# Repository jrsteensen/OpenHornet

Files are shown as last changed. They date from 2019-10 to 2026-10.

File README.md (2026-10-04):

# README
[TOC]

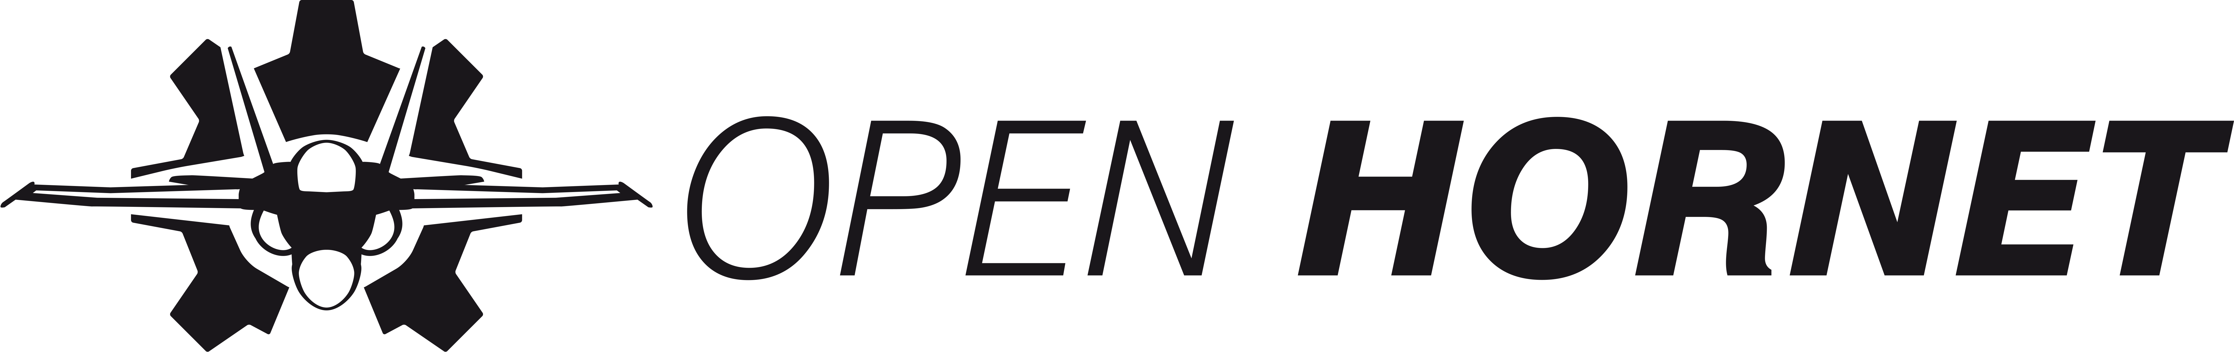
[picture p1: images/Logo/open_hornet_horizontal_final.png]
OH logo


 
 
 



 
 
 
 


 
 
 
 

The OpenHornet Project is a F/A-18C OFP 13C Lot 20 1:1 Replica Simulator, consisting of a physical structure and electrical/software interfaces to a PC to be driven by Digital Combat Simulator (DCS).

* If you have any questions, visit our Discord server and ask questions. The Discord server will be an invaluable resource for you as your progress through the journey of your build.

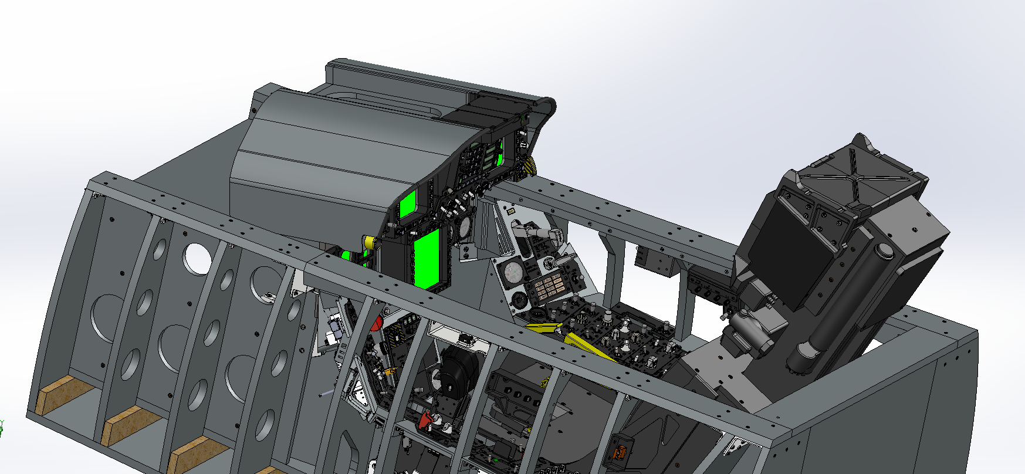
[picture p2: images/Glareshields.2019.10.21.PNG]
Overall Screen Grab


### Looking for Software?
* [OpenHornet GitHub Software Repository](https://github.com/jrsteensen/OpenHornet-Software)

## Design Software Requirements
* Mechanical CAD Software Required: Fusion360
* Electrical CAD Software Required: KiCad 10
* Microsoft Office (or compatible)

## Contributing
[Want to contribute?](https://github.com/jrsteensen/OpenHornet/wiki/Contributing) Let's discuss what you want to work on in Discord or in an issue!

## References, Information, and How-Tos

### GitHub Repository File Structure
```
OpenHornet
├── .github (Contains issue templates, funding info, and GitHub actions.)
├── artwork (Subdivided into end items, contains stickers, placards, etc.)
├── ECAD (All PCBs and electrical design files. See folder README file for details.)
├── images (Contains images for use in the wiki or other OH documentation.)
├── reference (Contains reference models or geometry.)
├── release (Contains all files that makeup the release package. See folder README file for details.)
├── utils (Contains fonts or other similar required resources for development)
├── .gitignore (File that instructs the git repository to ignore certain file types.)
├── CODE_OF_CONDUCT.md (Our contributor code of conduct.)
├── CONTRIBUTING.md (Repository contribution and issue-reporting guidance.)
├── LICENSE.md (License file for the OpenHornet repository)
├── PULL_REQUEST_TEMPLATE.md (The repository pull request template.)
└── README.md (This file)
```

### Important Links
* [OpenHornet Start Here Page](https://openhornet.com/start-here/) - Seriously. Start here.
* [OpenHornet FAQ](https://openhornet.com/faq/) - You guessed it! The FAQ!
* [OpenHornet GitHub](https://github.com/jrsteensen/OpenHornet) - OpenHornet's GitHub repository for everything other than MCAD. Where you can find the latest under-development files.
* [OpenHornet Hardware Documentation](https://docs.openhornet.com/hardware/) - Generated hardware documentation, tutorials, and reference material.
* [OpenHornet Tutorials](https://github.com/jrsteensen/OpenHornet/tree/master/docs/tutorials) - Tutorials for OpenHornet.
* [OpenHornet Issues](https://github.com/jrsteensen/OpenHornet/issues) - Go here to file a bug, enhancement, obsolescence, or maintenance issue.
* [OpenHornet Authorized Vendors](https://openhornet.com/openhornet-authorized-vendors/) - These are vendors who are licensed to sell OpenHornet parts and assemblies. By purchasing from them, you also support OpenHornet as well!

### OpenHornet MCAD Model
These links will allow you to download a local copy of the OH MCAD model, for reference or so you can modify things for your personal pit. If you would like to contribute to the raw MCAD, talk to Noctum in the OH Discord. You will need to prove a basic level of proficiency and be known within the discord community before access will be granted.
> [!NOTE] 
> These links will download the latest & greatest (most likely in development and unstable) MCAD. Always verify fusion parts against release package manufacturing files prior to use, and they are used at the user's own risk.

* [Top Level](https://a360.co/3SuPQGs) - This is HUGE. Consider downloading individual consoles instead.
* [Upper Instrument Panel (UIP)](https://a360.co/3LHxMXd)
* [Lower Instrument Panel (LIP)](https://a360.co/3SbD7sc)
* [Left Console (LC)](https://a360.co/3dBR57I)
* [Right Console (RC)](https://a360.co/37pBiWj)
* [Center Tub (CT)](https://a360.co/3LKM3mc)

### Branches
* `master` branch is the stable release branch which represents the last release.
* `develop` is the latest working branch that will become the next release. It may or may not be functional as is.

## Authors and Acknowledgment

### Core Development Team
* Erik Scott (RandomTroubledMind): _Project Founder, Mechanical Design_ (Retired from OH)
* John Steensen (Noctum): _Co-Founder, Systems/Mechanical Design Lead_
* Oscar Arias (Amanuense): _Electrical/Software Design Lead_ (Retired from OH)

### Contributor Team
* Exprezzo
* Sandra
* Ben-F111
* Lazarus
* Russell
* Arribe VCAW-1
* Stang
* \[OCS\] CrazyCanuck
* Ulikaii

### Honorable Mentions
* __Logo Design__: NegativeONE
* __Development Builders/Testers__: Ajmilner,  Arribe VCAW-1, Ben-F111, BlaBlaCZ, bnepethomas, Dave the boss 918, DG, DotDotDotBH, Exprezzo, Higgins, Krikeee, Lazarus, Otso, Rampage2010, Russell, Sandra, Splash, Thib-O, tonyg, TripRodriguez, Yannick, 
* __Ultimate Supporters__: Sandra, Higgins, Chaps, [OCS] CrazyCanuck, Arribe VCAW-1, FL370Pilot, CorgiStyle, Swaney409, DenzilLee, ssgcline, Tyler | "Soapbox" - F-15E, RickH, AdamA, bob =), aesellars, Nick, PrivatePirate, Howling-Ape, papiplanes
* __Elite Supporters__: thib_o54, ChrisTiger#001, Nodar, Matt, Bill C, annerajb, Wargle T Eagle, Gnoni, Lefty, Reaper021, Murtle, gengispala, PatOPat, mattgw86, EinLama, Maddox, hunstone, Nodar, Ulukaii, Radek 41Sqn RAFAIR, mojito555
* __Donators__: AJMilner, bnepethomas, Carbine, Crosshairs, Exprezzo, Goutch, Higgins, hrnet940, hunstone, icemarkom, jcstreek, jkkicks, kika, Nik S, Rampage2010, Russell, Sandra, SrSosio, Swaney409, Tekadept + many more…
* __Inactive Dev Contributors__: Balz Reber (Balse), Magic_Man, Bullant, Gaberun24, Damien022, Baago, Caviar4, NegativeONE, Ravell
* **Subject Matter Expert**: FlyNavy75, Sixtigers, USMARINE108, Luft101, Lex

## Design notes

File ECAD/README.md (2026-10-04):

OH logo
* [OpenHornet Website](https://www.openhornet.com)
* [OpenHornet Discord](https://discord.gg/G5PA5ju)
* [Donate to OpenHornet](https://www.openhornet.com/donate.html)

# **ECAD DIRECTORY INFORMATION**

Engineering contributors and agents: start with the [ECAD design requirements framework](docs/requirements/README.md). AI-assisted contributors should also read the [Astra/Konnect/KiCad toolchain guide](docs/requirements/TOOLCHAIN.md). The framework distinguishes repository evidence, approved policy, unresolved decisions and hardware qualification states.

The purpose of this guide is to help enable the end-user to successfully accomplish the following:  
*   1:  Facilitate navigation of the file structure.
*   2:  Provide clarification regarding the manufacturing process of PCB's related to OpenHornet using JLCPCB.com
*   3:  How to install the current project KiCad baseline and set up libraries associated with OpenHornet. _(optional, required only if you wish to contribute.)_

 _Note:  Manufacturing files have been generated accordinging to JLCPCB.com guidelines.  If choosing a different PCB Manufacturer, make sure to research their formatting standards and modify the necessary manufacturing files accordingly. And if you choose to manufacture them yourself, best of luck!_

## **ECAD File Structure**

The ECAD Directory has been organized to facilitate the end user, regardless of skill or knowledge, in acquiring the necessary files needed to: 
* A: make adjustments to individual PCB's as needed using ECAD software (KiCad)
     * _and/or_
* B: submit an online order to have the PCB manufactured and assembled by a company.

**The structure of the ECAD Directory is summarized below:**
ECADDirectory

Example

1. Within each labeled PCB folder, there will be a folder called "JLCPCB" and inside of that folder will be two additional folders called "gerbers" and "production_files"
2. **_All files you need for manufacturing are located in the "production_files" folder.  The gerbers are already compressed in a .zip file labeled the same way as the PCB folder their located in._** 
3. Additionally, there will be 2 .csv files:  _**BOM-'NAME OF PANEL'.csv**_ and  _**CPL-'NAME OF PANEL'.csv**_ that will contain a consolidated Bill of Materials (BOM) for components located on the top and bottom of the PCB, as well as the Control Panel File (CPL)  used for placing the components.

***PLEASE READ:  YOU NEED TO DOWNLOAD ALL 3 FILES WITHIN THE PRODUCTION_FILES FOLDER.  NOT JUST THE .ZIP.***



## **PCB Manufacturing**

At the moment, all manufacturing files have been standardized to allow for fabrication using JLC @ (https://www.jlcpcb.com).  You may use another PCB manufacturer of your choosing; however, you will be responsible for ensuring the required files meet specifications and formatting. 

***For details on the JLCPCB manufacturing process, please see the "MANUFACTURING.MD" located in the ECAD folder or CLICK THE LINK BELOW***

  [JLCPCB MANUFACTURING PROCESS & FAQ](MANUFACTURING.md)

## **Installation of KiCad and OpenHornet Libraries _(OPTIONAL)_**

*Installation of KiCad and OpenHornet Libraries is only required if you choose to contribute. See [CONTRIBUTING.md](../CONTRIBUTING.md) for more details.*

Before we begin, it is assumed that you have:
*  1:  Installed KiCad 10.x. The current validated AI-assisted reference environment uses KiCad 10.0.6; record and smoke-test newer versions before design mutation as described in [TOOLCHAIN.md](docs/requirements/TOOLCHAIN.md).
*  2:  Cloned the OpenHornet repository.

### STEP ONE:  Configure Paths & Create Environmental Variables

**Windows shortcut:** initialize KiCad 10 with its built-in libraries, then close KiCad and double-click [`Setup-OpenHornetKiCad.bat`](../utils/tools/ecad/Setup-OpenHornetKiCad.bat). The [complete setup script](docs/SYMBOL_LIBRARIES.md#windows-path-setup-script) configures all four paths, registers all six shared symbol libraries and `OH_Footprints`, and repairs existing shared entries in project library tables. It backs up every changed file and supports a preview with `-WhatIf`. After it succeeds, reopen KiCad; Steps One and Two below are the manual alternative.

Open up a new or previous project in KiCad.  For this example, I'll be using the MASTER ARM PANEL.  In the Top Menu: Navigate to Preferences --> Configure Paths



Create these four variables using absolute paths within your OpenHornet checkout:

| Variable | Repository folder |
| --- | --- |
| `KICAD_USER_OH_3DMODELS` | `ECAD/lib/OH_3DModels` |
| `KICAD_USER_OH_FOOTPRINTS` | `ECAD/lib` |
| `KICAD_USER_OH_SYMBOLS` | `ECAD/lib/OH_Symbols` |
| `KICAD_USER_OH_TEMPLATES` | `ECAD/lib/OH_Templates` |

The paths can be anywhere so long as they point to the OpenHornet checkout being edited. _Make sure the OH_FOOTPRINTS variable points to the `ECAD/lib` folder and **NOT** `ECAD/lib/OH_Footprints.pretty`._ If you use Git worktrees, do not let KiCad resolve libraries from a different checkout/revision than the PCB or schematic being edited.

tempsnip

### STEP TWO:  Add OpenHornet Symbol and Footprint Libraries

With the project window open, navigate to Preferences --> Manage Symbol Libraries.



In **Global Libraries**, add or edit the six shared libraries below. Use library format **KiCad** for each entry. The library paths use the variable configured above:

| Nickname | Library Path |
| --- | --- |
| `ABSIS` | `${KICAD_USER_OH_SYMBOLS}/ABSIS.kicad_sym` |
| `Arduino Pro Mini 5v` | `${KICAD_USER_OH_SYMBOLS}/Arduino Pro Mini 5v.kicad_sym` |
| `KiCadCustomLib` | `${KICAD_USER_OH_SYMBOLS}/KiCadCustomLib.kicad_symdir` |
| `OH_Interconnect` | `${KICAD_USER_OH_SYMBOLS}/OH_Interconnect.kicad_symdir` |
| `OH_Symbols` | `${KICAD_USER_OH_SYMBOLS}/OH_Symbols.kicad_symdir` |
| `OpenHornet` | `${KICAD_USER_OH_SYMBOLS}/OpenHornet.kicad_symdir` |

**Existing users:** change the paths for `OH_Symbols`, `KiCadCustomLib`, `OH_Interconnect` and `OpenHornet` from packed `.kicad_sym` files to their `.kicad_symdir` folders, using the exact nicknames in the table. Register each folder as one library, rather than adding its individual files. Check **Project Specific Libraries** for overriding entries with the same nicknames. `ABSIS` and `Arduino Pro Mini 5v` remain packed files.

Use the exact underscore nicknames `OH_Symbols` and `OH_Interconnect`, as shown in the table; do not substitute spaces. If a schematic still contains a library ID using a spaced nickname, correct its library reference through KiCad's symbol remapping tools. Changing a library-table nickname alone does not rewrite IDs embedded in schematics.

See [symbol library setup, Windows conversion and verification](docs/SYMBOL_LIBRARIES.md). Contributors pulling the converted folder only need to update their library mapping. The screenshots below illustrate the dialogs; use the paths in this table for KiCad 10.



Do the same thing for the footprint library, adding `ECAD/lib/OH_Footprints.pretty` with nickname `OH_Footprints`. The path should resolve as `${KICAD_USER_OH_FOOTPRINTS}/OH_Footprints.pretty`.



### STEP THREE:  Add ***KiCAD JLCPCB tools*** Plugin (Optional)
Bouni @ https://github.com/bouni/kicad-jlcpcb-tools has developed a plugin that allows you to search the JLCPCB parts database, assign LCSC article numbers to your parts, and generate production files for JLCPCB. This plugin is optional and is not a substitute for the OpenHornet sourcing/manufacturing requirements or the approved Astra/Konnect workflow.

*  1: Click **"Plugin and Content Manager"**
*  2: When the dialog box opens, click on **"Manage"**
*  3: When the **"Manage Repositories"** dialog box opens, Click the "+" sign and add the following:
    *  Name:  Bouni's KiCad repository
    *  URL:  https://raw.githubusercontent.com/Bouni/bouni-kicad-repository/main/repository.json
*  4: Once downloaded and installed, hit "Apply Changes"



### Congratulations. That's all you have to do for the shared OpenHornet library mapping.  The 3D models that are associated with the footprints will automatically be linked as long as the OH_Footprints are used.  

AI-assisted contributors should continue with [TOOLCHAIN.md](docs/requirements/TOOLCHAIN.md) before making hardware changes.

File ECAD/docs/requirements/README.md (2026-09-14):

# OpenHornet ECAD requirements

Status: **adopted on 2026-09-11 by merge of PR #1255 into the default branch**. Baseline inspected for the original framework: `master` at `c259a65a1759801a2affea817fd99f6a14f1e1fe` (2026-09-10 review). Adoption does not itself qualify any hardware.

The canonical path is **`ECAD/docs/requirements/`**, matching the existing uppercase `ECAD` tree. Creating a second lowercase tree would collide on common Windows/macOS filesystems. No hardware tree is renamed.

## Authority and requirement language

Merge of PR #1255 adopted the normative requirements for new designs and changed portions of existing designs, including affected interfaces and dependencies. Existing released boards retain their historical status; adoption does not retroactively qualify them or require wholesale redesign. Cosmetic maintenance does not trigger unrelated migration or repeat physical qualification. Already-open hardware PRs document applicable gaps and their disposition. See GOV-010/011 for scope and authority.

Requirements adopted by PR #1255 are effective; amendments proposed in a later PR take effect when accepted and merged. Individually unresolved technical choices marked Proposed/TBD remain pending until separately resolved.

- **MUST / MUST NOT**: mandatory conditions within the stated scope.
- **SHOULD / SHOULD NOT**: expected practice; document the engineering reason for a different approach.
- **MAY**: permitted option, not evidence of qualification.
- **Observed**: repository evidence, not a mandatory design rule.
- **Proposed**: a specific choice awaiting owner approval; MUST NOT be treated as an approved project standard.
- **TBD**: unresolved input; record a board-specific reviewed decision before passing a gate that depends on it.

Each normative document identifies its basis. Requirements have stable IDs for review evidence and deviations. Keep IDs stable when editing wording; retire rather than reuse deleted IDs. An inventory value becomes normative only through an explicit requirement and scope.

The master baseline is supplemented by the ALE+ successor and current owner-confirmed decisions recorded in the [ALE+ supplement](ALE_PLUS_SUPPLEMENT.md). Baseline file counts remain a historical snapshot; supplements and later reviews explicitly identify their scope.

## Reading order

| Document | Purpose | Status |
| --- | --- | --- |
| [GOVERNANCE.md](GOVERNANCE.md) | Authority, change scope, deviations, practical acceptance | Normative |
| [WORKFLOW.md](WORKFLOW.md) | Astra/Codex, Konnect, KiCad 10, safe edits and evidence | Normative |
| [TOOLCHAIN.md](TOOLCHAIN.md) | Known-good Astra/Konnect/KiCad implementation, operator modes and smoke tests | Operational reference supporting WORKFLOW |
| [SCHEMATICS_AND_COMPONENTS.md](SCHEMATICS_AND_COMPONENTS.md) | Schematics, datasheets, exact MPNs, symbols and footprints | Normative |
| [INTERFACES.md](INTERFACES.md) | ABSIS, connectors, cables, RS-485 and local buses | Normative; observed mappings explicitly separated |
| [POWER_AND_USB.md](POWER_AND_USB.md) | Power budgets, protection, USB, decoupling and returns | Normative |
| [PCB_AND_MECHANICAL.md](PCB_AND_MECHANICAL.md) | Physical constraints, routing and board rules | Normative |
| [VALIDATION.md](VALIDATION.md) | ERC, DRC, parity, exclusions and review | Normative |
| [MANUFACTURING.md](MANUFACTURING.md) | CAM, BOM/CPL, assembly and release artifacts | Normative |
| [QUALIFICATION.md](QUALIFICATION.md) | Bring-up, regression, human acceptance and release | Normative |
| [REVIEW_RECORD.md](REVIEW_RECORD.md) | Short change/build review record | Proportional PR evidence |
| [ARCHITECTURE_INVENTORY.md](../reference/ARCHITECTURE_INVENTORY.md) | Evidence, generations and identified conflicts | Informative |
| [BOARD_INVENTORY.md](../reference/BOARD_INVENTORY.md) | Every PCB/project, source paths and observed constraints | Informative |
| [ABSIS_MIGRATION.md](ABSIS_MIGRATION.md) | Rules for performing scoped circuit migrations | Normative |
| [ALE_PLUS_SUPPLEMENT.md](ALE_PLUS_SUPPLEMENT.md) | Current owner-confirmed ALE+ design decisions | Informative |
| [OPEN_QUESTIONS.md](OPEN_QUESTIONS.md) | Accepted owner decisions | Decision record; Q-01 through Q-13 resolved |

## Start a board change

Read governance, workflow, the toolchain reference when using AI/Konnect, the applicable technical documents, and the board's inventory entry. Establish the actual board revision and connected hardware before editing. Use [REVIEW_RECORD.md](REVIEW_RECORD.md) to capture applicable requirement IDs, evidence and unresolved items. Inventory entries are a baseline snapshot; recheck the current source when using them.

Numerical defaults in KiCad, old production files, tool examples and component headline ratings are not automatically OpenHornet electrical or fabrication limits. Do not use the oldest or most permissive value to settle a conflict. Keep the affected gate pending until its inputs are resolved.

## Owner decisions and practical scope

The 2026-09-14 discussion establishes the profiles, power targets, supported modules, practical acceptance and file-lifecycle rules recorded in [OPEN_QUESTIONS.md](OPEN_QUESTIONS.md). Q-03 approves Master-end-only shield bonding and detachable two-position JST SM drain connections with one contact populated per half. S3MB is the accepted ALE+ D2. Implementation defects belong in repository issues/PRs; this folder is not an issue backlog.

Historical static inventories are retained under `ECAD/docs/reference/` as dated evidence. They do not override current owner decisions or establish current support status. No formal retrospective qualification campaign is required for successfully used existing boards.

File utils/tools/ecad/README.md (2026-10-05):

# OpenHornet ECAD utilities

## Windows KiCad 10 setup

After installing KiCad 10, initialize its built-in symbol and footprint libraries and close all KiCad applications. In a complete OpenHornet checkout, double-click `Setup-OpenHornetKiCad.bat`. It runs `Set-OpenHornetKiCadPaths.ps1`, shows the results and pauses before closing. Reopen KiCad after setup succeeds.

The PowerShell utility configures all four `KICAD_USER_OH_*` paths (symbols, footprints, 3D models and drawing templates), registers all six shared symbol libraries and `OH_Footprints`, and repairs existing shared-library entries in project tables under `ECAD`. It requires PowerShell 5.1 or newer. For a preview or direct execution from the repository root:

```powershell
powershell.exe -NoProfile -ExecutionPolicy Bypass -File .\utils\tools\ecad\Set-OpenHornetKiCadPaths.ps1 -WhatIf
powershell.exe -NoProfile -ExecutionPolicy Bypass -File .\utils\tools\ecad\Set-OpenHornetKiCadPaths.ps1
```

The script preserves unrelated preferences and library entries. It backs up every changed file in the KiCad configuration folder with a restore manifest, checks for concurrent changes and attempts rollback if a later write fails. It supports `-Checkout` and `-ConfigDirectory`, detects external environment overrides and makes no changes when setup already matches. Project mapping repairs appear in `git diff`; review them before committing. See the [setup guide](../../../ECAD/docs/SYMBOL_LIBRARIES.md#windows-path-setup-script) for configuration discovery, restore instructions and verification. No administrator rights, Codex or Konnect are required.

If an older copy reports a `ConvertFrom-Json` error about keys such as `a` and `A`, update the setup script and rerun it. The current utility preserves case-sensitive preference keys with Windows PowerShell 5.1 and PowerShell 7.

Maintainers can run the disposable regression tests with Python 3 and PowerShell:

```powershell
python .\utils\tools\ecad\tests\test_kicad_setup.py
```

The tests prefer `powershell.exe` on Windows, otherwise `pwsh`. Set `OH_TEST_POWERSHELL` to test a particular executable. Close KiCad before running them.

## Astra launch utilities

These wrappers implement the operator modes defined by `ECAD/docs/requirements/TOOLCHAIN.md`.

- `./preflight audit` — read-only workstation/repository/library/MCP checks. Audits may run on the default branch.
- `./preflight design` — stricter checks for a mutation session. Refuses `master`/`main`, detached HEAD, missing toolchain/library mappings, and a dirty working tree unless `OH_ALLOW_DIRTY=1` explicitly acknowledges intentional scoped work.
- `./astra-audit [prompt]` — CLI convenience wrapper that runs preflight and starts GPT-6 Astra/Codex with `approval=never` and `sandbox=read-only`.
- `./astra-design [prompt]` — CLI convenience wrapper that runs preflight and starts GPT-6 Astra/Codex with `approval=on-request` and `sandbox=workspace-write`.

`OH_ASTRA_MODEL` may override the default `gpt-6-astra` model identifier. The launchers do not install, update or reconfigure Codex, Konnect or KiCad; follow `TOOLCHAIN.md` for setup and smoke tests.

On the validated Fedora reference environment, `preflight` also verifies KiCad's `KICAD_USER_OH_*` variables resolve to the current Git checkout. This intentionally prevents a Git worktree from silently using libraries from another checkout. Other platforms must perform equivalent library-resolution verification until that check is made portable.

The shared-library check requires nonempty `OH_Symbols.kicad_symdir`, `KiCadCustomLib.kicad_symdir`, `OH_Interconnect.kicad_symdir` and `OpenHornet.kicad_symdir` directories. Retained packed comparison copies do not satisfy these checks. `ABSIS` and `Arduino Pro Mini 5v` remain packed libraries. Use KiCad 10 and follow the [symbol library mapping and verification guide](../../../ECAD/docs/SYMBOL_LIBRARIES.md) after pulling the migration.

## CLI usage

Example design session:

```bash
git switch -c pcb/example-change
utils/tools/ecad/astra-design
```

To resume a deliberate in-progress task that already has uncommitted ECAD changes:

```bash
OH_ALLOW_DIRTY=1 utils/tools/ecad/astra-design
```

Do not use `OH_ALLOW_DIRTY=1` to hide unrelated local work.

## ChatGPT Desktop / graphical Codex

The 2026-09-11 roci reference setup also passed the read-only OpenHornet/Konnect smoke test through ChatGPT Desktop/Codex using the same `~/.codex/config.toml` Konnect MCP registration as the CLI. For OpenHornet ECAD work, open the canonical checkout as a **Local** project, not a Codex-managed worktree, until shared KiCad library mappings are project-relative.

When using the desktop app, do not launch `astra-audit` or `astra-design` merely to create another nested Codex session. Run the appropriate repository preflight from the integrated terminal, then continue the task in the existing Astra conversation:

```bash
utils/tools/ecad/preflight audit
# or
utils/tools/ecad/preflight design
```

Desktop environment Actions are optional convenience UI only. The current autogenerated `.codex/environments/` state is machine-local and ignored by Git; these repo-owned utilities remain the shared authoritative workflow.

## Validated Fedora schematic viewer

The Konnect `schematic-viewer` required two process-local compatibility settings on Fedora 44 KDE/Wayland:

```bash
export GDK_BACKEND=x11
export WEBKIT_DISABLE_DMABUF_RENDERER=1
```

The validated roci installation keeps those variables in a wrapper at `~/.local/bin/schematic-viewer` and preserves the upstream viewer binary as `~/.local/bin/schematic-viewer.real`. Do not export these variables globally.

Konnect 0.11.1 dark theme applies a CSS filter to the rendered SVG and was visibly blurry when zoomed under the validated WebKitGTK path. Light theme retained crisp vector rendering and is the recommended viewer mode for this reference environment.

The desktop application is optional. CLI Astra/Codex plus Konnect, KiCad and the repository launch utilities remain the reproducible fallback and should continue to work independently of desktop UI state.

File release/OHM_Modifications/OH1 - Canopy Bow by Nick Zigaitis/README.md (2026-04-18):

# OH1 - Canopy Bow by Nick Zigaitis
- **Author:** Nick Zigaitis
- **Publisher:** Simon Martel (1_neox_1)
- **Contributed on:** 4/18/2026
- **Derived from:** v0.3.0
- **Original Assembly:** OH1

## Summary
This change adds a canopy bow component to the project. The mod itself was not originally developed by me, but I am publishing it to make it available to the OpenHornet community. The goal is to enhance cockpit realism and completeness by providing an additional structural element that integrates cleanly with existing parts.

### Parts List
1. 6x M3 x 10mm Button Head Screw
2. 6x M3 x 12mm Button Head Screw
3. 4x M3 x 7/32" Bolt Socket Cap Screw
4. 2x M2 x 25mm Pan Head Screw
5. 13x M3 Heat Insert
6. 52x 1/4" Wood Dowels
7. TrackIR Sensor
8. 1x PATIKIL 1/4" Thread Ball Stud 35mm
9. 3x 1.5mm Acrylic Mirror Wrapped
10. 2x Canopy Hoop Grab Handle
11. x1 1/16" Trotec Rev Matte Clear/Black
12. x1 TroGlass Satin Clear 3mm Trotec
13. x1 2.84mm Green Acrylic
14. x1 X27-589 Stepper
15. x1 X27-168 Stepper
16. x1 4mm x 2mm Neodymium Magnet
17. 3x Double Sided Mounting Tape

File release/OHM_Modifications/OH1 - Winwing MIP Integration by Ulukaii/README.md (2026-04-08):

# OH1 and OH2 Modification for Winwing integration, V3
- **Author:** J Schumacher (Ulukaii) 
- **Contributors:** Spruce, Breith, Reaper021 
- **Contributed on:** Dec 28, 2025 
- **Derived from:** v0.3.0
- **Original Assembly:** OH1, OH2

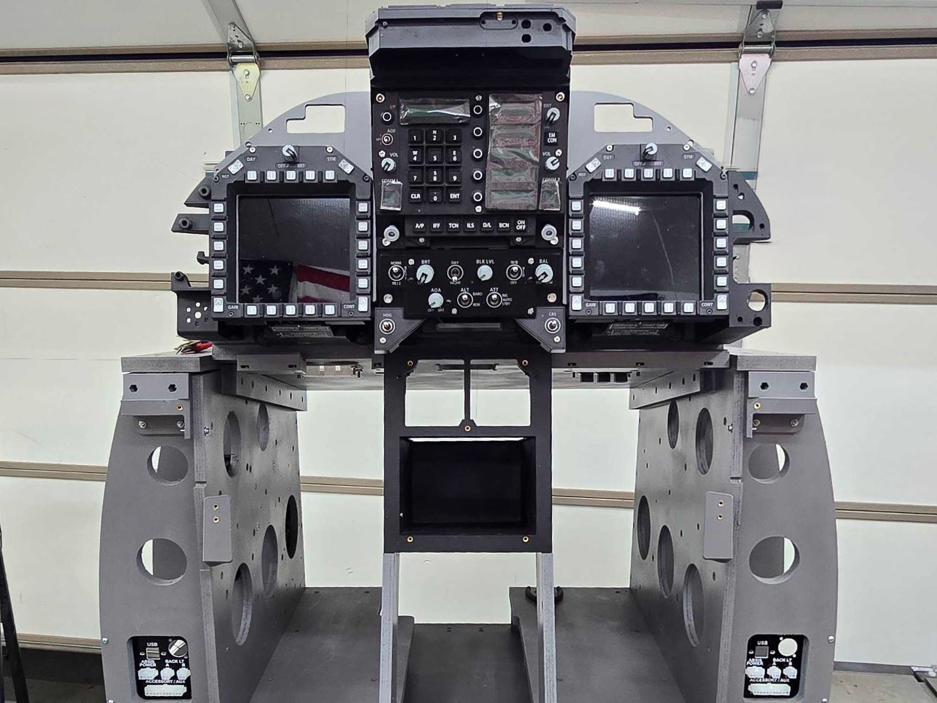
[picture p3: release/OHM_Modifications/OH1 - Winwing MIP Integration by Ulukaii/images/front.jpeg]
Front


## Summary
This folder provides modifications for integrating the Winwing MIP into the OpenHornet upper and lower instrument panel (UIP and LIP). It is aimed at builders who intend to do a full Winwing MIP integration, including HUD panel. The parts provided herein are designed with 3D printability in mind. 
- Folder V1: Previous release. 
- Folder V2: Previous release. 
- Folder V3: Current stable build.

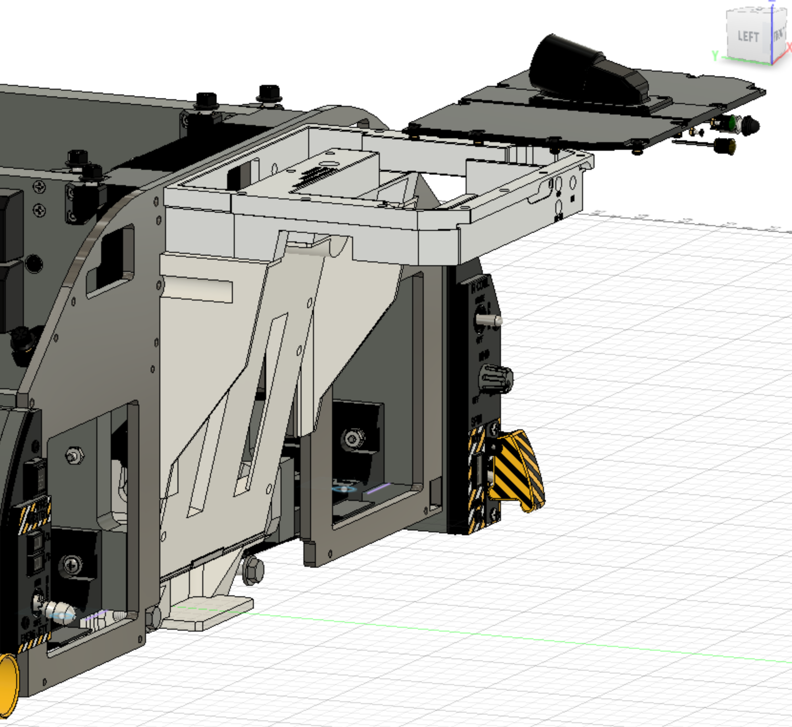
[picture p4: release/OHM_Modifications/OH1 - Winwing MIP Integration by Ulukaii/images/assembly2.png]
Assembly preview


## How to use this mod

Use this mod to build your pit using the basic OpenHornet upper instrument control panel (UIP) frame, but integrate your Winwing MIP components into the build. You will replace the following visible parts: Left DDI, right DDI, UFC, HUD control panel and AMPCD. To achieve this, this mod provides the files for a modified face plate (acrylic) and modified brackets (3D printed). 

## Feature overview

The integration positions the Winwing UFC and HUD panels as closely as possible to the OH-specified position:
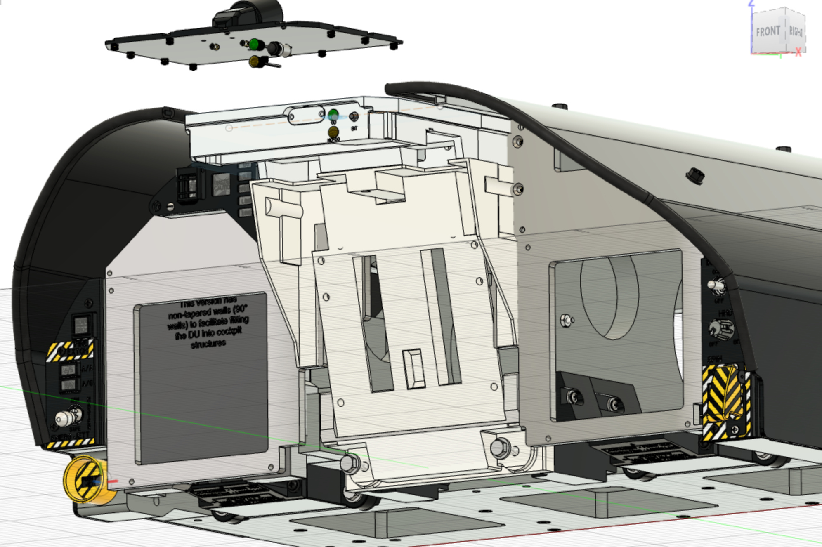
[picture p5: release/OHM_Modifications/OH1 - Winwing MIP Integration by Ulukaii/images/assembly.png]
Assembly preview


Due to the Winwing MFD screen encasings, the face plate can't use six screws on the outboard longeron. However, the assembly provides new / alternative securing. The main holding bracket is firmly secured using M5 screws and six heat inserts: 

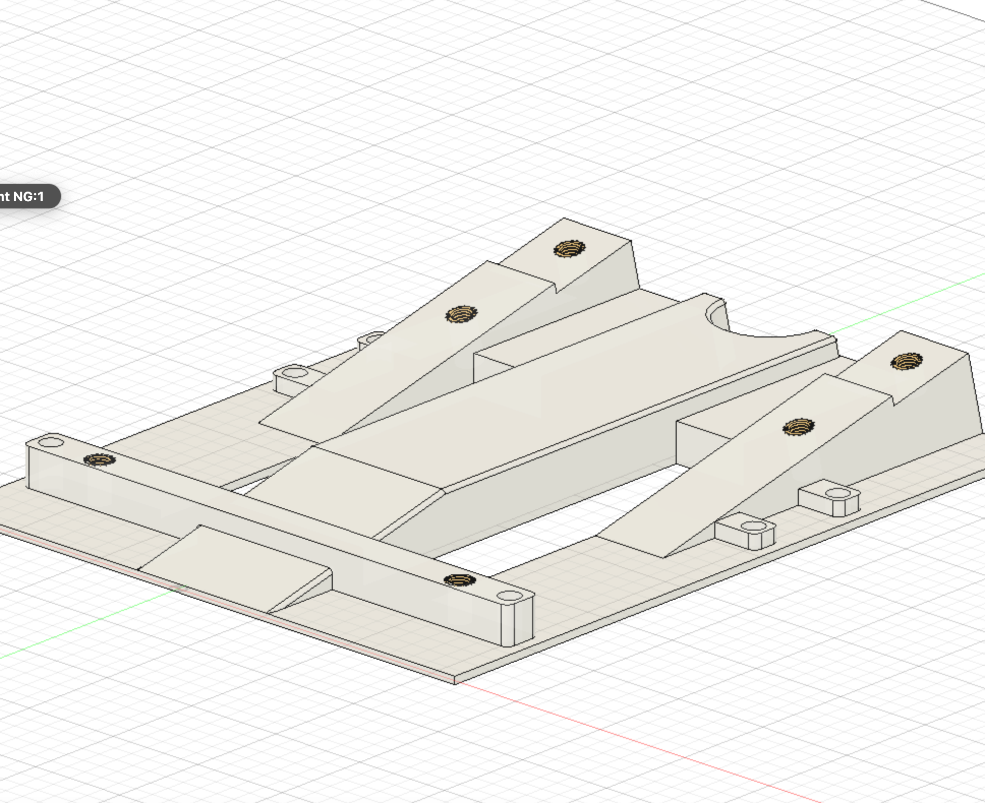
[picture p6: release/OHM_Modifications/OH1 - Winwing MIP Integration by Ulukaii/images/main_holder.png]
Main holder


The lower central brackets are modified to support and secure the main holding bracket:
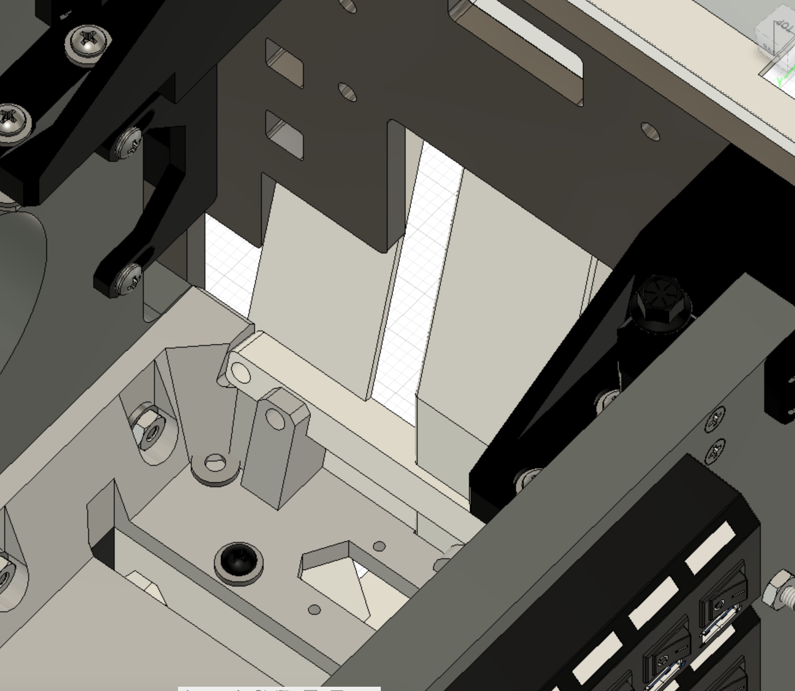
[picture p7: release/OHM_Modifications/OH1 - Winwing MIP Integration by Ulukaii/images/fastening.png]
Fastening


The BIT box is open on the lower side, providing (some) access to the extra buttons on the Winwing UFC:
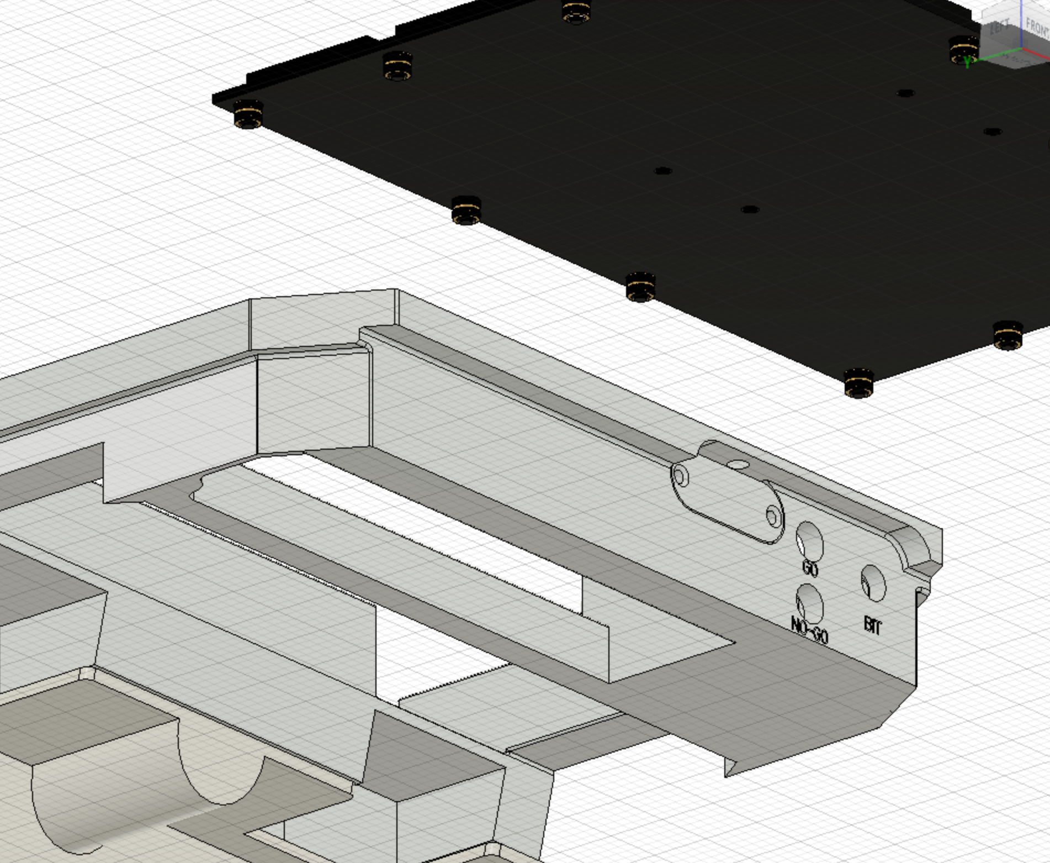
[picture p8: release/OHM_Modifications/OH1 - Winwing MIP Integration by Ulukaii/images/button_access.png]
Button access


As of V3, the improved AMPCD mount ensures a snug fit with the UIP. The AMPCD is still removable without removing the UIP. Construction has been redesigned to allow full disassembly from the front - no more hidden screws. Below / behind the AMPCD, a large storage box is implemented, which allows to store kneeboard, keyboard, mice, VR dongles etc. Depending on your printer size, dovetail cuts are needed for printing. 
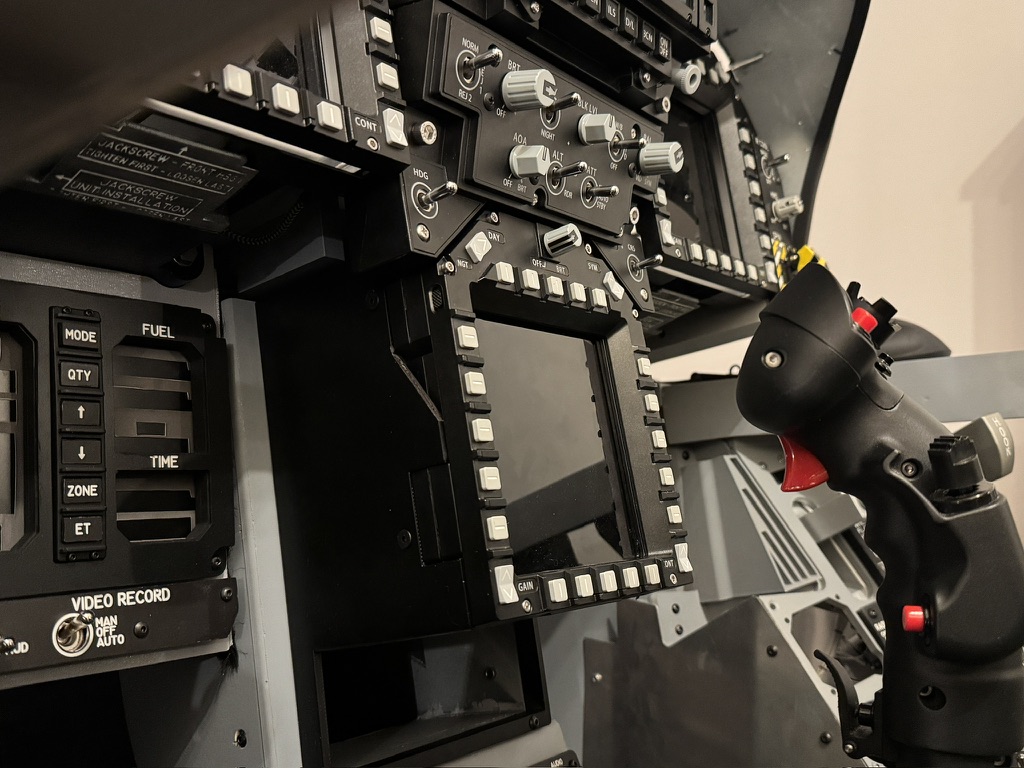
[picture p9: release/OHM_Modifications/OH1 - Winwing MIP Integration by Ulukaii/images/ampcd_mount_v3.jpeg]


## Character of this mod

To integrate the Winwing MIP into OpenHornet, several design choices had to be made. This is due to the fact that the Winwing MFD bezels are larger and that the Winwing HUD panel comes with the HDG and CRS knobs directly attached to it. The existing solutions by the community follow different design choices. The following table provides an overview of this mod and the other Winwing integration mod by Nick, to help you decide which one to pick.

| | Ulukaiis mod (this mod) | Nicks mod |
|---|---|---|
| Idea | Reasonable effort integration w/ only 10 modified parts. No custom PCBs required. Using Winwing HUD panel. | High effort integration with customized eyebrow panels. Requires custom PCBs |
| Resulting architecture | MFD screens extend further downwards by 1.5 cm compared to OH spec | MFD screens extend further upwards, EWI panels are reduced in size and custom PCB design required. However, outer UIP dimensions are preserved. More accurate positioning of HDG and CRS knob. |
| MFD screens | Winwing as-is | Winwing, encasing removed |
| UFC | Winwing | Winwing |
| EWIs | OpenHornet | Custom |
| HUD panel | Winwing | OpenHornet |
| HDG/CRS sel | Winwing | OpenHornet |
| AMPCD | Winwing | N/A |

## Manufacturing parts list
1. ACRL_OH1A1-12_MOD_A: Completely redesigned face plate (acrylic). Replaces OH1A1-12
2. FDM_OH1WW-01: NEW part that provides the mounting plate between face plate and Winwing UFC and HUD panel
3. FDM_OH1WW-02: NEW part that provides encasing for the Winwing UFC
4. FDM_OH1A8A4-10_MOD_A: modified upper box (BIT box) for the UFC including the go/no-go lights. Comes with an additional cable guide. Replaces OH1A8A4.
5. FDM_OH2A3A1-10_MOD_A: this is a modified holder for the AMPCD without the HDG / CRS knobs and with positioniing of the AMPCD harmonized with the UIP Winwing installation
6. FDM_OH1A1-23: this is a modified HUD panel aft support 
7. FDM_OH1A1-19: this is a modified MFD panel lower support (you need to print two of them)
8. FDM_OH!A1-22: this is a modified version of the display pressure foot. Instead of pressing the display, it is now an additional fastening position for the face plate.
9. FDM_.125_OH1A1_10_UIP_MOD_A LEFT GLARESHIELD and FDM_.125_OH1A1_29_UIP_MOD_A RIGHT GLARESHIELD: replace the ABS glareshields. This version has a cutout and a blister for the upper outward corner of the Winwing DU.

## Additional required COTS parts list (diff to OH)
1. Winwing MIP including three MFDs, three screens, UFC and HUD panel
2. 8 M3 screws, 42mm, to fasten the MFD screens to the face plate. Exact length depends on your face plate thickness
3. 8 M3 hex nuts (usually included in your MIP)
4. 6 M5 screws, 12mm, to fasten the UFC to the UFC mount (FDM_OH1WW-02)
5. 6 M5 screws, 12mm, to fasten the UFC mount to the face plate (ACRL_OH1A1-12_MOD_A)
6. 6 M5 heat inserts for the UFC mount
7. 2 M5 screws, 12mm, to fasten the HUD BIT box (FDM_OH1A8A4-10) to the face plate
8. 1 M5 screw , 30mm, to fasten the HUD BIT box (FDM_OH1A8A4-10) to the UFC box cover (OH1WW-02)
9. 1 M5 heat insert, to fasten the HUD BIT box (FDM_OH1A8A4-10) to the UFC box cover (OH1WW-02)
10. 4 M5 screws, 20mm, to fasten the AMPCD to the AMPCD box

## Additional required mechanical changes to the OH parts
1. To fit the Winwing DUs, you will need to perform small cutouts into the outboard UIP longerons. The exact size depends on the thickness of your material. You will see it when you start integrating it. Thanks to fellow builder Breith for the pictures. 
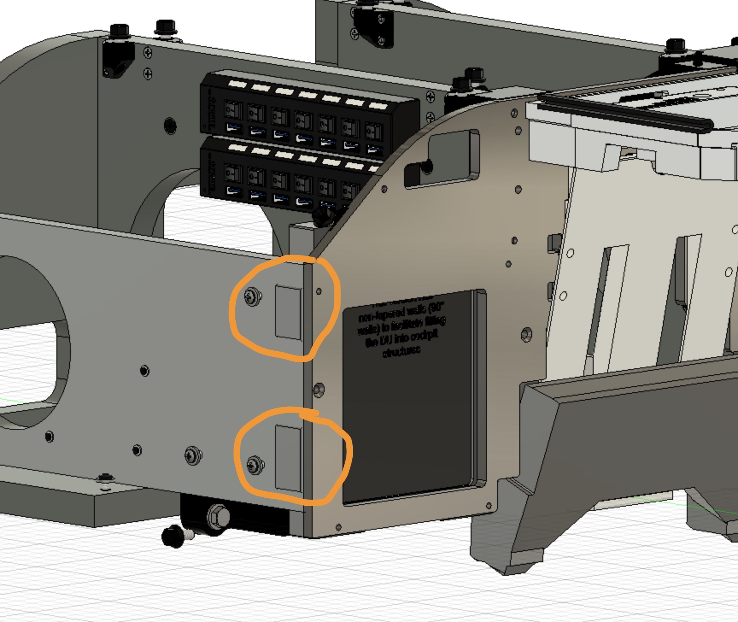
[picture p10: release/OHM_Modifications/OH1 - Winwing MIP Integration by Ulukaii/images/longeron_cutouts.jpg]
Longeron cutouts

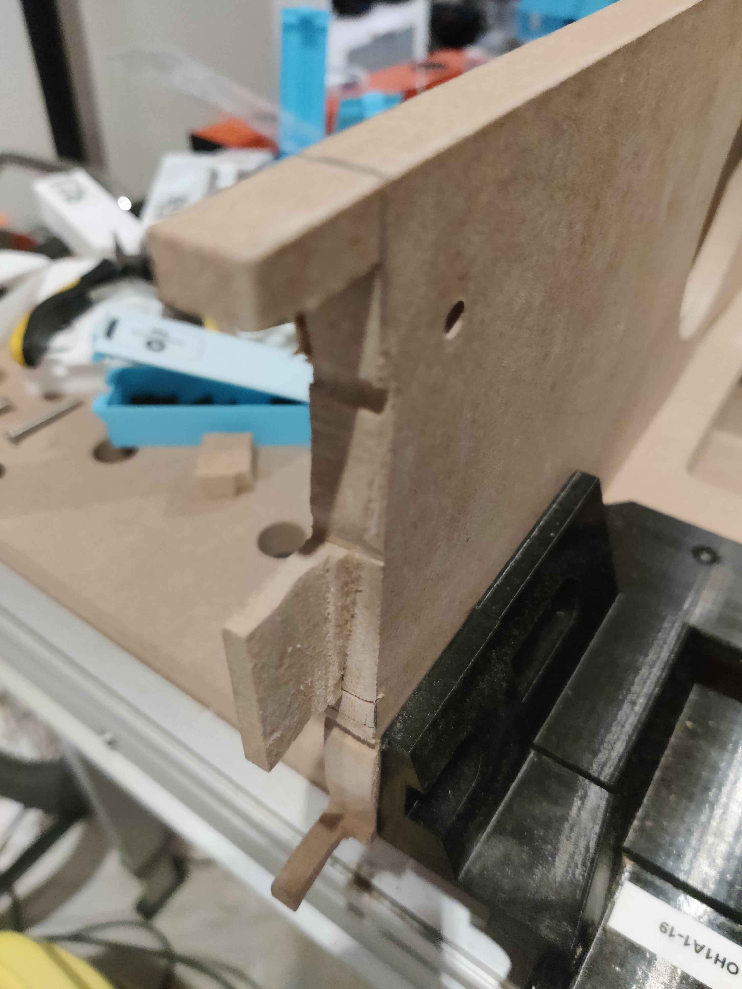
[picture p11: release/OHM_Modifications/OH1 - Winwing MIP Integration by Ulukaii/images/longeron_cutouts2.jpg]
Longeron cutouts

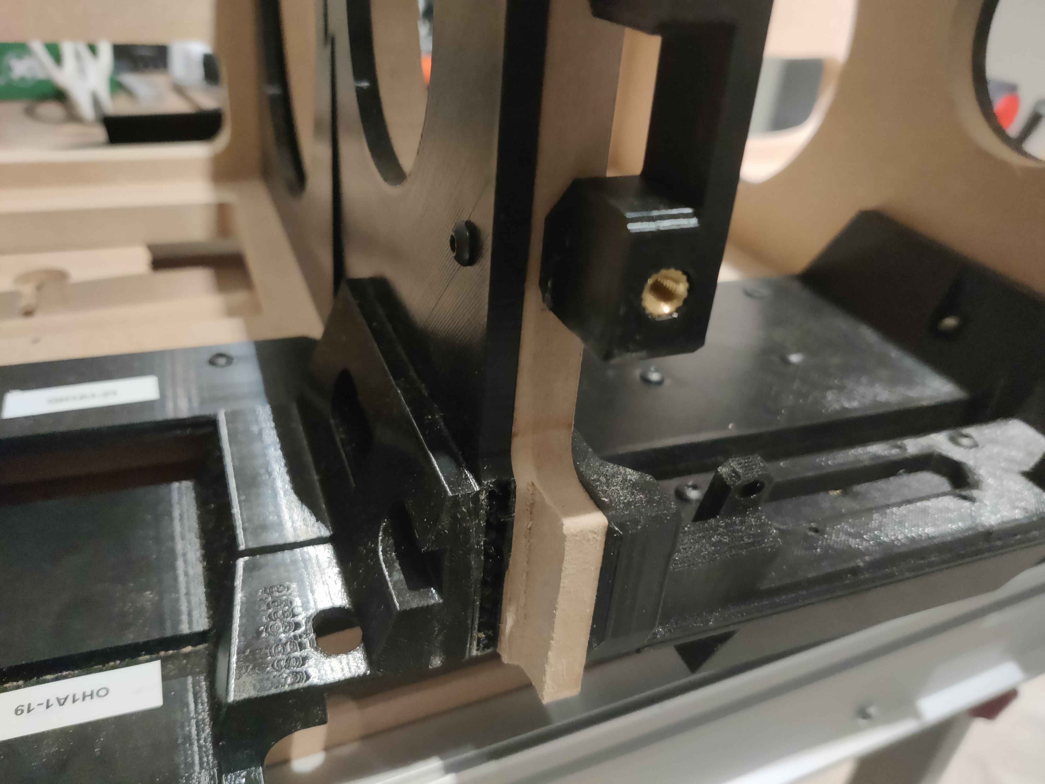
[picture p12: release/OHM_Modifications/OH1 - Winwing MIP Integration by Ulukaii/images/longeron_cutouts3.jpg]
Longeron cutouts

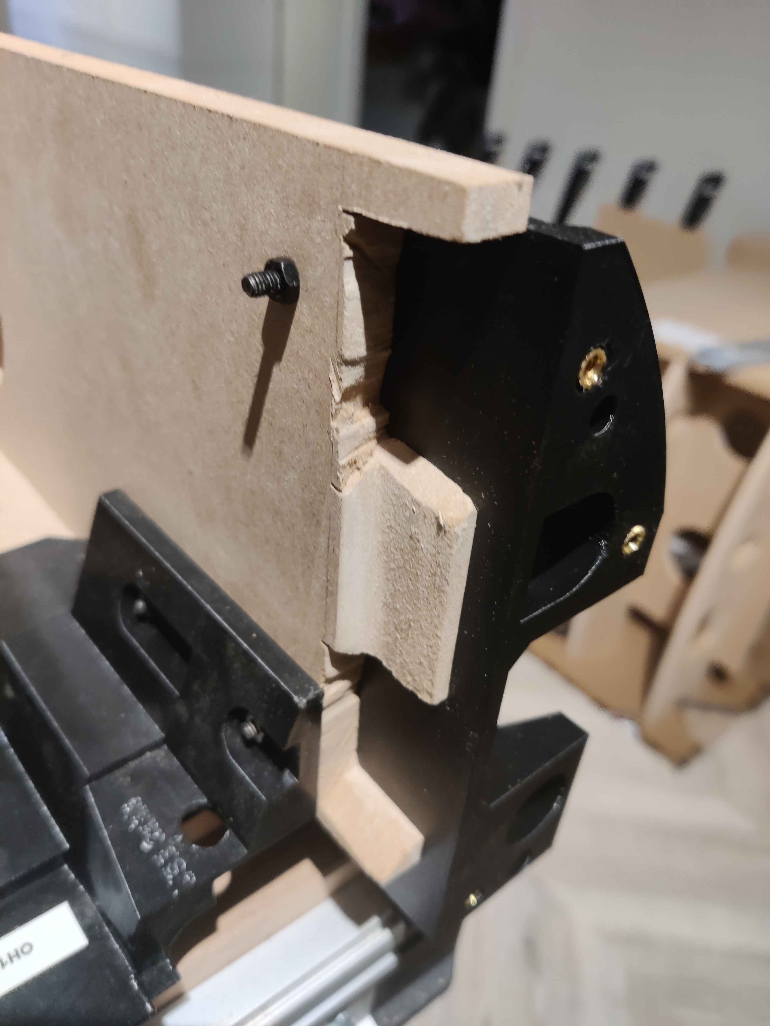
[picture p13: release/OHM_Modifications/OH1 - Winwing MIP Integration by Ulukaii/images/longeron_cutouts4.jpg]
Longeron cutouts


2. The upper outward corner of the DU will intersect with the ABS glareshield. You will need to either perform some cutouts into your existing ABS glareshields, or you can FDM-print the glareshields provided in this mod, which feature a blister:
FDM_.125_OH1A1-10_UIP_MOD_A LEFT GLARESHIELD v0.step
FDM_.125_OH1A1-29_MOD_A UIP RIGHT GLARESHIELD v0.step
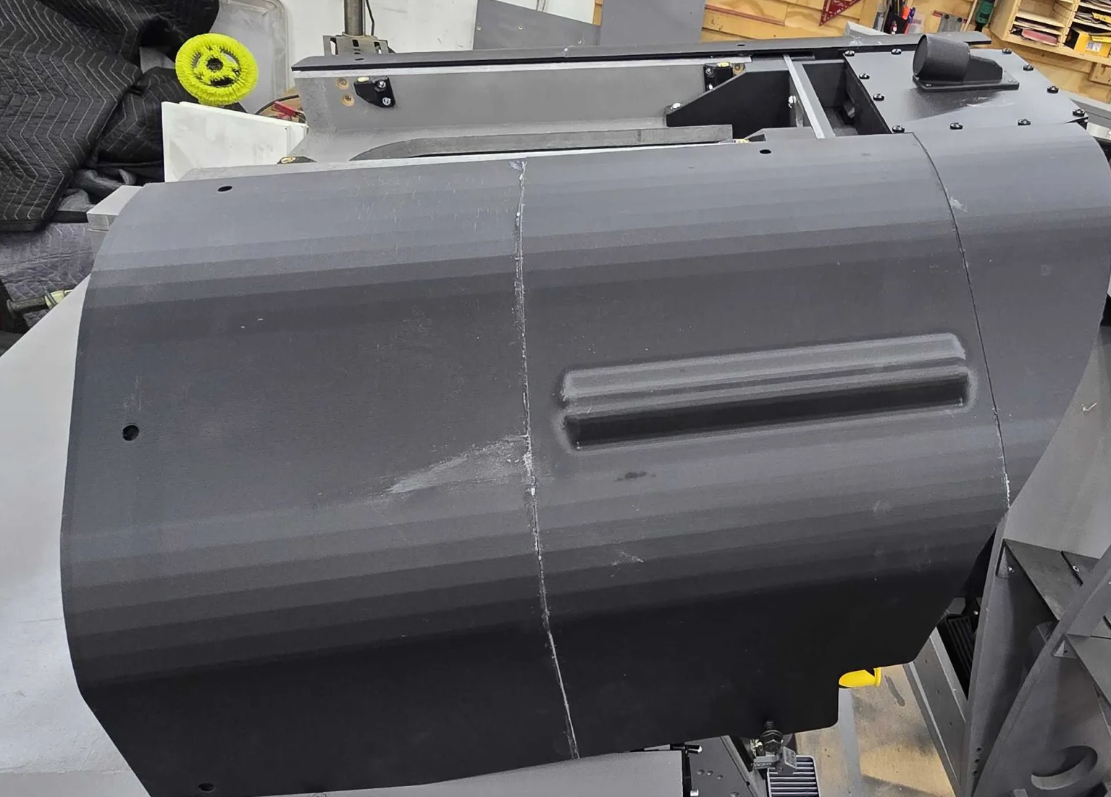
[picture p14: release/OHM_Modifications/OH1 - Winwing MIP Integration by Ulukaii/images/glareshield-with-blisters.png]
Image of Glareshield with blister


## How to assemble

LIP:
1. Install the "Upper Central Pedestal Face Mounting Brackets" L / R to your structure. Each requires two heat inserts, don't forget them!
2. Install the "Upper Central Pedestal Face + Box" to the structure by using the brackets 
3. Install the AMPCD mount
4. Install the DisplayHoldingBrackets to the Display (not to the mount!)
5. Attach the cables to the display
6. Install the display onto the AMPCD mount. Four M4 flat head screws will hold the display holding brackets from the side
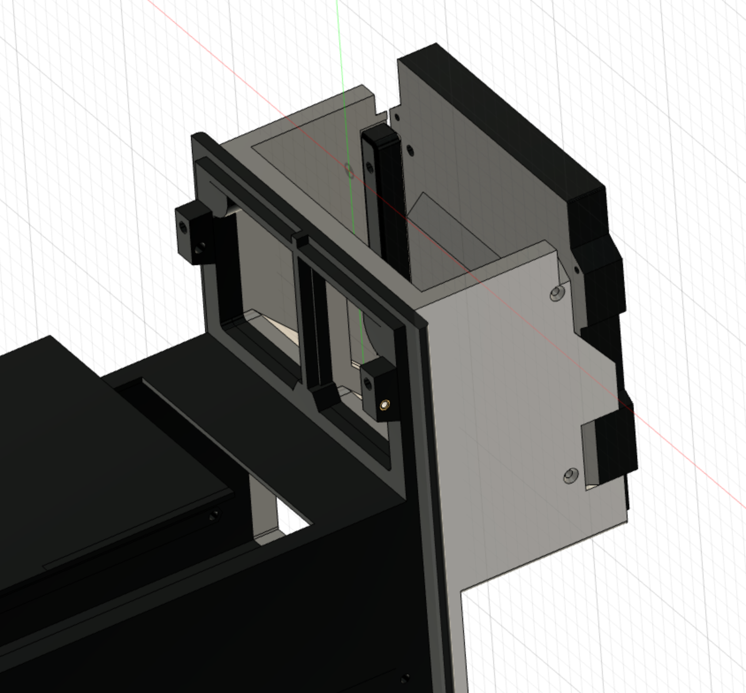
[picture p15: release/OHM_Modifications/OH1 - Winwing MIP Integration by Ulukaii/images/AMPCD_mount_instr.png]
AMPCD mount


UIP:
1. Prepare the UIP frame: remove the old face plate (if any) and install the modified OH1A1-25 (central bracket) and OH1A1-19 (WW MFD lower supports).
2. Prepare the face plate: Assemble the whole MIP to the face plate, including left and right DDIs. You might want to connect the cables now
3. Join the UIP frame and the face plate.
4. Install the UFC box cover (OH1WW02) by sliding it in from above
5. Install the UFC HUD Bit box and cover.

## Known issues
- Outboard fastening of the face plate should be improved

## Further links
 - Openhornet.com
 - https://github.com/eHanseJoerg/OpenHornet/tree/develop/release (author OH repo)
 - https://makerworld.com/de/models/650441 (Makerworld repo for ease of access)

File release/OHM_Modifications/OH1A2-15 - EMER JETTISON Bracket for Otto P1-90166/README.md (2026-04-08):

# Emergency Jettison Bracket for Otto P1-90166
- **Author:** John Steensen (Noctum)
- **Contributed on:** Nov 16, 2023 
- **Derived from:** v0.2.0
- **Original Assembly:** OH1A2-15

## Summary
This modification consists of a replacement bracket for the original bracket which eliminates the original OH Emergency Jettison Switch and provides mounting accommodations for an OEM Otto P1-90166 switch. This switch is occasionally found used on eBay or other similar sites.

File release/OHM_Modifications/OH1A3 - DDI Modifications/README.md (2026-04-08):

# OH1A3 DDI Modifications
- **Author:** John Steensen (Noctum) & Higgins-OH
- **Contributed on:** Nov 20, 2023 
- **Derived from:** v0.2.0
- **Original Assembly:** OH1A3

## Summary
This modification provides a single piece DDI button and bezel, for printing with resin instead of FDM. The DDI Insulating Washer was contributed by Higgins-OH to help prevent some LEDs near the encoders from getting crushed.

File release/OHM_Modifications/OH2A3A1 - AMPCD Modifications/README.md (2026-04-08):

# OH2A3A1 AMPCD Modifications
- **Author:** <A Hornet's Nest (Howling-Ape)>
- **Contributed on:** <Oct 20, 2024>
- **Derived from:** v<0.2.0>
- **Original Assembly:** <OH2A3A1>

## Summary
This modification provides a single piece AMPCD bezel and button/rocker for printing with resin instead of FDM, or milled from Aluminium. 
File format for the single piece bezel is in .3MF and .STEP (for flexibility between manufacturers. 
Knob OHC0003-412FGB2 has been modified by recessing the black identification strip around the arrow for ease of masking and paiting. Two models are provide - one has the set screw (92311A102) thread modelled. 
A lychee scene has been added with pre supported buttons and knobs for resin printing - this has been tested with the use of Elegoo ABS-like resin.

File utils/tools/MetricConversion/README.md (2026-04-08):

---
title: Metric convertion guide
author: Ulukaii
date: today
---

# Introduction

As the title in [my build log says](https://discord.com/channels/392833351238811648/1278055599082442907), my build is a metric one. I'll write down some "metric musings" with tips / considerations for metric builders. 

# Structure

The OH structure is specified in MDF and the thickness of the required materials is usually .75 or .5 inches. In metric regions (EU in my case), we usually don't have these thicknesses readily available. For example, hardware stores will usually have 19mm MDF or 18mm plywood as standard thicknesses; both of which isn't the exact specified value of .75 inches (19.05 mm). However, before ordering wood from overseas - check the tolerances! Usually the plywood and MDF tolerances range at +/- .8mm so if you order 19mm MDF, it could be up to 19.8mm thick anyway. In a nutshell: don't worry too much about the material thicknesses. Here are some basic transformations as discussed with @Breith :

| Specified thickness | Exact conversion | What to use instead |
|---|---|---|
|  MFD | | |
| .75 MDF | 19.05 mm | 18 mm plywood or 19mm MDF*. In general, no adaptions of the structures needed, but this depends on your individual batch of wood. |
| .5  MDF | 12.25 mm | 12 mm plywood or MDF |
| .25 MDF | 6.38 mm | 6 mm plywood or MDF |
|  ACRL | | |
| .188 Lightplate | 4.77  mm | 5.0 mm  acrylic |
| .127 Backplate | 3.225 mm | 3.0 mm  acrylic |
| .125 Backplate | 3.175 mm | 3.0 mm  acrylic |
|  RMRK | | |
| .063 Rowmark | 1.6 mm | 1.5 mm  engraving material (CNC-plus.de or Innograv) |
| .065 Rowmark | 1.6 mm | 1.5 mm  engraving material (CNC-plus.de or Innograv) |
| .03 | 0.762 mm | 0.75mm |
| .005 | 0.127 mm | 0.1 mm |

The script available in this folder automatically renames the files, but **this will not convert the internal dimensions of the svg files**. If your slicer or CNC software gives you weird dimensions, you have to fix it yourself.

To execute the script, you need to start PowerShell (`Windows key > powershell`), go in this directory and execute the script by typing `.\Convert_Name_To_Metric.ps1`.

# Fasteners

Here is my approach to convert the imperial-size fasteners used by the OH build plans to metric-sized fasteners. The key takeaway is that conversion is possible and straightforward, with little adaptions to the structure. In particular, where 3D printed brackets use hexagonal holes for hex nuts, I recommend adapting these holes to make sure the hex nut doesn't move. Other than that, almost no adaptions are really required.



# Screws

## Screw diameter and pitch

The Diameter is an important dimension (the first number) - Forget about the pitch. In the metric system, the pitch is standardized with the diameter and "baked in" I just made sure to get consistently "M" threads instead of "MF" threads. If you order metric fasteners at amazon, you will 99% likely get "M" threads.

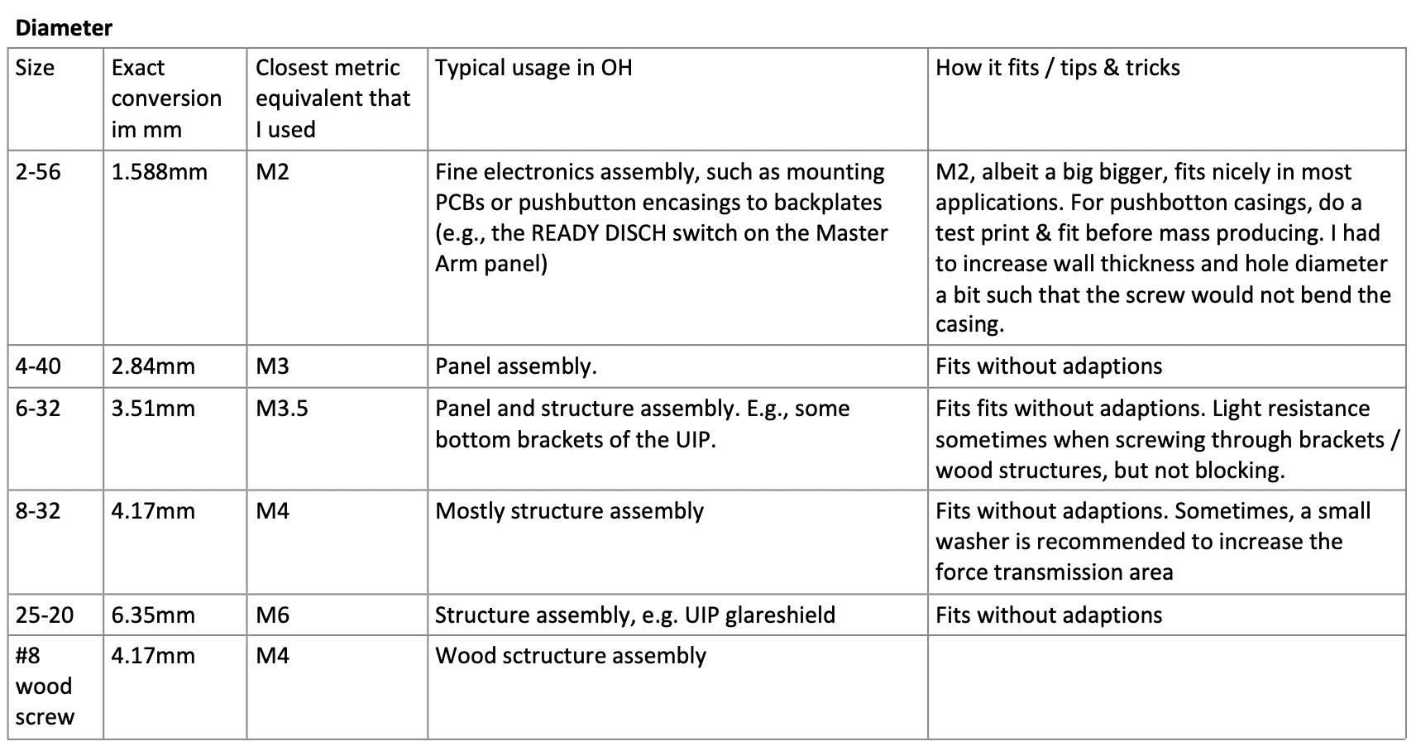
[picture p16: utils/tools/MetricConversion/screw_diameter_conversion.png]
Conversion table for the screw diameter

*Conversion table for the screw diameter*

## Screw length
Not a too important dimension IMHO. Mostly I was able to get away with up to +/- 2mm in length. My suggestion is to obtain several large but cheap screw sets for every dimension (M3 box, M3.5 box, M4 box) with screws of different length and then just use what intuitively fits. 

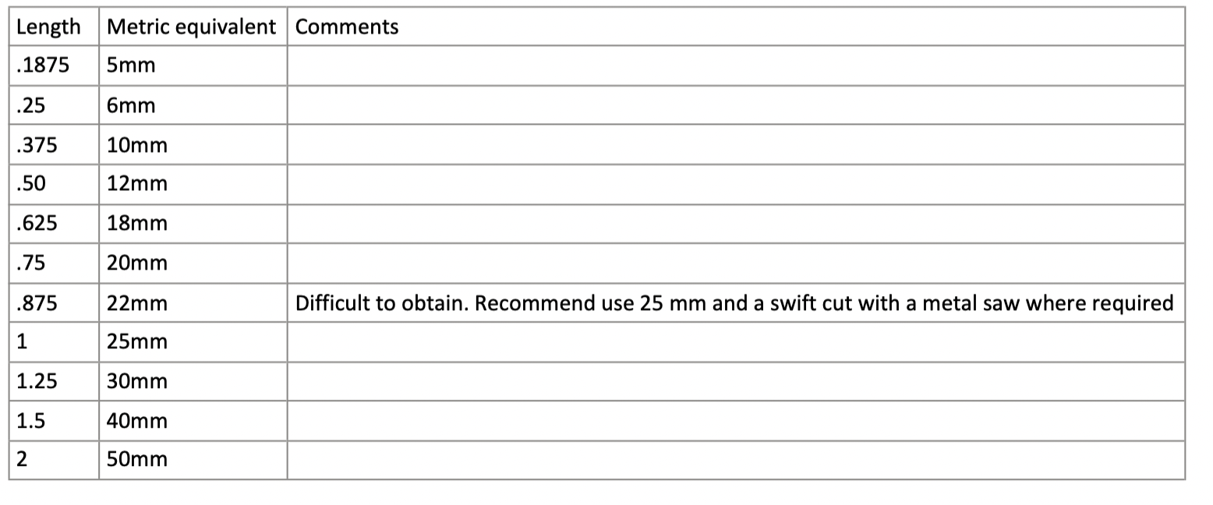
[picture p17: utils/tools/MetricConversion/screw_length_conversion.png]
Conversion table for the screw length

*Conversion table for the screw legth*

## Head angle (in case of flat / pan head screws).

OH uses 82 degrees and 100 degrees. This conversion is the easiest one: in the metric system, all head angles are simply 90 degrees, just in the middle. If you manufacture your countersinks using a metric tool, it will be 90 degrees. Where you 3D print countersinks, you can probably get away without even adapting the countersunk hole. 

## DZUS 

Not implemented by me yet.

## Drive 

OH uses mostly standard Cross slot or simple slot screws. I recommend strongly going for either allen key heads (in case of panel screws) or Torx heads (for your wood screws), because their torque tolerance is much higher. In my case, my structure is made out of plywood, which is much more rigid and I simply destroyed all the cross slot screws I started out with and replaced them with Torx.

## Holes for fasteners

Only the 6-32 / M3.5 conversion is a tight fit. All other holes fit nicely. Us a washer in case of a loose fit. 

## Hex Nut holes

This is more important once again and probably the only spot where I carefully consider metric adaptions. The OH brackets use many "holes for hex nuts" and if I simply use the hex nut without adaptions, it may happen that the hex nuts turns in situ and I can't tighten the screw / nut combination. 

No Adaptation
*I do not perform any adaptions here, because the hex nut could also be held in place with a plier until tight enough*

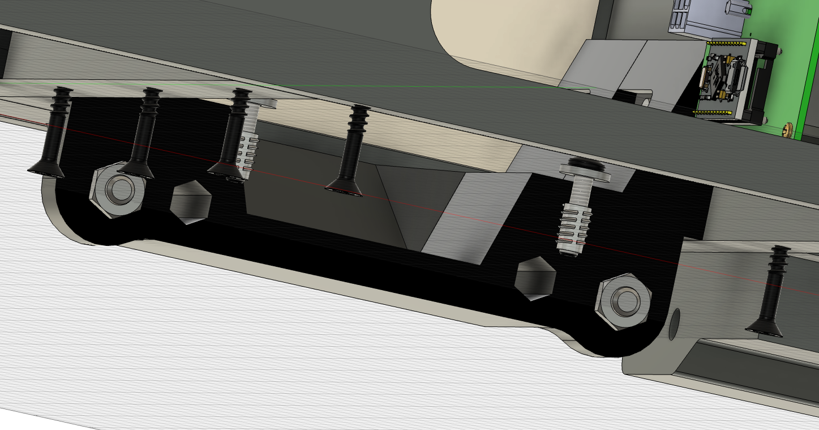
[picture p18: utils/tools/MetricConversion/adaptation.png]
Adaptation

*For this black bracket, I definetely adapt the hole for the hex nut because it is inaccessible*

## End result

Here is my final conversion table as per part number. Contains most of the screws used in OH
[Conversions table](Metric Conversions 2.xlsx)

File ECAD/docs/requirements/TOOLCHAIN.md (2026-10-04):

# Astra / Konnect / KiCad toolchain

## Purpose and status

This document is the operational reference implementation for the normative workflow in [WORKFLOW.md](WORKFLOW.md). It records the known-good AI-assisted ECAD toolchain and the operator rules needed to keep KiCad source, shared libraries and Git state synchronized.

Reference environment with read-only connectivity smoke-test evidence on 2026-09-11:

- Fedora Linux 44 on `roci`.
- KiCad 10.0.6 and `kicad-cli` 10.0.6.
- OpenAI Codex CLI 0.154.0 using GPT-6 Astra.
- ChatGPT Desktop for Linux 26.908.40401-1 successfully exercised as a graphical Codex/Astra front end after its generated bundled-plugin cache was rebuilt; the bundled app-server reported 0.154.0-alpha.6.2.
- Konnect 0.11.1 from the approved upstream: <https://github.com/mixelpixx/Konnect>.
- Konnect Codex skills installed with `konnect init --client codex`.
- Konnect MCP registered with Codex and connected to KiCad 10 over the official IPC API.
- OpenHornet shared symbols, footprints, 3D models and drawing templates resolved through the documented KiCad path variables.

These exact patch versions are a **reference for the exercised operations**, not a permanent project-wide pin. A newer version MAY be used after the applicable read-only and mutation-capability tests below pass and the exact versions are recorded in the change review. A toolchain upgrade MUST NOT be combined with an unrelated hardware change if it causes source-format, library or manufacturing-output churn.

## Authoritative editing path

The expected AI-assisted path is:

**Astra/Codex → Konnect MCP → KiCad 10 / kicad-cli → deterministic validation → reviewed manufacturing outputs → human review and qualification**.

For AI agents, Konnect is the semantic write boundary for KiCad project content. An AI session MUST NOT fall back to direct text editing of `.kicad_sch`, `.kicad_pcb`, `.kicad_pro`, `.kicad_sym`, `.kicad_mod`, `sym-lib-table` or `fp-lib-table` when the requested semantic operation is unavailable. Stop, report the capability gap and either use native KiCad under human control or separately improve the toolchain.

Read-only inspection of native KiCad source and parsing of exported reports, netlists, BOMs, CSVs and other derived text remain permitted for analysis. Static requirements reviews do not require a live toolchain; report unavailable checks under FLOW-019.

## OpenHornet KiCad library mapping

The current shared library setup uses these KiCad path variables:

| Variable | Repository target |
| --- | --- |
| `KICAD_USER_OH_3DMODELS` | `ECAD/lib/OH_3DModels` |
| `KICAD_USER_OH_FOOTPRINTS` | `ECAD/lib` |
| `KICAD_USER_OH_SYMBOLS` | `ECAD/lib/OH_Symbols` |
| `KICAD_USER_OH_TEMPLATES` | `ECAD/lib/OH_Templates` |

The current shared symbol libraries are `ABSIS`, `Arduino Pro Mini 5v`, `KiCadCustomLib`, `OH_Interconnect`, `OH_Symbols` and `OpenHornet`. The shared footprint library is `OH_Footprints`, resolving to `${KICAD_USER_OH_FOOTPRINTS}/OH_Footprints.pretty`.

`OH_Symbols`, `KiCadCustomLib`, `OH_Interconnect` and `OpenHornet` resolve to `${KICAD_USER_OH_SYMBOLS}/<nickname>.kicad_symdir`, unpacked KiCad 10 libraries with one file per symbol. Use the canonical nicknames `OH_Symbols`, `KiCadCustomLib`, `OH_Interconnect` and `OpenHornet` and register each directory as a single library. `ABSIS` and `Arduino Pro Mini 5v` retain their packed `.kicad_sym` files. Check project-specific tables for entries that override the global mapping. See [symbol library setup and migration](../SYMBOL_LIBRARIES.md) for Windows commands and verification.

Before an AI-assisted editing session, confirm that every variable resolves to the **same repository revision being edited**. This is especially important with Git worktrees. A board in one worktree MUST NOT silently resolve symbols, footprints, 3D models or templates from another checkout/revision.

Until library paths are made reliably project-relative, the default OpenHornet AI workflow is a task branch in the canonical checkout. A separate worktree MAY be used only when the KiCad path variables are deliberately repointed to that worktree and verified before opening or editing the design.

## Git session discipline

Read-only audits MAY run on the default branch. Any design mutation MUST run on a dedicated task branch and a clean or intentionally scoped working tree.

Recommended start for a design session in the canonical checkout:

```bash
git fetch origin
git switch master
git pull --ff-only
git status --short --branch
git switch -c pcb/<short-task-name>
```

Do not let Astra, KiCad, another agent or a human concurrently write the same project. Preserve one mutation owner at a time. Unrelated local changes must be committed, stashed or moved before ECAD work begins.

## Repository launch utilities

The repository includes executable wrappers under [`utils/tools/ecad/`](../../../utils/tools/ecad/):

```bash
utils/tools/ecad/preflight audit
utils/tools/ecad/astra-audit

utils/tools/ecad/preflight design
utils/tools/ecad/astra-design
```

`preflight design` refuses `master`/`main` and detached HEAD, checks Codex/Konnect/MCP availability, verifies shared library targets and, on the validated Linux environment, confirms KiCad's `KICAD_USER_OH_*` variables point at the active checkout. It also refuses an already-dirty design tree unless `OH_ALLOW_DIRTY=1` explicitly acknowledges that the operator is resuming intentional scoped work. Do not use that override to hide unrelated changes.

The wrappers default to `gpt-6-astra`; `OH_ASTRA_MODEL` may override the model identifier after the replacement model/toolchain has passed the required smoke test.

## Codex and Konnect configuration

Install the Konnect Codex guidance and register the server with Codex:

```bash
konnect init --client codex
codex mcp add konnect -- /path/to/konnect --client codex
codex mcp list
```

Konnect exposes toolsets dynamically. Codex versions that do not refresh MCP tool schemas after `tools/list_changed` require Konnect's eager catalogue mode. For the validated Codex 0.154.0 / Konnect 0.11.1 combination, use a Konnect settings file containing:

```json
{
  "transport": "stdio",
  "eager_toolsets": true
}
```

This intentionally spends more model context so Astra can call PCB, schematic, library, verification and manufacturing tools without losing newly loaded schemas. Re-evaluate this workaround when either Codex or Konnect changes.

### Audit mode

Use read-only Codex sandboxing for unattended inspection. Only non-mutating Konnect tools required by the audit should be pre-approved. Candidate discovery/read tools from the reference setup include `get_installation_info`, `open_project`, `get_project_info`, `get_board_info`, `get_component_list`, `list_toolboxes`, `get_active_toolsets`, `load_toolset`, `unload_toolset`, `get_recent_calls` and `server_stats`. Verify actual effects for the installed version and parameters before approval, including project-opening and toolset-loading behavior. A Codex read-only sandbox does not itself make MCP operations read-only; remote/server-side and live KiCad writes require separate control.

Do **not** blanket-approve mutation, delete, route, placement, save, import or manufacturing-write tools merely to make an unattended audit succeed.

### Design mode

Interactive design sessions SHOULD use approval-on-request with repository writes enabled, for example:

```bash
codex -m gpt-6-astra -a on-request -s workspace-write
```

The operator should keep KiCad and, for schematic work, the schematic viewer visible beside Codex. Review requested operations and the live design state instead of treating tool-call success as engineering acceptance.

### ChatGPT Desktop / graphical Codex

ChatGPT Desktop MAY be used as the graphical Codex/Astra control surface when the same smoke test passes. Open the canonical OpenHornet checkout in **Local** mode, not a Codex-managed worktree, unless the OpenHornet KiCad library variables have first been deliberately repointed and verified for that worktree.

The desktop application and standalone CLI may use different bundled Codex builds even when they share `~/.codex/config.toml`. Record the relevant desktop application/app-server version when it is used for design work. Confirm Konnect reaches `ready` and perform the same read-only board smoke test before mutation.

Project-local ChatGPT Desktop environment files under `.codex/environments/` are autogenerated, machine-local state in the current reference setup and are intentionally ignored by Git. Desktop environment **Actions are optional convenience UI**, not part of the required OpenHornet workflow. The repo-owned `utils/tools/ecad/` preflight/launch utilities are authoritative; GUI users can run the appropriate preflight from the integrated terminal before an Astra task.

If the Linux desktop application crashes before project work, distinguish application state from the OpenHornet toolchain before modifying repository or MCP configuration. In the validated setup, stale generated bundled-plugin cache state could crash the UI while Konnect itself was healthy; rebuilding only generated application plugin/cache state restored the GUI without changing `~/.codex/config.toml`, Konnect, or OpenHornet.

## Live PCB interaction

PCB Editor is the preferred visual surface for PCB work.

- Open the target `.kicad_pcb` in KiCad 10 with **Preferences → Plugins → Enable KiCad API** enabled.
- Confirm the exact open board with Konnect before mutation.
- Konnect PCB operations use KiCad 10's live IPC API when supported. Placement, routing and other live changes appear in PCB Editor and participate in KiCad undo/redo.
- The human operator MAY watch the board update in real time, but MUST NOT simultaneously move, route, delete or otherwise edit items while Astra owns the mutation phase.
- If IPC is lost after the board was observed live, treat any `unsafe_file_fallback` or equivalent condition as a stop. Reconcile and save/reopen the authoritative state before continuing.
- Save deliberately after reviewed milestones, not merely because a tool can save.

Suggested PCB checkpoints are: board/update-from-schematic review, placement review, routing review, final DRC/parity/unrouted review, and manufacturing-output review.

## Schematic interaction and viewer

KiCad 10 does not expose item-level Eeschema editing through the same IPC API. Konnect therefore performs schematic changes with its format-aware schematic engine and atomic file writes.

During an Astra-owned schematic mutation phase:

- Close the target schematic in Eeschema so there are not two competing writers.
- Use Konnect schematic tools for all mutations.
- Use the Konnect `schematic-viewer` application for a live visual review. The viewer watches the root `.kicad_sch`, renders the hierarchy through `kicad-cli`, and auto-refreshes without becoming a second writer.
- Launch syntax is:

```bash
schematic-viewer /path/to/root_schematic.kicad_sch
```

- After a logical change set, run ERC, inspect the rendered schematic, then reopen in native KiCad for human review before proceeding to PCB synchronization.

The Konnect standalone server archive may not contain the viewer; the KiCad PCM package includes it when shipped for the platform. Keep the viewer version aligned with the Konnect release used by the session.

On the validated Fedora 44 KDE/Wayland workstation, Konnect 0.11.1's viewer required XWayland plus the WebKitGTK DMABUF workaround:

```bash
GDK_BACKEND=x11 WEBKIT_DISABLE_DMABUF_RENDERER=1 schematic-viewer /path/to/root_schematic.kicad_sch
```

A local wrapper MAY contain those two environment variables so they affect only the viewer. The current viewer's dark schematic theme applies a CSS filter to the SVG and rendered visibly soft under this WebKitGTK path at high zoom; the **light theme retained sharp vector rendering** and is the validated review mode. These are workstation/viewer compatibility notes, not schematic requirements.

## Toolchain smoke test

Before the first mutation after installation or any relevant tool upgrade, prove the full path against a known design without saving or changing it:

1. `konnect --version`, `kicad-cli version`, `codex --version`.
2. `konnect status --client codex` and `codex mcp list`.
3. `get_installation_info` reports the expected Konnect executable and KiCad CLI.
4. `open_project` identifies the exact PCB open in KiCad and confirms IPC.
5. `get_board_info` returns board metadata.
6. `get_component_list` returns placed footprints.
7. Git status is identical before and after the test.

The 2026-09-11 reference smoke test used current ABSIS Mega and successfully reported revision 3.0.0, two copper layers, 89 nets and 36 footprints while leaving the repository clean. The same read-only smoke test subsequently passed through ChatGPT Desktop/graphical Codex. Before using a new or changed mutation capability, additionally perform the isolated edit/save/reopen/check exercise required by FLOW-020. These results prove the toolchain connection only; they are not a fresh electrical or manufacturing qualification of that board.

## Standard design sequence

1. Establish a task branch, clean Git state, exact target revision and review record.
2. Read `AGENTS.md`, the requirements index, applicable technical requirements, board inventory, migration decisions and open questions.
3. Run the toolchain smoke test and confirm library resolution against the active checkout.
4. Establish the design baseline: schematic/PCB state, existing ERC/DRC findings, connected hardware, fabrication profile and qualification evidence.
5. Complete schematic decisions first where practical. Verify exact MPN, datasheet, symbol pinout, footprint/pad mapping, sourcing and assembly policy before committing a new part.
6. Make schematic changes through Konnect, inspect visually and run ERC. Obtain human review at the schematic checkpoint for significant changes.
7. Update the PCB from the saved schematic through a supported semantic operation. Review the dry run/plan before apply when the tool provides one.
8. Place components, inspect the live PCB and relevant mechanical constraints, and review placement before routing.
9. Route against approved netclasses, fabrication constraints and electrical calculations. Do not substitute generic Konnect example widths/clearances for project requirements.
10. Refill zones, save the reviewed state and run DRC, schematic parity and unrouted checks as applicable. Disposition findings without suppressing them merely to obtain a clean report.
11. Generate BOM/CPL/Gerber/drill/STEP/PDF and other required outputs only from the validated saved state. Reconcile source, BOM, placement and CAM results.
12. Record tool versions, relevant operations, checks, results, deviations and qualification state in the hardware PR/review record. Record maintainer review and actual build/use evidence under QUALIFICATION.md.

## Stop conditions

Stop mutation work and report the issue when any of the following occurs:

- the target project/revision or connected hardware is ambiguous;
- required design inputs or applicable requirements are unresolved and materially affect the next decision;
- KiCad libraries resolve to another checkout/revision;
- Konnect/KiCad IPC is unavailable for a live PCB operation that requires it;
- a schematic or PCB is being concurrently edited by another writer;
- a semantic operation partially fails and its mutation state is unknown;
- required datasheet, package, pinout, polarity, JLCPCB assembly availability or fabrication limits cannot be verified;
- ERC/DRC/parity/unrouted results cannot be obtained or contain undispositioned findings;
- a tool proposes direct source-text manipulation of protected KiCad files;
- manufacturing outputs do not trace exactly to the reviewed saved source state.

A stop condition is not permission to lower a validation rule, silently substitute a part, bypass review or claim a check passed.

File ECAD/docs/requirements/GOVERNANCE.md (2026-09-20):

# Governance and source of truth

## Basis

Existing evidence: [ECAD guide](../../README.md), [manufacturing guide](../../MANUFACTURING.md), [repository PR template](../../../PULL_REQUEST_TEMPLATE.md), board notes and the released OH-SPEC-002 cable specification. The explicit authority hierarchy, requirement IDs, deviations and review status below are **adopted project policy under PR #1255**, justified by source/output conflicts in [the inventory](../reference/ARCHITECTURE_INVENTORY.md).

## Requirements

- **GOV-001:** KiCad MUST be the authoritative ECAD environment. The selected revision's schematic, PCB, project rules and resolved libraries together define its editable design. Generated PDFs, Gerbers, BOMs, screenshots and AI descriptions MUST NOT silently replace or override that source.
- **GOV-002:** Identify the baseline commit, board/revision, assembly and available build/use evidence. Successful builder use MAY establish acceptance of an existing released board unless a known relevant problem remains. A formal historical test report is not required; identify the report or maintainer knowledge being relied on. Where no build/use evidence is known, state unknown rather than inventing it.
- **GOV-003:** Use explicit, applicable approved interface/specification revisions ahead of copied historical notes. For example, the current approved revision of OH-SPEC-002 supersedes older Type A/E wire descriptions. If an approved specification and the current CAD disagree, record the conflict and resolve it before hardware release; do not assert that both are satisfied.
- **GOV-004:** Preserve existing validated electrical behavior, firmware interfaces, harness compatibility and mechanical fit unless the task intentionally changes them. A change to pinout, power path, ratings, component behavior, bus loading, layer stack or mounting MUST include impact analysis of all affected boards, cables, firmware and installation instructions.
- **GOV-005:** Existing designs are engineering evidence, not grandfathered universal specifications. For new designs, prefer the most current clearly intentional architecture, with explicit review of its remaining limitations. Legacy Nano templates, Type B alternatives and development prototypes MUST NOT be selected merely because they are available.
- **GOV-006:** Scope changes so that migrations, functional edits and manufacturing regeneration remain distinguishable in Git. Do not perform unrelated cleanup, mass UUID replacement, library synchronization or format conversion.
- **GOV-007:** An intentional deviation MUST identify the requirement, affected revision, reason, practical risk/mitigation, relevant checks and accepting maintainer. A short PR note is sufficient. Revisit it when the affected part, use or design changes; acceptance does not create a project-wide standard.
- **GOV-008:** A significant change includes changes to connectivity, parts/packages/ratings, interfaces, power or protection, critical placement, return paths, routing constraints, board stack/outline or assembly variants. Production-output changes are significant when they alter electrical, mechanical, assembly or functional behavior; regeneration or cosmetic changes alone do not establish significance. Pure documentation edits do not require hardware ERC/DRC unless they alter a design instruction or expose a conflict requiring subsequent hardware disposition. Record why a change is classified as minor.

- **GOV-010:** PR #1255 adopted this framework on 2026-09-11 when it merged into the default branch. Apply requirements to new designs and changed portions of existing designs, including affected dependencies. Preserve historical release status without automatic retroactive qualification or wholesale redesign. Cosmetic maintenance MUST NOT trigger unrelated migration. Already-open hardware PRs MUST identify applicable gaps and record their disposition.
- **GOV-011:** Anyone with repository merge permission MAY merge subject to repository controls. Build/use evidence MAY come from a trusted contributor, any sufficiently documented builder report, or John Steensen directly. Record the evidence and maintainer acceptance in the PR or existing board documentation; a separate formal engineering signoff is not required. Merge alone is not a claim that untested hardware works. John Steensen retains sole authority for the very-minor-change no-new-build decision under QUAL-010.

## Practical review status

OpenHornet uses practical build-and-use acceptance, not a formal certification program. Record what was checked, what was built/used and any known limitations. CAD checks, electrical review, manufacturing review and practical operation answer different questions, but do not require five separate approval forms or a prescribed laboratory campaign.

- **GOV-009:** State passed, pending, failed or not applicable for the checks relevant to the change. Summarize accepted exceptions and practical build/use evidence in the same PR record. A working build does not excuse a known relevant defect, and a clean CAD report does not prove operation.

## Requirement maintenance

- **GOV-012:** When a later reviewed change supersedes a recorded design decision, update its normative references, informative supplements and open-question status together. Record the old and new evidence with dates and exact revisions. If source, outputs and prior decisions disagree, identify the conflict and affected gates; neither a stale owner-intent statement nor a merged artifact alone resolves it. Keep historical inventory counts explicitly scoped to their original snapshot.

- **GOV-013:** Requirements documents contain enduring design/process rules and unresolved policy choices, not defect lists or implementation trackers. Track actual corrections in repository issues and their PRs. During a requirements discussion, retain candidate follow-ups in the discussion/PR until issue creation is authorized; do not create issues merely to complete this document.
- **GOV-014:** A new revision of the same PCB replaces the current source/output files in their canonical locations; use Git history and existing release tags for prior revisions. Do not create parallel revision-suffixed copies solely for history. When a different design makes a board obsolete, its files MAY remain temporarily in a clearly marked obsolete location for transition, then be removed through normal review. Preserve existing published release history; this rule is not permission to rewrite Git history or delete releases. Intentional supported assembly variants remain distinct.

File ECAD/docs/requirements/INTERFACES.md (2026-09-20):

# ABSIS architecture, interconnects and communications

Applicable derivative-board refresh work MUST also follow [ABSIS_MIGRATION.md](ABSIS_MIGRATION.md), including board-specific transceiver direction control, firmware and termination review.

## Basis and discovered architecture

The ALE+ merged in PR #1233 replaces ALE and its separate relay module by owner direction; see the [ALE+ supplement](ALE_PLUS_SUPPLEMENT.md). Existing connector mappings below describe the inspected master boards. Verify ALE+ pinouts, output control and harness/firmware transition explicitly before asserting drop-in compatibility.

Observed sources: [architecture inventory](../reference/ARCHITECTURE_INVENTORY.md), [board inventory](../reference/BOARD_INVENTORY.md), [interconnect root](../../interconnects/OH_Interconnect.kicad_sch), and [OH-SPEC-002 revision B](../../../release/OH-SPEC_Specifications/OH-SPEC-002%20-%20ABSIS%20CABLES_B_v3.pdf).

ABSIS combines ATX-derived distributed power, RS-485 controller chains, a distinct addressable-backlight chain, local I/O and USB host connections. A matching housing does not imply the same interface. The pin maps below are **observed PCB pad/net assignments**, cross-checked across the cited boards; they are not physical mating-face drawings or a blanket compatibility certificate.

| Interface and evidence | Pin assignments |
| --- | --- |
| RS-485/power Mini-Fit Jr. 2×3: Bus Master J2–J4; ALE/Mega J1/J2; HID Master J2 | 1: +12V_SUPPLY; 2: +5V_SUPPLY; 3: +3.3V_SUPPLY; 4: bus A; 5: bus B; 6: GND |
| I/O power Mini-Fit Jr. 2×4: ATX J4–J11; Bus Master/HID Master J1 | 1/2: GND; 3/4/8: +12V_SUPPLY; 5: +3.3V_SUPPLY; 6/7: +5V_SUPPLY |
| Backlight power Mini-Fit Jr. 2×5: ATX J3; Backlight Controller J1 | 1/2/3/6/7: +5V_SUPPLY; 4/5/9/10: GND; 8: +12V_SUPPLY |
| Backlight Mini-Fit Jr. 2×2: controller J2–J11 and Type A panel input/output connectors | 1/2: +5 V; 3: GND; 4: channel data, panel DIN or panel DOUT as applicable |
| ALE J6 / Mega J7 auxiliary header | 1: +12V_SUPPLY; 2: +3.3V_SUPPLY; 3: +5V_SUPPLY; 4: GND |
| Hall Sensor J1, JST PH 6-pin | 1: VDD; 2: MISO; 3: MOSI; 4: SCK; 5: CSN; 6: GND |

Counterexamples: ATX J25/J26 are also 2×3 but pins 1–3 are +12 V and 4–6 GND. Pit Management J3 is 2×4 but carries accessory relay contacts. Do not connect by cavity count. Backlight output data passes through the panel LED chain; it is not a passive RS-485-style parallel tap.

## Interface requirements

- **IF-001:** Changes intended to remain compatible with these existing interfaces MUST preserve their verified electrical and mechanical mapping. Before connection, reconcile board pads, schematic pins, harness endpoints and the matching interconnect symbol for the actual revisions. The table alone MUST NOT authorize a cable build.
- **IF-002:** Interface records MUST identify both connector halves, exact header/housing/contact MPNs, mating view, latch/keying, gender/contact terminology, pin 1, each pin's function/direction/voltage, current allocation and cable conductor assignment. Distinguish PCB-side, wire-entry and mating-face views.
- **IF-003:** Keep harness assembly references, pinout and interconnect BOM synchronized with board changes. Trace cables through all applicable interconnect sheets and bulkheads. Account explicitly for modified cables and unused conductors; do not assume straight-through wiring from the cable family name.
- **IF-004:** Apply OH-SPEC-002 revision B to new, replacement or reworked Type A/E cables: A/B data uses a **22 AWG stranded copper shielded twisted pair**, and the four power/return conductors use **16 AWG stranded copper**. Type A uses 39-00-0046 data contacts and 39-00-0211 power/return contacts; Type E uses 39-00-0048 data contacts and 39-00-0081 power/return contacts. Follow the specification for quantities and assembly details, and verify conductor and insulation compatibility with the selected contacts. Older copied wire descriptions MUST NOT override these requirements.
- **IF-005:** Cable Type B/F, C/G, D, H and J requirements MUST follow their specific sections of OH-SPEC-002 and the applicable assembly drawing. Maintain documented connector color/gender conventions and insulation of unused conductors. Use only explicitly defined cable types; the accepted shielding requirements are specified below.
- **IF-006:** A new incompatible interface MUST be identified as a new revision/type, with migration and misconnection controls. SHOULD use keying or physically distinct connectors where a plausible misconnection can damage hardware. Label voltage/function at accessible connectors.

## RS-485 requirements

The Bus Master v6.0.0 and Mega v3.0.0 implement THVD1410DR, CDSOT23-SM712 and 10 Ω series resistors on each bus conductor. Master branches have fixed 120 Ω A/B termination. Both use local 0.1 µF transceiver bypass and 10 kΩ logic resistors. Master R7/R8/R12 pull up receiver logic outputs; R1/R2/R3 pull down the tied enable nets. These are **not external A/B line-bias resistors**. The [refresh PR](https://github.com/jrsteensen/OpenHornet/pull/1228) gives the intentional replacement rationale, but its “external bias” wording must be read against the circuit.

The [TI THVD14xx datasheet, revision E](https://www.ti.com/lit/gpn/THVD1410), sections 6–7 and 9–12, is the component authority. Use its exact logic limits, including the 0.8 V VIL ceiling. Device ratings do not establish a qualified full-cockpit cable length, data rate or node count.

- **BUS-001:** An ABSIS RS-485 design MUST identify master/segment ownership, A/B polarity, all nodes/stubs, cable type/length, termination locations, transceiver supplies and shared reference path. Bus Master J2/J3/J4 are independent transceiver segments, not a passive three-way split of one A/B pair.
- **BUS-002:** Each physical segment MUST have a reviewed termination plan matching cable impedance and endpoint placement. The discovered 120 Ω master and far-end convention MUST be evaluated with total receiver loading and series protection. Do not populate a terminating resistor at every intermediate ALE/Mega. Existing last-node instructions use J2 pins 4/5 instead of the BUS OUT connector.
- **BUS-003:** Document receiver failsafe behavior and driver-enable states during reset, boot, programming, loss of power and bus idle. Calculate any required external A/B bias for all intended terminations and supported transceivers. Do not confuse RO pull-ups or DE pull-downs with differential line bias.
- **BUS-004:** New or substantially revised RS-485 interfaces SHOULD start from the intentional THVD1410 refresh, subject to datasheet and system review. Track specific derivative work in repository issues under ABSIS_MIGRATION.md. This does not qualify the reference circuit or expand an unrelated task into redesign.
- **BUS-005:** Verify transceiver pinout, logic thresholds, common-mode range, receiver loading, enable timing, protection clamping and series-resistor pulse/voltage ratings. Evaluate the complete protection path from connector through TVS return and PCB parasitics. Record residual faults not covered.
- **BUS-006:** Do not assume galvanic isolation or hot-plug safety. Document signal reference and shield/drain/chassis relationships. The refreshed master J6 connects to board GND; it is not evidence of a qualified whole-system shield-bonding policy.
- **BUS-007:** Exercise communication with intended firmware, rate, cable length, population, end termination and simultaneous loads before claiming tested operation for that configuration. Mixed-generation checks are optional under BUS-009. Use practical build/use evidence under QUALIFICATION.md.

## Other buses

- **IF-007:** Backlight changes MUST preserve LED DIN/DOUT direction, order, package-specific pin mapping, electrical levels and software indexing unless deliberately revised. Verify that chain power/return carries downstream current. A 2×2 connector can have only one return pin despite two +5 V pins.
- **IF-008:** Local I2C/SPI/display and HOTAS interfaces MUST have a voltage/address/pin map and documented cable extent. The 3.3 V Pro Mini requirement on the throttle inner grip MUST be preserved unless intentionally redesigned. Do not infer tolerance from a nominally similar module.

## Accepted communications baseline

- **BUS-008:** Preserve the current DCS-Skunkworks DCS-BIOS Arduino protocol at 250,000 baud, 8N1, and the Mega Master's three independently controlled segments. Use unique slave addresses within each segment and preserve the reviewed firmware direction-control timing. Current software pins library commit `b736782b5fa13443cae2caf3c59a3b5237b280e6`; record the actual software revision for a change rather than permanently freezing that dependency.
- **BUS-009:** The forward transceiver baseline is THVD1410DR. Support the intended standard cockpit population/wiring. Mixed old/new transceiver operation is desirable but optional, not a release or acceptance gate; document any configurations actually demonstrated without implying broader support.
- **BUS-010:** Use daisy-chain segments with termination at their two physical ends. The accepted initial development test target is 16 slaves over 10 m total cable per segment. This is a target to exercise, not a measured capability, existing-installation prohibition or mandatory retrospective test campaign. Record actual population, length and observed behavior; do not derive system capacity from address space or IC unit-load ratings alone.

[The pinned master implementation](https://github.com/DCS-Skunkworks/dcs-bios-arduino-library/blob/b736782b5fa13443cae2caf3c59a3b5237b280e6/src/internal/DcsBiosNgRS485Master.cpp.inc) supplies the baud/framing and port behavior.

## Shield and detachable drain requirements

OH-SPEC-002 revision B implements the owner-approved shield and detachable-drain requirements from Q-03. Apply these requirements to new, replacement or reworked Type A/E RS-485 harnesses. Existing revision A installations operating satisfactorily may remain in service; revision B does not by itself require retrofit. This updates the revision A baseline recorded in the 2026-09-10 architecture inventory; see PR #1274 (2026-09-20) and issue #1266 for implementation and verification status.

- **BUS-011:** Use a shielded stranded twisted A/B pair. Maintain shield continuity along each complete segment through insulated harness-side drain connections at intermediate boards/bulkheads. Bond to board GND only at the owning Master's J6 drain terminal; insulate the far end and avoid slave-GND/chassis bonds. Retain the normal bus GND conductor; the shield is not a load return. This defines the household installation baseline, not protective-earth bonding or a hot-plug guarantee.
- **BUS-012:** Cable removal from the Master MUST NOT require loosening a screw. Use one short secured lead from J6 to an insulated splice/fan-out, with a separate detachable drain connection for each J2/J3/J4 cable. Keep the six-pin bus connectors unchanged. Each cable unplugs at its bus connector and drain connector while the J6 screw stays secured. Do not place multiple loose drains under a terminal unless its specification allows that termination.
- **BUS-013:** Use the existing two-position JST SM family with only one contact populated in each mating half. The interconnect already specifies the parts below. Use cavity 1 for drain and leave cavity 2 without a contact or wire on both halves; confirm numbering and mating views in the harness drawing under IF-002. Follow the existing convention of female contacts nearest ABSIS, male contacts toward the removable cable.

| Location | Housing | Populated contact |
| --- | --- | --- |
| Master fixed drain pigtail | SMP-02V-BC | SHF-001T-0.8BS, female |
| Removable cable drain | SMR-02V-B | SYM-001T-P0.6(N), male |

These part selections come from the [interconnect connector notes](../../interconnects/OH_Interconnect.kicad_sch), which call the family JST SM. Housing names and contact sex are distinct; use the exact part numbers and drawing views.

- **BUS-014:** Keep drain pigtails short, insulated and strain-relieved. Verify conductor and insulation size against the selected contact's current manufacturer specification. If the cable drain is unsuitable for direct crimping, transition through an appropriate insulated splice to a compatible stranded pigtail. Do not force oversized wire or a bundle of shields into an SM contact.
- **BUS-015:** Label both drain connector halves with function and segment identity, and route/secure them with the associated bus cable. A two-position SM housing remains mechanically interchangeable with other two-position SM uses; an empty cavity is not mechanical keying. Review nearby mating opportunities and use placement, restraint and identification to prevent confusing drain and powered/signal connections.
- **BUS-016:** Check the completed harness for drain continuity, absence of unintended intermediate bonds, correct populated-cavity mapping, secure contact retention and ordinary communication with representative switched loads. Keep the assembly drawing and BOM consistent with this desired state before releasing a changed harness.

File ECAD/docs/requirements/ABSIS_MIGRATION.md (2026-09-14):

# Circuit migration requirements

Migration scope and completion are tracked in repository issues/PRs. This document defines how a scoped migration is performed; it is not a board backlog.

- **MIG-001:** Work on an affected board MUST identify the applicable task, reference circuit revision and intended migration scope before choosing circuitry. New designs reusing those functions SHOULD use the current intentional Master/Mega/ALE+ architecture as applicable, with the relevant source/output identity reviewed. Retaining a superseded circuit requires a documented technical reason and reviewed deviation under GOV-007. Unrelated maintenance MUST NOT silently expand into a hardware redesign.
- **MIG-002:** A circuit migration MUST include board-specific review of supply domains, complete USB/module current paths, regulator thermal demand, pin/pad mappings, transceiver direction control and firmware, termination/loading, protection, connector/harness compatibility and mechanical/return-current constraints. Copying the new IC or buck converter alone MUST NOT be reported as completing migration. Use authoritative datasheets and the applicable technical requirements.
- **MIG-003:** Record migration intent, source implementation, deterministic validation, human review, prototype evidence and release qualification separately in the board review record. Cite the exact implementation commit and related issue/PR. A stale unchecked task MUST NOT erase a merged implementation, and an implemented circuit MUST NOT be described as qualified without the required evidence. Update documentation and tracker status when authorized as part of the scoped hardware work.
- **MIG-004:** Disposition related failure reports in the migration review. Identify the affected fault/load configuration, proposed correction or remaining limitation, and regression evidence before claiming resolution. Replacing a reference circuit MUST NOT by itself establish resolution of a reported failure or compatibility with every power configuration. Significant derivative-board revisions require their own applicable ERC/DRC, CAM review and applicable physical build/use checks; reuse of reference-board evidence requires documented applicability.
- **MIG-005:** Select power changes from each board's actual input rails and loads. A 12 V-fed Pro Micro may require regulation plus source isolation; a 5 V-only board still requires source/backfeed review but MUST NOT inherit a buck stage without a demonstrated need. Separate implementation completion, lifecycle retirement and qualification in the linked task record. Retired boards are not pending active migrations.

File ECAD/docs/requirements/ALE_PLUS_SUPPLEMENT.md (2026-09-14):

# ALE+ design decisions

Owner decisions confirmed during the 2026-09-14 requirements discussion:

- ALE+ replaces the separate ALE and Relay Module functions.
- D2 is **S3MB**. This supersedes the earlier SS34 design-selection statement. Exact source, physical assembly and manufacturing metadata must agree under CMP-005, LIB-005, VAL-009 and MFG-018.
- The buck output intent is 7.5 V nominal / 7.3 V reported actual. This is not a guaranteed tolerance band or the RAW-pin voltage after the diode.
- Simultaneous USB/external connection is the design objective under USB-007; complete power-path review remains required.

Implementation corrections and build evidence belong in repository issues/PRs, not this decision record. Part selection does not assert which diode was fitted to a historical prototype or claim testing that was not reported.

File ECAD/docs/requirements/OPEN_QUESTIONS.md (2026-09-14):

# Requirements decisions

Owner decisions recorded 2026-09-14. IDs are retained for continuity. This file records policy, not repository defects or implementation status. Create issue follow-ups only after the discussion is complete and authorized.

| ID | Decision | Requirements |
| --- | --- | --- |
| Q-01 resolved | Accepted fabrication/routing profiles; prefer single-sided SMD, allow justified double-sided assembly; black mask and white silkscreen | PCB-007/009/010, MFG-019/020 |
| Q-02 resolved | Existing 250 kbaud DCS-BIOS protocol and segment architecture; THVD1410DR forward baseline; mixed generations optional; 16 slaves/10 m initial development test target, not proven capability | BUS-007 through BUS-010 |
| Q-03 resolved | Shielded stranded twisted pair; Master-end-only J6 bond through fixed lead/fan-out and separate two-position JST SM drain connectors, one contact populated per half; no screw loosening for cable removal | BUS-011 through BUS-016 |
| Q-04 resolved | SparkFun Pro Micro 5 V, Arduino Mega 2560 Rev3 and the specific 3.3 V Pro Mini throttle-inner-grip exception; support simultaneous USB/external power wherever practical | CMP-007, USB-007 |
| Q-05 resolved | No independent supplies on one bus; target 25% sustained-load capacity margin, 3% distribution drop and 10°C conductor rise; component-specific derating | PWR-004, PWR-007 through PWR-010 |
| Q-06 resolved | Household indoor 10–35°C room ambient, passive cooling and practical build/use checks; no formal certification campaign | QUAL-001 through QUAL-012 |
| Q-07 resolved | No universal LED selection; appropriate decoupling where feasible with reviewed constrained omissions | CMP-008, PI-007 |
| Q-08 resolved | Useful future diagnostic nets receive accessible test points on new designs | MECH-007/008 |
| Q-09 resolved | Existing successful builder use counts absent known relevant problems; contributor/builder/owner evidence accepted. Obsolete designs may remain temporarily; revisions replace current files, with history in Git | GOV-002/011/014, QUAL-007/008 |
| Q-10 resolved | Shared-library changes permitted in PRs with affected-consumer checks; substitutions need relevant comparison and ordinary review; no separate approved-parts bureaucracy | CMP-005, LIB-004/006 |
| Q-11 resolved | Astra/Codex–Konnect–KiCad workflow, capability discovery and appropriate smoke tests | WORKFLOW.md, TOOLCHAIN.md |
| Q-12 resolved | Repository-authorized mergers; development merge may precede practical testing; John alone accepts very minor changes without a new build | GOV-011, QUAL-010 |
| Q-13 resolved | S3MB is the correct ALE+ D2 selection; implementation cleanup and historical test details belong in the task/PR | ALE_PLUS_SUPPLEMENT.md |

## Discussion status

Q-01 through Q-13 are resolved. Harness drawing/BOM implementation and other repository work belong in separate scoped issues/PRs; no issues are created by recording these decisions.

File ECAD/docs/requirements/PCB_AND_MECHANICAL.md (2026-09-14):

# PCB layout, constraints and mechanical interfaces

## Basis

Observed sources include project JSON rules, routed widths/vias, copper zones, Edge.Cuts, fastener/keepout footprints, drawing templates and explicit manufacturing notes. [BOARD_INVENTORY.md](../reference/BOARD_INVENTORY.md) records board-specific values. Applying verified fabrication constraints and mechanical fit checks is **adopted project policy under PR #1255**; it does not establish one numerical rule set for all boards.

## Constraints and fabrication profile

- **PCB-001:** Before routing, define a board-specific fabrication profile: supplier/process, material, layer count/order, dielectric and copper thicknesses, finished board thickness/tolerance, finish, minimum trace/space, drill/annular ring, hole/edge clearances, mask/paste and assembly limits. Use current JLCPCB requirements for the selected service under MFG-012; satisfy both vendor capabilities and stricter electrical/mechanical needs. Use the accepted starting profiles below and confirm the selected JLCPCB service supports the actual order.
- **PCB-002:** Encode applicable constraints in the `.kicad_pro` and active project `.kicad_dru`, including net-class assignments. Confirm that rules actually load and match the intended objects; a loose `.kicad_dru` in the directory is not proof it is active. Document any checks not expressible in KiCad.
- **PCB-003:** Distinguish minimum constraints, routing defaults, preferred widths and actual routed geometry. An unused net class or zero project minimum MUST NOT be interpreted as an electrical/fabrication standard. Verify clearances and widths at pads, neck-downs, copper islands and zone connections, not only long track segments.
- **PCB-004:** Net classes MUST reflect the required current/voltage/signal behavior of their assigned nets. Determine width and via capacity from actual copper, temperature/drop budget and manufacturer capability. Do not copy numerical values merely to match an old board or achieve clean DRC.
- **PCB-005:** Copper zones MUST have intentional net/layer assignment and reviewed clearances, thermal connections and island removal. Check power continuity and return paths after refill. Zone presence does not prove a pin has a viable thermal connection or sufficient current capacity.
- **PCB-006:** Differential/controlled-impedance routing MUST use a documented stackup and target/tolerance supported by the relevant interface and fabrication process. Verify pair polarity, reference continuity, discontinuities and layer transitions. Do not infer USB or RS-485 routing requirements from an unrelated pair's default settings.

## Mechanical layout and assembly

- **MECH-001:** Identify the mechanical assembly/drawing revision governing board outline, mounting holes, connector orientation, height limits, controls/displays, panel cutouts and LED-to-legend alignment. Verify actual dimensions and tolerances; do not scale a screenshot or treat a footprint courtyard as the complete assembly envelope.
- **MECH-002:** Preserve fixed interfaces unless intentionally revised. Fit-check PCB and component geometry against the next higher assembly, fasteners/washers, brackets, mating cables and tool access. Account for both PCB sides and the assembled module/socket stack height.
- **MECH-003:** Verify closed, manufacturable Edge.Cuts geometry, internal cutouts/slots, plated versus nonplated holes and copper clearance to routed edges/fasteners. Define actual fastener-head and washer exclusion regions; inspect imported graphics and custom keepout footprints for enforceable rule areas.
- **MECH-004:** Inspect silkscreen for board identity/revision, reference designators, polarity, pin 1, connector function and jumper settings at installed orientation. Ensure markings remain readable after assembly and do not overlap exposed pads or necessary soldering areas.
- **MECH-005:** Optical/mechanical variants MUST be assessed in the assembled panel: legend alignment, LED direction, light leakage, display orientation, button travel, gauge zero sensor and magnet/sensor alignment. A fit or optical change is significant even if the netlist is unchanged.
- **MECH-006:** Account for soldering, rework, connector insertion force, strain relief and access to programming/reset/test points. Preserve the interconnect's UTIL_PHOTOSWITCH direct-solder requirement and zero-sense wheel clearance for that assembly unless intentionally revised.

- **MECH-007:** New designs MUST provide accessible test points for nets reasonably expected to need future diagnosis: supply/return domains, reset/programming, communication, relevant enables/control and analog references. Dedicated labeled pads are preferred where otherwise inaccessible; an accessible labeled connector pin may serve the same purpose. Review assembled access and document meaningful omissions rather than adding a pad to every net blindly.
- **MECH-008:** Test-point placement MUST permit the intended probe/fixture without shorting adjacent conductors or removing required protection. Identify points in the schematic and test procedure; check access after connectors, modules and panels are installed.

## Accepted fabrication and routing baseline

Owner accepted these starting profiles on 2026-09-14 after static inspection of all 69 PCB files at default-branch commit `da4eb6f2b41abe8ab530cbf7a97319dbaa41371b`: 63 two-layer, six four-layer, all specifying 1.6 mm. The count includes historical/development boards and is not a count of qualified products.

| Profile | Layers | Copper | Intended starting use |
| --- | --- | --- | --- |
| General | 2 | 1 oz each side | Ordinary controllers, interfaces and panel backlighting |
| Higher-current | 2 | 2 oz each side | Backlight Controller and justified higher-current designs |
| Four-layer | 4 | Explicitly defined on every layer | ALE+, Bus Master and designs needing additional routing/reference planes |
| Power distribution | 4 | 2 oz every layer | Existing ATX requirement |

- **PCB-007:** Reconcile each board's actual layer/copper requirements, CAD, CAM and order settings. The profiles do not override stricter board-specific requirements or authorize changes to an existing stackup merely to fit a default.
- **PCB-008:** Preserve applicable switch/fastener clearances or intentionally revise them with mechanical justification and fit checks. Board-specific rules do not become universal hole clearances.
- **PCB-009:** Default to FR-4, 1.6 mm thickness and lead-free HASL. Use ENIG when component assembly or other reviewed functional needs require it. Specify actual tolerances and compatible service options; four-layer inner copper MUST be explicit rather than left at supplier defaults. Current ALE+/Bus Master CAD records approximately 1 oz on each layer; recheck the actual board profile when ordering.
- **PCB-010:** Starting routing targets are 0.25 mm signal tracks, 0.20 mm ordinary copper clearance and 0.50 mm copper-to-routed-edge clearance. Prefer 0.8/0.4 mm via diameter/drill; 0.6/0.3 mm MAY be used for space constraints. These are starting targets, not automatic power ampacity, package-pad geometry or universal minima. Use stricter electrical/mechanical/vendor limits where applicable; document local fine-pitch or process exceptions. V-scoring needs its own edge profile.

[JLCPCB capabilities](https://jlcpcb.com/capabilities/pcb-capabilities) were checked on 2026-09-14. Capabilities and service combinations must be rechecked for each selected profile; no present-day vendor limit is permanently frozen here.

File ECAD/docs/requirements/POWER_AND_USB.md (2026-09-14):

# Power, protection, USB and power integrity

## Basis

Observed: ATX rails and connector assignments, ALE/HID Master diode paths, Mega/Bus Master refresh, UFC JP1–JP3 source selection, custom Pro Micro TPS2116 design, distributed LED bulk capacitors and shared ground zones. The existing power workbooks are incomplete estimates, not verified load limits. Requirements below are **adopted project policy under PR #1255**, grounded in engineering analysis and these repeated source-selection risks. See [inventory](../reference/ARCHITECTURE_INVENTORY.md).

## Distribution and protection

- **PWR-001:** For each rail, document its source, nominal/tolerance/transient range, each load and worst-case simultaneous demand, downstream pass-through demand, inrush, fault current and return path. Reconcile current totals against the actual assembly and firmware modes. Empty workbook cells MUST NOT be interpreted as zero current.
- **PWR-002:** Verify connector/contact and wire current capability for actual gauge, contact count, bundling and temperature; verify traces, planes, vias, thermal spokes and neck-downs for current, drop and temperature rise. PSU wattage or “2 oz” alone MUST NOT establish path ampacity. Shared returns MUST carry the combined applicable rail currents.
- **PWR-003:** Define protection for credible shorts, polarity reversal, overvoltage, inductive switching and external power faults. Record fuse/current-limit coordination with the weakest path and evidence for any reliance on upstream protection. Do not infer branch protection from an ATX supply's overall protection.
- **PWR-004:** Independent supplies MUST NOT feed the same power bus. Additional injection points, if needed, MUST originate from the same supply and be reviewed for current distribution and protection. USB and local module power require source selection/isolation so they do not parallel the host supply with the external bus. Do not connect an additional independent PSU to gain bus capacity.
- **PWR-005:** Review regulator dropout and dissipation over maximum input, output current, enclosure temperature and copper conditions. Review switches at actual drive voltage and load transient conditions. Inductive outputs MUST have a documented energy-clamp path and safe power-up/reset state.
- **PWR-006:** Distinguish distributed `+5V_SUPPLY`/`+3.3V_SUPPLY` from module-generated `+5V`/`+3.3V`, RAW/VIN, VBUS and standby supplies. Similar names MUST NOT be equated without tracing the circuit. Where notes claim separate nets are joined through a module, verify the exact module and netlist.

## USB and simultaneous power

- **USB-001:** Every USB-capable board MUST document USB-only, external-only, both-on, both-off, attachment/removal and failed/missing-source states. Trace current through regulators, diodes, load switches, jumpers, protection structures and module internals in both directions. Include phantom power through signal pins and the host/hub.
- **USB-002:** A board MUST NOT be declared safe for simultaneous USB and external power without analysis of the complete source-selection circuit and measured verification. A series diode on RAW/VIN can block one path; it does not inherently isolate USB VBUS, regulate 12 V to 5 V, or prove a third-party module cannot backfeed.
- **USB-003:** Preserve applicable assembly/programming restrictions until superseded by a reviewed and physically tested design. Legacy ALE and DDI/AMPCD controller notes describe removing a Pro Micro fuse and keeping its jumper open; the Standby Controller calls for removing the Mega before USB programming. Do not generalize either instruction to every module variant. Verify the exact module circuit before applying a modification.
- **USB-004:** Record allowed jumper combinations, source priority, voltage-drop effects and reverse-current limits. UFC's JP1/JP2/JP3 modes are board-specific; the custom ABSIS Pro Micro's proposed RAW-priority mux is not yet a qualified replacement.
- **USB-005:** For onboard USB, verify exact connector pin mapping, USB role, D+/D− continuity, protection, VBUS sensing, connector shield treatment and applicable USB-C CC configuration. Determine differential routing targets from the supported USB mode and selected stackup; no generic width or impedance value is imposed here.
- **USB-006:** Host PCIe USB-card advice in the interconnect is an installation convention, not electrical protection. Prototype tests MUST measure unexpected host/hub VBUS sourcing and source-transition behavior using a controlled setup.

## Decoupling, grounding and returns

- **PI-001:** Check every IC's supply/reference pins against its datasheet for capacitor value, effective capacitance, ESR/stability, voltage/temperature rating and placement requirements. Record the bypass capacitor reference and current loop; prioritize pin-to-cap-to-return loop impedance, not visual proximity alone.
- **PI-002:** Place bypass capacitors and their return connections to avoid shared high-current inductance. For a layer change, verify the return connection and continuity of the reference copper. Identify and correct split/necked returns under communication, clock, analog or switching paths, or document an analyzed alternative.
- **PI-003:** Size bulk capacitance for load transients and cable drop, and review inrush and discharge. The recurring 1000 µF backlight input capacitor is an observation, not a universal value. Dispersed 0.1 µF LED capacitors vary across boards; neither one-per-LED nor omission is an approved rule without the exact LED datasheet and layout analysis.
- **PI-004:** Route motor/solenoid, LED and other high-current returns so their voltage drops do not corrupt MCU, sensor or analog-reference operation. Document any intentionally separate grounds and the controlled connection between them. Do not split planes solely because nets are called analog and digital.
- **PI-005:** Analyze connector GND, cable shield/drain, USB shield, chassis/metalwork and supply return as distinct functions. Document intentional bonds and avoid relying on mechanical contact or an unconnected 3D model for continuity. Assess loops and unpowered-node behavior.
- **PI-006:** Include affected power/return paths in practical operating checks under QUALIFICATION.md, with representative sustained/peak loads and source transitions. Evaluate the accepted design targets against the actual assembly; avoid claims of certification from a functional check.

## Accepted design targets

- **PWR-007:** Target continuous path/source capacity of at least 1.25 times the calculated maximum sustained load, after applicable temperature/contact/copper derating. Assess startup, inrush and pulse loads separately; do not apply a margin to typical current and call it a worst-case budget.
- **PWR-008:** Target at most 3% nominal-rail distribution drop, including supply and return conductors, at maximum sustained load. Every device MUST remain within its recommended operating range including source tolerance and local diode/regulator drops; a stricter load requirement takes precedence.
- **PWR-009:** Target at most 10°C conductor temperature rise at sustained design load. Include contacts, traces, vias, neck-downs and shared returns. Component junction temperatures and regulators require their own thermal analysis; this is not a 10°C limit on all components.
- **PWR-010:** Use component-specific voltage/current/power and thermal derating based on the exact manufacturer data and operating point, including ceramic capacitance loss and MOSFET gate drive. Record justified departures from design targets; no single universal derating percentage applies to every device.
- **USB-007:** New and updated USB-capable designs SHOULD support simultaneous USB and external connection wherever practical. Use reviewed source isolation/selection, and verify the relevant operating states. Where safe simultaneous use cannot be provided, document the restriction and engineering reason; this is not permission to parallel independent supplies.
- **PI-007:** Include appropriate local LED decoupling in new designs where feasible. A constrained backlighting layout MAY retain or use a documented omission with relevant operating evidence and review of the exact LED requirements, bulk capacitance and supply layout. Existing omissions do not trigger automatic panel redesign; a datasheet-required capacitor omission remains an explicit engineering exception, not assumed compliance.

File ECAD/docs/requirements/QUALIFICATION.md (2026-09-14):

# Practical build acceptance and release

## Basis

Owner decisions on 2026-09-14 replace the earlier formal qualification model with practical build-and-use acceptance. Successful existing builder use counts; new or significant changes still need relevant physical evidence before being described as tested. A short PR report is sufficient.

## Build and use

- **QUAL-001:** Before a new build, identify function, interfaces, supply/load assumptions, mechanical fit, assembly and firmware. Decide what useful checks demonstrate that the board works. Address known problems affecting the intended build before ordering.
- **QUAL-002:** Before first power-up, inspect part identity, orientation, soldering, shorts and rail/connector continuity. Record revision, important substitutions/rework and firmware.
- **QUAL-003:** Use controlled, current-limited initial power where practical. Check rails, idle current, reset/boot and unexpected heating before connecting the host and other assemblies. Choose limits from the actual design rather than a universal bench setting.
- **QUAL-004:** Exercise the applicable inputs/outputs and representative operating modes, including lighting, motors/solenoids, communication and reset/programming. Record what was tried, whether it worked and limitations. Measurements are needed where voltage/current/thermal margins determine acceptability; a formal test plan is not required.
- **QUAL-005:** Check the supported USB/external-power combinations and transitions for unintended backfeed or malfunction. Exercise RS-485 with the intended firmware, wiring and simultaneous loads. Mixed-transceiver testing is optional unless compatibility is explicitly claimed for that configuration.
- **QUAL-006:** Run representative sustained loads until temperatures stabilize with passive cooling in the intended enclosure. Check supply drop, mechanical fit, access and optical function. There is no universal burn-in duration or sample-count requirement.
- **QUAL-007:** Evidence may be a trusted contributor's report, any sufficiently documented builder report, or John Steensen's direct testing. Maintainers may accept it through ordinary review. Formal laboratory certification or a separate human-engineer signoff is not required. Identify the actual tested configuration; component ESD ratings do not establish whole-system certification.

## Existing designs and changes

- **QUAL-008:** Successful builder use is sufficient acceptance evidence for existing released boards unless a known relevant problem remains. Capture available revision/configuration information without demanding nonexistent historical reports. For changes, identify which prior evidence remains applicable and which functions need checking again.
- **QUAL-009:** New designs and significant revisions need an actual build and relevant operating checks before being called tested/validated. A documented builder's installation can provide that evidence; a dedicated laboratory prototype is not required. Development merge may precede testing with status disclosed.
- **QUAL-010:** John Steensen alone MAY accept a very minor change without a new build. Record his acceptance, exact change and why prior practical evidence remains applicable. This does not waive relevant CAD, assembly or output checks. Check identification and polarity even for silkscreen-only work.
- **QUAL-011:** Deliberately incompatible changes require clear installation/transition instructions identifying affected boards, harnesses and firmware. Do not imply universal compatibility from limited testing.
- **QUAL-012:** Design for household indoor use at 10–35°C room ambient with passive cooling. Account for warmer enclosed-panel air and actual component temperatures. Assume dry, non-condensing conditions; outdoor/weather, industrial, environmental-chamber and formal EMC/ESD qualification are not standard OH acceptance requirements. Record any explicitly supported use beyond this baseline.

## Release

- **REL-001:** Release acceptance uses ordinary maintainer review of applicable CAD, electrical/assembly/output checks and practical build/use evidence. No separate five-stage qualification dossier is required. Disclose untested development status and known limitations; do not label unresolved relevant failures as tested success.
- **REL-002:** Keep current source, board identity, BOM/CPL, CAM, mechanical exports and installation instructions consistent. Update current files in place under GOV-014. Preserve traceability to the source used to build the package.
- **REL-003:** Record prototype rework/substitutions and incorporate applicable fixes in source. Recheck the affected functions; do not claim an unmodified board was tested when the working build required changes.
- **REL-004:** Adopting or amending requirements does not itself validate hardware or require a retrospective rebuild of working designs. Apply changes within their engineering scope.

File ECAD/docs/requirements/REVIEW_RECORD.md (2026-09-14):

# Practical change review record

Use the existing PR or board documentation. Keep the record proportional to the change; no empty forms, separate qualification dossier or repeated approvals are required.

## Identify the change

Record board/revision, assembly, source commit or hashes, intended change and relevant firmware. Identify existing successful-use evidence, or say the design is untested. Explain significant versus minor changes where that affects testing.

## Record relevant checks

Summarize the applicable requirement decisions, pin/part mapping, power/load assumptions, mechanical fit, fabrication profile and source/output agreement. Link ERC/DRC and related reports when performed; disclose unavailable checks and accepted exceptions. Record exact tool/library versions for CAD work and appropriate smoke-test evidence. Static documentation work need not run a live CAD toolchain.

Shared-library changes identify consumers and applicable integration checks. Procurement review records exact MPNs, supplier mapping and dated JLCPCB stock comparison/recheck where parts change.
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

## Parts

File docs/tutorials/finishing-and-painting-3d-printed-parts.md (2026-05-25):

# Finish and Paint 3D Printed Parts

This tutorial combines the OpenHornet finish specification with the finishing workflow for printed parts. Use it when preparing visible cockpit parts, knobs, buttons, indicators, and printed assemblies for their final paint and protective clear coat.

The original finishing workflow was written around PLA parts. The same sequence applies to most printed materials, but adjust sanding grit for the material: use coarser grit for harder materials and finer grit for softer materials.

## Safety

Paint, primer, lacquer, sanding dust, and resin dust can be hazardous. Work in a ventilated area, wear eye protection, and use a respirator appropriate for the products being sprayed or sanded. Follow the safety data sheets and curing instructions for the primer, paint, filler, and lacquer you choose.

## Finish Specification

Use filler primer on printed parts prior to painting. Topcoat can be Testors, Tamiya, LifeColor, automotive spray paint, airbrush paint, or similar products that match the finish and color requirements.

Nearest RAL values are Classic RAL codes and are included as practical color-matching references.

| FS-595 Color Number | FS-595 Color Name | Gloss | Nearest RAL | RGB | Hex | Where Used |
| --- | --- | --- | --- | --- | --- | --- |
| FS37875 | Insignia White | Lusterless/Flat | 9010 | 228/230/216 | `#E4E6D8` | Legends, knob indicas |
| FS37038 | Black | Lusterless/Flat | 7021 | 57/58/58 | `#393A3A` | All black surfaces |
| FS36231 | Dull Gull Grey | Lusterless/Flat | 7046 | 126/131/133 | `#7E8385` | Cockpit consoles, knobs, buttons |
| FS31136 | Insignia Red | Lusterless/Flat | | 143/64/62 | `#8F403E` | JETT knob pushbutton |
| FS33538 | Orange Yellow | Lusterless/Flat | | 239/161/27 | `#EFA11B` | Warning stripes |
| FS36373 | Light Gray | Lusterless/Flat | | 156/162/162 | `#9CA2A2` | Sky of SARI sphereoid |

## Recommended Materials

- Hobby knife
- Deburring tool
- Sanding block
- Dry sandpaper: P80, P120, and P400
- Wet/dry sandpaper: P600 and P1000
- Masking tape
- Acrylic paint, spot filler, or similar filling material
- Filler primer
- Topcoat paint matched to the finish specification
- Matte lacquer or other compatible protective clear coat

## FDM Parts

FDM parts usually need the most surface preparation because layer lines and support scars remain visible after printing.

### Step 1: Remove Supports and Skirt

Remove breakaway supports by hand or cut them away with a hobby knife. Remove the print skirt if one was used. Start with a hobby knife, then clean edges with a deburring tool.

Take your time around visible edges, screw bosses, pockets, and engraved areas. Small scars left at this stage often become more obvious after primer.

### Step 2: Coarse Sanding

Dry sand the part with P80 sandpaper. Use a sanding block wherever possible so flat faces stay flat and straight edges stay straight.

The goal is an even surface, not final smoothness. Do not sand so aggressively that edges, dimensions, or engraved details are lost. It is acceptable for some print artifacts to remain because they will be filled in the next step.

### Step 3: Fill Print Artifacts

Use a paintbrush to apply a thick layer of acrylic paint, spot filler, or similar material to remaining print artifacts. This can also build up small defects, lifted corners, or shallow areas.

Allow the filler to cure fully before sanding. If the filling material is still soft, it will tear, smear, or shrink under the next coat.

### Step 4: Sand Filled Areas

Dry sand the part with P120 sandpaper until the surface is uniform. If artifacts remain, repeat the filling and P120 sanding process until the part is ready for primer.

### Step 5: Apply Filler Primer

Mask anything that should not be painted. Apply filler primer over the part according to the primer manufacturer's instructions.

Filler primer removes the scratches left by coarse sanding and helps reveal remaining defects. Let it cure fully before continuing.

### Step 6: Fine Sanding

Remove the masking tape, then wet sand the part with P600 sandpaper. Sand until filler primer remains only in small low spots and the visible surface is smooth.

If the surface is not smooth after sanding, repeat the filler primer and P600 wet sanding process.

### Step 7: Paint

Mask unpainted surfaces again, then apply the selected topcoat. Two light coats are usually better than one heavy coat.

If the first coat has irregular spots, allow it to cure and lightly wet sand with P1000 sandpaper before applying the second coat. Do not sand after the final topcoat unless you plan to repaint, because sanding marks may remain visible through the clear coat.

### Step 8: Clear Coat

Apply one or two coats of matte lacquer or another compatible protective clear coat. The clear coat protects the paint from handling wear and gives the surface a consistent final sheen.

A quick way to preview how the part will look under clear coat is to wet the painted surface with clean water. The wet surface is not a perfect match, but it gives a useful preview of the final depth and contrast.

## DLP and Resin Parts

DLP and resin parts normally need less post-processing than FDM parts. Make sure resin parts are fully washed and cured before sanding, filling, or painting.

### Parts Without Engraving

For parts without engraving, lightly sand visible print lines with P600 sandpaper until the surface is smooth. Avoid over-sanding sharp edges and small details.

### Parts With Engraving

Engraved parts need extra care so lettering and symbols stay clean.

#### Step 1: Thin Paint

Thin acrylic paint with water so it flows easily into the engraving. Fill all engraved areas with the thinned paint, then let it cure fully.

#### Step 2: Thick Paint

Fill the engraving again with thicker paint, either straight from the tube or only slightly thinned. Slightly overfill the engraving because many paints shrink while drying. Repeat as needed until the engraving is fully filled.

#### Step 3: Sand Excess Paint

Dry sand the excess paint from the surface with P400 sandpaper. Use light pressure and keep the sandpaper flat so the filled engraving remains crisp.

#### Step 4: Polish

Dry polish the part with P1000 sandpaper until the visible surface is uniform.

#### Step 5: Clear Coat

Apply one or two coats of matte lacquer or another compatible protective clear coat.

## Final Inspection

Before installing finished parts, check the following:

- Color matches the finish specification closely enough for the part location.
- Edges and engraved details remain sharp.
- No support scars, layer lines, sanding scratches, or primer defects are visible.
- Paint is fully cured and does not feel soft or tacky.
- Clear coat sheen is consistent across the part.
- Masked surfaces, holes, and mating features remain clear of paint buildup.

## Source and Credits

This page replaces the former GitHub wiki pages for the OpenHornet finish specification and finishing tutorial. The finishing workflow was originally contributed by Balz Reber, and the color specification references FS-595 colors with practical matching information from Federal Standard color references.

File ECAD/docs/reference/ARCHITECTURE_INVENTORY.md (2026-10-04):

> Archived static audit evidence. Historical observations and findings below are not a current defect tracker or normative requirements. Use repository issues for active corrective work.

# Architecture evidence and findings

**Informative review, not an electrical audit certificate.** Baseline: `master` at `c259a65a1759801a2affea817fd99f6a14f1e1fe`, reviewed 2026-09-10. [BOARD_INVENTORY.md](BOARD_INVENTORY.md) enumerates every PCB and modern/legacy schematic candidate with exact source paths, observed parts, connectors, rails, constraints and mechanical footprint evidence.

## Historical paths and current lifecycle

The detailed entries below retain the original snapshot, including old paths and observations. PR #1233 later moved ALE, Relay Module and HID Bus Master into `zz_OBSOLETE_*` directories and marked MPC/Pro Micro in development. Use [ABSIS_MIGRATION.md](../requirements/ABSIS_MIGRATION.md) and [ALE_PLUS_SUPPLEMENT.md](../requirements/ALE_PLUS_SUPPLEMENT.md) for the 2026-09-14 update. Historical facts are not present support or qualification claims. Source links below are pinned to the original inventory commit where appropriate.

## Scope and method

The complete Git tree was inventoried. Read-only structured inspection covered all 68 PCB files, 71 modern schematics, 67 modern project files, 60 legacy schematics, 172 footprint files and 11 modern symbol-library files. Legacy project/cache libraries were inspected as historical dependencies. Supporting review covered three ECAD Markdown guides, all 13 ECAD workbooks, three Word documents, manufacturing instruction text, library tables, custom rules, interconnect CSV/BOM logic and CAM file metadata. Targeted released specifications, Gerber archives and refresh PRs were checked to distinguish intent from copied notes.

This is a requirements-oriented static corpus review. It is **not** a complete datasheet audit of every part, visual inspection of every routing layer, independent schematic connectivity reconstruction, vendor CAM acceptance or physical validation. All current root/child schematic structures and placed PCB pad/net data were inspected; the critical ABSIS connector and power/protection paths received additional targeted inspection. KiCad/Konnect were unavailable here, so no ERC, DRC or KiCad schematic-parity check was run. Binary MCAD/3D assets and historical rendering archives were catalogued but not individually fit-checked. These limits are retained rather than labeling the entire corpus “validated.”

No PCB, schematic, project, library, manufacturing output or workbook is changed by this PR.

## Pending successor supplement

The [ALE+ supplement](../requirements/ALE_PLUS_SUPPLEMENT.md), updated 2026-09-14, records merged PR #1233, the historical 7.5 V nominal / 7.3 V actual buck intent and current D2/source/output conflict (Q-13). The original 2026-09-11 SS34/cosmetic-only statements no longer unambiguously describe merged revision 8.0.1. Counts and detailed findings below remain the historical baseline.

## Issue-backed migration intent

[ABSIS_MIGRATION.md](../requirements/ABSIS_MIGRATION.md) maps issue #1220 and related failure reports to affected boards. The older power/RS-485 circuits listed there are pending intentional migration, not equally preferred design alternatives. Master/Mega and ALE+ implementation have merged; HID is obsolete and Backlight Controller power review is tracked; tracker checkboxes and qualification status are separate.

## Evidence map

Paths below are relative to the repository root unless linked. Board source locations are fully linked in the board inventory.

| Evidence | Findings and relevance |
| --- | --- |
| [ECAD/README.md](../../README.md), [ECAD/MANUFACTURING.md](../../MANUFACTURING.md), [ECAD/REVIEW.md](../../REVIEW.md) | KiCad source, JLCPCB output structure and supplier preference, 1.6 mm default thickness, usually two layers/top SMD; board-specific exceptions; preview tooling has dependency limitations. Use the current KiCad 10 setup instructions. |
| [PR template](../../../PULL_REQUEST_TEMPLATE.md) | Existing expectation of schematic requirements notes, review, version changes, constrained mechanics, BOM/Gerbers/MCAD and release copies. These support, but do not already implement, the new qualification gates. |
| [Cable specification A v2](https://github.com/jrsteensen/OpenHornet/blob/c259a65a1759801a2affea817fd99f6a14f1e1fe/release/OH-SPEC_Specifications/OH-SPEC-002%20-%20ABSIS%20CABLES_A_v2.pdf) | Explicit 2025-11-02 revision changes Type A/E data conductors to 24–16 AWG twisted stranded pair; four power/return conductors remain 16 AWG. Exact cable/housing/contact families. Text and rendered sheet reviewed. |
| [Interconnect root](../../interconnects/OH_Interconnect.kicad_sch) and its five child sheets | Assembly/cable references, connector variants and mates, voltage/signal naming, subsystem topology and termination notes. Older generic-wire notes conflict with the later cable specification. |
| [Bus Master/Mega refresh PR #1228](https://github.com/jrsteensen/OpenHornet/pull/1228) | Explicit reliability/ESD rationale for THVD1410 refresh, master four-layer conversion, shield drain and power-path diodes. Current files show implementation differences from prose; see findings below. |
| [Custom Pro Micro PR #1213](https://github.com/jrsteensen/OpenHornet/pull/1213) | Explicitly an initial, unrouted and untested development design. Intended to address RAW/USB power coexistence using a priority mux. |
| [PowerDistribution.xlsx](../PowerDistribution.xlsx), [PDUPowerRequirements.xlsx](../PDUPowerRequirements.xlsx) | Incomplete older load estimates. `Summary` has mostly empty loads; PDU sheet has missing entries and Nano-era names. No complete approved current/drop/thermal budget inferred. |
| [OpenHornet IO Requirements.xlsx](../OpenHornet%20IO%20Requirements.xlsx), [ABSIS 2.0 Part Numbers.xlsx](../ABSIS%202.0%20Part%20Numbers.xlsx) | Useful functional intent; planning-era Nano assignments, proposed functions and old part-number mapping are not current interface authority. |
| [PCB Master BOM](../../PCBs/OpenHornet%20PCB%20Master%20BOM.xlsx), [ABSIS BOM](../../PCBs/ABSIS/ABSIS_BOM.xlsx), [UFC connections](../../PCBs/Functional%20PCBs/UFCconnections.xlsx) | Parts/MPN/supplier and interface evidence; not automatically synchronized with latest source. Master BOM, `MASTER`, `Top Components` and `Bottom Components` sheets retain historical metadata and must be reconciled with the latest source. |
| [Interconnect parts list](../../interconnects/reference/OH-PL-INTERCONNECT_A_v5.xlsx), [metadata quick reference](../../interconnects/reference/Interconnect%20Metadata%20Quick%20Ref.xlsx), [CSV combiner](../../interconnects/utilities/oh-interconnect-csv2bom.py) | Connector/housing/contact metadata and reference/quantity conventions. Combiner groups semicolon input by PN and sums Qty; it does not verify pinouts, missing metadata or mixed descriptions. |
| [Generation guide](../Generating_ECAD_Manufacturing_Files-V0.1.docx), [relative path guide](../relative_kicad_paths.docx), [2021 block diagram](../OpenHornet%20Block%20Diagram.pdf) | Refill/regenerate advice and portable library intent; older software steps and Nano topology require revision-specific interpretation. Block-diagram first page visually reviewed. |

## Architecture and generations

| Area | Recurring implementation | Classification |
| --- | --- | --- |
| Distributed power | ATX breakout supplies +12 V, +5 V, +3.3 V plus standby/control; Mini-Fit Jr. distribution, separate backlight feeds and auxiliary XT60 interfaces | Repeated intentional architecture; allowable rail currents/source combinations remain unresolved |
| ABSIS I/O | ALE and Mega modules with power + A/B on six-pin connectors; incoming/outgoing bus through nodes; local headers connect controls | Repeated interface mapping, not a guarantee that all named modules are compatible |
| Refreshed RS-485 | Master v6.0.0 and Mega v3.0.0: THVD1410DR, CDSOT23-SM712, two 10 Ω line resistors, 0.1 µF bypass, 10 kΩ logic pulls; master 120 Ω terminators | Intentional 2026 refresh. Candidate basis for new work; physical qualification and mixed-generation limits need records |
| ALE+ successor (merged #1233) | Integrated I/O and two output channels; THVD1410/SM712 refresh; buck supply and four-layer PCB | Owner-confirmed replacement for ALE plus relay; see [ALE+ supplement](../requirements/ALE_PLUS_SUPPLEMENT.md) for source and test-evidence scope |
| Older RS-485 | ALE, HID Master and several instrument controllers use MAX487EESA+T and a local 0.1 µF capacitor | Still present in current directories; not automatically the preferred new design |
| USB | Purchased Pro Micro/Mega modules and hubs; direct USB controllers alongside RS-485; UFC source selection; custom Pro Micro USB-C development | Multiple power generations and board-specific programming restrictions |
| Backlighting | WS2812B, WS2812B-Mini and WS2812B-2020; usually Mini-Fit Jr. DIN/DOUT chain with parallel +5 V/GND pass-through | Repeated architecture, package-specific electrical/optical behavior. Not RS-485 or analog PWM wiring merely because MCU pins are PWM-capable |
| DDI/AMPCD | Local I2C expander/button interface, shared IRQ, dedicated controller and separate lighting functions | Board-specific local bus. Legacy modular DDI text does not supersede current full boards |
| Instruments/HOTAS/UFC | Steppers/servos, optical zero sensors, magnetic SPI sensors, I2C muxes/ADCs/expanders, display controllers and keyboard scanning | Several distinct functional families; their ratings and local-bus rules are not global ABSIS specifications |
| Templates and placeholders | Nano and Mega shield templates, Type B ECS alternative, footprint-empty MPC PCB, partly placed custom Pro Micro | Historical/development candidates; active support and validation unknown |

Legacy `.sch/.pro` files and multiple generations of modern files coexist. Use KiCad 10 for current work. File-format recency and title-block dates do not alone establish architectural authority. In particular the refreshed Master PCB retains a 2024 title date while the schematic has a 2026 date. The update history and component topology are stronger evidence of intent.

## Interconnect hierarchy and topology evidence

| Sheet | Architecture observed | Explicit endpoint / special notes |
| --- | --- | --- |
| `OH_Interconnect` | Root with five child sheets and generic board/cable/connector reference blocks | OH-SPEC-002 and separate interconnect parts list called out |
| `OH_Upper_Instrument_Panel` | UIP bus-master symbol, ALE-controlled panels, DDI-related assemblies, UFC, USB hubs and backlight chain | Termination at `1A6J2` |
| `OH_Lower_Instrument_Panel` | ATX breakout, backlight controller, pit management, bus master, ALE/instrument assemblies and hubs | Termination at `2A7A1J2`; inter-subsystem power/backlight links |
| `OH_Left_Console` | Bus master, Mega/ALE I/O, relay accessories, throttle/axis sensors, hubs and BL distribution | Termination at `4A7A2J2`; modified `4A1W11` power-only cable feeds |
| `OH_Right_Console` | Bus master, ALE/relay nodes, instrument/panel and hub/backlight wiring | Termination at `5A10J2`; modified `5A1W10` power-only cable |
| `OH_Center_Tub` | Seat ALE, two stick Hall sensors, stick USB and load/seat wiring | Seat cable links shown on Left Console; not a separately inferred terminated bus |

This establishes subsystem relationships and named endpoint instructions, **not** a fully certified harness graph. Generic reference symbols on the root sheet must not be counted as installed assemblies. Parenthesized cross-sheet references and modified cable branches need instance-aware tracing. RS-485 master outputs are independent electrical segments. The USB network consists of separate controller connections and powered hubs; bus cable power can coexist with a controller's USB connection, making power-state review essential.

## Connector and pinout conventions

See the exact observed bus maps in [INTERFACES.md](../requirements/INTERFACES.md). Recurring families include Mini-Fit Jr. 4.20 mm power/bus connectors, 2.54 mm headers/sockets and Harwin M20 harness housings, JST PH local sensor/accessory connectors, JST SM panel-to-panel cable pairs, Molex KK-254 controls and USB/module connectors. XT60, Hirose, DIN and audio/load connectors appear in specific assemblies and are not generic replacements.

Root interconnect notes place JST SM female-contact jacks nearest ABSIS and male-contact plugs toward the separate panel. The cable specification provides the detailed Type A/B/C/D/E/F/G/H/J housing and crimp selections. These are stronger evidence than a generic connector symbol, but every exact contact/gauge and mating view still needs verification.

## Repeated parts, protection and power-integrity evidence

- Transceiver generations and supporting values are listed above. Master R7/R8/R12 are receiver-output pull-ups and R1/R2/R3 enable-net pull-downs; the current pad nets do not show the external A/B bias network implied by the PR's wording.
- ALE/HID Master use 1N5819WS on the distributed 12 V-to-module RAW path. Refreshed Master D4 and Mega D2 use S3MB. These observations do not prove that USB VBUS is isolated inside the plugged-in module.
- Hall Sensor has MT6835GT, ESD5Z5V0 and local 0.1 µF bypass. Analog sensing must account for exact sensor variant, supply, magnet geometry and firmware. Older master BOM sensor naming differs.
- MOSFET accessory and controller implementations include IRLML6402TRPBF and IRFB3206PBF; some controllers include explicit flyback diodes. No uniform clamp topology or qualified output-current rule is established across the corpus.
- Many Type A backlights have 1000 µF bulk capacitance and differing quantities of external 0.1 µF capacitors. For example CAUTION LIGHTS has 24 WS2812B and 24 external 0.1 µF parts, COMM has 109/108, ANT SEL 17/7, and AV COOL has no such external 0.1 µF part in its PCB component list. HUD lacks the common bulk/status subcircuit. This may reflect LED variants or history; it is not proof that bypass can be omitted.
- The recurring 470 Ω part on ANT SEL is the status-LED resistor (`R1`, GND to D1 cathode net), **not** a DIN series resistor. Component-value repetition alone does not reveal circuit purpose.
- Repeated Type A copper zones use +5 V on F.Cu and GND on B.Cu. The refreshed master's intended four-layer rail/ground arrangement is described in PR #1228. Neither pattern is a mandatory stackup for all boards or proof of adequate return impedance.

## Library, geometry and manufacturing evidence

The shared `ECAD/lib/OH_Symbols` directory contains six modern libraries: `OH_Interconnect` (74 top-level symbols), `KiCadCustomLib` (112), `OpenHornet` (17), `Arduino Pro Mini 5v` (2), `ABSIS` (3) and `OH_Symbols` (144). Additional modern files are template caches, an interconnect rescue library and a local USB-C asset. Legacy `.lib` caches coexist. The 172 footprint files span OH, template and local-asset libraries; PCB-embedded copies also use standard KiCad libraries.

Common footprints include Mini-Fit/PH/KK/header variants, 0603/0805 passives, multiple WS2812 packages, module sockets, M3/other mounting holes, panel fastener keepouts and logos. Board inventory entries retain exact footprint-family names and observed mechanical types. These references establish intended mechanical relationships; verifying MCAD, drill tolerances and package dimensions still requires design review.

The ECAD setup guide uses `KICAD_USER_OH_3DMODELS`, `KICAD_USER_OH_FOOTPRINTS`, `KICAD_USER_OH_SYMBOLS`, and `KICAD_USER_OH_TEMPLATES`. The interconnect's `sym-lib-table` still references `C:/GitHub/OpenHornet/ECAD/PCBs/ABSIS/libs/ABSIS_2.0.lib`; that path is not portable. Generated/cache data and local settings are already tracked in places, but this PR does not normalize them.

Seventeen `.kicad_dru` files exist. Sixteen Type A panel files repeat a deliberate mechanical-clearance rule: B.Cu physical hole clearance of 2.65 mm for NPTH pads with Hole_Size_X at least 11 mm, and F.Cu physical hole clearance of 0.5 mm for NPTH pads. The conditions are layer/pad based despite the rules being named for GND/+5 V; these are not blanket copper-edge or electrical-net limits. The custom Pro Micro file is named `JLCPCB.kicad_dru`, not after `ABSIS_Pro_Micro`; its existence does not show it is active. Its selected constraints mention four/six-layer capabilities. A future toolchain must verify rule loading and supplier applicability before reuse.

Observed defaults include 0.2 mm clearance and 0.25 mm routing width in many projects, 0.6/0.4 mm older ABSIS vias and 0.6/0.3 mm refreshed vias. Some Type A boards have +5 V/GND classes with 0.75/0.5 mm widths. Actual routed widths differ from these defaults. Project minimum clearances can be zero and copper-edge minima differ substantially. No single project-wide fabrication limit follows from these values.

Seventeen non-legacy project files contain DRC exclusion records, including UFC Main (34), HUD (14), SIM CONTROL (11), Hall Sensor (9), and smaller counts elsewhere. Ignored categories include missing courtyards in many projects; UFC additionally ignores library-footprint mismatch and starved thermals. These are **configuration findings, not freshly observed DRC violations or approved waivers**.

The existing output convention includes Gerber ZIP, BOM and CPL under `JLCPCB/production_files`, with release copies under `release/OHE_Electronics`. Older BOM headers often contain only Comment/Designator/Footprint/LCSC; newer files sometimes add Quantity. Source fields such as Manufacturer PN must be retained in the new traceability process even where supplier upload CSVs omit them. CPL side/origin/rotation still needs actual output review.

Explicit fabrication exceptions include ATX four layers/2 oz per layer, Backlight Controller two layers/2 oz per layer, and both-side SMD assembly for UFC Main and Function Select. The DDI/AMPCD instructions name TCA9554PWR and PCA9554PWR alternatives with package-suffix caution. These are board-specific evidence, not a global automatic-substitution policy.

## Findings requiring disposition

| Finding | Evidence | Interpretation / action |
| --- | --- | --- |
| F-01: ALE Relay layer conflict | Schematic note specifies four layers; PCB layer table and released Gerber ZIP have only top/bottom copper | Legacy maintenance/fabrication disposition only; ALE+ successor is four-layer. See Q-01 and [ALE+ supplement](../requirements/ALE_PLUS_SUPPLEMENT.md) |
| F-02: Mega release instruction conflicts with CAD/CAM | `release/OHE_Electronics/ABSIS002-10 - PCB, ABSIS_MEGA/Important Manufacturing Instructions.txt` says four layers; current Mega PCB and released ZIP have two | Potential misplaced instruction; do not infer intent without owner disposition, Q-01 |
| F-03: Master manufacturing note absent | Refresh PR says note added; current Master production directory and release package have no such note. PCB and checked ZIP have four copper layers | Resolve exact manufacturing profile/document placement, Q-01 |
| F-04: Refresh incomplete across families | Master/Mega and merged ALE+ use THVD1410; obsolete ALE/HID and selected active controllers retain MAX487 | ALE+ is the intended ALE/relay successor; issue #1220 establishes migration scope for derivative controllers. See ABSIS_MIGRATION.md; tested limits and qualification remain Q-02/Q-09 |
| F-05: RS-485 note error and bias terminology | Master/Mega note gives low threshold as `.8VCC`; TI datasheet section 7.4 states 0.8 V. Logic pull networks differ from PR's external-bias description | Correct notes in a separately scoped hardware/docs follow-up; do not encode wrong threshold or presumed bias, Q-02 |
| F-06: Divergent USB restrictions | ALE/DDI controller module-fuse/jumper instructions, Standby Mega removal, Mega note mentions programming “Pro Micro,” UFC source-selection modes | Module-specific power analysis and corrected instructions needed, Q-04 |
| F-07: Cable text lags released specification | Interconnect Type A/E generic 16 AWG text versus OH-SPEC-002 A twisted pair | Newer explicit cable specification wins; synchronize later, Q-03 |
| F-08: Development design in current tree | Custom Pro Micro only partly placed, no routed tracks; PR explicitly untested. MPC PCB has no footprints | Do not treat as validated references, Q-09 |
| F-09: Case-split companions | `Functional PCBs/IFEI/IFEI.kicad_pro` and schematic versus `ifei/ifei.kicad_pcb`; same pattern for `UTIL_PHOTOSWITCH`/`util_photoswitch` | Exact-path/project pairing must be fixed or explicitly resolved before parity/export, Q-10 |
| F-10: Incomplete/stale requirements and parts metadata | Blank power budgets, Nano-era planning sheets, `1) XXXX` schematic notes, old BOM sensor naming and library paths | Do not derive approved ratings/parts from placeholders, Q-05/Q-09/Q-10 |
| F-11: Inconsistent constraints and exceptions | Varied copper-edge minima, existing exclusions and ignored rules, nonmatching Pro Micro custom-rule filename | No universal numeric fabrication rule or approved exception list inferred, Q-01/Q-10 |

Authoritative external checks: [TI THVD14xx datasheet revision E](https://www.ti.com/lit/gpn/THVD1410) for pin functions/thresholds; [Bourns CDSOT23-SM712 datasheet](https://www.bourns.com/docs/product-datasheets/cdsot23-sm712.pdf) for the protection-device/package reference; [KiCad IPC API](https://dev-docs.kicad.org/en/apis-and-binding/ipc-api/) and [KiCad 10 CLI](https://docs.kicad.org/10.0/en/cli/cli.html) for the workflow proposed in the original review and subsequently adopted. No full per-part qualification is claimed.

## Proposed policy versus discovered standards

Discovered standards worth preserving within scope are the recurring connector pin maps, released twisted-pair cable requirement, separate RS-485/backlight topology, explicit board-specific manufacturing instructions, and the intentional THVD1410 refresh direction. Policy subsequently adopted by PR #1255 comprises semantic editing preference, stable requirement IDs, reproducible validation/evidence, exact part/pad verification, controlled deviations, source/CAM traceability and separate physical/release gates. Numerical budgets, environmental limits and unresolved architecture choices remain in [OPEN_QUESTIONS.md](../requirements/OPEN_QUESTIONS.md).

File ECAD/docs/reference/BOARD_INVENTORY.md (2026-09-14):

> Archived static audit evidence. Historical observations and findings below are not a current defect tracker or normative requirements. Use repository issues for active corrective work.

# Board and project inventory

**Informative baseline evidence, not requirements or validation results.** Snapshot: `c259a65a1759801a2affea817fd99f6a14f1e1fe`.

Counts: 68 `.kicad_pcb`, 71 `.kicad_sch`, 67 `.kicad_pro`, 60 legacy `.sch` and 59 legacy `.pro` files. Of the 68 PCB files, 63 are outside legacy/template directories (11 ABSIS, 30 Type A backlight, one Type B backlight and 21 functional), three are explicitly legacy PCBs and two are templates. These are file/project candidates, not 68 distinct qualified products.

Method: structured read-only extraction of top-level schematic instances/notes/sheets, PCB embedded footprints/pad nets/zones/routed geometry and project JSON, followed by targeted circuit and document checks. All modern files were parsed; all legacy schematics and shared symbol/footprint definitions were examined for structure and conventions. No KiCad ERC/DRC, complete physical package audit, every-layer visual routing review or bench validation was performed.

Widths/drills below are **mm**, rounded only to remove floating-point representation noise. Project minima are separate from Default net-class settings and actual geometry. Footprint counts include logos/holes/mechanical items. Rail lists are selected net names, not proof of equivalent or regulated domains. Supporting evidence and identified conflicts are in [ARCHITECTURE_INVENTORY.md](ARCHITECTURE_INVENTORY.md).

## Historical paths and current lifecycle

The detailed entries below retain the original snapshot, including old paths and observations. PR #1233 later moved ALE, Relay Module and HID Bus Master into `zz_OBSOLETE_*` directories and marked MPC/Pro Micro in development. Use [ABSIS_MIGRATION.md](../requirements/ABSIS_MIGRATION.md) and [ALE_PLUS_SUPPLEMENT.md](../requirements/ALE_PLUS_SUPPLEMENT.md) for the 2026-09-14 update. Historical facts are not present support or qualification claims. Source links below are pinned to the original inventory commit where appropriate.

## Successor added after the historical snapshot

**B69: ABSIS_ALE+** was outside the original 68-file snapshot and subsequently merged in PR #1233 on 2026-09-13. See [ALE_PLUS_SUPPLEMENT.md](../requirements/ALE_PLUS_SUPPLEMENT.md) for revision 8.0.1 evidence and the current D2/source/BOM conflict (Q-13). It replaces B01/B02; HID Bus Master is also obsolete. Reported v8 testing does not establish qualification of a different D2 assembly.

See [ABSIS_MIGRATION.md](../requirements/ABSIS_MIGRATION.md) for the issue-backed power/RS-485 update scope and implementation status of affected boards. The baseline entries below retain historical observations; they do not override that migration direction.

## PCB sources

### B01: ABSIS_ALE

- Lifecycle: intended to be replaced by ALE+ (B69); retained here as master-baseline and installed-hardware evidence.

- Function: General Pro Micro I/O node with RS-485 in/out.
- Sources: [PCB](https://github.com/jrsteensen/OpenHornet/blob/c259a65a1759801a2affea817fd99f6a14f1e1fe/ECAD/PCBs/ABSIS/ABSIS_ALE/ABSIS_ALE.kicad_pcb); [schematic](https://github.com/jrsteensen/OpenHornet/blob/c259a65a1759801a2affea817fd99f6a14f1e1fe/ECAD/PCBs/ABSIS/ABSIS_ALE/ABSIS_ALE.kicad_sch); [project](https://github.com/jrsteensen/OpenHornet/blob/c259a65a1759801a2affea817fd99f6a14f1e1fe/ECAD/PCBs/ABSIS/ABSIS_ALE/ABSIS_ALE.kicad_pro).
- Observed PCB revision: `3`; copper layers: F.Cu, B.Cu; thickness: 1.6; 17 embedded footprints.
- Repeated/functional parts: Mini-Fit Jr. 2x03 ×2; PinHeader_2x06 ×2; 0.1uF ×1; MAX487EESA+T ×1; ProMicro_5V/16Hz ×1; RST ×1; 1N5819WS ×1; PinHeader_1x06 ×1; PinHeader_2x02 ×1.
- Connector footprint families: Molex_Mini-Fit_Jr_5566-06A2_2x03_P4.20mm_Vertical ×2; PinHeader_2x06_P2.54mm_Vertical ×2; PinHeader_1x06_P2.54mm_Vertical ×1; PinHeader_2x02_P2.54mm_Vertical ×1.
- Selected rails: +5V, /+12V_SUPPLY, /+3.3V_SUPPLY, /+5V_SUPPLY, GND.
- Net classes (clearance/track/via diameter/drill): Default: 0.2/0.25/0.6/0.4.
- Project minima: min_clearance=0; min_track_width=0.2; min_copper_edge_clearance=0.05; min_through_hole_diameter=0.3; DRC exclusion records: 0.
- Actual routed widths: 0.3048, 0.4572, 0.635, 0.9144, 1.6256; via diameter/drill forms: 0.6/0.4.
- Mechanical footprint evidence: MountingHole_3.2mm_M3_DIN965 ×4.

### B02: ABSIS_ALE Relay Module

- Lifecycle: intended to be replaced by ALE+ (B69); retained here as master-baseline and installed-hardware evidence.

- Function: ALE accessory with two selectable-voltage MOSFET output channels.
- Sources: [PCB](https://github.com/jrsteensen/OpenHornet/blob/c259a65a1759801a2affea817fd99f6a14f1e1fe/ECAD/PCBs/ABSIS/ABSIS_ALE%20Relay%20Module/ABSIS_ALE%20Relay%20Module.kicad_pc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); [schematic](https://github.com/jrsteensen/OpenHornet/blob/c259a65a1759801a2affea817fd99f6a14f1e1fe/ECAD/PCBs/ABSIS/ABSIS_ALE%20Relay%20Module/ABSIS_ALE%20Relay%20Module.kicad_sc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); [project](https://github.com/jrsteensen/OpenHornet/blob/c259a65a1759801a2affea817fd99f6a14f1e1fe/ECAD/PCBs/ABSIS/ABSIS_ALE%20Relay%20Module/ABSIS_ALE%20Relay%20Module.kicad_pr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).
- Observed PCB revision: `2`; copper layers: F.Cu, B.Cu; thickness: 1.6; 24 embedded footprints.
- Repeated/functional parts: 10k ×6; PinHeader_1x03 ×4; IRLML6402TRPBF ×2; JST_PH_01x02 ×2; IRFB3206PBF ×2; PinSocket_Long_1x06 ×1; PinSocket_Long_2x16 ×1.
- Connector footprint families: PinSocket_1x06_P2.54mm_Vertical ×1; PinSocket_2x16_P2.54mm_Vertical ×1; JST_PH_B2B-PH-K_1x02_P2.00mm_Vertical ×2; PinHeader_1x03_P2.54mm_Vertical ×4.
- Selected rails: /+12V_SUPPLY, /+3.3V_SUPPLY, /+5V_SUPPLY, GND.
- Net classes (clearance/track/via diameter/drill): Default: 0.2/0.25/0.6/0.4.
- Project minima: min_clearance=0; min_track_width=0.2; min_copper_edge_clearance=0.05; min_through_hole_diameter=0.3; DRC exclusion records: 1.
- Actual routed widths: 0.3048, 0.9144, 1.6256; via diameter/drill forms: 1.5/0.8; 0.6/0.4.
- Mechanical footprint evidence: MountingHole_3.2mm_M3_DIN965 ×4.

### B03: ABSIS_ATX Power Supply Unit

- Function: ATX breakout/distribution with standby/control and auxiliary supply ports.
- Sources: [PCB](../../PCBs/ABSIS/ABSIS_ATX%20Power%20Supply%20Unit/ABSIS_ATX%20Power%20Supply%20Unit.kicad_pcb); [schematic](../../PCBs/ABSIS/ABSIS_ATX%20Power%20Supply%20Unit/ABSIS_ATX%20Power%20Supply%20Unit.kicad_sch); [project](../../PCBs/ABSIS/ABSIS_ATX%20Power%20Supply%20Unit/ABSIS_ATX%20Power%20Supply%20Unit.kicad_pro).
- Observed PCB revision: `6`; copper layers: F.Cu, In1.Cu, In2.Cu, B.Cu; thickness: 1.6; 45 embedded footprints.
- Repeated/functional parts: Molex_Mini-Fit_Jr._1x02 ×13; Molex_Mini-Fit_Jr._2x04 ×8; Green ×4; 150 ×3; AMASS_XT60_M ×2; Mini-Fit Jr. 2x03 ×2; Molex_Mini-Fit_Jr._2x12 ×1; AMASS_XT60_F ×1; Molex_Mini-fit_Jr._2x05 ×1.
- Connector footprint families: Molex_Mini-Fit_Jr_5566-24A2_2x12_P4.20mm_Vertical ×1; Molex_Mini-Fit_Jr_5566-08A2_2x04_P4.20mm_Vertical ×8; AMASS_XT60-M_1x02_P7.20mm_Vertical ×2; Molex_Mini-Fit_Jr_5566-02A_2x01_P4.20mm_Vertical ×13; AMASS_XT60-F_1x02_P7.20mm_Vertical ×1; Molex_Mini-Fit_Jr_5566-06A_2x03_P4.20mm_Vertical ×2; Molex_Mini-Fit_Jr_5566-10A2_2x05_P4.20mm_Vertical ×1; PinHeader_1x04_P2.54mm_Vertical ×1.
- Selected rails: /+12V_SUPPLY, /+3.3V_SUPPLY, /+5VSB_SUPPLY, /+5V_SUPPLY, GND.
- Net classes (clearance/track/via diameter/drill): Default: 0.2/0.25/0.8/0.4.
- Project minima: min_clearance=0; min_track_width=0.2; min_copper_edge_clearance=0.025; min_through_hole_diameter=0.3; DRC exclusion records: 0.
- Actual routed widths: 0.25; via diameter/drill forms: none.
- Mechanical footprint evidence: MountingHole_6-32_PHS ×4.

### B04: ABSIS_Backlight Controller

- Function: Mega-based ten-channel backlight distribution/control and fan/temperature interfaces.
- Sources: [PCB](../../PCBs/ABSIS/ABSIS_Backlight%20Controller/ABSIS_Backlight%20Controller.kicad_pcb); [schematic](../../PCBs/ABSIS/ABSIS_Backlight%20Controller/ABSIS_Backlight%20Controller.kicad_sch); [project](../../PCBs/ABSIS/ABSIS_Backlight%20Controller/ABSIS_Backlight%20Controller.kicad_pro).
- Observed PCB revision: `7`; copper layers: F.Cu, B.Cu; thickness: 1.6; 46 embedded footprints.
- Repeated/functional parts: TestPoint ×13; Mini-Fit Jr. 2x02 ×10; PinHeader_1x08 ×5; Green ×2; 2.2K ×2; KK-254 1x04 ×2; Molex_Mini-fit_Jr._2x05 ×1; 4.7K ×1; LM75AD,118 ×1.
- Connector footprint families: Molex_Mini-Fit_Jr_5566-10A2_2x05_P4.20mm_Vertical ×1; Molex_Mini-Fit_Jr_5566-04A_2x02_P4.20mm_Vertical ×10; Molex_KK-254_AE-6410-04A_1x04_P2.54mm_Vertical ×2; PinHeader_1x03_P2.54mm_Vertical ×1; Molex_KK-254_AE-6410-05A_1x05_P2.54mm_Vertical ×1; PinHeader_2x18_P2.54mm_Vertical ×1; PinHeader_1x08_P2.54mm_Vertical ×5; PinHeader_1x10_P2.54mm_Vertical ×1.
- Selected rails: +3.3V, +5V, +5VD, /+12V_SUPPLY, /+5V_SUPPLY, GND.
- Net classes (clearance/track/via diameter/drill): Default: 0.2/0.25/0.6/0.4.
- Project minima: min_clearance=0; min_track_width=0.2; min_copper_edge_clearance=0.075; min_through_hole_diameter=0.3; DRC exclusion records: 2.
- Actual routed widths: 0.25, 0.4572, 0.9144, 1.2192; via diameter/drill forms: 0.6/0.4.
- Mechanical footprint evidence: MountingHole_3.2mm_M3_DIN965 ×3.

### B05: ABSIS_Bus_Master

- Function: Mega shield with three independent RS-485 channels.
- Sources: [PCB](../../PCBs/ABSIS/ABSIS_Bus_Master/ABSIS_Bus_Master.kicad_pcb); [schematic](../../PCBs/ABSIS/ABSIS_Bus_Master/ABSIS_Bus_Master.kicad_sch); [project](../../PCBs/ABSIS/ABSIS_Bus_Master/ABSIS_Bus_Master.kicad_pro).
- Observed PCB revision: `6.0.0`; copper layers: F.Cu, In1.Cu, In2.Cu, B.Cu; thickness: 1.6; 56 embedded footprints.
- Repeated/functional parts: 10kΩ ×6; 10Ω ×6; Mini-Fit Jr. 2x03 ×3; TP-B1B ×3; THVD1410DR ×3; 0.1uF ×3; TP-B1A ×3; CDSOT23-SM712 ×3; 120Ω ×3.
- Connector footprint families: Molex_Mini-Fit_Jr_5566-08A2_2x04_P4.20mm_Vertical ×1; Molex_Mini-Fit_Jr_5566-06A2_2x03_P4.20mm_Vertical ×3; PinHeader_2x18_P2.54mm_Vertical ×1; PinHeader_1x08_P2.54mm_Vertical ×5; PinHeader_1x10_P2.54mm_Vertical ×1.
- Selected rails: +3V3, +5V, +5VD, /+12V_SUPPLY, /+3.3V_SUPPLY, /+5V_SUPPLY, GND.
- Net classes (clearance/track/via diameter/drill): Default: 0.2/0.25/0.6/0.3.
- Project minima: min_clearance=0; min_track_width=0.2; min_copper_edge_clearance=0.075; min_through_hole_diameter=0.3; DRC exclusion records: 0.
- Actual routed widths: 0.3048, 0.4572, 0.635, 0.9144, 1.2192, 1.6256; via diameter/drill forms: 0.6/0.3.
- Mechanical footprint evidence: MountingHole_3.2mm_M3_DIN965 ×4.

### B06: ABSIS_Bus_Master (legacy)

- Function: Mega shield with three independent RS-485 channels.
- Sources: [PCB](../../PCBs/ABSIS/ABSIS_Bus_Master/legacy/ABSIS_Bus_Master.kicad_pcb); [schematic](../../PCBs/ABSIS/ABSIS_Bus_Master/legacy/ABSIS_Bus_Master.kicad_sch); [project](../../PCBs/ABSIS/ABSIS_Bus_Master/legacy/ABSIS_Bus_Master.kicad_pro).
- Observed PCB revision: `5.0.0`; copper layers: F.Cu, B.Cu; thickness: 1.6; 40 embedded footprints.
- Repeated/functional parts: MAX487EESA+T ×3; 120 ×3; 0.1uF ×3; Mini-Fit Jr. 2x03 ×3; Analog ×2; PWM ×2; TP-12 ×1; TP-5V ×1; TP-3.3V ×1.
- Connector footprint families: Molex_Mini-Fit_Jr_5566-08A2_2x04_P4.20mm_Vertical ×1; Molex_Mini-Fit_Jr_5566-06A2_2x03_P4.20mm_Vertical ×3; PinHeader_2x11_P2.54mm_Vertical ×1; PinHeader_2x18_P2.54mm_Vertical ×1; PinHeader_1x08_P2.54mm_Vertical ×5; PinHeader_1x10_P2.54mm_Vertical ×1.
- Selected rails: +3V3, +5V, +5VD, /+12V_SUPPLY, /+3.3V_SUPPLY, /+5V_SUPPLY, GND.
- Net classes (clearance/track/via diameter/drill): Default: 0.2/0.25/0.6/0.4.
- Project minima: min_clearance=0; min_track_width=0.2; min_copper_edge_clearance=0.075; min_through_hole_diameter=0.3; DRC exclusion records: 4.
- Actual routed widths: 0.3048, 0.4572, 0.635, 0.9144, 1.2192, 1.6256; via diameter/drill forms: 0.6/0.4.
- Mechanical footprint evidence: MountingHole_3.2mm_M3_DIN965 ×4.

### B07: ABSIS_HID Bus Master

- Function: Pro Micro USB/HID to one terminated RS-485 channel.
- Sources: [PCB](https://github.com/jrsteensen/OpenHornet/blob/c259a65a1759801a2affea817fd99f6a14f1e1fe/ECAD/PCBs/ABSIS/ABSIS_HID%20Bus%20Master/ABSIS_HID%20Bus%20Master.kicad_pcb); [schematic](https://github.com/jrsteensen/OpenHornet/blob/c259a65a1759801a2affea817fd99f6a14f1e1fe/ECAD/PCBs/ABSIS/ABSIS_HID%20Bus%20Master/ABSIS_HID%20Bus%20Master.kicad_sch); [project](https://github.com/jrsteensen/OpenHornet/blob/c259a65a1759801a2affea817fd99f6a14f1e1fe/ECAD/PCBs/ABSIS/ABSIS_HID%20Bus%20Master/ABSIS_HID%20Bus%20Master.kicad_pro).
- Observed PCB revision: `4`; copper layers: F.Cu, B.Cu; thickness: 1.6; 20 embedded footprints.
- Repeated/functional parts: TestPoint ×6; MAX487EESA+T ×1; 120 ×1; 0.1uF ×1; Molex_Mini-Fit_Jr._2x04 ×1; Mini-Fit Jr. 2x03 ×1; ProMicro_5V/16Hz ×1; 1N5819WS ×1.
- Connector footprint families: Molex_Mini-Fit_Jr_5566-08A2_2x04_P4.20mm_Vertical ×1; Molex_Mini-Fit_Jr_5566-06A2_2x03_P4.20mm_Vertical ×1.
- Selected rails: +5V, /+12V_SUPPLY, /+3.3V_SUPPLY, /+5V_SUPPLY, GND.
- Net classes (clearance/track/via diameter/drill): Default: 0.2/0.25/0.6/0.4.
- Project minima: min_clearance=0; min_track_width=0.2; min_copper_edge_clearance=0.075; min_through_hole_diameter=0.3; DRC exclusion records: 0.
- Actual routed widths: 0.4572, 0.635, 0.9144, 1.2192, 1.6256; via diameter/drill forms: 0.6/0.4.
- Mechanical footprint evidence: MountingHole_3.2mm_M3_DIN965 ×4.

### B08: ABSIS_Hall Sensor

- Function: MT6835GT magnetic-angle sensor, SPI connection.
- Sources: [PCB](../../PCBs/ABSIS/ABSIS_Hall%20Sensor/ABSIS_Hall%20Sensor.kicad_pcb); [schematic](../../PCBs/ABSIS/ABSIS_Hall%20Sensor/ABSIS_Hall%20Sensor.kicad_sch); [project](../../PCBs/ABSIS/ABSIS_Hall%20Sensor/ABSIS_Hall%20Sensor.kicad_pro).
- Observed PCB revision: `4`; copper layers: F.Cu, B.Cu; thickness: 1.6; 8 embedded footprints.
- Repeated/functional parts: 0.1uF ×1; ESD5Z5V0 ×1; MT6835GT ×1; JST_PH_01x06 ×1.
- Connector footprint families: JST_PH_S6B-PH-K_1x06_P2.00mm_Horizontal ×1.
- Selected rails: GND, VDD.
- Net classes (clearance/track/via diameter/drill): Default: 0.2/0.25/0.8/0.4; +5V: 0.2/0.75/1.5/0.75; GND: 0.2/0.5/0.8/0.4.
- Project minima: min_clearance=0.127; min_track_width=0.2; min_copper_edge_clearance=0.5; min_through_hole_diameter=0.3; DRC exclusion records: 9.
- Actual routed widths: 0.25, 0.3048, 0.6096; via diameter/drill forms: 0.8/0.4.
- Mechanical footprint evidence: MountingHole_2.5mm ×4.

### B09: ABSIS_MPC

- Function: Incomplete project; intended function not established from empty PCB.
- Sources: [PCB](https://github.com/jrsteensen/OpenHornet/blob/c259a65a1759801a2affea817fd99f6a14f1e1fe/ECAD/PCBs/ABSIS/ABSIS_MPC/ABSIS_MPC.kicad_pcb); [schematic](https://github.com/jrsteensen/OpenHornet/blob/c259a65a1759801a2affea817fd99f6a14f1e1fe/ECAD/PCBs/ABSIS/ABSIS_MPC/ABSIS_MPC.kicad_sch); [project](https://github.com/jrsteensen/OpenHornet/blob/c259a65a1759801a2affea817fd99f6a14f1e1fe/ECAD/PCBs/ABSIS/ABSIS_MPC/ABSIS_MPC.kicad_pro).
- Observed PCB revision: `not stated`; copper layers: F.Cu, B.Cu; thickness: 1.6; 0 embedded footprints.
- Repeated/functional parts: .
- Connector footprint families: none placed.
- Selected rails: none resolved from placed pads.
- Net classes (clearance/track/via diameter/drill): Default: 0.2/0.305/0.6/0.4; +5V: 0.2/0.457/0.6/0.4.
- Project minima: min_clearance=0.127; min_track_width=0.127; min_copper_edge_clearance=0.75; min_through_hole_diameter=0.3; DRC exclusion records: 0.
- Actual routed widths: none; via diameter/drill forms: none.
- Mechanical footprint evidence: inspect outline and assembly; no named mounting/keepout footprint.

### B10: ABSIS_Mega

- Function: Mega I/O node with RS-485 in/out and enable jumper.
- Sources: [PCB](../../PCBs/ABSIS/ABSIS_Mega/ABSIS_Mega.kicad_pcb); [schematic](../../PCBs/ABSIS/ABSIS_Mega/ABSIS_Mega.kicad_sch); [project](../../PCBs/ABSIS/ABSIS_Mega/ABSIS_Mega.kicad_pro).
- Observed PCB revision: `3.0.0`; copper layers: F.Cu, B.Cu; thickness: 1.6; 36 embedded footprints.
- Repeated/functional parts: TestPoint ×6; PinHeader_1x08 ×5; PinHeader_2x10 ×3; Mini-Fit Jr. 2x03 ×2; 10kΩ ×2; 10Ω ×2; PinHeader_2x02 ×1; PinHeader_2x11 ×1; PinHeader_1x02 ×1.
- Connector footprint families: PinHeader_2x10_P2.54mm_Vertical ×3; PinHeader_2x02_P2.54mm_Vertical ×1; Molex_Mini-Fit_Jr_5569-06A1_2x03_P4.20mm_Horizontal ×2; PinHeader_2x11_P2.54mm_Vertical ×1; PinHeader_1x02_P2.54mm_Vertical ×1; PinHeader_2x18_P2.54mm_Vertical ×1; PinHeader_1x08_P2.54mm_Vertical ×5; PinHeader_1x10_P2.54mm_Vertical ×1.
- Selected rails: +3.3V, +5V, +5VD, /+12V_SUPPLY, /+3.3V_SUPPLY, /+5V_SUPPLY, /BUS-ENABLE, GND.
- Net classes (clearance/track/via diameter/drill): Default: 0.2/0.25/0.6/0.3.
- Project minima: min_clearance=0; min_track_width=0.2; min_copper_edge_clearance=0.075; min_through_hole_diameter=0.3; DRC exclusion records: 0.
- Actual routed widths: 0.25, 0.3048, 0.4572, 0.635, 0.9144, 1.6256; via diameter/drill forms: 0.6/0.3.
- Mechanical footprint evidence: MountingHole_3.2mm_M3_DIN965 ×4.
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

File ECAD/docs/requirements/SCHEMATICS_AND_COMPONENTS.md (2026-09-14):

# Schematics, components and library integrity

## Basis

Recurring implementations use project and standard KiCad libraries, `Manufacturer PN` and `LCSC` fields, Arduino module symbols, WS2812 variants, and connector metadata. DDI/AMPCD manufacturing instructions explicitly distinguish `PCA9554PWR` from unspecified PCA9554 packages. New verification rules below are **adopted project policy under PR #1255**, based on electrical engineering practice and the mapping/documentation inconsistencies in [the inventory](../reference/ARCHITECTURE_INVENTORY.md).

## Schematic requirements

- **SCH-001:** A board's schematic or linked design record MUST state function, interfaces, rail sources, expected loads, assembly variants, critical mechanical constraints, operating assumptions and applicable requirement IDs. Placeholder notes such as `1) XXXX` MUST NOT count as requirements definition.
- **SCH-002:** Label connections with unambiguous net names and signal direction where meaningful. Explicitly document power-domain relationships, active-low signals, open-drain buses, analog references, no-connects and externally supplied power. `PWR_FLAG` MUST represent an actual source, not conceal a missing supply.
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

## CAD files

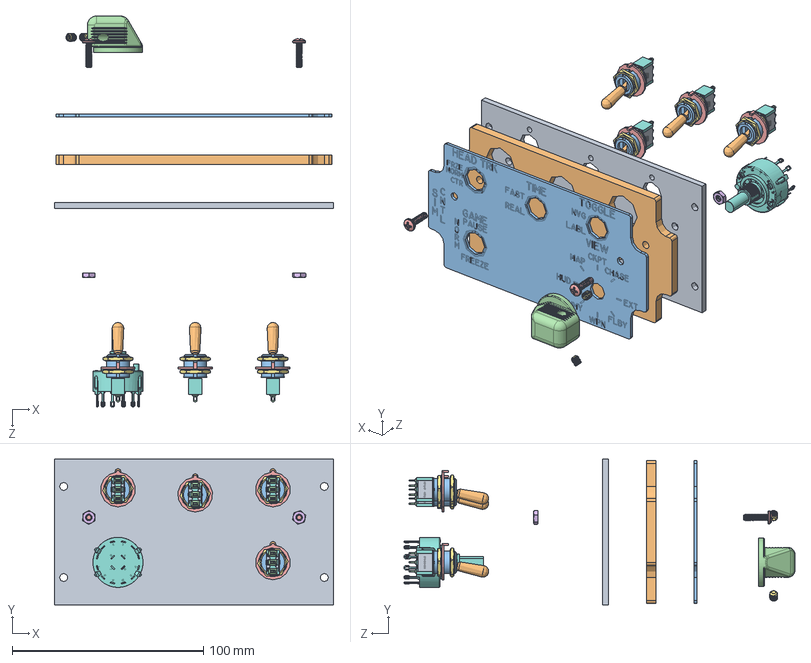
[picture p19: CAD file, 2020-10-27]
MCAD/SIM CNTL Panel.sldasm
146.1 x 76.2 x 204.5 mm
SIM CNTL Panel Backplate
SIM CNTL Panel Lightplate
SIM CNTL Panel Legend Plate
MS21384-04DNN v1
91249A148 - PHS, 6-32 X .500, 18-8, BLACK-OXIDE x 2
90760A007 - NUT, 6-32, JAM, STEEL, ZINC-PLATED x 2
92311A189 - SCREW, SET, 8-32 X .1875, CUP POINT, HEX DRIVE, 18-8 x 2
100-300SPXBODY x 4
100SPXBRACKET_1 x 4
100T8 x 4
100B13BUSHING x 4
100-300SPXM1 x 4
HDW17 - LOCKING RING, B13 x 4
HDW12 - LOCK WASHER, B13 x 4
HDW4 - NUT, B13 x 8
A12505RNZQ - SWITCH, ROTARY, 45 DEG, 8 POS, FIXED

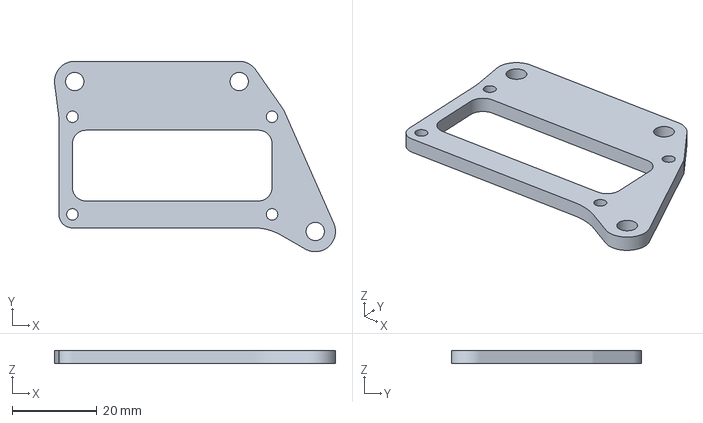
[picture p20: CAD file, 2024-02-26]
release/OH5_Right_Console/OH5A6A1 - ASSY, INTR LT PANEL/Manufacturing/FDM_OH5A6A1-100_ASSY, INTR LT ABSIS MODULE_-_V1.3MF
66.2 x 44.8 x 3.17 mm

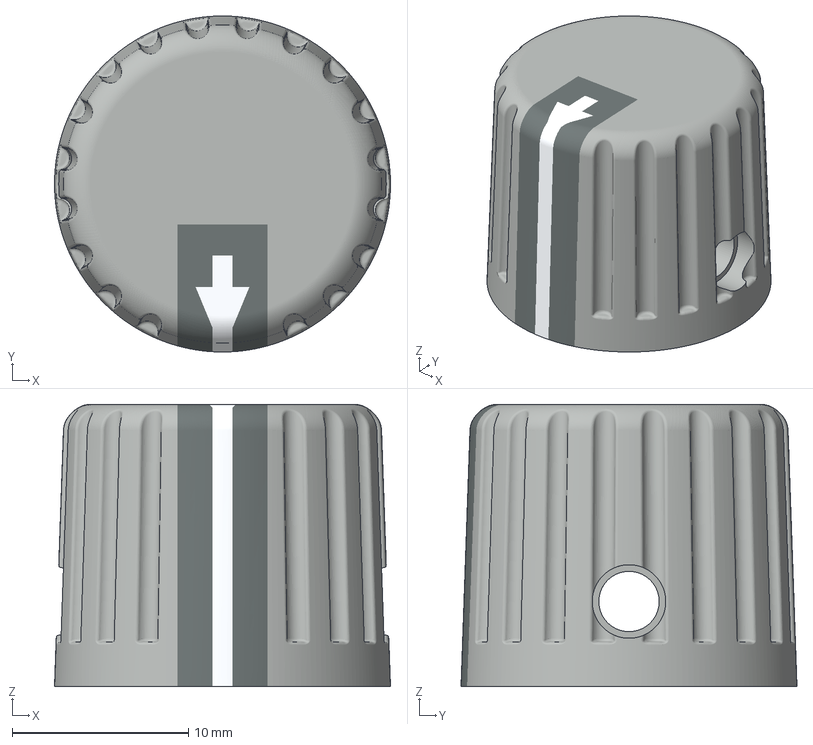
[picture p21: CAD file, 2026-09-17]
release/OHC_Common_Parts/OHC0003 - ASSY, KNOBS/manufacturing/RESN_OHC0003-287AGB4_ASSY, KNOB, GREY, .25 D-SHAFT_-_V4.3mf
19.0 x 19.0 x 16.0 mm

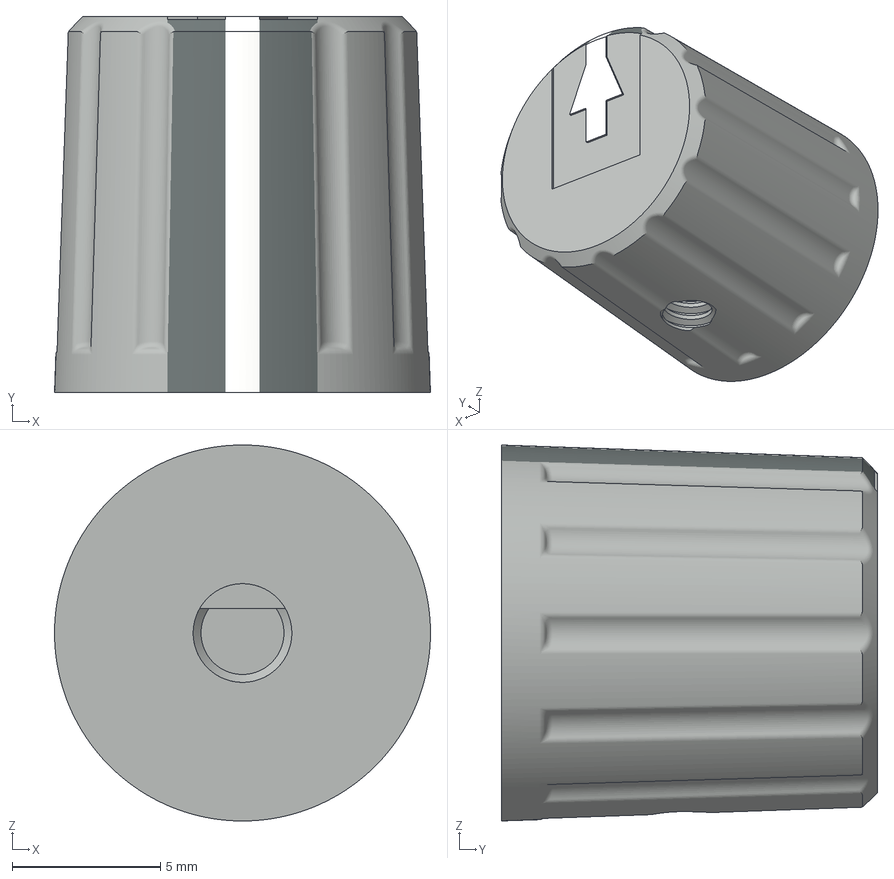
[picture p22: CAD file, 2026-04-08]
release/OHM_Modifications/OH2A3A1 - AMPCD Modifications/OHC0003-412FGB2 - ASSY, KNOB, GREY, .125 RECESSED D-SHAFT (thread modelled)_MOD_A.3mf
12.7 x 12.7 x 12.7 mm

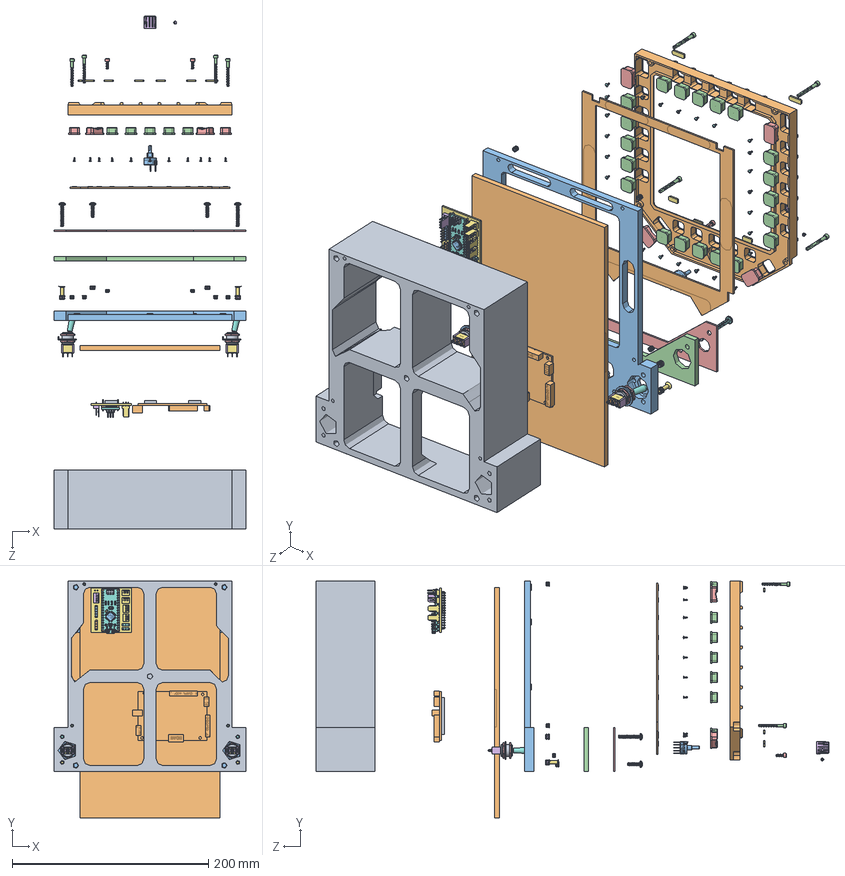
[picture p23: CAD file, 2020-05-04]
MCAD/AMPCD-HDG-CRS Module.sldasm
195.3 x 241.4 x 522.5 mm
AMPCD - CRS-HDG Base Support
ER-TFTV101A1-1_Display
HDG-CRS Set Spacer
HDG-CRS Set Spacer Lightplate
HDG-CRS Set Spacer Legend Plate
100-300SPXBODY x 2
100SPXBRACKET_1 x 2
100T8 x 2
100B13BUSHING x 2
100-300SPXM1 x 2
HDW17 - LOCKING RING, B13 x 2
HDW12 - LOCK WASHER, B13 x 2
HDW4 - NUT, B13 x 4
93365A130 - INSERT, 6-32, BRASS, FOR PLASTICS x 6
90471A220 - FHS, 100 CSK, 6-32 X .500, STEEL, ZINC x 2
91249A156 - PHS, 6-32 X .8750, 18-8, BLACK-OXIDE x 2
91249A148 - PHS, 6-32 X .500, 18-8, BLACK-OXIDE x 2
AMPCD Bezel
39SB-1RB-103 - POT, 10K LINEAR, .125 SHAFT, DETENT SWITCH
AMPCD Button x 20
AMPCD Rocker x 4
AMPCD MS21382-0XNX (Modified)
AMPCD Legend Plate x 7
99461A505 - PHS, 0-42 X .125, SELF TAPPING, 18-8 x 28
GX06400 - SWITCH, DOME, SNAPTRON, 6.3mm DIA, 400gf x 28
AMPCD PCB
93365A120_BRASS HEAT-SET INSERT FOR PLASTICS_4-40 x 6
91251A115 - SHCS, 4-40 X 1.000, STEEL, BLACK OXIDE x 4
91251A107 - SHCS, 4-40 x .3215, STEEL, BLACK-OXIDE x 2
92311A102 - SCREW, SET, 4-40 X .093, CUP POINT, HEX DRIVE, 18-8
DDI Shield PCB
nano-board
2pin_header__02 x 3
15pin_header__ x 2
atmega328
ftdi FT232rl
smt_resistor222 x 5
led x 4
16mhz crystal - measured
MINIUSBSHELL
MINIUSBCORE
MINI USB CONTACT x 5
cap106C x 2
reset core
reset shell
nano - reg
NANO DIODE
189 RESISTOR PACK
102 RESISTOR PACK
7598A71 - TAPE, LIGHT DUTY, DOUBLE SIDED, FOAM x 2
ER-TFTV101A1-1_HDMI_Controller_PCB

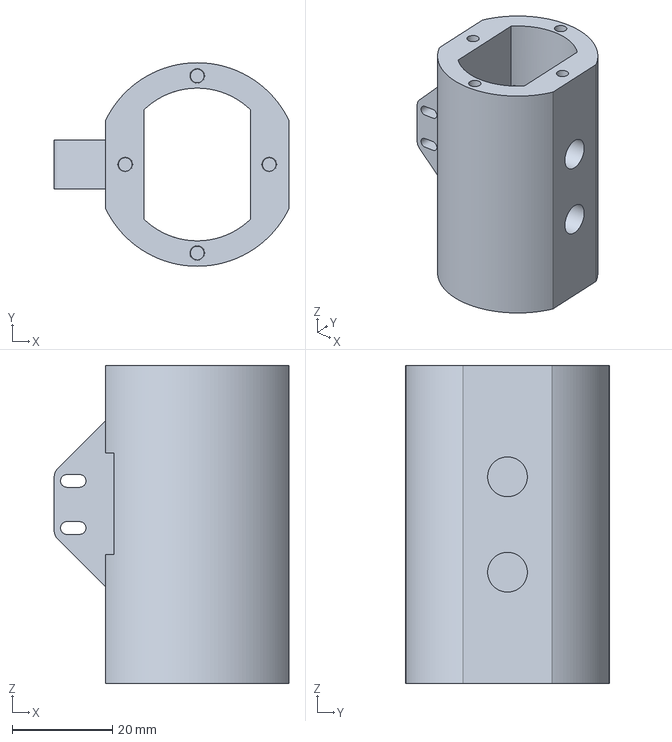
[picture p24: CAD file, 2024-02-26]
release/OH5_Right_Console/OH5A2A2 - ASSY, WING FOLD HANDLE/Manufacturing/FDM_OH5A2A2-16_WING FOLD MAIN BODY_-_V17.3mf
46.9 x 40.6 x 63.5 mm

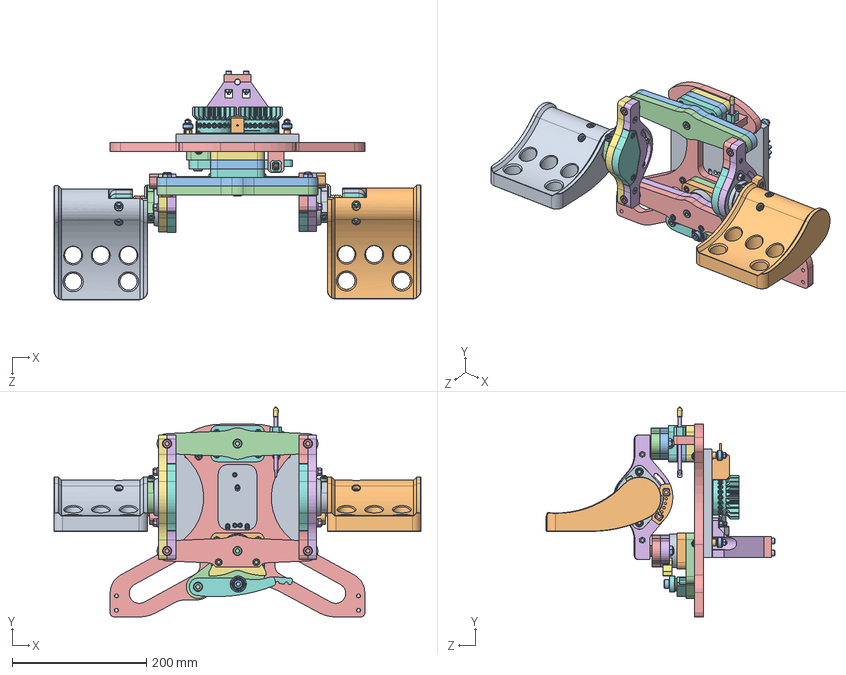
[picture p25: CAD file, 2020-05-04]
MCAD/Rudder Pedal Gantry Carriage.sldasm
547.3 x 313.1 x 340.9 mm
Rudder Pedal Gantry Interface Plate
819368021615 - Aluminum Spacer 6mm x 2
Delrin Mini V Wheel x 4
Ball Bearing 5 x 10 x 4.2 x 10
Precision Shim 8 x 5 x 1 x 8
Nylon Insert Lock Nut M5 x 4
819368021011 - Eccentric Spacer 6mm x 2
GEAR, 3M x 20T x 20PA x 5mm Bore x 2
Rudder Pedal Gantry Locking Arm
B14HDP-254-B-4
1692K230 - SPRING, COMPRESSION, CONFINED SPACE, .60 OD x .625L x 3.57lbs RATE
Rudder Pedal Gantry Locking Arm Spring Stop
Rudder Carriage Linear Bearing Holder Lower Shell
Rudder Carriage Linear Bearing Holder Upper Shell
LM8UU v2
93625A200 - NUT, M5-0.8, NYLOC, 18-8 x 11
93705A838 - SHCS, M5-0.8 x 30mm, SELF-LOCKING, 18-8 x 15
90126A029 - WASHER, .25 x .625, STEEL, ZINC x 7
91251A146 - SHCS, 6-32 X .375, STEEL, BLACK-OXIDE x 7
93365A130 - INSERT, 6-32, BRASS, FOR PLASTICS x 5
MFG CW Base Adj Block
MFG CW Base Pivot Aft
MFG CW Base Pivot Fwd
MFG CW Base Riser Block Aft 3
MFG CW Base Riser Cylinder Fwd
MFG CW Base Riser Block Fwd 2
MFG CW Base Riser Block Aft 2
MFG CW Base Rise Block Fwd 1
MFG CW Base Plate
M6 x 1 Hex Nut x 23
MFG CW Base Riser Block Aft 1
628Z 8x24x8mm Ball Bearing x 10
M6 x 1 mm 45 mm Length Socket Head Screw x 4
M6 x 1 mm 30 mm Length Socket Head Screw x 8
MFG CW Aft Linkage Lower
MFG CW Aft Linkage Upper
MFG CW Fwd Linkage Upper
MFG CW Fwd Linkage Lower
MFG CW Cam Standin
MFG CW Pressure Arm
M8 x 1.25 Hex Nut x 2
8.4mm ID 16mm OD Flat Washer x 11
M8 x 1.5 mm 25 mm Length Socket Head Screw
M8 x 1.5 mm 30 mm Length Socket Head Screw v1 x 3
MFG CW Right Brake Limiter
MFG CW Right Linkage Inbd
MFG CW Right Linkage Otbd
MFG CW Linkage Inbd Cap x 2
PFL205 x 4
M5 x 0.8 Hex Nut x 4
M5 x 0.8 25 mm Length Hex Drive Flat Head Screw x 4
M6 x 1 mm 25 mm Length Socket Head Screw x 8
6.4 mm ID 12 mm OD Flat Washer x 4
M6 x 1 Lock Nut x 4
M6 x 1 Lock Nut_2 x 4
MFG CW Pedal Mount Block Upper x 2
MFG CW Pedal Mount Block Lower x 2
MFG CW Right Brake Spring
MFG CW Right Brake Ring_2
MFG CW Right Brake Ring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

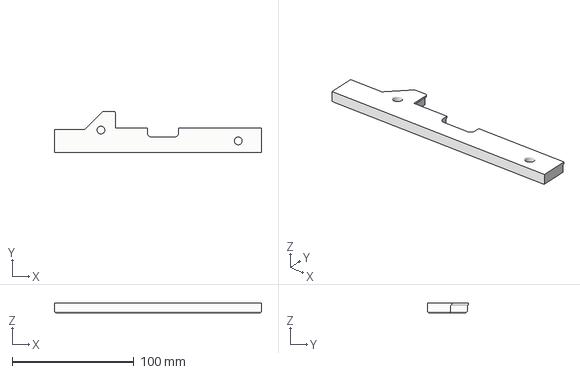
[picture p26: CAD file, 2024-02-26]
release/OHT_Tools_and_Jigs/OH-TOOL-003-10 - MAIN LIGHTPLATE JIG_-_v5.3mf
169.7 x 33.7 x 8.00 mm

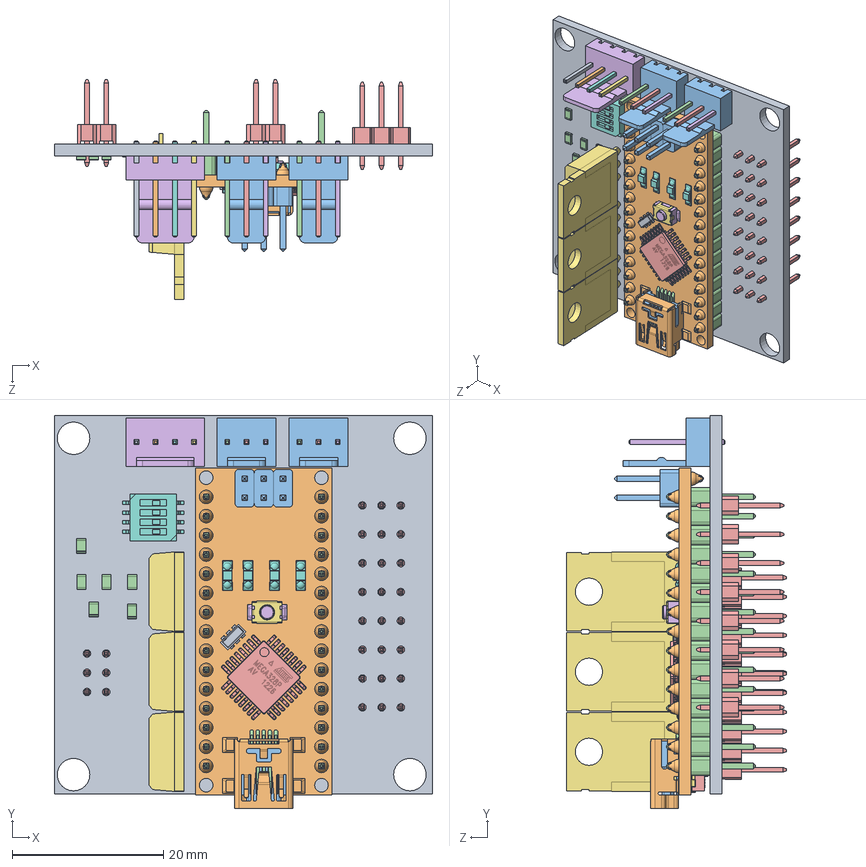
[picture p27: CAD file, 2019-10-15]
ECAD/PCBs/ABSIS/NANO_IO/SW/NANO_IO.SLDASM
50.0 x 51.9 x 29.1 mm
ABSIS NANO Rev B PCB
nano-board
2pin_header__02 x 3
15pin_header__ x 2
atmega328
ftdi FT232rl
smt_resistor222 x 5
led x 4
16mhz crystal - measured
MINIUSBSHELL
MINIUSBCORE
MINI USB CONTACT x 5
cap106C x 2
reset core
reset shell
nano - reg
NANO DIODE
189 RESISTOR PACK
102 RESISTOR PACK
HEADER, PIN, .1 SPACING x 10
Pluggable Pin Header 4-way_3
Pluggable Pin Header 4-way_4
Pluggable Pin Header 4-way_5
Pluggable Pin Header 4-way
Pluggable Pin Header 4-way_2
Pluggable Pin Header 3-way_3 x 2
Pluggable Pin Header 3-way x 2
Pluggable Pin Header 3-way_2 x 2
Pluggable Pin Header 3-way_4 x 2
TO-220-3_Vertical x 3
A6HF-4102
MAX487EESA+

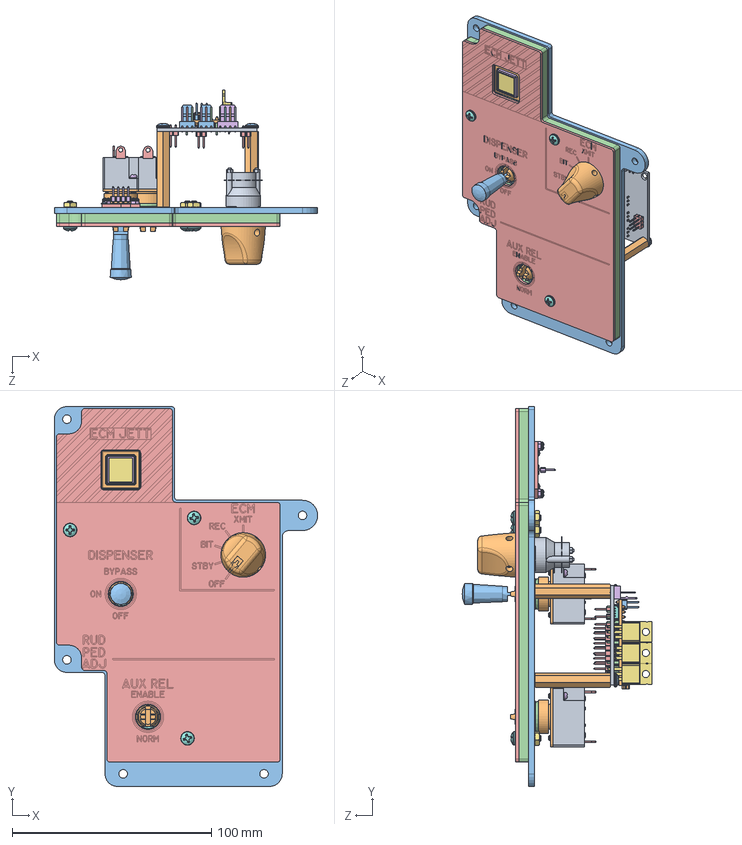
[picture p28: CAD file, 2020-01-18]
MCAD/DISP - EMC Panel.sldasm
132.1 x 190.5 x 95.1 mm
S2AL_SMC_body1-body x 2
S2AL_SMC_plate13 x 2
S2AL_S2AL_bat
S2AL_AT537 x 2
S2AL_SMC_trmnls2-terminals x 2
S2AL_M2_5x7_5 x 4
S2AL_AT508 x 2
S2AL_AT503M x 2
71b36-01-2-05n
MS21385 - 03C.f3d v2
DISP-EMC Panel Backplate
DISP-EMC Panel Lightplate
DISP-EMC Panel Legendplate
.55 SQ Indicator Bezel
.55 SQ Indicator Legend Cover
.55 SQ Indicator Legend
.55 SQ Indicator Actuator
.55 SQ Indicator Base
99461A505 - PHS, 0-42 X .125, SELF TAPPING, 18-8 x 3
GX06400 - SWITCH, DOME, SNAPTRON, 6.3mm DIA, 400gf
.55 SQ Indicator PCB
header SMD 2,54mm x 4
90760A007 - NUT, 6-32, JAM, STEEL, ZINC-PLATED x 3
91249A148 - PHS, 6-32 X .500, 18-8, BLACK-OXIDE x 3
ABSIS NANO Rev B PCB
nano-board
2pin_header__02 x 3
15pin_header__ x 2
atmega328
ftdi FT232rl
smt_resistor222 x 5
led x 4
16mhz crystal - measured
MINIUSBSHELL
MINIUSBCORE
MINI USB CONTACT x 5
cap106C x 2
reset core
reset shell
nano - reg
NANO DIODE
189 RESISTOR PACK
102 RESISTOR PACK
HEADER, PIN, .1 SPACING x 10
Pluggable Pin Header 4-way_3
Pluggable Pin Header 4-way_4
Pluggable Pin Header 4-way_5
Pluggable Pin Header 4-way
Pluggable Pin Header 4-way_2
Pluggable Pin Header 3-way_3 x 2
Pluggable Pin Header 3-way x 2
Pluggable Pin Header 3-way_2 x 2
Pluggable Pin Header 3-way_4 x 2
TO-220-3_Vertical x 3
A6HF-4102
MAX487EESA+
91780A337 - STANDOFF, HEX, FEMALE, 6-32 X 1.50L X .25 HEX, ALUM x 2
90272A144 - PHS, 6-32 X .250, STEEL x 2
90471A210 - FHS, 100DEG, 6-32 X .3125, STEEL, ZINC-PLATED x 2
92311A189 - SCREW, SET, 8-32 X .1875, CUP POINT, HEX DRIVE, 18-8 x 2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

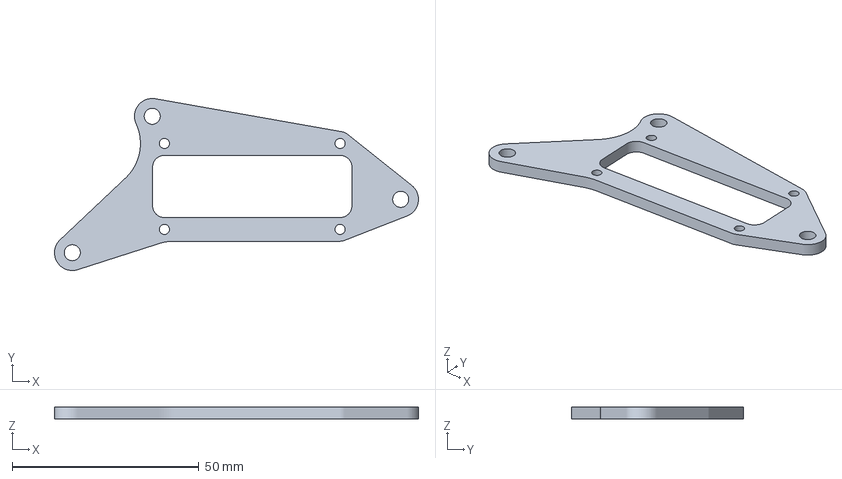
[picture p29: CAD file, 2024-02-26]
release/OH5_Right_Console/OH5A4A1 - ASSY, ELEC PANEL/Manufacturing/FDM_OH5A4A1-200_ASSY, ELEC PANEL ELECTRONICS TRAY_-_V1.3MF
97.4 x 46.0 x 3.17 mm

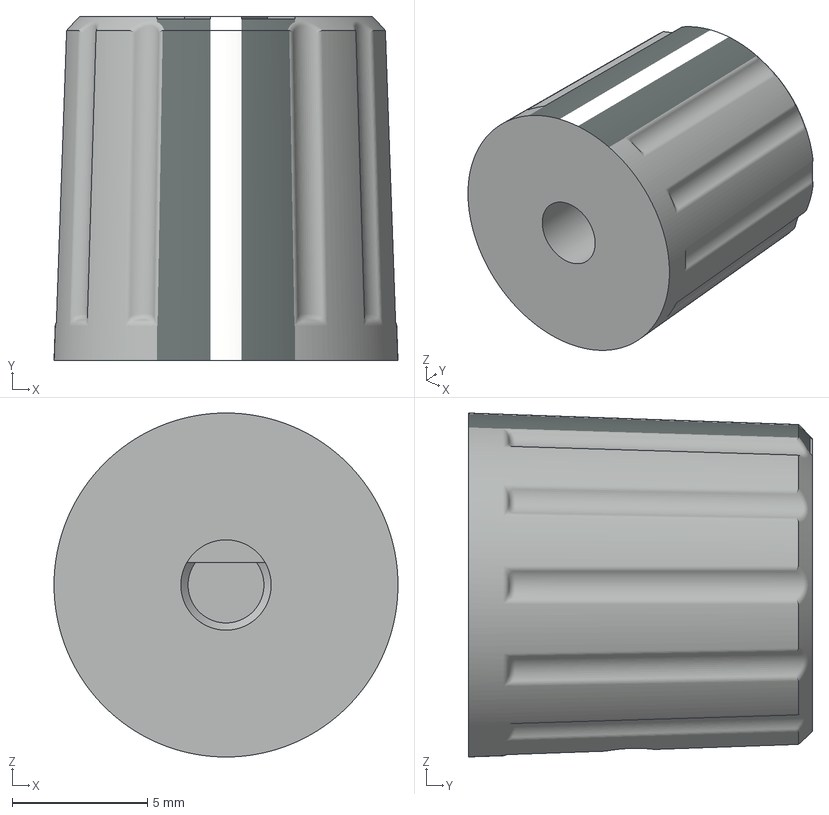
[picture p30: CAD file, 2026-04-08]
release/OHM_Modifications/OH2A3A1 - AMPCD Modifications/OHC0003-412FGB2 - ASSY, KNOB, GREY, .125 RECESSED D-SHAFT_MOD_A.3mf
12.7 x 12.7 x 12.7 mm

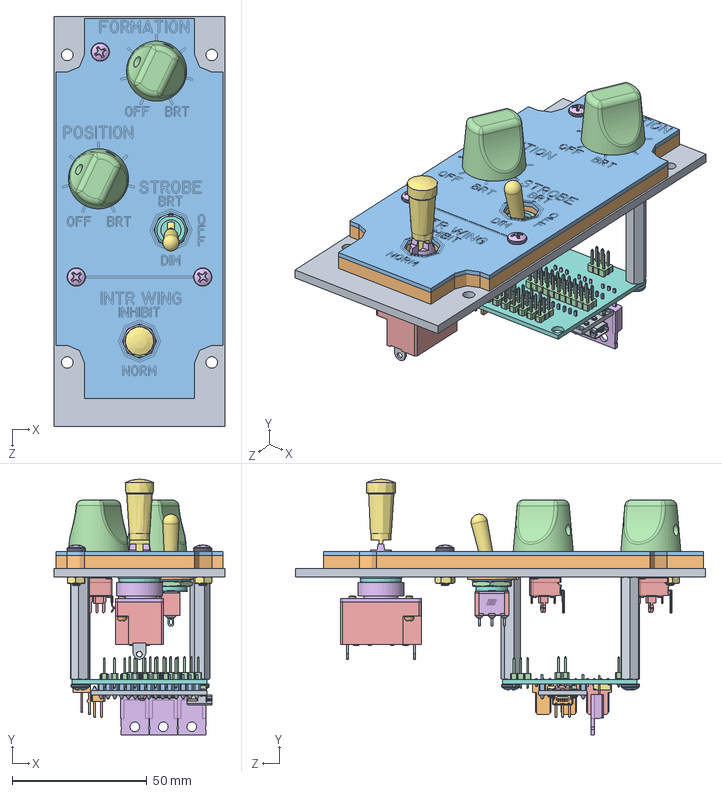
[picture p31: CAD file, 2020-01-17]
MCAD/EXT LT Panel.SLDASM
63.5 x 95.1 x 152.4 mm
EXT LT Backplate
EXT LT Lightplate
EXT LT Legend Plate
MS21385-04CNN v1 x 2
S2AL_SMC_body1-body
S2AL_SMC_plate13
S2AL_S2AL_bat
S2AL_AT537
S2AL_SMC_trmnls2-terminals
S2AL_M2_5x7_5 x 2
S2AL_AT508
S2AL_AT503M
100-300SPXBODY
100SPXBRACKET_1
100T8
100B13BUSHING
100-300SPXM1
HDW17 - LOCKING RING, B13
HDW12 - LOCK WASHER, B13
HDW4 - NUT, B13 x 2
P0915N-FC20BR10K x 2
91249A148 - PHS, 6-32 X .500, 18-8, BLACK-OXIDE x 3
90760A007 - NUT, 6-32, JAM, STEEL, ZINC-PLATED x 3
ABSIS NANO Rev B PCB
nano-board
2pin_header__02 x 3
15pin_header__ x 2
atmega328
ftdi FT232rl
smt_resistor222 x 5
led x 4
16mhz crystal - measured
MINIUSBSHELL
MINIUSBCORE
MINI USB CONTACT x 5
cap106C x 2
reset core
reset shell
nano - reg
NANO DIODE
189 RESISTOR PACK
102 RESISTOR PACK
HEADER, PIN, .1 SPACING x 10
Pluggable Pin Header 4-way_3
Pluggable Pin Header 4-way_4
Pluggable Pin Header 4-way_5
Pluggable Pin Header 4-way
Pluggable Pin Header 4-way_2
Pluggable Pin Header 3-way_3 x 2
Pluggable Pin Header 3-way x 2
Pluggable Pin Header 3-way_2 x 2
Pluggable Pin Header 3-way_4 x 2
TO-220-3_Vertical x 3
A6HF-4102
MAX487EESA+
91780A337 - STANDOFF, HEX, FEMALE, 6-32 X 1.50L X .25 HEX, ALUM x 3
90471A210 - FHS, 100DEG, 6-32 X .3125, STEEL, ZINC-PLATED x 3
90272A144 - PHS, 6-32 X .250, STEEL x 3

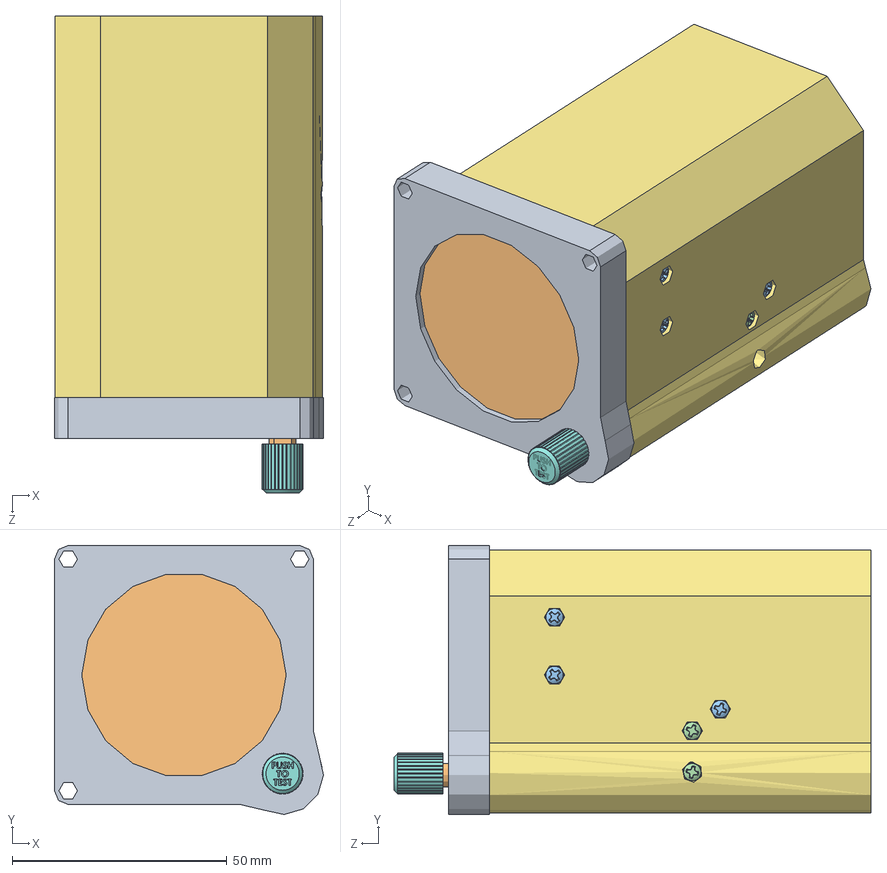
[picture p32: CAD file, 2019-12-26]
MCAD/Radar Altimeter.SLDASM
62.7 x 62.7 x 111.1 mm
Radar Altimeter Bezel
Airspeed Indicator Cover Glass
Radar Altimeter Needle Mask
Radar Altimeter Dial Face
Radar Altimeter Stepper Mount
Radar Altimeter Stepper Standoff
Radar Altimeter Case
Radar Altimeter Indicator Pointer
VID29-02
MD-80PL100
MD-40PL100
SMB 200 RTP
LTW-420D7 x 2
SMB 200 GTP
Radar Altimeter Limit Indexer Ring
Radar Altimeter Knob
Radar Altimeter Limit Shaft Gear
634070_SERVOCITY_.250 X 2.250 D-SHAFT
6630S0D-C28-A103
615242_Gear Blank x 2
632134_91375A436 x 2
1692K530_TYPE 302 SS CONICAL COMPRESSION SPRING
7658K170_SUBMINIATURE SNAP-ACTING SWITCH
Radar Altimeter Pot Mount
90760A005_ZINC PLATED STEEL NARROW HEX NUT x 2
93365A110_BRASS HEAT-SET INSERT FOR PLASTICS_2-56 x 14
90272A077_ZINC-PLTD STL PAN HEAD PHILLIPS MACHINE SCREW_2-56 X .250 x 8
90272A079_ZINC-PLTD STL PAN HEAD PHILLIPS MACHINE SCREW_2-56 X .375 x 8
Hitec HS-35HD Ultra Nano Servo
servo horn
screw
Radar Altimeter OFF Flag
92671A115_BRASS HEX NUT x 2
91772A061_18-8 SS PAN HEAD PHILLIPS MACHINE SCREW_#0-80 X .2812 x 2
93365A102 - INSERT, 0-80, BRASS, FOR PLASTICS x 6
91772A064 - PHS, 0-80 x .4375, 18-8 x 6

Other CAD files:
ECAD/PCBs/ABSIS/NANO_IO/SW/R_0805_2012Metric.sldasm
MCAD/UFC Panel_v3.SLDASM
MCAD/FWD UFC Assembly.sldasm
MCAD/DDIv2.SLDASM
ECAD/PCBs for Sim/.55 SQ Indicator/docs/.55 SQ INDICATOR PCB DEFINITION.SLDDRW
ECAD/PCBs for Sim/.55 SQ Indicator/docs/.55 SQ Indicator PCB.DXF
ECAD/PCBs for Sim/55 SQ Indicator/docs/.55 SQ INDICATOR PCB DEFINITION.SLDDRW
ECAD/PCBs for Sim/55 SQ Indicator/docs/.55 SQ Indicator PCB.DXF
ECAD/PCBs/ABSIS/ABSIS_ALE Relay Module/MCAD/ABSIS_ALE Relay Module.step
ECAD/PCBs/ABSIS/ABSIS_ALE+/MCAD/ABSIS_ALE+.step
ECAD/PCBs/ABSIS/ABSIS_Bus_Master/MCAD/ABSIS_Bus_Master.step
ECAD/PCBs/ABSIS/ABSIS_Bus_Master/legacy/JLCPCB/STEP.step
ECAD/PCBs/ABSIS/ABSIS_Bus_Master/legacy/MCAD/ABSIS_Bus_Master.step
ECAD/PCBs/ABSIS/ABSIS_Hall Sensor/MCAD/ABSIS_Hall Sensor.step
ECAD/PCBs/ABSIS/ABSIS_Pit Management System/MCAD/ABSIS_Pit Management System.step
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

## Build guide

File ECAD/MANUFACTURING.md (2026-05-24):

OH logo
* [OpenHornet Website](https://www.openhornet.com)
* [OpenHornet Discord](https://discord.gg/G5PA5ju)
* [Donate to OpenHornet](https://www.openhornet.com/donate.html)

# Ordering PCBs from JLCPCB
JLCPCB is a popular online platform for ordering printed circuit boards (PCBs) and has been chosen as the recommended supplier of OpenHornet PCBs. This guide will walk you through the steps to order your own PCBs from JLCPCB.

## Step 1: Sign Up
Before you can start ordering PCBs, you need to create an account on JLCPCB. To do so, go to jlcpcb.com and click on the "Sign Up" button. Fill in your email address and password to create your account.

## Step 2: Upload the PCB Design
On the main page, click on the icon that says "Add gerber file."  OpenHornet has already generated the files you need to upload in order to create your PCBs.  When the browser window opens, navigate to the _\PCB_You_Want\JLCPCB\production_files\_ folder, and look for _**"GERBER - PCB_NAME.zip"**__   For this example, I will be assembling the **COMM PANEL.**



## Step 3: Select PCB Parameters
After uploading your design, you'll be taken to the order page where you can select the parameters for your PCBs. You'll need to select the following parameters:

#### JLCPCB should detect how many layers it needs based on the gerber files you've uploaded.  However, the safest course of action is to double check the "production_files" folder and look for a text document called "IMPORTANT MANUFACTURING INSTRUCTIONS.TXT" which will provide any specific adjustments you need to make to the parameters.  If there isn't one located in the folder, then the standard settings will apply.

### PCB Layer: 
The majority of Openhornet PCB's require only 2 Layers. Reference the note above if there are any questions.

### PCB Dimensions: 
Automatically detected.  If the PCB size doesn't meet the minimum 100x100mm dimensions, you will be asked to allow JLC to make modifications to continue processing.  Click yes.

### PCB Quantity: 
The number of PCBs you want to order.  The minimum is 5.  Most PCBs only require 1, so it's best to find a group buy to split the costs.  However, there are a few PCBs where more than 1 are required.  Make sure you confirm the quantity you need!

### PCB Thickness:
1.6mm

### PCB Color:
Choose whatever color you prefer.  Note: Depending on other PCB attributes (2oz Copper, 4 Layers, etc.) you'll be limited on the color you can choose.

### Confirm Production File:
YES!  It's a few cents more and having the extra check is absolutely worth it.  JLC currently has errors with the way their website analyzes files, so it's highly possible for pieces to be rotated incorrectly.

### The rest of the settings can be default.  See the example before if you have any questions.



## Step 4: Choose Components and Assembly Services (Optional)
If you want JLCPCB to assemble the components onto your PCBs, you can choose from their component and assembly services. You'll need to upload a BOM (Bill of Materials) file and CPL positioning file that tells JLC the exact location that the components need to be placed.  Again, Openhornet provides these documents in the same production_files folder for you to use.

#### It is possible that JLC doesn't have an item in stock.  You have a few options: choose a similar piece that meets the specifications, provide your own components by using the Parts Manager located on their website, or ignore the missing parts and continue production with what they have available.  The majority of OpenHornet PCBs require only TOP level SMD (surface mounted device) Assembly.  The Bottom Level is typically THT (Thru-hole technology) which can be soldered at home.  Due to cost effectiveness and feasibility, it is recommended to assemble layers that have SMD components.

### PCBA Type:
The “Economic” option is the cheapest, but if you assemble both sides, you'll have to choose the “Standard” option.  Some components require Standard to be selected and JLC will prompt you to change if needed.

### Assembly Side: 
Top Side.  9/10 PCBs require Top Level assembly.  If the parts are available and cost is of no concern, you can opt to have both sides assembled.

### Confirm Parts Placement: 
YES!!!!!!! 



## Step 5: Upload BOM and CPL files.
*  1:  Click on the "Add BOM File" and "Add CPL File" icons and upload the required files accordingly.
*  2:  In the drop down box below, select **"Research\Education\DIY\Entertainment ==> Video\TV Game Player HS Code 950450"**



## Step 6:  Selecting Parts
By default, JLC will load the parts selected based on the BOM provided as long as the LCSC Part Numbers are correct.  If for any reason, it doesn't recognize a part number, please contact us.  We've worked diligently to ensure everything is correct, but mistakes happen.  If there is an inventory shortage, you can change the part by clicking on it and searching for similar components.  Another option for inventory shortages is to pre-order the parts, see pre-ordering parts section in this guide.



#### Referencing Step 4:  If this happens, just hit accept if you wish to continue with assembly or choose "Do not place this part." 



## Step 7:  Review and Submit Order
Review your order and if everything looks correct, fill out your financial and shipping information as required.  After making payment, you'll receive an order confirmation email. You can track the status of your order by logging into your JLCPCB account. That's it! You've successfully ordered PCBs from JLCPCB. The process is straightforward and simple, making it easy to get the PCBs you need for your project.

# Pre-ordering parts with JLCPCB
Ordering parts for use in PCB manufacturing can assist with completing orders succesfully without having to worry about parts running out of stock or competing with orders from other people.

## Step 1: Navigate to Parts Manager
Hover over your user name while logged in, and select 'Parts Manager'



## Step 2: Click on Order Parts
Choose parts sourcing, starting with JLCPCB if it's a part that they'll stock.  The global sourcing option allows ordering parts from other suppliers and having them shipped to JLC.



## Step 3: Search for the Part
Use the part number or other information to search for the part.  Parts that JLC has in their catalog will appear, along with their current stocking.  If you place an order with stocked parts they will be reserved for your PCB orders.



## Step 4: Enter the quantity and click Add to My Part Lib for Assembly



## Step 5: Go to Order Parts Cart to check out



## Step 6: After Part is Stocked
JLC will notify you when the part is in inventory and available for your use.  Proceed to the beginning of the guide to place a PCB order.  When it comes time to select the part for assembly the PCB ordering page will indicate that the part is coming from your stock.

_Note: The details mentioned in this guide are subject to change, kindly check the JLCPCB website for the latest information._

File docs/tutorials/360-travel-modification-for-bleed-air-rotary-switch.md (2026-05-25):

# Modify Bleed Air Switch for 360° Travel

> Submitted by OpenHornet Contributor Randy “Exprezzo” Henrion.  
> Originally posted by Noctum on July 8, 2023.

The Bleed Air Knob Mechanism, `OH5A5A1-200`, requires a 4-position, 90° throw switch with continuous rotation. Unfortunately, a continuous rotation switch meeting this specification was obscenely expensive, so this tutorial modifies a cheaper version instead.

The switch used is the A12405RNZQ switch.

> [!CAUTION]
> Be careful, do not use too much force, and take your time. The small components inside are under spring force and will launch into the ether if you are not careful.

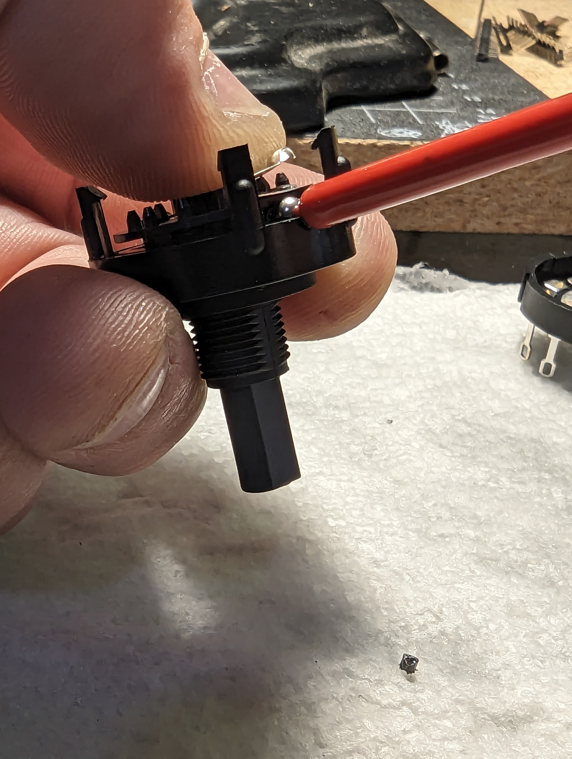
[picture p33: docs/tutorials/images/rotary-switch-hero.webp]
Rotary switch modification hero image


## Tools and Materials Required

1. [A12405RNZQ Switch](https://www.digikey.com/)
2. Small flat head screwdriver or other small prying tool
3. Small needle nose pliers
4. Tweezers
5. Flush cutters
6. Needle file

## Step 1: Housing Disassembly

While keeping the stem under tension and secured, open the housing by gently prying away the four clips on the bottom of the rotary switch.

Too much force applied to the plastic clip will cause it to break. Instead, gently push a clip toward the edge, about 25% of the way, and then move on to the next one. Keep doing this until all of the pins have clearance, and then separate the housing.

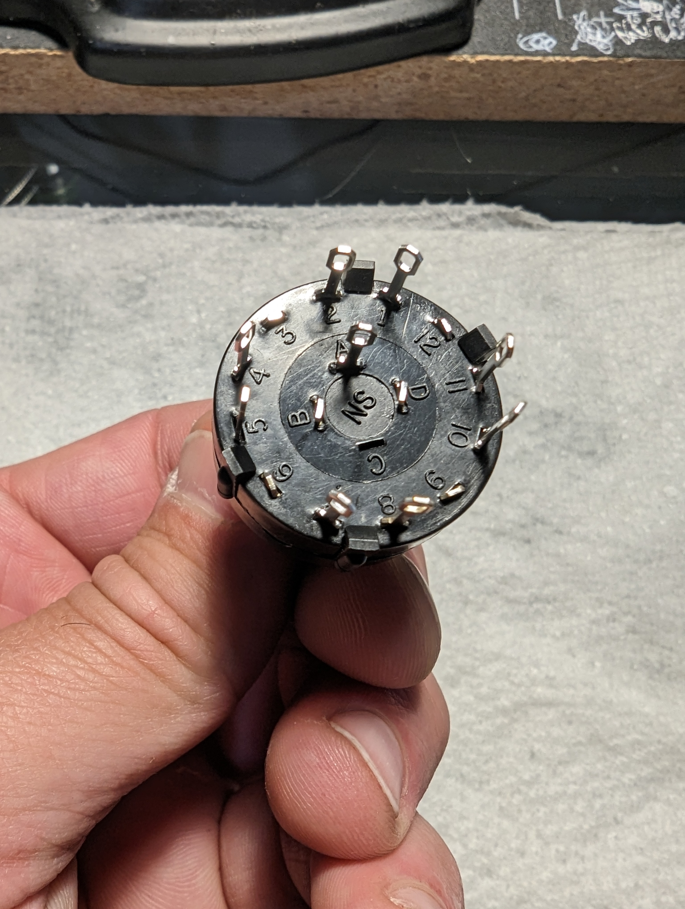
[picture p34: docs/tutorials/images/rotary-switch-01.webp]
RotarySwitch1


*RotarySwitch1*

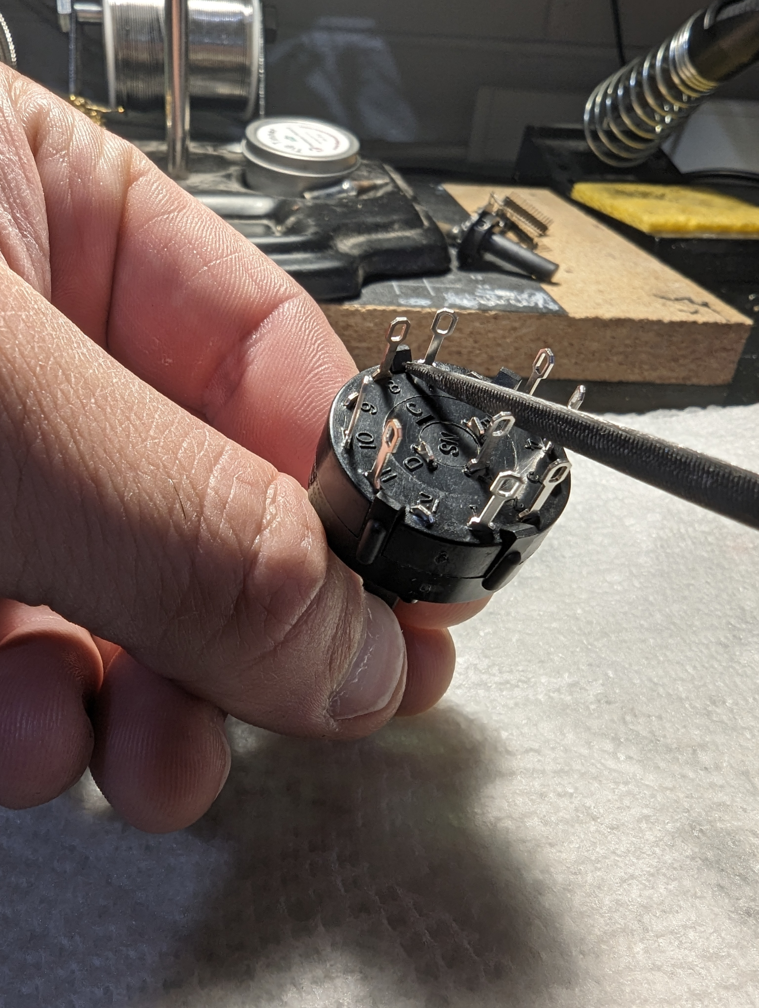
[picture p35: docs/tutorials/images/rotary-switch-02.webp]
RotarySwitch2


*RotarySwitch2*

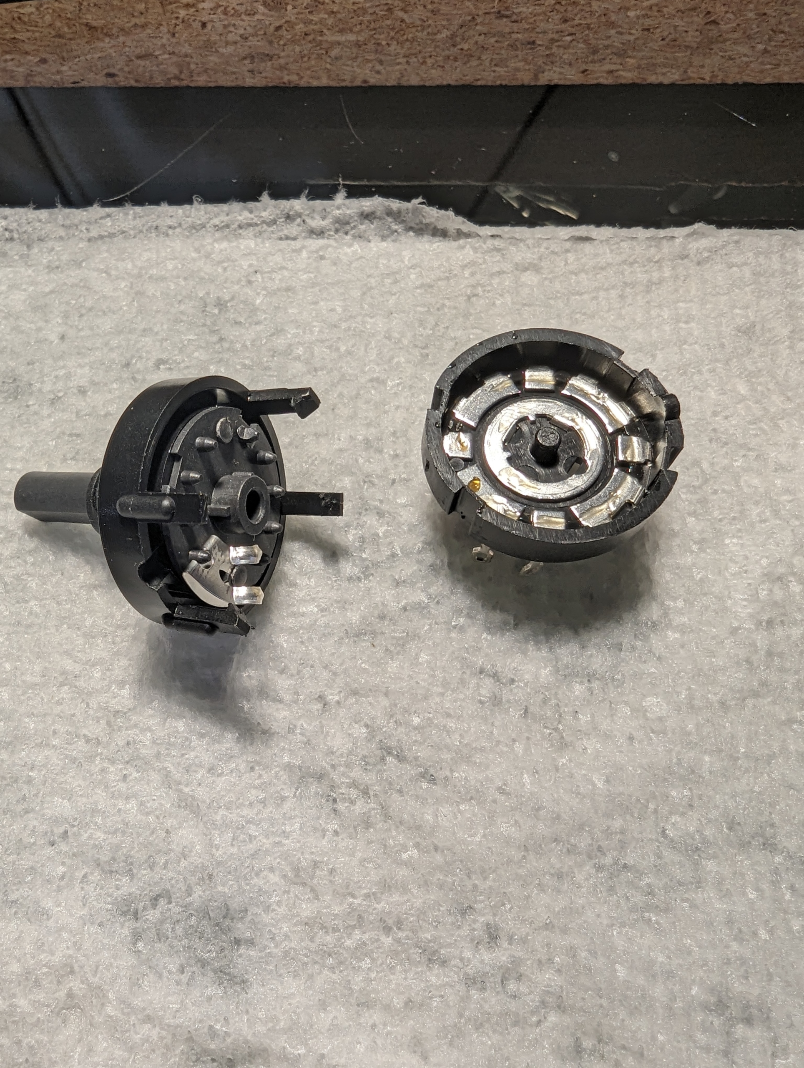
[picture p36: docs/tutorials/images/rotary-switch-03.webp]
RotarySwitch3


*RotarySwitch3*

> [!WARNING]
> Do not move the stem from the top housing. There are two ball bearings held under spring tension.

## Step 2: Stem Removal

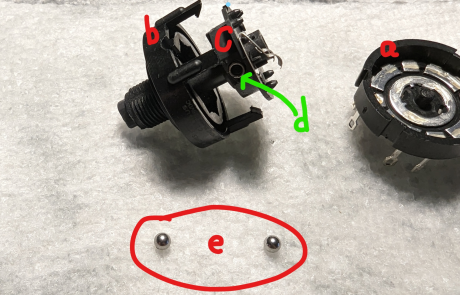
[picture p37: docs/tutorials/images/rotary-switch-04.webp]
RotarySwitch4


*RotarySwitch4*

Cup the housing with the palm of your hand and remove tension on the stem by slowly pushing it through the housing.

As soon as the base of the stem clears the housing, the ball bearings under spring tension will shoot out.

The rotary switch is comprised of five main components:

| Label | Component |
| --- | --- |
| A | Bottom housing |
| B | Top housing |
| C | Stem |
| D | Spring |
| E | 2x ball bearings |

## Step 3: Rotation Stop Removal

Remove the two plastic tabs, one located on the stem and one located inside the top housing, by whatever means suitable.

It is recommended to use flush snips, razor blades, or even nail clippers, but it is possible to sand or file the tabs down. Ensure a clean, smooth surface to prevent additional friction or snagging.

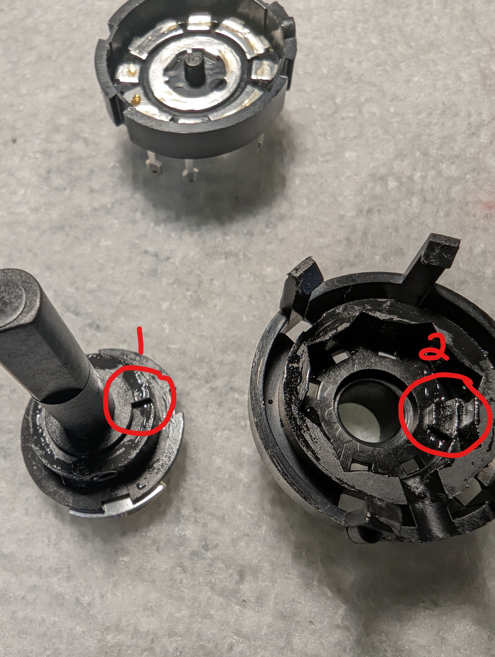
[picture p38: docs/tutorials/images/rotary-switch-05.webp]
RotarySwitch5


*RotarySwitch5*

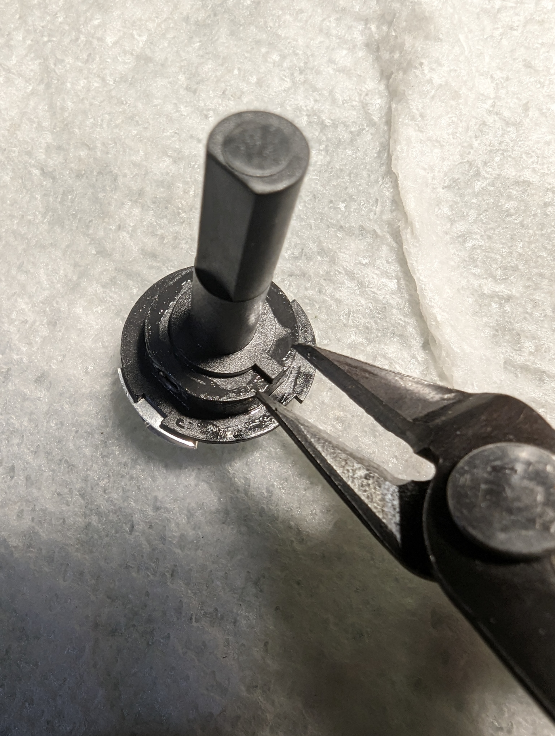
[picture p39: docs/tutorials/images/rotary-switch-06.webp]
RotarySwitch6


*RotarySwitch6*

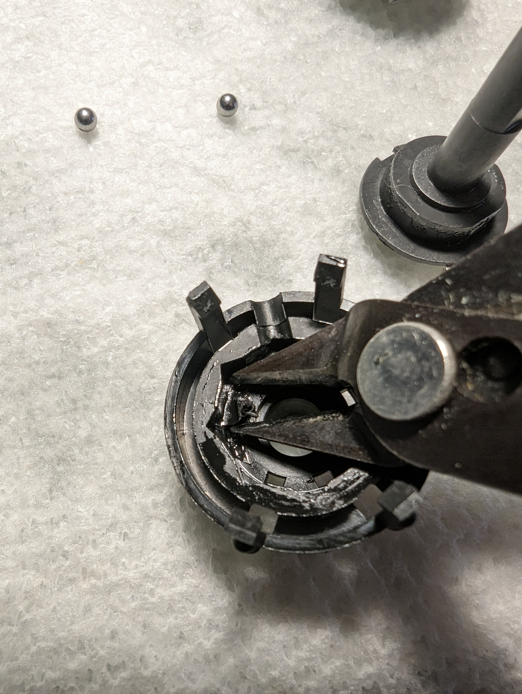
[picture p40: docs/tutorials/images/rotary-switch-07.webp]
RotarySwitch7


*RotarySwitch7*

## Step 4: Switch Reassembly

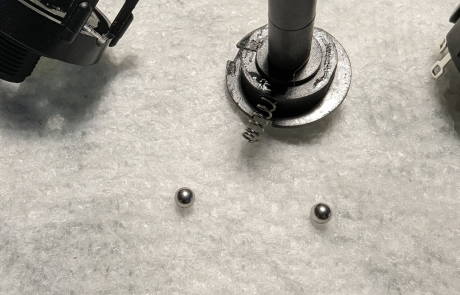
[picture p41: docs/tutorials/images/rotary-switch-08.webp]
RotarySwitch8


*RotarySwitch8*

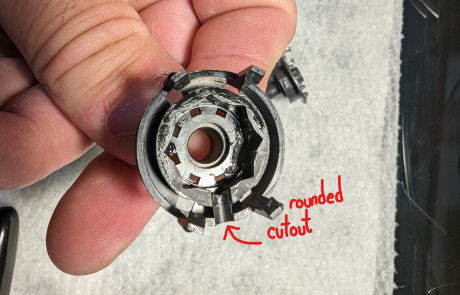
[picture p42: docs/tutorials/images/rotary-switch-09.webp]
RotarySwitch9


*RotarySwitch9*

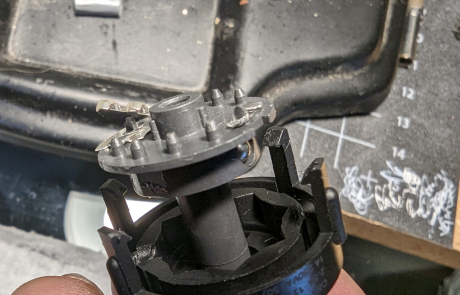
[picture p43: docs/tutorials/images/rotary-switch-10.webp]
RotarySwitch10


*RotarySwitch10*

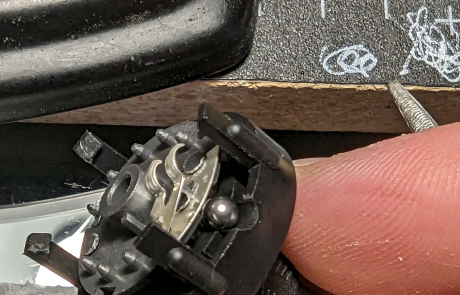
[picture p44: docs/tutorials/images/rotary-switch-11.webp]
RotarySwitch11


*RotarySwitch11*

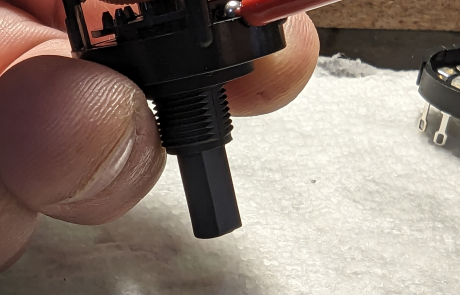
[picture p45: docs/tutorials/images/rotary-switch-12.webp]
RotarySwitch12


*RotarySwitch12*

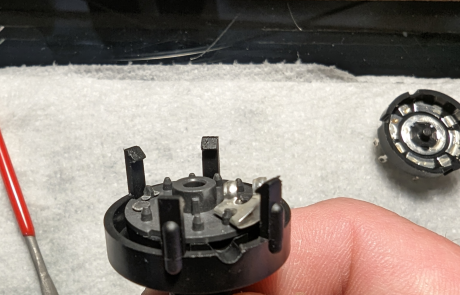
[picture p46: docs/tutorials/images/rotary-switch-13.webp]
RotarySwitch13


*RotarySwitch13*

1. Insert the spring back into the stem, and then slide the stem back through the top housing.
2. Rotate the stem so the spring is parallel with the rounded cutout on the upper housing.
3. Insert a ball bearing into the spring opposite the side of the cutout.
4. Push the stem all the way into the housing to secure the backside ball bearing, and insert the second ball bearing into the rounded cutaway portion.
5. While maintaining downward pressure on the stem, use the backside of a pen, marker, or other object to push the ball bearing into the spring. Once it clears the cutout, the stem will collapse and secure the bearings in place.
6. The stem should now sit flush. Place the bottom housing back on and ensure the clips are secured under their own tension. Then test it.

## Step 5: Testing

1. Spin the switch, ensuring all detents are felt and the switch travels smoothly through the entire range of movement.
2. Verify continuity of each position with a multimeter or similar tool.

Congratulations. You have now successfully converted your switch to a 4-position, 90° throw, continuous rotation switch.

## License

OpenHornet’s works are licensed under a [Creative Commons Attribution-NonCommercial-ShareAlike 4.0 International License](https://creativecommons.org/licenses/by-nc-sa/4.0/).

Attribution information:

- Name: OpenHornet
- URL: <https://www.OpenHornet.com>
- Email: <webmaster@openhornet.com>

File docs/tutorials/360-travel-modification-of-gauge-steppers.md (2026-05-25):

# Modify Gauge Steppers for 360° Travel

> Originally published on OpenHornet.com on 2023-10-29.  
> Submitted by OpenHornet Dev Tester/Builder **Krikeee**.

Various instruments within the simulator, as denoted on their respective drawings, such as OHC007-1, require a modification to allow the gauge stepper motor to have continuous travel. Fortunately, the most common variants of these little stepper gauges can be easily modified, relying instead on external electronics to give zero position.

The motor is the **VID29-02P** motor. Be careful, do not use too much force, and take your time.

## Tools & Materials Required

1. [VID29-02P Gauge Stepper Motor](https://www.amazon.com/)
2. Small Phillips head screwdriver
3. X-Acto/hobby knife with a near clear blade
4. Jeweler/needle file
5. Tweezers

## Step 1: Housing Disassembly

1. On a soft surface, orient the stepper motor with the shaft side up. See Image 1.
2. With the small screwdriver, remove each of the four screws holding on the cover.
3. Remove the cover, being careful not to jar anything loose. It should come off easily, leaving the shaft and gears visible. See Image 2.

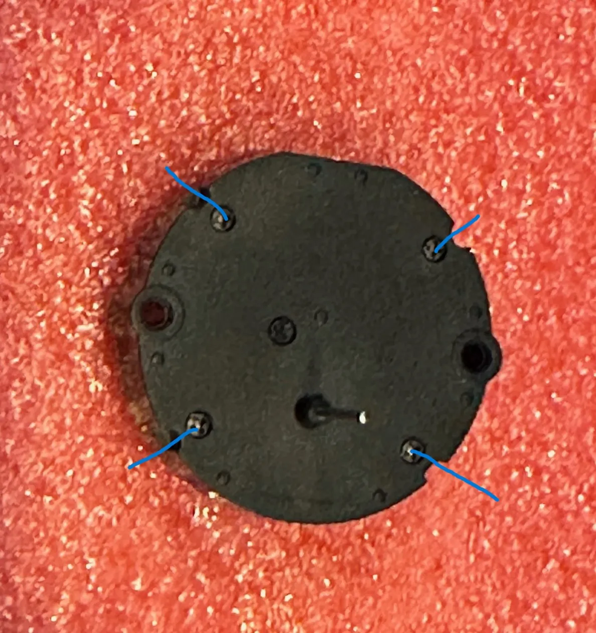
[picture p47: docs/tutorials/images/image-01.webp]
Image 1 - Stepper motor housing with screw locations marked


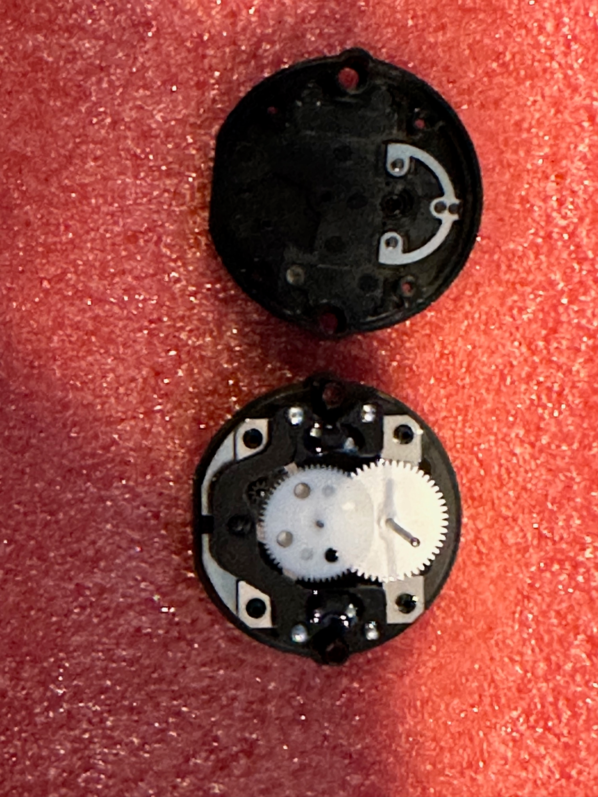
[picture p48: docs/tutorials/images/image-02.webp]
Image 2 - Stepper motor cover removed, exposing shaft and gears


Be sure not to bend the pins on the underside of the motor.

## Step 2: Shaft & Gear Removal

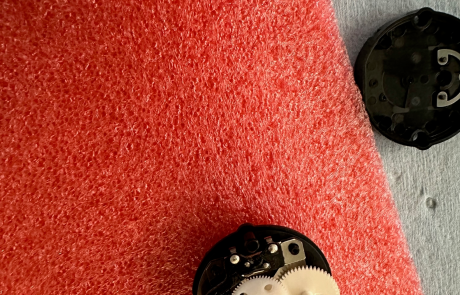
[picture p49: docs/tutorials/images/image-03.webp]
Image 3 - Shaft and gear being lifted from the motor assembly


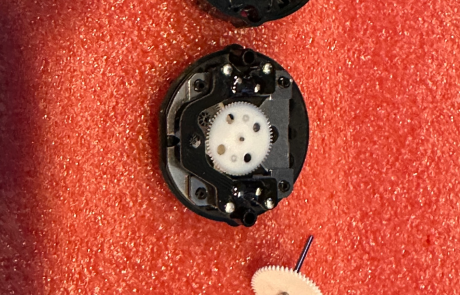
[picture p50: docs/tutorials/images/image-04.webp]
Image 4 - Shaft gear removed from beneath the upper gear


1. Using the tweezers or your fingers, grasp the metal shaft and lift gently. It will pull up the gear it is attached to and slightly lift the gear on top of it.
2. Slide the shaft and its gear out from beneath the top gear, tilting it slightly if needed. See Images 3 and 4.

## Step 3: Rotation Stop Removal

1. Using the hobby knife, carefully remove the small stop on the underside of the shaft gear. See Image 5.
2. Removing small slices at a time seems to work better than trying to cut the entire bit off at once.
3. When done, ensure there is a smooth surface where the stop was located. See Image 6.

Alternatively, you could use flush snips, razor blades, nail clippers, or just sand/file it down. The important thing is to ensure a clean, smooth surface to prevent additional friction, snagging, or lost motor steps.

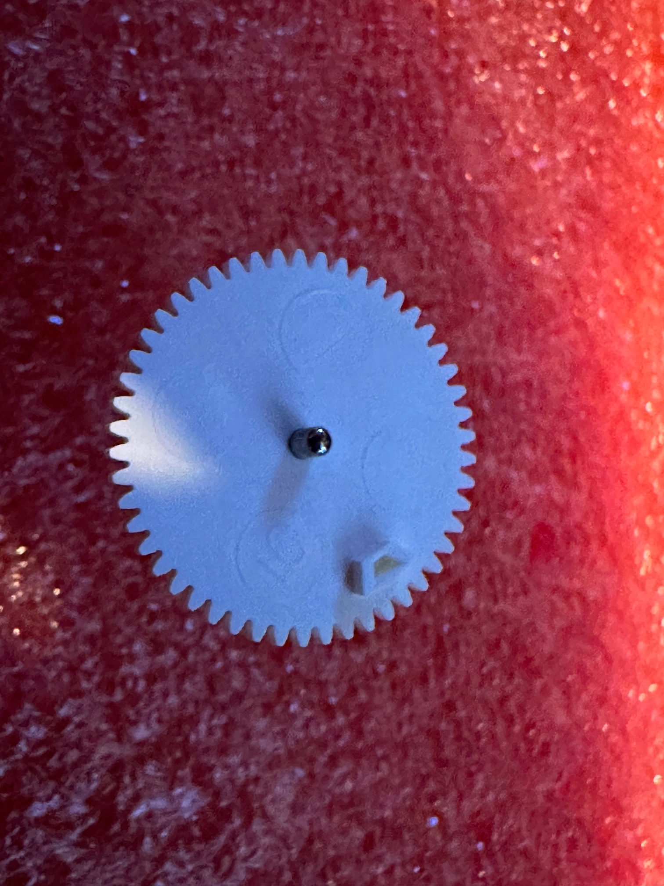
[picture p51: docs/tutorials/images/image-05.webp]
Image 5 - Shaft gear before removing the rotation stop


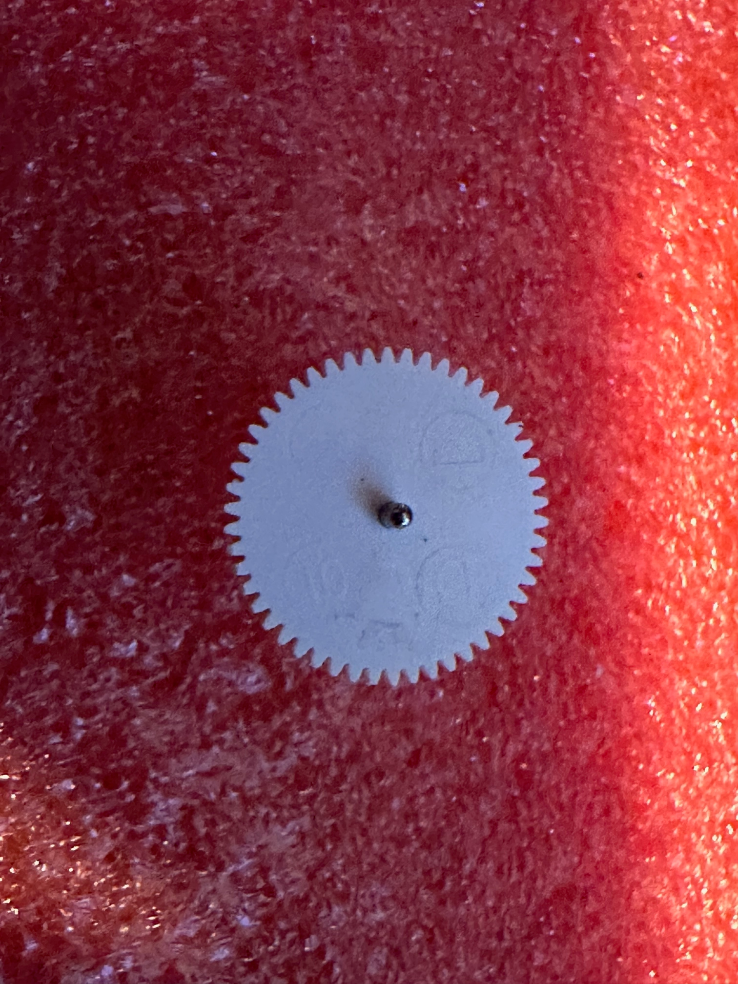
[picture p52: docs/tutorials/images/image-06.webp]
Image 6 - Shaft gear after the stop has been removed and smoothed


## Step 4: Motor Reassembly

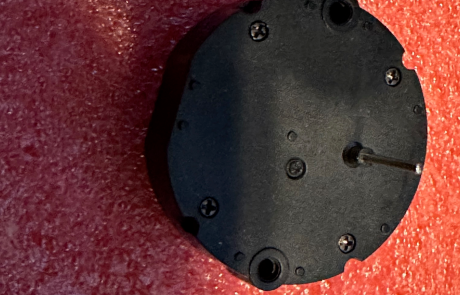
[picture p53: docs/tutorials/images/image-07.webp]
Image 7 - Reassembled modified gauge stepper motor


1. Carefully replace the shaft and attached gear by slipping it back under the top gear.
2. Lift as needed to get the shaft seated back into the hole.
3. Gently spin the gears to ensure they are all engaging correctly. Be careful not to dislodge them.
4. Slide the cover back over the shaft and ensure it is flush with the rest of the housing.
5. Screw in the four screws and tighten. Be careful not to overtighten them. See Image 7.
6. Label or otherwise mark the motor so you know it has been modified, since there will be no external indication of the modification.

## Source

Original tutorial: <https://openhornet.com/2023/10/29/360-travel-modification-of-gauge-steppers/>

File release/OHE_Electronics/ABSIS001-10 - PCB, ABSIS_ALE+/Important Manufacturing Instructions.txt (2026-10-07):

1:  This is a 4 layer PCB.  Make sure you check and select the appropriate settings when having this board manufactured by a 3rd party.
2:  This PCB only has Bottom Layer components.
3.  D3 is oriented correctly per provided files. Negative pin of D3 shall be oriented towards fuse.

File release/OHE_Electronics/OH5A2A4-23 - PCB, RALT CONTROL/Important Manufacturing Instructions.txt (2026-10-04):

1:  This PCB only has Bottom Layer components and will only have a "BOM-CONTROLLER_Radar Altimeter.csv"
2:  This is a six (6) layer PCB.

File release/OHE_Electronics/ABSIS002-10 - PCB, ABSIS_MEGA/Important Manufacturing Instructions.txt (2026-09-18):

1:  This is a 2 layer PCB.  Make sure you check and select the appropriate settings when having this board manufactured by a 3rd party.
2:  This PCB only has Top Layer components.

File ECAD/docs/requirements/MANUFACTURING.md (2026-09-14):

# Manufacturing outputs and assembly definition

## Basis

The [existing manufacturing guide](../../MANUFACTURING.md) recommends JLCPCB, usually two layers, 1.6 mm board thickness and usually top-side SMD assembly. It explicitly defers to board-specific instructions. ATX and Backlight Controller specify copper/layer exceptions; UFC Main and Function Select require both-side SMD assembly. The older generation guide already requires outputs to be regenerated after PCB changes. Reproducibility and explicit acceptance below are **adopted project policy under PR #1255**.

## Owner-directed manufacturing and sourcing policy

Owner direction recorded 2026-09-11 establishes **JLCPCB as the intended PCB fabricator and SMD assembler**, JLCPCB-available parts for all fitted SMD positions, and **DigiKey or Mouser as the default through-hole procurement sources**. Affordable fabrication and assembly and avoiding stockouts for committed PCB parts are explicit design objectives. These are confirmed project decisions, not inferred historical defaults; the framework's adoption and deviation process still applies.

- **MFG-012:** All PCB designs MUST meet the current JLCPCB fabrication and assembly requirements for the selected service, layer count, copper weight, stackup and assembly process. Record dated official capability references and selected order options in the fabrication profile. Encode applicable limits in KiCad and explicitly check those that cannot be encoded. Electrical, thermal and mechanical requirements may require stricter constraints; vendor minima MUST NOT replace engineering analysis.
- **MFG-013:** All SMD components fitted directly to an OpenHornet PCB MUST be purchased through JLCPCB, be available for procurement and assembly through JLCPCB and assigned to JLCPCB assembly. Verify exact MPN/package, JLCPCB part identifier, service eligibility, available quantity and lead time during selection and again before ordering. An LCSC listing or stock code alone MUST NOT establish JLCPCB assembly availability. Do not silently move unavailable SMD parts to builder assembly or mark required parts DNP; qualify a suitable replacement or obtain a documented owner-approved deviation.
- **MFG-014:** Through-hole components MUST have an orderable exact MPN and a verified source, defaulting to DigiKey or Mouser. Other suppliers MAY be used where appropriate; record the supplier, sourcing reason, exact part identity, suitability and availability in the human-reviewed BOM. Provide supplier SKU/link, quantity and dated availability/lead-time evidence in a separate builder-procurement BOM, with installation responsibility and instructions. These positions MUST NOT be accidentally included as JLCPCB-fitted SMD positions or omitted from the complete assembly definition. Through-hole procurement and installation remain separate from the JLCPCB SMD order unless an owner-approved deviation specifies otherwise.
- **MFG-015:** Every fabrication/assembly output set MUST provide a JLCPCB-compatible manufacturing package: Gerber/drill archive, JLCPCB-format SMD BOM with exact part mapping, compatible CPL/placement file, assembly/fabrication instructions and order parameters. Include a complete master BOM, separate through-hole procurement list (DigiKey/Mouser by default, documented alternatives where used) and traceability manifest alongside the upload files. Verify current accepted formats, required fields, units, rotations, assembly sides and reference agreement. Review JLCPCB import/placement feedback before order approval; successful upload alone is not manufacturing or electrical approval. Supplemental KiCad/PDF/STEP evidence does not substitute for the upload package. For a design with no fitted SMD positions, record BOM/CPL assembly submission as not applicable rather than inventing placements.
- **MFG-016:** Designers MUST assess fabrication and assembly cost at the intended prototype/build quantity and record the selected approach and material cost drivers. Apply MFG-017 stock-depth selection first; use cost to choose between equally stocked suitable candidates. Prefer JLCPCB Basic parts where consistent with that selection and where they reduce the current quote; compare Extended-part and other procurement/setup charges rather than assuming list price is total cost. Designers SHOULD minimize unnecessary unique parts, premium processes, assembly sides, layer count, tight fabrication features and board area, subject to required function, margins, fit, serviceability and existing validated constraints. Do not reduce required layers/copper or change a qualified part solely for cost without the applicable engineering review. Include PCB, parts, setup/assembly, special-process and through-hole procurement/shipping costs where available; record date, quantities and assumptions, not permanent price limits.

- **MFG-017:** When multiple JLCPCB SMD candidates meet the required electrical, package, thermal, mechanical and assembly constraints, select the candidate with the **largest currently available JLCPCB assembly quantity** among the evaluated suitable alternatives. Record the compared exact MPNs/JLCPCB identifiers, quantities, stock-check date and selected part in the review record. Recheck stock before committing a new or changed component selection to an OpenHornet PCB and before ordering; assess available quantity against per-board usage and the planned build. Prefer a qualified in-stock alternative over an out-of-stock or insufficient-stock part; do not commit such a selection as production-ready without a documented owner-approved exception and procurement plan. A Basic/Extended classification or lower price alone MUST NOT override the stock-depth rule; a justified cost or other tradeoff requires a documented owner-approved deviation. Where practical, qualify alternate MPNs to reduce future stockout risk. Stock is time-dependent, so this rule does not guarantee future availability or authorize automatic substitutions on validated boards; CMP-005 and the applicable validation requirements still apply.

Official starting points checked 2026-09-11: [JLCPCB fabrication capabilities](https://jlcpcb.com/capabilities/pcb-capabilities), [JLCPCB assembly parts library](https://jlcpcb.com/parts). Recheck the current assembly capability and BOM/CPL guidance for the chosen service when establishing the profile and preparing an order. No stock, fee or numerical capability is frozen by this document.

Purchased MCU modules, displays and other complete assemblies MAY come from other documented suppliers after module-specific qualification of vendor, revision, interfaces and suitability. The direct-fit SMD procurement/assembly rule does not apply to components internal to those purchased assemblies; it does apply when OpenHornet designs the module PCB itself. Record exact vendor/revision or qualified equivalence under CMP-006 and assign installation responsibility. This distinction does not authorize sourcing loose SMD components elsewhere for an OH PCB.

## Requirements

- **MFG-001:** Generate manufacturing outputs from an identified, saved source revision/variant after applicable CAD checks and electrical review, with the fabrication profile established. Physical prototype qualification is not a prerequisite for generating a prototype package. Label provisional development outputs and document unresolved findings; prototype ordering still requires human acceptance of the package and its limitations. Use KiCad or an identified version of a reviewed export tool. Record options, units, origins, layer set and source hashes. Refill zones and complete applicable checks first.
- **MFG-002:** The fabrication package MUST include every intended copper layer, appropriate mask/silkscreen, board outline, drill/slot data with plating distinction, and any required paste/fabrication drawings. Check that compressed Gerber packages contain the new files and no stale layers or unrelated boards.
- **MFG-003:** Open and inspect the generated CAM itself in a Gerber/drill viewer. Check outline/cutouts, layer count/alignment, holes, copper clearances and connectivity features, polarity, mask openings and unexpected objects. Source screenshots are not CAM review.
- **MFG-004:** Reconcile source, fabrication notes, Gerber metadata and supplier order parameters for layer stack, copper weight, board thickness, finish, tolerances and assembly sides. Never accept supplier defaults or automatic detection without checking. Explicit conflicting instructions block manufacturing approval.
- **MFG-005:** BOM records MUST contain reference designators, quantity, manufacturer/exact MPN or approved equivalent, value/specification, package, supplier code where needed, DNP state and assembly responsibility. Reconcile all populated references with source and distinguish intentionally hand-assembled modules/displays/connectors from omitted parts.
- **MFG-006:** CPL/position records MUST use the supplier's required units, origin, axis/rotation convention and side notation. Verify polarity and pin 1 in supplier placement previews, especially mirrored bottom-side parts. Do not assume KiCad zero rotation equals the supplier's zero rotation.
- **MFG-007:** Review actual supplier-selected parts against the approved BOM, including substitutions, package suffixes and stock-dependent changes. Missing components require resolution under MFG-013/014; DNP is only for intentional assembly variants, and hand assembly of a required SMD part requires an owner-approved deviation. Accepting an automated omission is not a complete assembly definition.
- **MFG-008:** Provide assembly instructions for jumper defaults, termination options, fitted module versions/modifications, displays, connectors, polarity and special handling. Follow manufacturer moisture/bake/reflow limits for the selected parts; the UFC bake note is not a universal bake recipe.
- **MFG-009:** Preserve source→CAM→BOM/CPL→order/prototype traceability with a manifest or review record containing hashes, revision and date. Update the applicable `JLCPCB/production_files` and `release/OHE_Electronics` packages together when preparing a hardware release. Development output may remain provisional, clearly labeled; do not silently present stale release files as current.
- **MFG-010:** A different fabricator, SMD sourcing route or assembly process requires an owner-approved deviation and comparison against the complete fabrication profile and output format. JLCPCB is the intended fabricator/SMD assembler; old capability assumptions and service-tier compatibility still require verification.
- **MFG-011:** Exclude temporary plots, caches, local settings and scratch outputs from new commits. Commit only intended authoritative sources and requested reviewed deliverables. Existing historical output clutter is not authorization for cleanup in a documentation-only PR.

## Prototype order versus release

A manufacturable prototype may be ordered after human review and documented acceptance of prototype limitations. This is not release qualification. Manufacturing review MUST state which exact package was reviewed, remaining supplier questions and any assembly deviations. Hardware release requires [QUALIFICATION.md](QUALIFICATION.md).

## Exact assembly identity

- **MFG-018:** For each fitted reference, identify the exact approved part and assembly responsibility consistently across the reviewed source and output set. A missing JLCPCB identifier for a required direct-fit SMD component is an unresolved assembly mapping, not an instruction to hand-fit or omit it. Resolve schematic/PCB/BOM disagreement before approving an order, even if the package geometry is unchanged. A released directory or prior successful export does not waive this requirement.

## Assembly cost and appearance

- **MFG-019:** Prefer single-sided SMD assembly. Double-sided SMD assembly is permitted when required by function, placement or mechanical constraints, but document the reason and consider its substantial cost increase. All fitted direct-fit SMD parts remain assigned to JLCPCB assembly on their actual side; the preference never authorizes omitted parts or builder SMD assembly.
- **MFG-020:** Specify black solder mask and white silkscreen. Confirm compatibility with the selected copper/stackup/assembly service. If unavailable, resolve the profile or obtain an explicit deviation rather than silently changing color.

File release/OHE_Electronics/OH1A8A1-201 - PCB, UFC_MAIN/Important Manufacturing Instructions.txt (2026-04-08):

1:  This PCB requires Standard SMD Assembly on BOTH sides.
2:  Bake components per manufacturer specification.

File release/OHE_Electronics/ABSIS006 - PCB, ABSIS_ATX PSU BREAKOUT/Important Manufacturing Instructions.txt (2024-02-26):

1:  This is a 4 layer PCB.  Make sure you check and select the appropriate settings when having this board manufactured by a 3rd party.
2:  Each layer requires a 2oz Copper Pour.
3:  This PCB only has Top Layer components.

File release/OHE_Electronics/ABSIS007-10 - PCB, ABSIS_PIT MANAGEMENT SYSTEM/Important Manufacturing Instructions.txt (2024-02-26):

1:  This PCB only has Top Layer components

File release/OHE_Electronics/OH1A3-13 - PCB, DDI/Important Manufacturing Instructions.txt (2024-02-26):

1:  JLCPCB.com is now using part:  TCA9554PWR as a drop-in replacement for PCA9554PWR.  However, TCA9554PWR is often low in stock in order to purchase both DDI and AMPCD PCBs.
PCA9554 can be used a part alternative but you must ensure you specify PCA9554PWR so the correct package is used if you choose to do this.  

2:  When in doubt, use TCA9554PWR.

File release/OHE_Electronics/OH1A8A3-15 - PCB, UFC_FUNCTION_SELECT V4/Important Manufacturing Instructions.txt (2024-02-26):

1:  This PCB requires Standard SMD Assembly on BOTH sides.

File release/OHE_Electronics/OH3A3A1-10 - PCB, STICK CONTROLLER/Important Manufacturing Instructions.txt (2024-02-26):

1:  This PCB only has Top Layer components and will only have a "BOM_TOP-CONTROLLER_Stick.csv"

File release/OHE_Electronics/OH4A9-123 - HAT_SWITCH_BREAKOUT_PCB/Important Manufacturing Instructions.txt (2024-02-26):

1:  This PCB only has one Bottom Layer thru-hole component and will only have a "BOM_BOTTOM-HOTAS_Hat Switch Breakout.csv"

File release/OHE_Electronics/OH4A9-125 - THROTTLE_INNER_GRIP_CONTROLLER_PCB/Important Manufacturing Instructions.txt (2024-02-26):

1:  This PCB only Top Layer components and will only have a "BOM_TOP-HOTAS_Throttle Inner Grip.csv"

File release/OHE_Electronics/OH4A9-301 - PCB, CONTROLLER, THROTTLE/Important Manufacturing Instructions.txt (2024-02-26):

1:  This PCB only has Top Layer components and will only have a "BOM_CONTROLLER_Throttle.csv"

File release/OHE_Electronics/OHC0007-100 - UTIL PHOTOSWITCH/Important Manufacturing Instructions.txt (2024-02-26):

1:  This PCB only has Top Layer components and will only have a "BOM_TOP-UTIL_PHOTOSWITCH.csv"

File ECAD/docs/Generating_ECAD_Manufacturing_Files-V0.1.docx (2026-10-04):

# Generating ECAD Manufacturing Files

# Requirements:

KiCad 10 (screenshots are historical)

# Prerequisite:

Make sure that the PCB you intend to create manufacturing files for is finished and reviewed. Every time there are changes on the PCB, the manufacturing files have to be re-generated.

# Manufacturing Files:

## Gerber Files

Gerber File | Purpose | Description
xyz.F_CU.grb | Front side copper | Copper pads
xyz.B_CU.grb | Back side copper | Copper pads
xyz.F_Mask.grb | Front side mask | Solder mask. A thin lacquer layer.
xyz.B_Mask.grb | Back side mask | Solder mask. A thin lacquer layer.
xyz.F_Paste.grb | Front side soldering paste | The solder paste for the components (only needed for machine PCB manufacturing)
xyz.B_Paste.grb | Back side soldering paste | The solder paste for the components (only needed for automated SMD production)
xyz.F_SilkS.grb | Front side Silk Screen | All the markings, including text.
xyz.B_SilkS.grb | Back side Silk Screen | All the markings, including text.
xyz.Edge_Cuts.grb | Edge Cuts | The outline of the PCB. For CNC cutting.
xyz.PTH.grb | Plated through holes | Holes in the PCB who are plated. Like vias or THT component holes for example.
xyz.NPTH.grb | Non plated through holes | Holes without plating. Like mounting holes for screws.

Table 1

## Pick and Place data.

Normally *.csv files. One for the front and one for the back. Those files include all the SMD components and their exact location and rotation. Only needed for automated SMD production.

## Bill of Material (BOM)

Bill of Material with all the needed components.

# Process:

## Gerber Files:

- Open the PCB you want to create the Manufacturing Files for, in KiCAD’s Pcbnew.
- Select “Plot” from the “File” menu.
- In the included Layers you need: F.Cu, B.Cu, F.Paste, B.Paste, F.SilkS, B.SilkS, F.Mask, B.Mask and Edge.Cuts.
- Set the Output directory to where you want the files to be created.
- Set the rest of the options as followed:

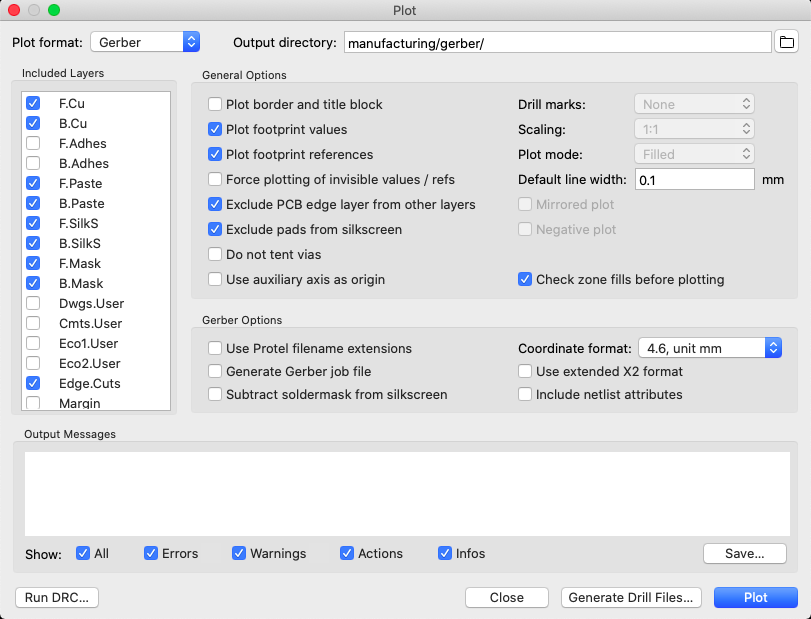
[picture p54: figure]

Figure 1

- Press “Plot”
- If you get asked to refill the zone-fills, because they are out of date, do so.
- KiCAD now generates all the gerber files and stores them in the above specified path.
- Now press “Generate Drill Files”
- Set the Output directory to where you want the files to be created.
- Set the rest of the options as followed:
- (Change Drill unit to Inches, if you need imperial measurements).

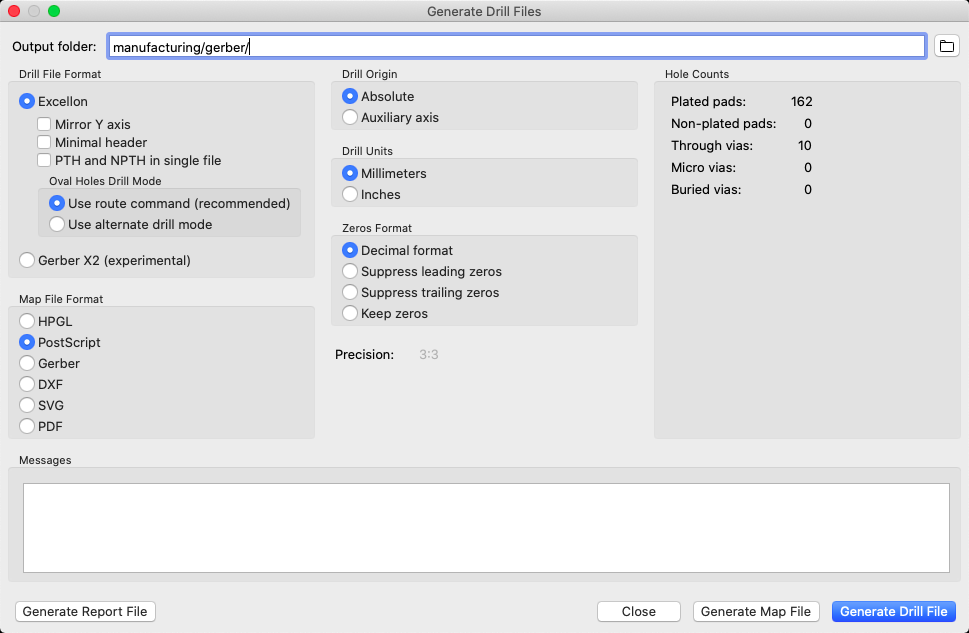
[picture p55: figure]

Figure 2

- KiCAD now generates the PTH and NPTH files and stores them in the above specified path.
- You should now have a full set of Gerber files, ready to send to a PCB manufacturer.

## Pick and Place Files

- To generate the pick and place data, select “File” -> “Fabrication Outputs” -> “Footprint Position (.pos) File”
- Set the Output directory to where you want the files to be created.
- Set the options as follows:
- (Change Units to Inches if you need imperial measurements).

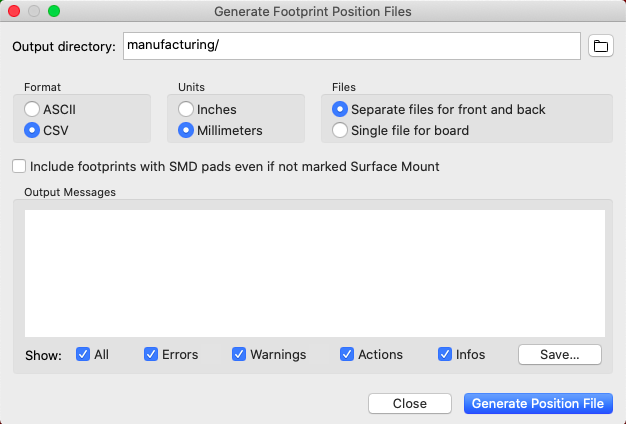
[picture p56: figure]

Figure 3

- Press “Generate Position Files”
- KiCAD now generates the Pick and Place files and stores them in the above specified path.

## BOM File

- Finally, to generate the BOM, select “File” -> “Fabrication Output” -> “BOM File”
- Select a location to save your BOM file and hit “Save”

# Addendum

- Depending on the manufacturer, you may have to change some titles in the Pick and Place files. For example, jlcpcb.com requires the titles to be “Designator”, “Mid X”, “Mid Y”, “Layer” and “Rotation”. You can open the *.csv files in every text editor. Or even better, in MS Excel. There you can change the tiles and save the file. The same may apply to the BOM.

- 2 of 4 – Document: Generating ECAD Manufacturing Files Version: 0.1 Author: Balz Reber Last Update: 06.11.2019

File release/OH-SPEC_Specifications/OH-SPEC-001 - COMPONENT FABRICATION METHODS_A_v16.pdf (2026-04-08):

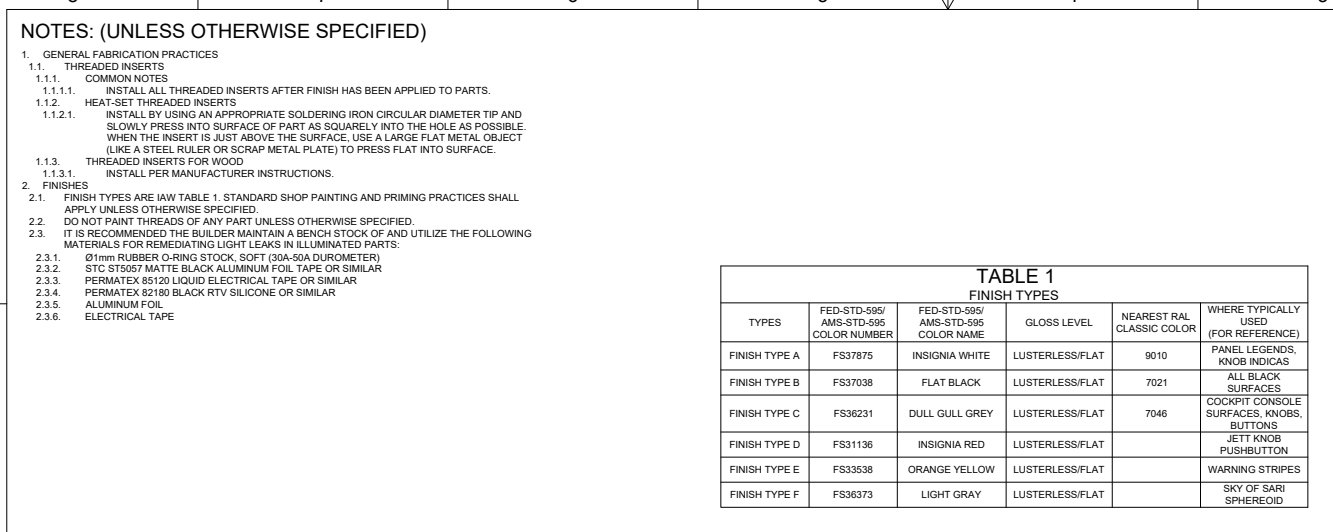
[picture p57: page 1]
J. STEENSEN 04/01/2022; COMPONENT FABRICATION; REVISION HISTORY; TABLE 1; FINISH TYPES

NOTES: (UNLESS OTHERWISE SPECIFIED)

REV | DESCRIPTION | DATE | APPROVED
- | INITIAL RELEASE | 04/01/2022
A | ADDED "ACRIFUX 1R0192 OR" TO ALL WELD-ON #4 CALLOUTS ON DOCUMENT. REWROTE NOTE 2 TO ADD TABLE 1 FOR FINISHES AND ADDRESS LIGHT LEAK MATERIALS. | 09/09/2024 | J. STEENSEN

1. GENERAL FABRICATION PRACTICES
1.1. THREADED INSERTS
1.1.1. COMMON NOTES
1.1.1.1. INSTALL ALL THREADED INSERTS AFTER FINISH HAS BEEN APPLIED TO PARTS.
1.1.2. HEAT-SET THREADED INSERTS
1.1.2.1. INSTALL BY USING AN APPROPRIATE SOLDERING IRON CIRCULAR DIAMETER TIP AND

SLOWLY PRESS INTO SURFACE OF PART AS SQUARELY INTO THE HOLE AS POSSIBLE.
WHEN THE INSERT IS JUST ABOVE THE SURFACE, USE A LARGE FLAT METAL OBJECT
(LIKE A STEEL RULER OR SCRAP METAL PLATE) TO PRESS FLAT INTO SURFACE.

1.1.3. THREADED INSERTS FOR WOOD
1.1.3.1. INSTALL PER MANUFACTURER INSTRUCTIONS.
2. FINISHES
2.1. FINISH TYPES ARE IAW TABLE 1. STANDARD SHOP PAINTING AND PRIMING PRACTICES SHALL

APPLY UNLESS OTHERWISE SPECIFIED.

2.2. DO NOT PAINT THREADS OF ANY PART UNLESS OTHERWISE SPECIFIED.
2.3. IT IS RECOMMENDED THE BUILDER MAINTAIN A BENCH STOCK OF AND UTILIZE THE FOLLOWING

MATERIALS FOR REMEDIATING LIGHT LEAKS IN ILLUMINATED PARTS:
2.3.1. Ø1mm RUBBER O-RING STOCK, SOFT (30A-50A DUROMETER)
2.3.2. STC ST5057 MATTE BLACK ALUMINUM FOIL TAPE OR SIMILAR
2.3.3. PERMATEX 85120 LIQUID ELECTRICAL TAPE OR SIMILAR
2.3.4. PERMATEX 82180 BLACK RTV SILICONE OR SIMILAR
2.3.5. ALUMINUM FOIL
2.3.6. ELECTRICAL TAPE

TYPES | FED-STD-595/ AMS-STD-595 COLOR NUMBER | FED-STD-595/ AMS-STD-595 COLOR NAME | GLOSS LEVEL | NEAREST RAL CLASSIC COLOR | WHERE TYPICALLY USED (FOR REFERENCE)

FINISH TYPE A | FS37875 | INSIGNIA WHITE | LUSTERLESS/FLAT | 9010 | PANEL LEGENDS, KNOB INDICAS

FINISH TYPE B | FS37038 | FLAT BLACK | LUSTERLESS/FLAT | 7021 | ALL BLACK SURFACES

FINISH TYPE C | FS36231 | DULL GULL GREY | LUSTERLESS/FLAT | 7046 | COCKPIT CONSOLE SURFACES, KNOBS, BUTTONS

FINISH TYPE D | FS31136 | INSIGNIA RED | LUSTERLESS/FLAT | | JETT KNOB PUSHBUTTON

FINISH TYPE E | FS33538 | ORANGE YELLOW | LUSTERLESS/FLAT | | WARNING STRIPES

FINISH TYPE F | FS36373 | LIGHT GRAY | LUSTERLESS/FLAT | | SKY OF SARI SPHEREOID

UNLESS OTHERWISE SPECIFIED: | UOS INCH TOLERANCES ARE: | https://www.OpenHornet.com
DIMENSIONS ARE IN INCHES. DUAL DIMENSIONS ARE IN MILIMETERS AND ENCLOSED IN SQUARE BRACKETS. INTERPRET DRAWING IAW ASME Y14.100-2017. INTERPRET DIM AND TOL IAW ASME Y14.5-2009. REMOVE ALL BURRS AND SHARP EDGES TO .05 MAX. DIMENSIONS APPLY BEFORE FINISH. | ANGLES: DECIMALS: MACHINED ± .5° .X ± .1 LOCATING ± .5° .XX ± .03 FORMED ± 2° .XXX ± .010 CHAMFERS ± 5° DRILLED HOLE DIAMETERS: .0135 - .125: +.004/-.001 .126 - .250: +.005/-.001 .251 - .500: +.006/-.001 .501 - .750: +.008/-.001 .751 - 1.000: +.010/-.001 1.001 - 2.000: +.012/-.001

J. STEENSEN 04/01/2023 DESIGNED | | SIZE D | DWG NO OH-SPEC-001 | REV A

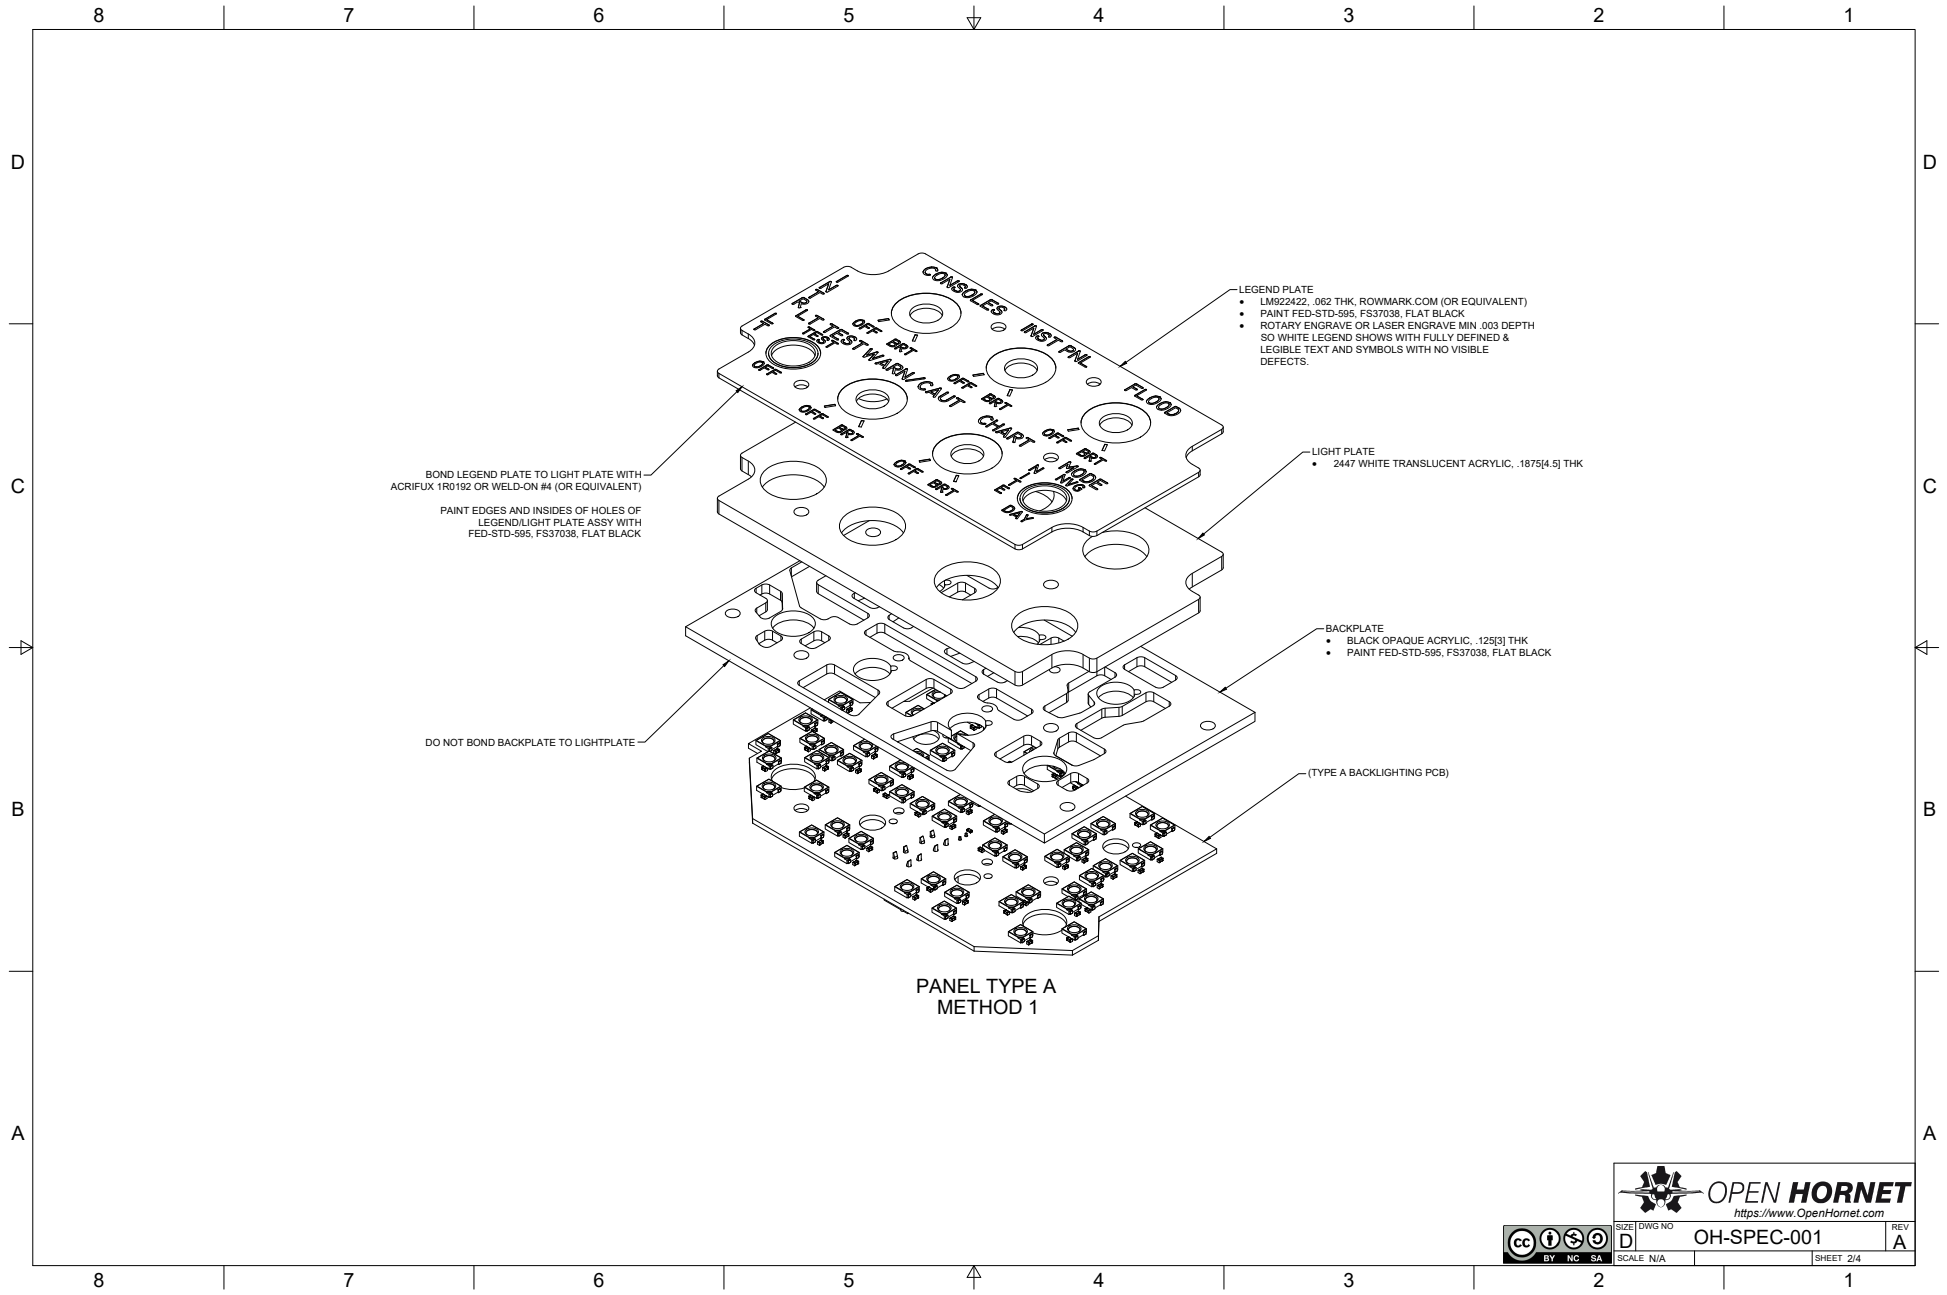
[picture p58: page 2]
PANEL TYPE A METHOD 1

LEGEND PLATE
· LM922422, .062 THK, ROWMARK.COM (OR EQUIVALENT)
· PAINT FED-STD-595, FS37038, FLAT BLACK
· ROTARY ENGRAVE OR LASER ENGRAVE MIN .003 DEPTH
SO WHITE LEGEND SHOWS WITH FULLY DEFINED &
LEGIBLE TEXT AND SYMBOLS WITH NO VISIBLE
DEFECTS.

LIGHT PLATE
· 2447 WHITE TRANSLUCENT ACRYLIC, .1875[4.5] THK

BOND LEGEND PLATE TO LIGHT PLATE WITH

ACRIFUX 1R0192 OR WELD-ON #4 (OR EQUIVALENT)

PAINT EDGES AND INSIDES OF HOLES OF

LEGEND/LIGHT PLATE ASSY WITH
FED-STD-595, FS37038, FLAT BLACK

BACKPLATE
· BLACK OPAQUE ACRYLIC, .125[3] THK

DO NOT BOND BACKPLATE TO LIGHTPLATE

(TYPE A BACKLIGHTING PCB)

https://www.OpenHornet.com

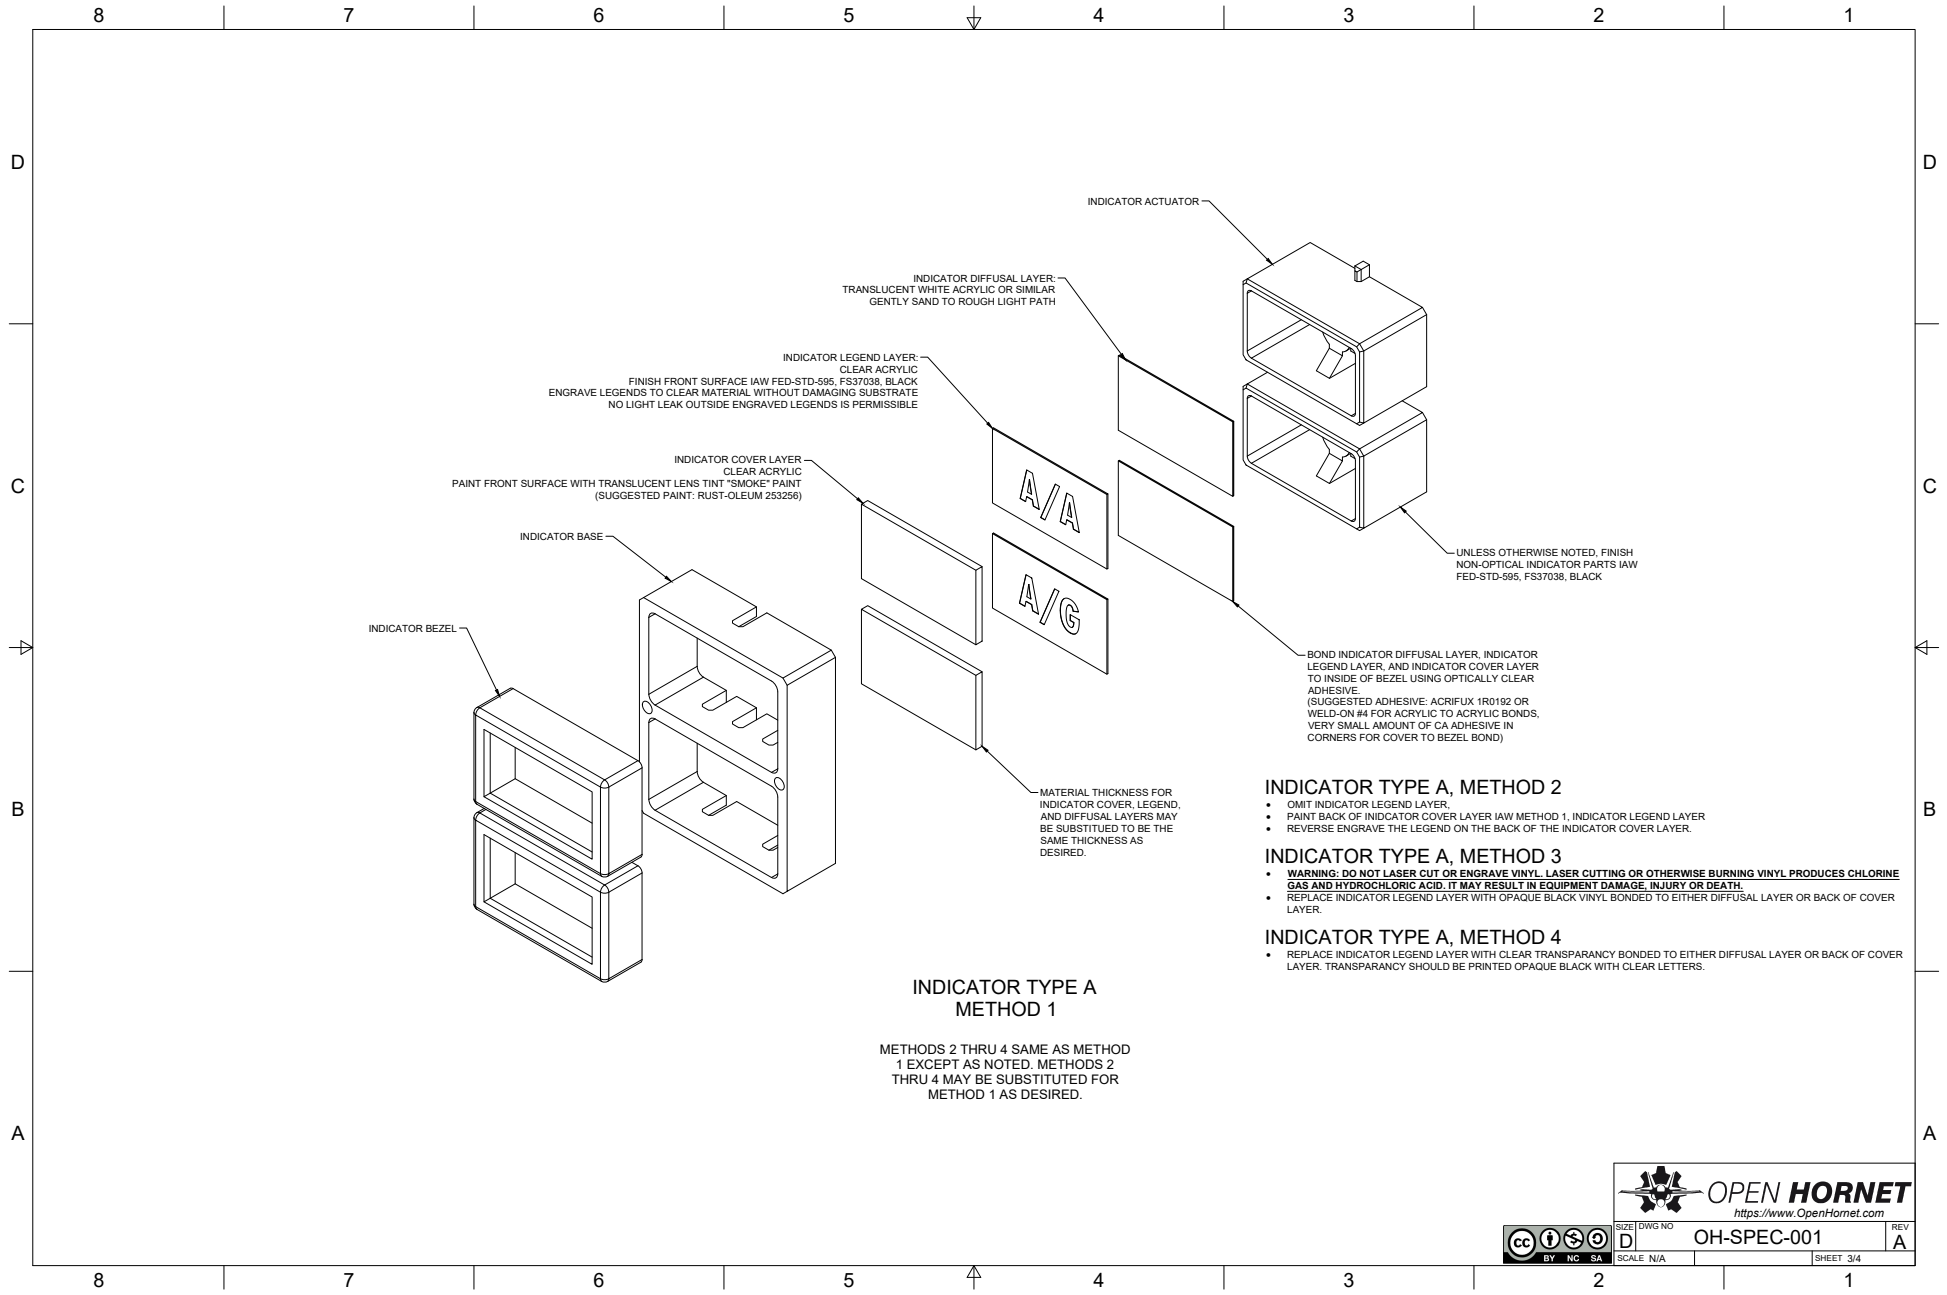
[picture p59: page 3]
INDICATOR TYPE A METHOD 1; CLEAR ACRYLIC; INDICATOR ACTUATOR; INDICATOR BASE; INDICATOR BEZEL

INDICATOR DIFFUSAL LAYER:

TRANSLUCENT WHITE ACRYLIC OR SIMILAR
GENTLY SAND TO ROUGH LIGHT PATH

INDICATOR LEGEND LAYER:

FINISH FRONT SURFACE IAW FED-STD-595, FS37038, BLACK

ENGRAVE LEGENDS TO CLEAR MATERIAL WITHOUT DAMAGING SUBSTRATE

NO LIGHT LEAK OUTSIDE ENGRAVED LEGENDS IS PERMISSIBLE

INDICATOR COVER LAYER

PAINT FRONT SURFACE WITH TRANSLUCENT LENS TINT "SMOKE" PAINT

(SUGGESTED PAINT: RUST-OLEUM 253256)

UNLESS OTHERWISE NOTED, FINISH
NON-OPTICAL INDICATOR PARTS IAW
FED-STD-595, FS37038, BLACK

BOND INDICATOR DIFFUSAL LAYER, INDICATOR
LEGEND LAYER, AND INDICATOR COVER LAYER
TO INSIDE OF BEZEL USING OPTICALLY CLEAR
ADHESIVE.
(SUGGESTED ADHESIVE: ACRIFUX 1R0192 OR
WELD-ON #4 FOR ACRYLIC TO ACRYLIC BONDS,
VERY SMALL AMOUNT OF CA ADHESIVE IN
CORNERS FOR COVER TO BEZEL BOND)

INDICATOR TYPE A, METHOD 2

MATERIAL THICKNESS FOR
INDICATOR COVER, LEGEND,
AND DIFFUSAL LAYERS MAY
BE SUBSTITUED TO BE THE
SAME THICKNESS AS
DESIRED.

· OMIT INDICATOR LEGEND LAYER,
· PAINT BACK OF INIDCATOR COVER LAYER IAW METHOD 1, INDICATOR LEGEND LAYER
· REVERSE ENGRAVE THE LEGEND ON THE BACK OF THE INDICATOR COVER LAYER.
INDICATOR TYPE A, METHOD 3

· WARNING: DO NOT LASER CUT OR ENGRAVE VINYL. LASER CUTTING OR OTHERWISE BURNING VINYL PRODUCES CHLORINE
GAS AND HYDROCHLORIC ACID. IT MAY RESULT IN EQUIPMENT DAMAGE, INJURY OR DEATH.
· REPLACE INDICATOR LEGEND LAYER WITH OPAQUE BLACK VINYL BONDED TO EITHER DIFFUSAL LAYER OR BACK OF COVER
LAYER.
INDICATOR TYPE A, METHOD 4

· REPLACE INDICATOR LEGEND LAYER WITH CLEAR TRANSPARANCY BONDED TO EITHER DIFFUSAL LAYER OR BACK OF COVER
LAYER. TRANSPARANCY SHOULD BE PRINTED OPAQUE BLACK WITH CLEAR LETTERS.

METHODS 2 THRU 4 SAME AS METHOD
1 EXCEPT AS NOTED. METHODS 2
THRU 4 MAY BE SUBSTITUTED FOR
METHOD 1 AS DESIRED.

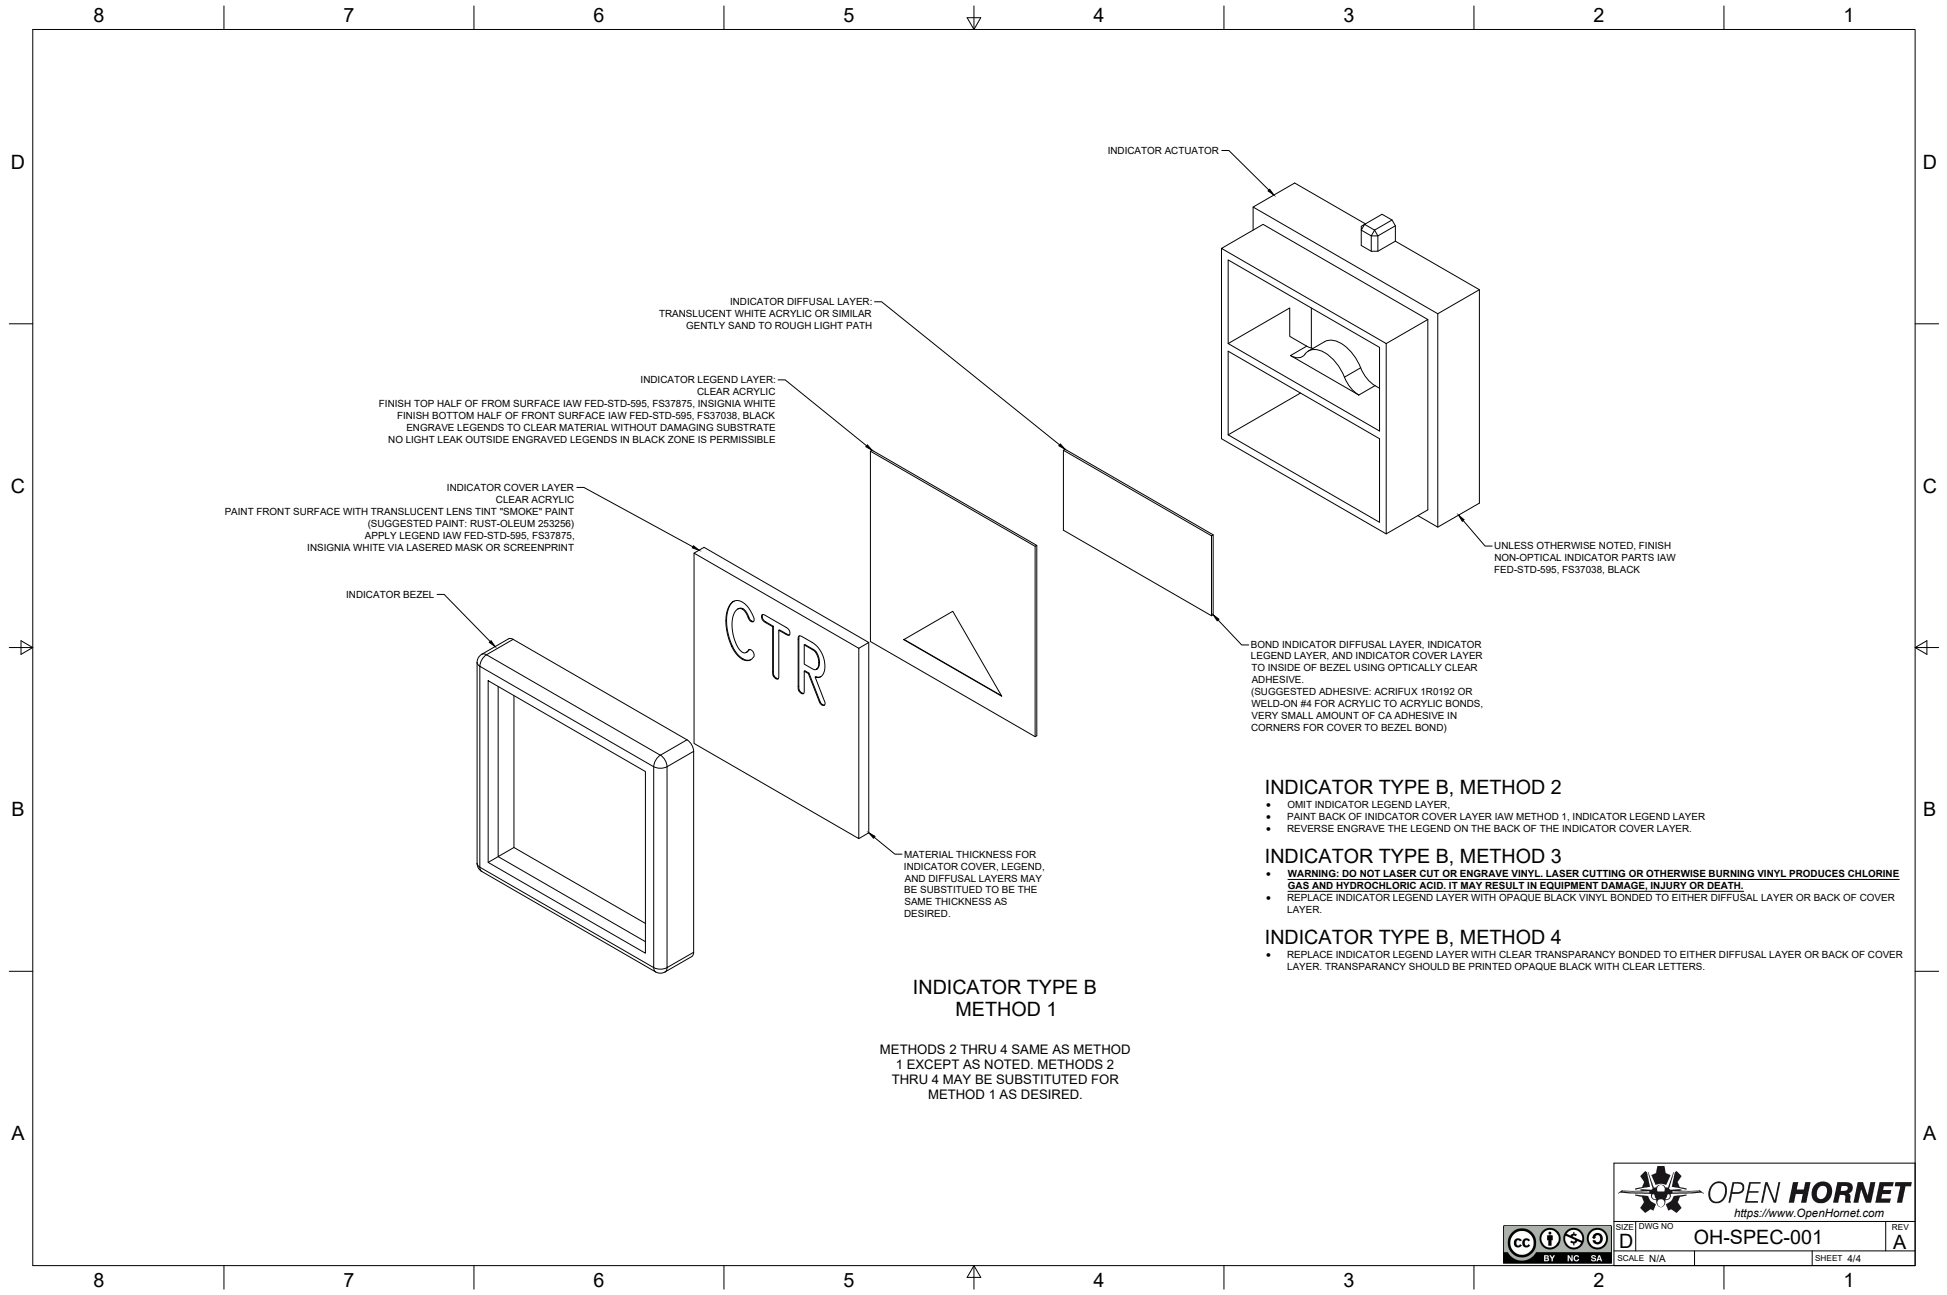
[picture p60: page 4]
INDICATOR TYPE B METHOD 1; CLEAR ACRYLIC; INSIGNIA WHITE VIA LASERED MASK OR SCREENPRINT; UNLESS OTHERWISE NOTED, FINISH; INDICATOR ACTUATOR; INDICATOR BEZEL

INDICATOR DIFFUSAL LAYER:

TRANSLUCENT WHITE ACRYLIC OR SIMILAR
GENTLY SAND TO ROUGH LIGHT PATH

INDICATOR LEGEND LAYER:

FINISH TOP HALF OF FROM SURFACE IAW FED-STD-595, FS37875, INSIGNIA WHITE
FINISH BOTTOM HALF OF FRONT SURFACE IAW FED-STD-595, FS37038, BLACK
ENGRAVE LEGENDS TO CLEAR MATERIAL WITHOUT DAMAGING SUBSTRATE
NO LIGHT LEAK OUTSIDE ENGRAVED LEGENDS IN BLACK ZONE IS PERMISSIBLE

INDICATOR COVER LAYER

PAINT FRONT SURFACE WITH TRANSLUCENT LENS TINT "SMOKE" PAINT

(SUGGESTED PAINT: RUST-OLEUM 253256)
APPLY LEGEND IAW FED-STD-595, FS37875,

NON-OPTICAL INDICATOR PARTS IAW
FED-STD-595, FS37038, BLACK

BOND INDICATOR DIFFUSAL LAYER, INDICATOR
LEGEND LAYER, AND INDICATOR COVER LAYER
TO INSIDE OF BEZEL USING OPTICALLY CLEAR
ADHESIVE.
(SUGGESTED ADHESIVE: ACRIFUX 1R0192 OR
WELD-ON #4 FOR ACRYLIC TO ACRYLIC BONDS,
VERY SMALL AMOUNT OF CA ADHESIVE IN
CORNERS FOR COVER TO BEZEL BOND)

INDICATOR TYPE B, METHOD 2

· OMIT INDICATOR LEGEND LAYER,
· PAINT BACK OF INIDCATOR COVER LAYER IAW METHOD 1, INDICATOR LEGEND LAYER
· REVERSE ENGRAVE THE LEGEND ON THE BACK OF THE INDICATOR COVER LAYER.
INDICATOR TYPE B, METHOD 3

MATERIAL THICKNESS FOR
INDICATOR COVER, LEGEND,
AND DIFFUSAL LAYERS MAY
BE SUBSTITUED TO BE THE
SAME THICKNESS AS
DESIRED.

· WARNING: DO NOT LASER CUT OR ENGRAVE VINYL. LASER CUTTING OR OTHERWISE BURNING VINYL PRODUCES CHLORINE
GAS AND HYDROCHLORIC ACID. IT MAY RESULT IN EQUIPMENT DAMAGE, INJURY OR DEATH.
· REPLACE INDICATOR LEGEND LAYER WITH OPAQUE BLACK VINYL BONDED TO EITHER DIFFUSAL LAYER OR BACK OF COVER
LAYER.
INDICATOR TYPE B, METHOD 4

· REPLACE INDICATOR LEGEND LAYER WITH CLEAR TRANSPARANCY BONDED TO EITHER DIFFUSAL LAYER OR BACK OF COVER
LAYER. TRANSPARANCY SHOULD BE PRINTED OPAQUE BLACK WITH CLEAR LETTERS.

METHODS 2 THRU 4 SAME AS METHOD
1 EXCEPT AS NOTED. METHODS 2
THRU 4 MAY BE SUBSTITUTED FOR
METHOD 1 AS DESIRED.

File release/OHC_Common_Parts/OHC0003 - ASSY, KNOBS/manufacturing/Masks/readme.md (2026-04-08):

# Masks file name abbreviations

To navigate within the Masks directory, you'll need to start by identifying the OH Part Number (PN) of the knobs you're seeking the mask for. Once you have the OH Part Number (PN) in hand, locate the corresponding subfolder within the Masks directory that contains this part number in its name.
For further clarification, the abbreviations used in file names are explained below.

### MASK_PN_PL.svg
- **Pointer Line**: This is the 2D mask for the pointer line (white)
### MASK_PN_I.svg
- **Indica**: This is the 2D mask for the indica that goes arround the pointer line (black)
### MASK_PN_PLI.svg
- **Pointer Line with Indica**: This is the 2D mask for both the indica and the pointer line
### MASK_PN_BTM.svg
- **Bottom**: This is the 2D mask for the bottom of the knob
### MASK_PN_BTMP.svg
- **Bottom Pull**: This is the 2D mask for the bottom of the knob with an extra pull tab to make removal of the mask easier
### MASK_PN_PLLS.svg
- **Pointer Line Left Side**: This is the 2D mask for the left side of the pointer line (white)
- **It is only used on knob**: OHC0003-A-4RUDGB3
### MASK_PN_PLRS.svg
- **Pointer Line Right Side**: This is the 2D mask for the right side of the pointer line (white)
- **It is only used on knob**: OHC0003-A-4RUDGB3
### MASK_PN_PLF.svg
- **Pointer Line Front**: This is the 2D mask for the front pointer line, it is the same as MASK_PN_PL (white)
- **It is only used on knob**: OHC0003-A-4RUDGB3
### MASK_PN_IL.svg
- **Indica Left**: This is the 2D mask for the left indica (black)
- **It is only used on knob**: OHC0003-A-4RUDGB3
### MASK_PN_IR.svg
- **Indica Right**: This is the 2D mask for the right indica (black)
- **It is only used on knob**: OHC0003-A-4RUDGB3
### MASK_PN_IFL.svg
- **Indica Full Left**: This is the 2D mask for the full left indica, this mask match the real knob used in the F/A-18C OFP 13C (black)
- **It is only used on knob**: OHC0003-A-4RUDGB3
### MASK_PN_IFR.svg
- **Indica Full Right**: This is the 2D mask for the full right indica, this mask match the real knob used in the F/A-18C OFP 13C (black)
- **It is only used on knob**: OHC0003-A-4RUDGB3
### MASK_PN_Plug.svg
- **Plug**: This is the 2D mask for the hole on the top of the knob (white)
- **It is only used on knob**: OHC0003-A-028ABW2
### MASK_PN_Plug.3mf
- **Plug**: This is the 3D model for the hole on the top of the knob (white)
- **It is only used on knob**: OHC0003-A-028ABW2
### MASK_PN_Plug_TOL(1 to 3).3mf
- **Plug**: This is the 3D model with a smaller diameter for the hole on the top of the knob (white)
- **The greater the number the smaller the diameter**: MASK_PN_Plug_TOL2.3mf is smaller than MASK_PN_Plug_TOL1.3mf
- **It is only used on knob**: OHC0003-A-028ABW2

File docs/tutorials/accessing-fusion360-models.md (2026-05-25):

# Download and Import Fusion 360 Models

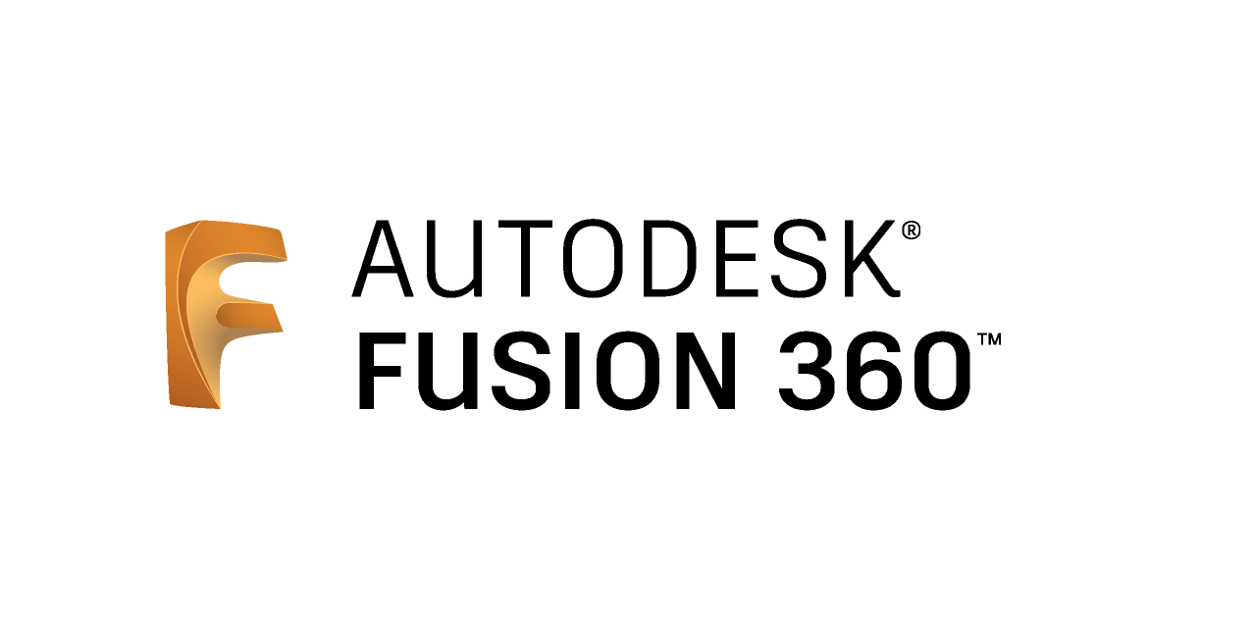
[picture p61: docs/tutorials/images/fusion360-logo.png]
Autodesk Fusion 360 logo


Do you need to download the OpenHornet Fusion 360 models to modify something, make non-standard manufacturing files, or just look at something from a different angle than the drawings in the build package show? This tutorial walks through importing the OpenHornet models into a personal installation of Autodesk Fusion 360.

If you do not yet have Fusion 360 registered and installed on your computer, start at [Step 1: Download Fusion 360](#step-1-download-fusion-360). If Fusion 360 is already installed and registered, skip to [Step 2: Download OpenHornet Models](#step-2-download-openhornet-models).

For help along the way, ask in the `#fusion360` channel on the OpenHornet Discord server.

> Credits: jkkicks for the initial writeup, Sandra for the GitHub markup conversion and initial editing.

## Step 1: Download Fusion 360

1. All MCAD files for the OpenHornet project are currently managed through Autodesk Fusion 360. If you do not already have a license, go to the [Autodesk Fusion 360 personal use page](https://www.autodesk.com/products/fusion-360/personal).
2. Scroll down on the page and click **Get Started**. See Figure 1.
3. Fill out the form on the next page to register your account for the personal use version. See Figure 2.
4. After clicking **Next**, a download page will appear. Click the download link.
5. Once the Fusion 360 installer has finished downloading, run the installer and follow the on-screen instructions to finish downloading and installing Fusion 360 for personal use.

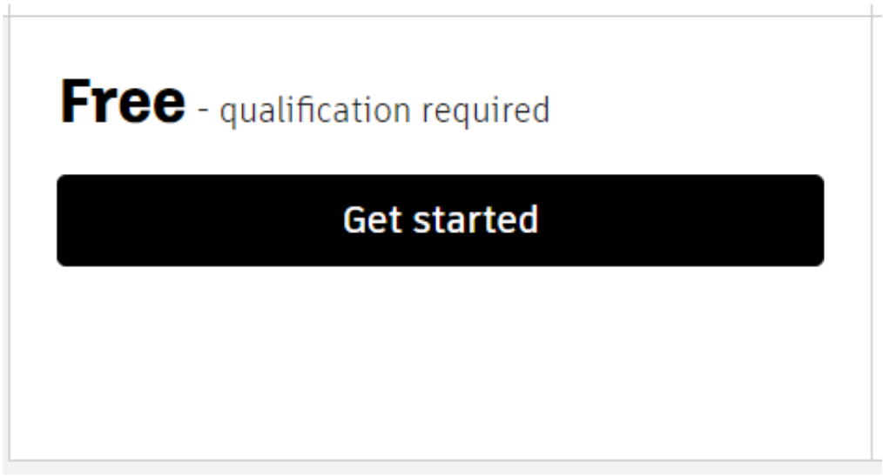
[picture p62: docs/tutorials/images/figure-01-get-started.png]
Figure 1 - Get Started


*Figure 1 - Get Started*

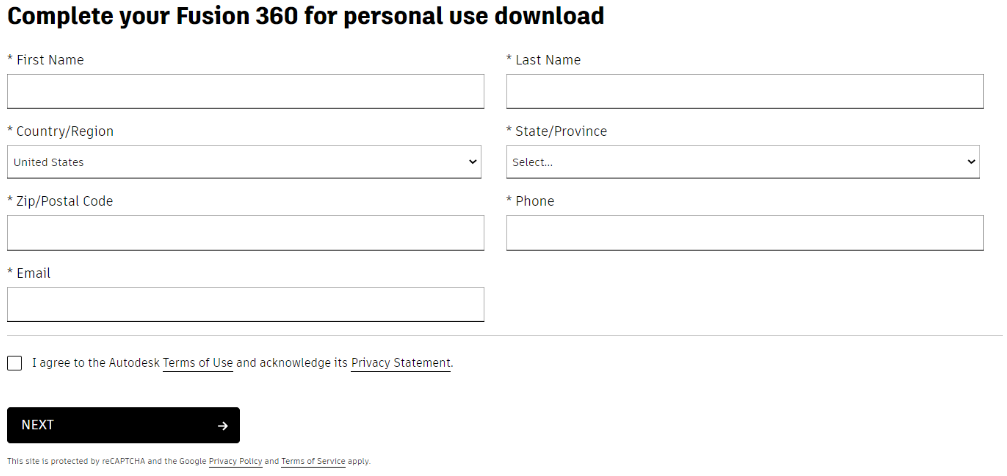
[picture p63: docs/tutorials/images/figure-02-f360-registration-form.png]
Figure 2 - F360 Registration Form


*Figure 2 - F360 Registration Form*

## Step 2: Download OpenHornet Models

The OpenHornet CAD models can be imported into Fusion 360 directly from the [OpenHornet GitHub repository](https://github.com/jrsteensen/OpenHornet). Scroll down on the repository main page until the Fusion 360 model links are displayed.

Figure 3 - Fusion360 Model Links

*Figure 3 - Fusion360 Model Links*

Each link contains the required models for a major portion of the current project version. The models are split into the following subgroups:

| Model / Assembly | Description |
| --- | --- |
| Top Level | Complete top level assembly for OpenHornet. |
| Upper Instrument Panel (UIP) | Models for the UIP. |
| Lower Instrument Panel (LIP) | Models for the LIP. |
| Left Console (LC) | Models for the LC. |
| Right Console (RC) | Models for the RC. |
| Center Tub (CT) | Models for the CT. |

Clicking one of these links will take you to an Autodesk Fusion archive page. Some pages, especially the Top Level model, may have trouble loading or may show an error outright. This is normal for a project of this size and is a Fusion 360 limitation, not an OpenHornet limitation. See Figure 4.

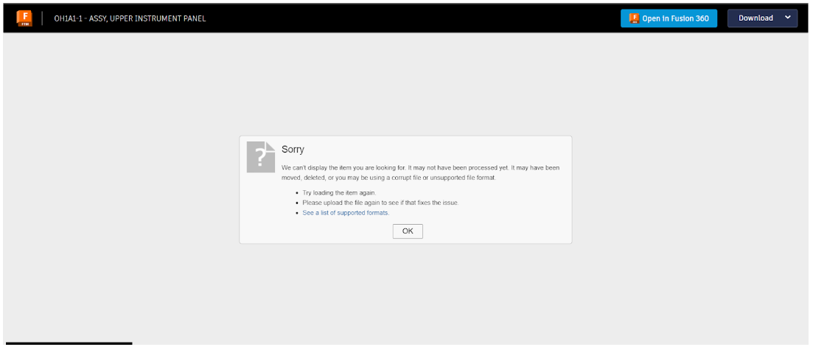
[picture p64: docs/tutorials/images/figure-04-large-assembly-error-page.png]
Figure 4 - Large Assembly Error Page in A360 Web Interface


*Figure 4 - Large Assembly Error Page in A360 Web Interface*

Click **Open in Fusion 360** in the top right of the web interface.

Be patient. The site may show another error stating **Fusion 360 not detected**. This is usually caused by the browser not being able to detect the new installation. You can open Fusion 360 in the background or try another browser. If the problem persists, ask in the `#fusion360` channel on the OpenHornet Discord server.

Once the files are transferred to your Fusion 360 installation, a pop-up window will ask where you would like to upload the models in your personal account.

It is recommended that you create a dedicated **Project** to store all the models, with an individual folder for each OpenHornet assembly. You can create projects and folders by clicking **Change Location** near the bottom of the screen.

> We recommend not naming the project `OpenHornet` in case you later become an OpenHornet contributor. That helps avoid confusion or conflicts with direct access to the official project.

## Alternate Download Method: `.f3z` Archive File

1. The models can also be downloaded as a Fusion 360 archive file (`.f3z`). Click **Download** in the top right corner of the website and select **Fusion 360 Archive**.
2. Once again, patience is key. The `.f3z` file will be compiled and emailed to the supplied email address. After downloading it to your computer, import it into Fusion 360 by clicking the file icon in the top right corner of the Fusion 360 application, then clicking **Upload...**.
3. When the **Upload** window opens, select the newly downloaded `.f3z` file, designate a project and folder, then click **Upload**. The window may need to be moved so the **Upload** button at the bottom is visible.

Either upload process can take anywhere from 5 minutes to 2 hours from start to finish, depending on your internet connection and the specific assembly model being uploaded. Fusion 360 may also be unresponsive while showing no indication that it is doing anything. This is a Fusion 360 issue, not an OpenHornet issue.

If the Fusion 360 window shows **Not Responding** and the mouse cursor is spinning, that is normal. Grab a coffee. It might be a short while. It is probably going to be a long while, but we are trying to make you feel better.

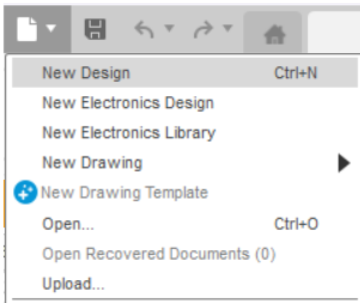
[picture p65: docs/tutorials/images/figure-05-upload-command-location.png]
Figure 5 - Upload Command location in F360


*Figure 5 - Upload Command location in F360*

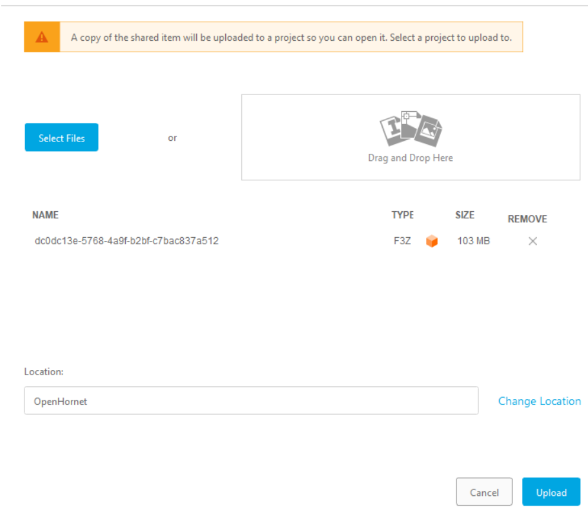
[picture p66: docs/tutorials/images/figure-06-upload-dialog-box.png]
Figure 6 - Upload Dialog Box


*Figure 6 - Upload Dialog Box*

Eventually, a **Job Status** window will appear, showing the current upload progress for each individual model in the assembly. This is the part that takes the longest. Patience is key.

## Publishing Notes

This Markdown version was prepared for migration from the OpenHornet website to GitHub. Image links are relative and intended to work when this file and the `images/` folder are committed together.

The original website page exposes the article text and the main Fusion 360 logo image through the accessible page view. The six inline figure screenshots were represented in the accessible output only by their captions, so placeholder SVG files were included with the correct filenames and captions. Replace those six SVG placeholders with the original screenshots before publishing.

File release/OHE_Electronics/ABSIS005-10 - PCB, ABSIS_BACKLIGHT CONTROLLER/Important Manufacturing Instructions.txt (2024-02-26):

1:  Each layer requires a 2oz Copper Pour.
2:  There are only 2 layers.

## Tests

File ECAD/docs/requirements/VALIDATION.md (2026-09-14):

# Deterministic validation and review evidence

## Basis

Owner-directed workflow and [KiCad 10 CLI](https://docs.kicad.org/10.0/en/cli/cli.html), plus existing project exclusions and ignored rule categories. These gates and evidence requirements are **adopted project policy under PR #1255**. Adopting these requirements did not run ERC/DRC or certify the current boards.

## Required checks

- **VAL-001:** Capture a baseline before significant edits and rerun checks after the final saved change. ERC MUST cover the complete affected schematic hierarchy. DRC MUST cover each affected board under its actual project constraints.
- **VAL-002:** Before final DRC, refill all copper zones. Save the reviewed/refilled board state before generating outputs. Revalidate if subsequent changes affect connectivity, geometry, constraints or manufacturing data.
- **VAL-003:** PCB validation MUST include schematic parity and unrouted-connection checks where a schematic exists. Verify component/footprint correspondence, net assignments, DNP/assembly variants and intentional unmatched mechanical items. A board-only template or harness schematic MAY mark a check not applicable with a reason; inability to locate a mismatched-case file is not a legitimate N/A.
- **VAL-004:** For a complete board, there MUST be no unintended unrouted connections, shorts, missing components or pin/pad mismatches. Mechanical-only footprints and intentionally unused electrical pins require explicit representation and review.
- **VAL-005:** Review warnings, errors, excluded findings and ignored rule categories. An agent MUST NOT suppress, exclude, lower severity, relax a rule or add a no-connect solely to make a report clean. Every exception requires GOV-007 disposition. Existing exclusions MUST be assessed in the affected scope rather than blindly copied or removed.
- **VAL-006:** Retain full machine-readable reports where supported and a concise summary of changes from baseline. Record checks that could not run and why. Return codes alone MUST NOT substitute for report review or proof that the intended rules and libraries loaded.
- **VAL-007:** Human review MUST inspect schematic pages, critical routing/return/protection regions, mechanical fit and exact component mapping. Passing ERC/DRC proves neither electrical function nor production qualification.
- **VAL-008:** If a pre-existing violation is outside the change scope, record it with an owner disposition and bounded impact assessment. A scoped development PR MAY proceed with disclosed failures; manufacturing or release gates MUST remain pending when an unresolved failure affects their evidence.

## KiCad 10 check pattern

The following is a documented pattern, not a script executed by this PR. Substitute real project paths and use a report directory outside committed source. First inspect the installed version and subcommand help. Set the actual root schematic and matching project before running parity, especially for IFEI and UTIL_PHOTOSWITCH.

```sh
kicad-cli version
kicad-cli sch erc --help
kicad-cli pcb drc --help
kicad-cli sch erc --format json --severity-all --exit-code-violations \
  --output "$report_dir/erc.json" "$root_schematic"
kicad-cli pcb drc --format json --severity-all --schematic-parity \
  --refill-zones --exit-code-violations \
  --output "$report_dir/drc.json" "$board_file"
```

The DRC command above refills in memory and does not save the board. Save the final refill through KiCad before output generation, or intentionally use the supported `--save-board` option and review the resulting diff. Preserve the same source/rule state for final reports and exports. `--save-board` is a mutation, not an audit operation. AI use remains subject to FLOW-003's approved semantic write boundary; the CLI example does not authorize an alternate write path. Excluded findings can make an all-severity report nonzero; disposition them explicitly, without claiming the run was clean.

## Check matrix

| Change | Minimum relevant checks |
| --- | --- |
| Significant schematic or component change | ERC, datasheet/mapping review, PCB parity and DRC after synchronization, affected functional analysis |
| Significant layout/stack/outline change | Refill, DRC, parity, unrouted, current/return and mechanical review, refreshed CAM review |
| Shared symbol/footprint change | Identify consumers; repeat applicable ERC/parity/DRC and package/assembly review for affected designs |
| Harness/interface change | Full affected hierarchy ERC plus endpoint pin mapping, continuity, ratings and connected-board review |
| Manufacturing/BOM/CPL change | Source identity, exact MPN/variant reconciliation and actual output/supplier-placement review |
| Documentation-only framework | Path/link/Markdown checks, consistency review and proof ECAD sources remain unchanged |

## Metadata and final integration

- **VAL-009:** Independently reconcile exact part identities and supplier fields across schematic, PCB, master BOM and supplier BOM. Include legacy field aliases such as `Manufacturer PN` and `Manufacturer_Part_Number`; conflicting nonempty values require disposition. Do not assume ERC/DRC or schematic parity checks every procurement field. Footprint names and geometry alone do not identify the assembled part.
- **VAL-010:** Before manufacturing approval or release qualification, verify that reviewed evidence still applies to the final integrated source and resolved libraries. If a rebase, conflict resolution, shared-library update or later edit changes an input to a check, repeat that check and affected output review. An unrelated documentation-only change need not trigger hardware testing. Record unchanged source hashes or a bounded impact analysis when carrying results forward.

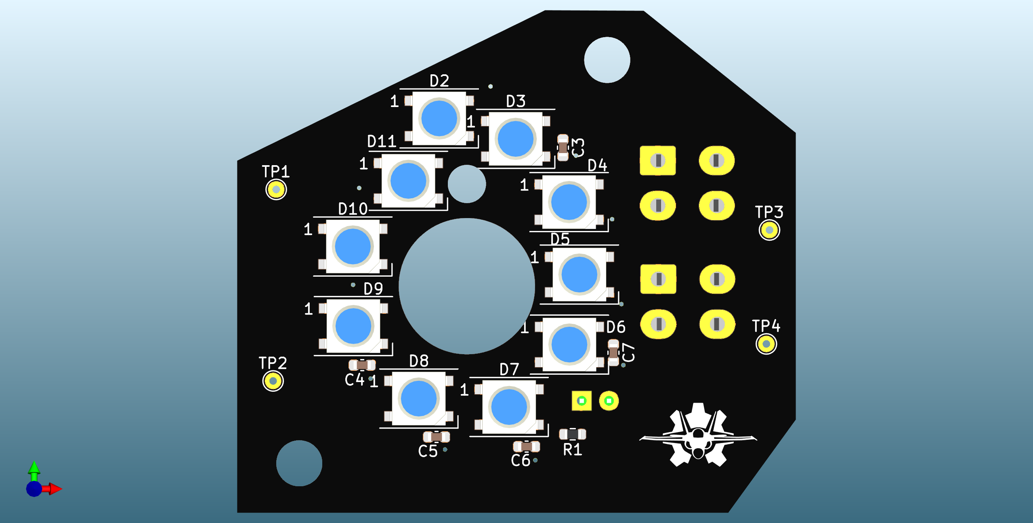
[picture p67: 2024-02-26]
ECAD/PCBs/Backlight PCBs/Backlighting_Type A/FIRE TEST PANEL/Assets/FIRE TEST PANEL-TOP.png

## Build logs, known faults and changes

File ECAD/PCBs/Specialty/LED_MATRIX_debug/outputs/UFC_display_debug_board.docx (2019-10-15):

# UFC display debug board

## Operation

The following board is designed to help with debugging control of the LED matrices and the OLED display used on the UFC board.

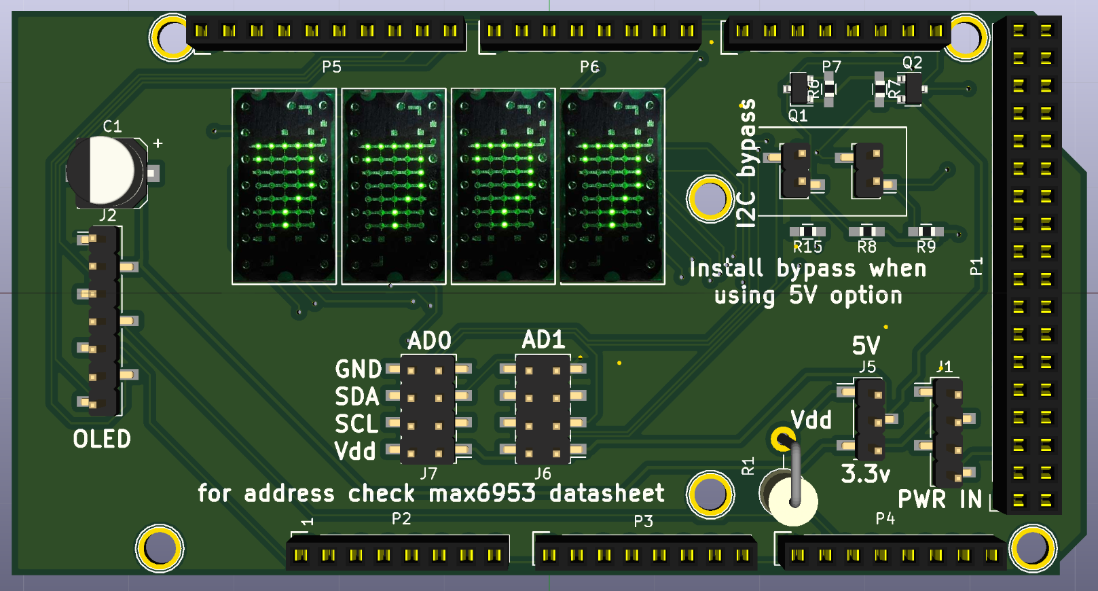
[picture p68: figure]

IMPORTANT: Mandatory jumper installation

In order to operate the board, before first power on the jumpers on J5, J6, and J7 MUST be installed accordingly.

## Power options

### 5V option

The board was designed to connect and be powered by the Arduino Mega board, In order to use the Arduino mega board only the 5v option needs to be selected on J5, I2C bypasses need to be installed and the AD0 and AD1 jumpers must be populated. This option has limitations since the matrices can draw up to 0.5A from the power supply.

The OLED display CANNOT be powered this way

Figure 1: 5V/Arduino powered operation

### 3.3v option (preferred)

The best way to power up the board is by using the 3.3v option, for this the PWR in connector MUST be plugged, this connector can also be used to provide a +12v power source for the Arduino.

When using 3.3v the jumpers for I2C bypass should be open (no jumper installed).

Figure 2: preferred mode of operation

## MAX6953 Address selection

In order to use the LED matrices the MAX6953 MUST be addressable, the jumpers on connectors J7 and L6 MUST be populated, and not installing the jumpers will cause undefined behavior.

PIN | | Device Address
AD0 | AD1 | A6 | A5 | A4 | A3 | A2 | A1 | A0
GND | GND | 1 | 0 | 1 | 0 | 0 | 0 | 0
V+ | GND | 1 | 0 | 1 | 0 | 0 | 0 | 1
SDA | GND | 1 | 0 | 1 | 0 | 0 | 1 | 0
SCL | GND | 1 | 0 | 1 | 0 | 0 | 1 | 1
GND | V+ | 1 | 0 | 1 | 0 | 1 | 0 | 0
V+ | V+ | 1 | 0 | 1 | 0 | 1 | 0 | 1
SDA | V+ | 1 | 0 | 1 | 0 | 1 | 1 | 0
SCL | V+ | 1 | 0 | 1 | 0 | 1 | 1 | 1
GND | SDA | 1 | 0 | 1 | 1 | 0 | 0 | 0
V+ | SDA | 1 | 0 | 1 | 1 | 0 | 0 | 1
SDA | SDA | 1 | 0 | 1 | 1 | 0 | 1 | 0
SCL | SDA | 1 | 0 | 1 | 1 | 0 | 1 | 1
GND | SCL | 1 | 0 | 1 | 1 | 1 | 0 | 0
V+ | SCL | 1 | 0 | 1 | 1 | 1 | 0 | 1
SDA | SCL | 1 | 0 | 1 | 1 | 1 | 1 | 0
SCL | SCL | 1 | 0 | 1 | 1 | 1 | 1 | 1

### OLED operation

The only requirement to operate the OLED display is to connect the external power, the OLED display requires 3.3v, this voltage is NOT obtained from the Arduino board.

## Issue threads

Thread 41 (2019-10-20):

DDI/AMPCD Arduino Shield

jrsteensen, 2019-10-20:
- [ ] Requirements definition
- [x] Schematic completed
- [x] PCB routed
- [x] Schematic/PCB reviewed
- [x] BOM generated
- [x] Gerbers generated
- [x] MCAD generated

amanuense, 2019-10-23:
found we are missing a pullup for the IRQ line. we are also missing bypass caps for the ICs

amanuense, 2019-10-23:
missing rotaty switch, created issue #52 to track this separately

jrsteensen, 2019-10-23:
> found we are missing a pullup for the IRQ line. we are also missing bypass caps for the ICs

This references the DDI and AMPCD bezel (#32, #33) not this issue.

jrsteensen, 2019-10-23:
> missing rotary switch, created issue #52 to track this separately

TODO for this PCB:

- [ ] Remove 1x POT connector
- [ ] Add 4 pin connector for DDI rotary (3 DI + GND)
- [ ] Add 2x 3 pin connector (2 DDI + GND) for AMPCD HDG/CRS toggles
- [ ] Fix i2c addressing.

jrsteensen, 2019-10-24:
Bug fixed with PRs #54 and #55. Ready for review, Gerber generation, and MCAD generation.

jrsteensen, 2019-10-29:
Completed in PR #64.

Closed 2019-10-29.

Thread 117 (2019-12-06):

UFC 3.0 PCB

jrsteensen, 2019-12-06:
- [x] Requirements definition
- [x] Schematic completed
- [ ] PCB routed
- [ ] Schematic/PCB reviewed
- [ ] BOM generated
- [ ] Gerbers generated
- [ ] MCAD generated

jrsteensen, 2019-12-06:
# UFC 2.0 Requirements

1. MEGA Shield (SMD headers on back)
1. OH Standard PWR Header (4 Pin Polarized SMD Header)
1. INPUTS:
    1. Snap Dome Switches (GX06400)
        1. 1, 2, 3, OPT 2
		1. 4, 5, 6, OPT 3
		1. 7, 8, 9, OPT 4
		1. CLR, 0, ENT, OPT 5
		1. OPT 1
		1. I/P
		1. EMCON
    1. Encoders with Pushbutton (PEC11R-4220F-S0012)
        1. COMM 1
        1. COMM 2
    1. Potentiometers (P0915N-FC20BR10K)
	    1. BRT
		1. COMM 1
		1. COMM 2
	1. TOGGLE, 3 POS (100SP3T2B3M2RE)
	    1. ADF
1. OUTPUTS
    1. Scratchpad (ER-OLEDM023-1W OLED Display)
	1. OPT Line 1
		1. 4x DIY 16 seg displays (64x 16-219A/T2D-AR2T1QY/3T)
		2. Option Indicator (2x 16-219A/T2D-AR2T1QY/3T) - controlled by digit 1 & 2 DP on MAX6955?)
	1. OPT Line 2
		1. 4x DIY 16 seg displays (64x 16-219A/T2D-AR2T1QY/3T)
		2. Option Indicator (2x 16-219A/T2D-AR2T1QY/3T) - controlled by digit 1 & 2 DP on MAX6955?)
	1. OPT Line 3
		1. 4x DIY 16 seg displays (64x 16-219A/T2D-AR2T1QY/3T)
		2. Option Indicator (2x 16-219A/T2D-AR2T1QY/3T) - controlled by digit 1 & 2 DP on MAX6955?)
	1. OPT Line 4
		1. 4x DIY 16 seg displays (64x 16-219A/T2D-AR2T1QY/3T)
		2. Option Indicator (2x 16-219A/T2D-AR2T1QY/3T) - controlled by digit 1 & 2 DP on MAX6955?)
	1. OPT Line 5
		1. 4x DIY 16 seg displays (64x 16-219A/T2D-AR2T1QY/3T)
		2. Option Indicator (2x 16-219A/T2D-AR2T1QY/3T) - controlled by digit 1 & 2 DP on MAX6955?)
	1. COMM 1 Display
        1. 1x DIY 16 seg displays (16x 16-219A/T2D-AR2T1QY/3T)
	1. COMM 2 Display
        1. 1x DIY 16 seg displays (16x 16-219A/T2D-AR2T1QY/3T)
	1. 16 Segment Display Drivers (4X MAX6955 i2c Driver)
		1. IC1 controls OPT 1&2
		1. IC2 controls OPT 3&4
		1. IC3 controls OPT 5 & COMM 2
		1. IC4 controls COMM 1
1. EXTERNAL COMPONENTS
May combine into single header if back face space allows.
    1. HUD Panel (2x8 Header)
	1. AP Panel (2x4 Header)
	1. HUD BIT Panel (1x4 Header)

amanuense, 2019-12-06:
I will soon have time to work on the project.
 Create a item for a mezzanine board that will help a lot with routing.

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

jrsteensen, 2019-12-06:
Updated. I am starting work on the schematic, I'll let you know when I need inputs/review.

amanuense, 2019-12-06:
Cool I'll take a look to good board connectors.

The idea of the mezzanine is to use it to simplify routing or to have
bigger area for connectors.

I want to do both

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

jrsteensen, 2019-12-07:
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

Can I get a quick review on this against the MAX6955 datasheet? DP LED will not be populated in any of the displays, but I think leaving it NC screws up the charlieplexing.

https://datasheets.maximintegrated.com/en/ds/MAX6955.pdf

jrsteensen, 2019-12-08:
@amanuense Schematic is ready for review.

https://www.maximintegrated.com/en/products/power/display-power-control/MAX6955.html

amanuense, 2019-12-09:
review notes:
key matrix GPIO assignation was missing
no 5v to 3.3v I2C translation
LED controller oscillators not synced.

I took the liberty of making these changes, you can observe the diff here
https://www.dropbox.com/s/cld2v8p44ih4f7m/diff_UFC_3.039802a.pdf?dl=0

I will push the changes tomorrow if there is no more updates.

jrsteensen, 2019-12-14:
See attached ZIP for drawing and DXF for PCB.

[UFC PCB REQUIREMENTS.zip](https://github.com/jrsteensen/OpenHornet/files/3964283/UFC.PCB.REQUIREMENTS.zip)

Please let me know when components are placed - will review before routing.

jrsteensen, 2019-12-18:
Please see attached CSV file with XYZ coordinates of the LEDs.

[UFC LED SKETCH.zip](https://github.com/jrsteensen/OpenHornet/files/3980901/UFC.LED.SKETCH.zip)

amanuense, 2019-12-19:
X, Y, and Z... Fancy

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

amanuense, 2020-01-20:
restarting efforts on this issue.

amanuense, 2020-01-20:
made correction to the UFC LED sketch. the document had too many LEDs (435) vs the projected 362 LEDs (including opt), I have attached a spreadsheet where I matched the LED reference on Eeschema, location, absolute, and relative position.

the spreadsheet contains a graph for the x,y location of each LED on the first page.

this change is accompanied with changes to the schematic, this will help me automate the positioning of the LEDs in the PCB.
[UFC LED SKETCH.xlsx](https://github.com/jrsteensen/OpenHornet/files/4085676/UFC.LED.SKETCH.xlsx)

jrsteensen, 2020-05-06:
@amanuense Do you have a status update on this?

amanuense, 2020-05-07:
I have finished probably 50% of the routing. I have been busy at work but I
am making slow progress.
Oscar

On Wed, May 6, 2020 at 8:08 AM John Steensen <notifications@github.com>
wrote:

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

jrsteensen, 2020-11-10:
This will feed into the ABSIS 2.0 based UFC, and a lot of the hard work is complete here. Do not despair @amanuense. All is not for naught.

Closed 2021-01-05.

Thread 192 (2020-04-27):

Flight Stick Electronics

jrsteensen, 2020-04-27:
Need to develop electronics for flight control stick.

Requirements:

1. USB HID I/O for TM Warthog Stick Grip.
2. USB HID I/O for Pitch/Roll Hall Sensors.
3. DCS-BIOS interface for trim motor inputs.
4. NEMA 23 stepper control.
5. Standard Power Bus connection.
6. USB Out to central Hub.

Questions:
Break into separate modules? (One for stick/gimbal, one for trim control?)

MrMagicMan, 2020-05-04:
I suggest you break it out into separate modules for Stick+Gimbal, and then a separate one for trim, for the people who will not go all out and build the entire thing can build just the stick..

Some questions on the other stuff.

1. USB HID I/O for TM Warthog Stick Grip,
 Are you referring to reading in the values from the TM grip, if so this will be a valuable resource https://www.reddit.com/r/hoggit/comments/45j5pk/tm_warthog_stick_circuitry/
2. USB HID I/O for Pitch/Roll Hall Sensors.
 Ive done this using a simple arduino sketch, e.g. https://www.instructables.com/id/Create-a-Joystick-Using-the-Arduino-Joystick-Libra/
3. DCS-BIOS interface for trim motor inputs.
-This one is a little more complicated and can be moved to the second module.
4. NEMA 23 stepper control.
-This one is a little more complicated and can be moved to the second module.
5. Standard Power Bus connection.
-Moved to the second module,
6. USB Out to central Hub.
-More of a note on system connections

jrsteensen, 2020-05-05:
I agree. Two modules is probably best.

Yes, will read shift registers from grip, read hall sensors, and that's our stick. Then have an ABSIS module to drive the trim motor outputs and stepper.

@MrMagicMan Any advice on simple 16-bit ADCs we might use with the HID module?

MrMagicMan, 2020-05-06:
I was looking for the AS5600 on the flight control stick assembly but didn't, see it, have we defined the location and layout of key components for the PCBa.

MrMagicMan, 2020-05-06:
https://www.reddit.com/r/hoggit/comments/45j5pk/tm_warthog_stick_circuitry/ this was quite useful

jrsteensen, 2020-05-06:
> I was looking for the AS5600 on the flight control stick assembly but didn't, see it, have we defined the location and layout of key components for the PCBa.

We aren't using an AS5600. We are using two different pot form factor hall sensors. (Same series, different angle range than the ones used on the throttle.

MrMagicMan, 2020-05-06:
Ok so are we using the 6127V1A180L.5 (part numbers don't come across in e drawings)

Meaning for this board we need to be able to:
Read in the serial data from the stick (modified SPI bus works for this)
Read in 2 12bit ADC's from the hall sensors
Output to 1 USB port as HID joystick, that will supply power etc...

Anything i'm missing?

jrsteensen, 2020-05-06:
Pitch Hall Sensor is 6127V1A90L.5FS
Roll Hall Sensor is 6127V1A360L.5FS

Otherwise correct!

MrMagicMan, 2020-05-07:
Ok that works, I created a quick sketch that creates a hid joystick based on the following library, since I don't actually have a warthog, i also created a quick sketch to emulate the shift registers https://github.com/MHeironimus/ArduinoJoystickLibrary so far no issues found.

jrsteensen, 2020-05-08:
Should we add inputs for the seat controls as well, and consider housing the electronics in the seat pan area?

MrMagicMan, 2020-05-08:
Ideally we want the run for the pots to be as short as possible so they dont pickup noise, as well the shift register will be good at creating set noise. I'm confident that even if we told people not to run the ADC and SR lines together they would and it would become a hassle, is there anyway we can mount this closer to the bottom of the stick then it becomes more of a single unit, we could put the trim stuff in the seat though and have the seat controls go to that board..

jrsteensen, 2020-05-08:
We can do a module directly aft of the gimbal, low to the floor to clear the SSDCTs. Do you have a schematic available? We can do just a small printed Arduino case, with a connector for the stick (was specifying a shielded cable in the interconnect,) and an additional pair of shielded cables from the hall sensors, as well as the USB.

MrMagicMan, 2020-05-08:
I currently just have my hand drawn schematic, the board is going to be pretty small, there are not many components required we can even stick it somewhere on the Pitch Bearing Blocks, or on the front of the main plate if we want and just add a cover. The only connection that is not actually on the stick should be to the USB port. This would make it only one connection off the stick. compared to 5 for the thrustmaster, 6 for the two encoders, and then one more for the USB stick.

Additional question, are we concerned about the backlash of the gears for the encoder position. I'm concerned we are putting in nice encoders and then maybe losing the gains of this though gear slop.

jrsteensen, 2020-05-08:
It might, depending on actual size. Once you can do a schematic or layout, let me know so I can make the MCAD model and integrate it on the stick.

As far as gear backlash, the gear ratios are so advantageous that it should be a very very minimal concern.

MrMagicMan, 2020-05-08:
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

MrMagicMan, 2020-05-08:
"schmatic" layout :p

jrsteensen, 2020-05-08:
Haha! It works!

Which arduino are you planning on using for this? I'm a tiny bit confused by that first schematic.

MrMagicMan, 2020-05-08:
Its needs something with native USB (basically anything with the ATmega32u4). The two that are supported without to much work are the Leonardo, and the Micro, I have it running on a pro micro at the moment.

The first schematic shows the joystick controller on the right (imagine there is another pot on the A0 port, and the fake thrustmaster joystick on the left. That was definitely an internal use only schematic.

MrMagicMan, 2020-05-09:
Additional question, I was looking at the throttle assembly, it looks like there are a bunch of buttons and then there is a couple of analog sensors i'm seeing:

**Analog** (x5)
- Left Throttle 1
- Right Throttle 1
- TDC 2
- Antenna Elevation 1

**Digital**
Approximately 15
- Coms 5
- CageUncage 1
- Speedbrake 2
- Dispense 2
- Exterior Lights 2?
- FLIR 1
- ATC 1
- TDC Depress 1

MrMagicMan, 2020-05-10:
Here is my plan for the throttle assembly. 2 microcontrollers, one in the right throttle and one in the base, inputs from the right throttle go through the shift registers, same strategy as the warthog. The controller in the right throttle will talk to the one in the base through and I2C connection. Schematic should look as follows.
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

jrsteensen, 2021-10-14:
Redesigning roll sensor assy to facilitate the new hall sensor. Will need to gear pitch to get enough of movement to read accurately.

jrsteensen, 2021-10-16:
Done, pending testing/input/redesign for the PCBs.

Closed 2021-10-16.

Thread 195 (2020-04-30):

Ejection Seat Redesign

jrsteensen, 2020-04-30:
Redesign Ejection Seat based on RTM's reference mesh:
- [ ] Two part design: Headrest & Main Rails with separate seat bucket, using shims to adjust seat up and down from Neutral Seat Reference Point (NSRP), while maintaining constant design eyebox.
- [ ] Keep seat bucket supports (from floor) as wide as possible to maintain clearance for stick mechanism.
- [ ] Ensure stick does not interfere with seat through full range of motion.
- [ ] Support a 250lb pilot.
- [ ] Ensure sufficient clearance underneath seat to not conflict with stick pitch springs and mechanism.

#### Hardware
- Use 90081A144 Domed Screw Nails as faux rivets throughout.
- Use domed MDF PHS as required.

#### OH3A2A-100 - ASSY, SEAT BUCKET, SJU-17
- [ ] Add cosmetics
- [ ] Add MDF HW
- [ ] Add inserts and machine screws for mounting seat sides to bucket.
- [ ] Add mounting screws for Manual Override Handle switch.

#### IDEAS & BRAINSTORMING
Frame:
2X Machifit 200-1000mm Black 2060 V-Slot Aluminum Profile Extrusion Frame for CNC Tool DIY - 1000mm ($25.75/ea)
4X Machifit 4040 Industrial Aluminum Extrusions Right Angle Inclined Bracket Connector Reinforced Black

Seat Bucket:
2020 along bottom, 2040 along back with hinge at bottom
2X Machifit 4040 Industrial Aluminum Extrusions Right Angle Inclined Bracket Connector Reinforced Black

[Aluminum Extrusion](https://www.banggood.com/Wholesale-Aluminum-Extrusions-c-11889.html)

bjanders, 2020-04-30:
The seat pan base should be extended forward something like this:
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

I eyeballed it to around 1" wide and 4" long and both arcs with a radius about 2". (I made them 20  x 100mm, radius 45mm).

bjanders, 2020-04-30:
If you are making changes then you can also fix this non-issue: https://github.com/jrsteensen/OpenHornet/issues/193. The real benefit is probably that someone does not use time to drill a hole that is not actually needed, or wonder if they are missing something since they can't find a use for it.

jrsteensen, 2020-05-07:
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

The real kneeguards angle outboard slightly. Adding this with straight kneeguards (necessary due to MDF construction of seat) will only *painfully* affect the user. I probably will not integrate this, though I will consider it.

jrsteensen, 2020-07-02:
Updated issue to reflect complete seat redesign.

uxixu, 2021-01-23:
Might mention that the safe arm handle looks like it has safe on the side too low, instead of towards the edge, as it does in game (DCS).

jrsteensen, 2021-01-23:
@uxixu I'd love to look at it! Please shoot me some pictures, though DCS has enough inaccuracies that it is a reference of last resort on this project.

uxixu, 2021-01-24:
Google Fu not turning up but seems plausible guven the way it hinges.  A safe apears written on the spine, too. Here's from page 78 of Chuck's Guide. I only have Daco fur the Tomcat but if one has the Hornet version may be there in cockpit picture.

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

uxixu, 2021-01-24:
Remembered that F-14D used NACES and DACO shows a couple,  though kinda looks like someone hand wrote safe on the side, though engraved on spine.

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

uxixu, 2021-01-24:
That was pilot. Here's RIO. Definitely lower than ED's/Chuck's.

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

jrsteensen, 2021-01-24:
It proabably is, I'm looking for verification on the proper model of ejection seat though - the F18 seat we are creating is a late model SJU-17. A much earlier model was used in the F14, so its not an apple to apples comparison.

jrsteensen, 2021-07-18:
Pushing this to a post-beta release.

TODO:

- [ ] Rail->Bucket Integration
- [ ] Bucket HW
- [ ] Rail->Pit Integration
- [ ] Add shims under bucket
- [ ] Mount OVRD SW MOUNT
- [ ] Add Seat Bucket Cosmetics
- [ ] Design Seat Placards
- [ ] Add Carbon Fiber Cosmetic Wrap where appropriate.
- [ ] Design headrest/parachute container.

jrsteensen, 2021-09-27:
Pulled this back to beta1 after some significant work on a v1 seat to bring it to 1.5 was discovered. Decided time was better spent on v2 instead. Seat bucket almost done.

jrsteensen, 2021-09-27:
- [ ] Add shims under bucket
- [ ] Add seat decals
- [ ] Add faux rivets to headrest. Add rubber pads where appropriate to headrest.
- [ ] Redesign Drogue Deployment Catapult to allow for installation of catapult and parachute container.
- [ ] Redesign Parachute Deployment Rocket to allow for installation of catapult and parachute container.

jrsteensen, 2021-10-07:
Closed by above reference.

Closed 2021-10-07.

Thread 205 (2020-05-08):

UIP: Release STLs not scaled correctly.

bnepethomas, 2020-05-08:
- [ ] OH1A -112 MFD LOWER SUPPORT C.stl
- [ ] OH1A -113 HUD PANEL AFT SUPPORT.stl
- [ ] OH1A -114 HUD PANEL CONNECTION BRACKET.stl
- [ ] OH1A -115 UIP CENTRAL TIE BRACKET.stl
- [ ] OH1A -116 MFD LOWER SUPPORT A, RIGHT.stl
- [ ] OH1A7A-14 KNOB, KORRY, RD239-A1G2.stl
- [ ] OH1A8A2A-11 HUD PANEL BACKPLATE.stl
- [ ] OH1A4A-10 - EWI Legend Plate, Left.STL
- [ ] OH1A4A-11 - EWI Chassis, Left.STL
- [ ] OH1A4A-12 - EWI Light Channels, Left.STL
- [ ] OH1A4A-13 - Pushbutton Indicator Standoff.STL
- [ ] OH1A6A-10 - EWI Legend Plate, Right.STL
- [ ] OH1A6A-11 - EWI Chassis, Right.STL
- [ ] OH1A6A-12 - EWI Light Channels, Right.STL

And a two possible left overs - wher there is a correctly scaled name - but old files exist.
- [ ] OH1A -108 UPPER UIP FACE MOUNT, RIGHT.stl
- [ ] OH1A8A4A-10 HUD BIT BOX.stl

Cheers
Peter

bnepethomas, 2020-05-11:
Found a couple of files, updated original - this should be it as I've stepped through all files now.

jrsteensen, 2020-06-16:
Added changed EWI files. They require STL generation. (Fixed the connector interference.)

L-Walker, 2020-06-17:
All sorted, OH1A -109 UIP DISPLAY PRESSURE FOOT was an additional duplicate with incorrect scaling and has been deleted. The correctly scaled version remains.

jrsteensen, 2020-06-17:
Closed IAW PR #223

Closed 2020-06-17.

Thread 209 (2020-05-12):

Rudder Pedal Interface Plate - mount holes for Solenoid

dnamaster2000, 2020-05-12:
The solenoid has 4 mounting holes, 2 are M3 and 2 are M4 (on each side) the holes on the gantry interface plate are lined up for the M3 holes, but M4 in size.

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

dnamaster2000, 2020-05-15:
There may be additional issues with this part, the solenoid is a push type, pushing the other way, needs to be rotated 180, which would leave an issue with retention of the actuator.

jrsteensen, 2020-05-30:
@dnamaster2000 Not sure I'm completing understanding the issues you are seeing. Can you explain a little more in depth with pictures?

dnamaster2000, 2020-05-31:
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

The solenoid needs to be mounted in this direction to push the locking arm out of battery, but in this direction the actuator will just fall out the front.  if mounted the other way around, (ignoring the issue of holes in the wrong spot) it wont fit.

The second photo shows even with the locking arm fully to the rear, the solenoid will not be mountable, and would be facing the wrong way.
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

jrsteensen, 2020-06-17:
How would you propose we fix it? Any alternate PNs in mind?

jrsteensen, 2020-06-17:
Referenced Wrong Issue...

Closed 2020-07-01.

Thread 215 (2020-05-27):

DDI Buttons are loose feeling

MrMagicMan, 2020-05-27:
I have a feeling there may be too much space beside the buttons, but this may be me.

Video Link
https://photos.app.goo.gl/wrNBT2ha2V4JQwzs6

jrsteensen, 2020-05-27:
Loose how?

MrMagicMan, 2020-05-27:
They can shift around / rotate in the hole, I did not use the specified self tap screw to mount them (it was removed from my Mcmaster order due to anti-dumping regulations. So I put a different button head 4-40 the same length in it, if you look at the end of the video, you can see what im talking about. Also if you want PM me your address and ill send you a board and a button and you can see for yourself.

jrsteensen, 2020-05-27:
In my print of the bezel and buttons, they are tight with a tiny tolerance in them. So I'm a hair confused.

MrMagicMan, 2020-05-27:
Maybe its me then, im talking about the movement you can see at around second 7 of the video.

jrsteensen, 2020-05-27:
We can probably split the tolerance on the button side, but it does risk some potential jamming if people end up with a worst-case MMC button and MMC bezel hole.

MrMagicMan, 2020-05-27:
What if we just make the body for the button holder longer on the DDI, it may stop some of the rotation and may make the button feel better? Do we know if anyone else has tried this i know @balzreber  was getting some domes in soon.

balzreber, 2020-05-31:
At least mine are working just fine. Even if I press on the edge of the button I can't get them to jam. I can upload a vid, if further clarification is needed. And keep in mind that mine are DLP prints, not FDM.

MrMagicMan, 2020-06-01:
I cant get them to jam, they just don't "feel" good (I think they feel cheap, maybe ill play some more with the screw head distance).  I think they will work, i don't know how the real ones feel.

balzreber, 2020-06-01:
Mine feel super solid. No wobble. Nothing. And you don't have that much space to play with the screws. Mine are all the way in, if I start to loosen them, they would jam. Are you testing with just the mechanical parts or do you have the PCB and dome switches all build in?

MrMagicMan, 2020-06-01:
I have everything together (see the first and second image link if you need more details), but my screw head is almost all the way out already, I'm not worried about the device jamming its more that there is play, what screw are you using for this the one in the bom or something else?

balzreber, 2020-06-02:
I used the screws specified.
From your first image it seems as if your PCB is way too deep inside the DDI. Did you mount the back part?
I made a vid of mine. As you can see (and hear) are very tight. No wobble, nothing.
https://share.icloud.com/photos/084So-jRFMqiexsMLvH4gvh-A

MrMagicMan, 2020-06-02:
Looks like I had printed the original DDI Bezel with significantly longer standoffs, ill have to reprint but ill close this issue and open a new one if there are issues. Thanks @balzreber

Closed 2020-06-02.

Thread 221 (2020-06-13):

Rudder Pedal Interface Plate - Holes for eccentric nuts

dnamaster2000, 2020-06-13:
The holes for the eccentric nuts are not the proper size for the nuts selected. they are only used as spacers in the current arrangement.
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

jrsteensen, 2020-06-13:
Did you make the holes counterbored? (They should show as counterbored holes in the model.)

dnamaster2000, 2020-06-13:
Part was 3D printed, the through hole is M5 diamater, and the nuts sit in the counterbore, but doesn't provide any adjustment, the hole should be a through hole, with the diameter of the eccentric nut base, so that when the nut is rotated, it effectively moves the center, allowing the spacing (tension) of the wheel to be adjusted. good visuals here: https://www.youtube.com/watch?v=uMes1My5y5I

jrsteensen, 2020-06-17:
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

I'm not totally sure how/why this doesn't work? The bore is constrained with a counterbore on bottom to allow it to turn at the correct height to ensure V-Wheel/Rail engagement, and a counterbore on the top for the SHCS.

dnamaster2000, 2020-06-17:
it looks/sounds like the eccentric nuts are not being used to adjust the position of the wheel, if that's the case, these wheels should be setup the same way as the opposing ones, using just a spacer.

jrsteensen, 2020-06-17:
No, if installed as shown, with the correct barbell shaped counterbore, it will adjust the position of the wheel horizontally. If the issue is the adjustment hex is interfering with the plate, we can open up the bottom counterbore to eliminate the interference.

jrsteensen, 2020-06-17:
....I'm an idiot.

Before:
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

After:
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

jrsteensen, 2020-06-17:
Closed in  1821ed0.

Closed 2020-06-17.

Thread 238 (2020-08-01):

JETT panel legend plate: "HALF" flaps missing

Higgins-OH, 2020-08-01:
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

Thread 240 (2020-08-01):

RWR PCB is missing R11.

Kerube, 2020-08-01:
RWR PCB is missing R11 and trace to U2 pin 23.
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

L-Walker, 2021-02-02:
This issue is now redundant due to the PCB being redesigned with ABSIS 2.0 and Backlighting.

Closed 2021-02-02.

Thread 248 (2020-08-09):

DISP button colliding with canopy rail trim

Higgins-OH, 2020-08-09:
*Please fill out the issue as completely as possible. Be very specific and take your time. The more effort you put in to fill the issue out completely, the quicker we can fix this or look at adding your requested feature.*

### Summary:
DISP button colliding with canopy rail trim

### Expected Results/How It Should Work:
Either the button needs to be reshaped or the rail needs a small cutout. Given the cutout's fragility altering the button shape might be better.

### Screenshots:
*Pictures are worth 1000 words. Take some screen grabs of the model, circle things with the snipping tool...you can't put too much info here.
<br>**PRO-TIP:** Just paste the images here.*
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

## More Information
*Add an "X" in the square brackets to check the applicable checkboxs.*
### Category:
*Check one or more items.*
- [X] MCAD (SolidWorks)
- [ ] ECAD (PCB Design or other electrical hardware)
- [ ] Software - Sketch
- [ ] Software - DCS-BIOS
- [ ] Software - Library
### Type:
*Check one item.*
- [X] Bug
- [ ] Feature Enhancement
- [ ] Maintenance
- [ ] Question
- [ ] Documentation
### Applicable End Item:
*Check one item.*
- [ ] Top Level Assembly  
- [ ] Lower Instrument Panel (LIP)
- [ ] Main Instrument Panel (MIP)
- [X] Left Console
- [ ] Right Console
- [ ] Seat
- [ ] Center Tub
- [ ] Flight Stick
- [ ] Throttle
- [ ] General Software
### Associated Filename(s):
*Insert assembly or part file names here, i.e. 123456.sldasm, etc.*
DISP_Button_Head, Canopy Rail Trim

jrsteensen, 2021-07-26:
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

Added .875 hole at location specified (concentric with button shaft) to left console canopy rail trim.

@L-Walker Does this affect your upcoming commit?

Closed 2021-07-26.

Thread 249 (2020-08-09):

OBOGS Knob: Cutout for axis missing

Higgins-OH, 2020-08-09:
*Please fill out the issue as completely as possible. Be very specific and take your time. The more effort you put in to fill the issue out completely, the quicker we can fix this or look at adding your requested feature.*

### Summary:
OBOGS Knob: Cutout for switch axis missing.

### Screenshots:
*Pictures are worth 1000 words. Take some screen grabs of the model, circle things with the snipping tool...you can't put too much info here.
<br>**PRO-TIP:** Just paste the images here.*
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

## More Information
*Add an "X" in the square brackets to check the applicable checkboxs.*
### Category:
*Check one or more items.*
- [X] MCAD (SolidWorks)
- [ ] ECAD (PCB Design or other electrical hardware)
- [ ] Software - Sketch
- [ ] Software - DCS-BIOS
- [ ] Software - Library
### Type:
*Check one item.*
- [X] Bug
- [ ] Feature Enhancement
- [ ] Maintenance
- [ ] Question
- [ ] Documentation
### Applicable End Item:
*Check one item.*
- [ ] Top Level Assembly  
- [ ] Lower Instrument Panel (LIP)
- [ ] Main Instrument Panel (MIP)
- [X] Left Console
- [ ] Right Console
- [ ] Seat
- [ ] Center Tub
- [ ] Flight Stick
- [ ] Throttle
- [ ] General Software
### Associated Filename(s):
*Insert assembly or part file names here, i.e. 123456.sldasm, etc.*
OBOGS Knob

L-Walker, 2021-08-02:
Changes:

Added - .25" Hole for switch shaft.
Added - Locking grub screw hole for the standard 8-32 x .093" cup point grub screw used on all other knobs.
Added - Recess for excess switch mounting thread to be hidden inside the knob, allowing mounting closer to the panel.
Added - Indicia arrow. Eyeballed it from 3 different hornet reference images.
Added - 91375A187 - SCREW, SET, 8-32 X .093, CUP POINT, HEX DRIVE, 18-8 to the OBOGS panel assembly.
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
 Commit: https://github.com/jrsteensen/OpenHornet/commit/dd582f8f71374baa33c58818ef8e5fb72c222a67

Closed 2021-08-02.

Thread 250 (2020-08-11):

Altimeter Bezel: Hole for rotary encoder too small

Higgins-OH, 2020-08-11:
*Please fill out the issue as completely as possible. Be very specific and take your time. The more effort you put in to fill the issue out completely, the quicker we can fix this or look at adding your requested feature.*

### Summary:
EC12E2420802 needs a hole with 9mm diameter, at the moment it has only 7mm.

### Screenshots:
*Pictures are worth 1000 words. Take some screen grabs of the model, circle things with the snipping tool...you can't put too much info here.
<br>**PRO-TIP:** Just paste the images here.*
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

## More Information
*Add an "X" in the square brackets to check the applicable checkboxs.*
### Category:
*Check one or more items.*
- [X] MCAD (SolidWorks)
- [ ] ECAD (PCB Design or other electrical hardware)
- [ ] Software - Sketch
- [ ] Software - DCS-BIOS
- [ ] Software - Library
### Type:
*Check one item.*
- [X] Bug
- [ ] Feature Enhancement
- [ ] Maintenance
- [ ] Question
- [ ] Documentation
### Applicable End Item:
*Check one item.*
- [ ] Top Level Assembly  
- [X] Lower Instrument Panel (LIP)
- [ ] Main Instrument Panel (MIP)
- [ ] Left Console
- [ ] Right Console
- [ ] Seat
- [ ] Center Tub
- [ ] Flight Stick
- [ ] Throttle
- [ ] General Software
### Associated Filename(s):
EC12E2420802, Altimeter Bezel

L-Walker, 2021-08-02:
Solved with commit https://github.com/jrsteensen/OpenHornet/commit/e7d93be0d75cef33814d916cda297ebb2c0d9852

Closed 2021-08-02.

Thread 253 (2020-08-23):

Add ~1mm to outside edge of Radar Alt Bezel

Higgins-OH, 2020-08-23:
*Please fill out the issue as completely as possible. Be very specific and take your time. The more effort you put in to fill the issue out completely, the quicker we can fix this or look at adding your requested feature.*

### Summary:
The Radar Alt bezel hardly covers the panel cutout and leaves ugly gaps. If it were just 1mm wider on each side the hole would be covered completely.

### Screenshots:
*Pictures are worth 1000 words. Take some screen grabs of the model, circle things with the snipping tool...you can't put too much info here.
<br>**PRO-TIP:** Just paste the images here.*
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

## More Information
*Add an "X" in the square brackets to check the applicable checkboxs.*
### Category:
*Check one or more items.*
- [X] MCAD (SolidWorks)
- [ ] ECAD (PCB Design or other electrical hardware)
- [ ] Software - Sketch
- [ ] Software - DCS-BIOS
- [ ] Software - Library
### Type:
*Check one item.*
- [ ] Bug
- [X] Feature Enhancement
- [ ] Maintenance
- [ ] Question
- [ ] Documentation
### Applicable End Item:
*Check one item.*
- [ ] Top Level Assembly  
- [ ] Lower Instrument Panel (LIP)
- [ ] Main Instrument Panel (MIP)
- [ ] Left Console
- [X] Right Console
- [ ] Seat
- [ ] Center Tub
- [ ] Flight Stick
- [ ] Throttle
- [ ] General Software
### Associated Filename(s):
*Insert assembly or part file names here, i.e. 123456.sldasm, etc.*
Radar Altimeter Bezel

L-Walker, 2021-08-01:
@jrsteensen simple fix but it goes whacky when I try to modify any of the dimensions of the bezel extrusion. I think you will understand the dimensions better.

Image of the dimension count below.
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

jrsteensen, 2021-08-01:
Added .062 around perimeter, finagled around knob to clearance from adjacent components. Resolved in d0bfe71.

Closed 2021-08-01.

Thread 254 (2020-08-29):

Add MFD displays to the Main Instrument Panel

JKI757, 2020-08-29:
### Summary:
Multi-Function Displays

### Expected Results/How It Should Work:
Was looking around on your repo to see if you'd considered the MFD issue, as this is one thing it seems nobody has really been able to find good displays for.
Just recently based off a reddit post I was able to find a supplier in Shenzhen named Shanghai Top Display OptoElectronics that makes a 4" display that is not perfect, but does appear to be suitable for this.
I'm currently working on two things -- adding in the additional hardware required to make those connect (will require either HDMI connections from the graphics card, or usb-HDMI dongles, which I believe is the better way to go (I purchased usb-hdmi dongles, but am having difficulty making them work with Windows 10 -- I used a different USB-C dongle with a Mac to test the displays as you can see below in the picture).  I have not addressed any large scale purchasing from them, currently have purchased three sample 4" displays, which they shipped to me within about a week.  These are small within the MFD frame, so I will in the future address with them getting 5" displays (they don't offer those on their website, so they may not be open to designing them unless we can get a larger order put together).  The total cost for these displays was $48 for the hdmi-mpi board + $16 for the display itself + 20 bucks shipping for the three I ordered.  These are samples, so a contract for larger numbers could probably be negotiated to drop the cost significantly if there were interest eventually.

[4" square HDMI-MPI display](https://shtdo.en.alibaba.com/product/60802354105-813720361/4_inch_square_HDMI_display_with_720_720_with_hdmi_to_mipi_board.html)

### Actual Results/How It Does Work:
Multi-Function Displays are required to operate the aircraft, they allow managing stores, display moving map, HUD, targeting information from TGP, Maverick missile targeting, HSI, etc.

### Screenshots:

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

## More Information
*Add an "X" in the square brackets to check the applicable checkboxs.*
### Category:
*Check one or more items.*
- [ ] MCAD (SolidWorks)
- [ ] ECAD (PCB Design or other electrical hardware)
- [ ] Software - Sketch
- [ ] Software - DCS-BIOS
- [ ] Software - Library
### Type:
*Check one item.*
- [ ] Bug
- [X] Feature Enhancement
- [ ] Maintenance
- [ ] Question
- [ ] Documentation
### Applicable End Item:
*Check one item.*
- [ ] Top Level Assembly  
- [ ] Lower Instrument Panel (LIP)
- [X] Main Instrument Panel (MIP)
- [ ] Left Console
- [ ] Right Console
- [ ] Seat
- [ ] Center Tub
- [ ] Flight Stick
- [ ] Throttle
- [ ] General Software
### Associated Filename(s):

jrsteensen, 2020-08-29:
I appreciate your research, but all the internal displays have already been selected, utilizing commonly available COTS displays. The part numbers are the name of the display models in the UIP assembly. I'm going to close this issue.

Thanks for taking the time to post though!

JKI757, 2020-08-29:
Maybe I'm really missing something, but I've searched high and low through every branch of this repo and I simply don't see a part number for the display you're using.  I'm really interested in this, can you point me to a link or something?

Closed 2020-08-29.

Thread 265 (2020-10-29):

Electronics Redesign

jrsteensen, 2020-10-29:
**This is a placeholder issue that will be broken out into many other issues**

### Summary:
Redesign OpenHornet electronics stack.

### Goals:
- Simplify construction by having all SMD components on one side of PCB.
- All SMD components should be stocked by JLCPCB to facilitate delivery with all SMD components pre-assembled. (PTH components to be populated by user.)
- Add test points as required to PCB.
- Eliminate all currently used LEDs. Utilize ONLY either the WS2812B-Mini or the WS2812B-B LEDs. (Individually addressible and capable of being driven from a single Arduino PWM pin + PWR per string.)
- Make ABSIS boards more general, with feature specific small breakout PCBs.
- Panelize PCBs to drive component quantity discounts.
- Remove dome switches from pit. Replace with quality tactile switch. Optimize for backlighting.
- Support backlighting the OpenHornet pit.

## Issues/Actions:
- [ ] Create detailed OpenHornet IO requirements table.
- [ ] Establish common electronics parts to be used across all PCBs. (JLCPCB standard list parts preferred, followed by extended list parts.)
- [ ] Create detailed electronic requirements document.

### General PCBs:
- [x] ABSIS Nano
- [x] ABSIS Mega
- [x] ABSIS Bus Master
- [x] ABSIS Backlighting Controller

### UIP PCBs:
- [ ] .55 SQ Indicator PCB
- [ ] Master Mode Pushbutton PCB
- [ ] UFCv4
- [ ] DDI/AMPCD Controller PCB
- [ ] DDI Button PCB
- [ ] AP Module PCB
- [ ] Right Eyebrow Warning Indicator PCB
- [ ] Left Eyebrow Warning Indicator PCB

### LIP PCBs:
- [ ] AMPCD Button PCB
- [ ] IFEI Button PCB
- [ ] JETT Select PCB
- [ ] RWR Control Panel PCB

### Right Console PCBs:
- [ ] Caution Panel PCB

### Left Console PCBs:
- [ ] Throttle PCB(s?)

- [ ] Update Cockpit Interconnect Drawing

dnamaster2000, 2020-10-31:
A note on the DDI / AMPCD Button Boards, Pull Up resistors are required on all input pins for the TCA9534 to work correctly.

petersawka, 2020-10-31:
Working on adding the Pull-up Resistors on the DDI and AMPCD Button Boards.

jrsteensen, 2021-09-10:
This issue is complete. If any more functional PCBs are required, they will be completed as we progress towards hardware freeze.

Closed 2021-09-10.

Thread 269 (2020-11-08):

Drills and edge OFFSET between UIP FLoor Right longerons/ Glareshield

Thibaud-54, 2020-11-08:
*Please fill out the issue as completely as possible. Be very specific and take your time. The more effort you put in to fill the issue out completely, the quicker we can fix this or look at adding your requested feature.*

### Summary:
(Please summarize your issue here. Be specific.)

There is an offset between the drills in the FLOOR part and the corresponding drills/holes in the both right LONGERONS (INBOARD AND OUTBOARD). There is also an offset (air gap) between floor / Spin recovery bracket and right glareshield.
Both offsets are identical (around 2.5 mm).

### Expected Results/How It Should Work:
(Explain how you think it should work here. Be very specific.)

The drills should be repositioned by modifying the FLOOR part only until they become coincident again with the corresponding longerons. Lengthen the FLOOR part. SPIN RECOVERY BRACKET should be also modified by remove the "lip" and remove all of the air gap next to the right glareshield.

### Actual Results/How It Does Work:
(Explain how it actually works here. Be very specific.)

Please check picture below.

### Screenshots:
*Pictures are worth 1000 words. Take some screen grabs of the model, circle things with the snipping tool...you can't put too much info here.
<br>**PRO-TIP:** Just paste the images here.*
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

## More Information
*Add an "X" in the square brackets to check the applicable checkboxs.*
### Category:
*Check one or more items.*
- [X] MCAD (SolidWorks)
- [ ] ECAD (PCB Design or other electrical hardware)
- [ ] Software - Sketch
- [ ] Software - DCS-BIOS
- [ ] Software - Library
### Type:
*Check one item.*
- [X] Bug
- [ ] Feature Enhancement
- [ ] Maintenance
- [ ] Question
- [ ] Documentation
### Applicable End Item:
*Check one item.*
- [ ] Top Level Assembly  
- [ ] Lower Instrument Panel (LIP)
- [X] Main Instrument Panel (MIP)
- [ ] Left Console
- [ ] Right Console
- [ ] Seat
- [ ] Center Tub
- [ ] Flight Stick
- [ ] Throttle
- [ ] General Software
### Associated Filename(s):
*Insert assembly or part file names here, i.e. 123456.sldasm, etc.*
UIP Floor.sldprt
Spin panel module bracket.sldprt

jrsteensen, 2021-09-11:
Completed in referenced commit above.

Closed 2021-09-11.

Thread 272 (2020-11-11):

Bleed Air Knob Solenoid Pin Clearance

L-Walker, 2020-11-11:
### Summary:
The bleed air knob has its connection to the solenoid pin built as if the fully in position is the fully extended position.

### Expected Results/How It Should Work:
The Microswitch and cutout for the pin connecting the shaft and solenoid need to move outwards by the throw distance required.

### Actual Results/How It Does Work:
As a result, the solenoid pin cannot extend due to the microswitch and cutout in the 3D printed support part.

### Screenshots:
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

## More Information

### Category:

- [x] MCAD (SolidWorks)
- [ ] ECAD (PCB Design or other electrical hardware)
- [ ] Software - Sketch
- [ ] Software - DCS-BIOS
- [ ] Software - Library
### Type:

- [x] Bug
- [ ] Feature Enhancement
- [ ] Maintenance
- [ ] Question
- [ ] Documentation
### Applicable End Item:

- [ ] Top Level Assembly  
- [ ] Lower Instrument Panel (LIP)
- [ ] Main Instrument Panel (MIP)
- [ ] Left Console
- [x] Right Console
- [ ] Seat
- [ ] Center Tub
- [ ] Flight Stick
- [ ] Throttle
- [ ] General Software
### Associated Filename(s):
Bleed Air Solenoid Mount

L-Walker, 2021-02-02:
Commit [d1b48ea](https://github.com/jrsteensen/OpenHornet/commit/d1b48ea70ad2cf71b3f1f4c350765e44311b4ec8) Included the required changes to solve this issue. Screenshot of the changed part:
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
As can be seen in the photo, the solenoid at its retracted position is at the end of the slot, allowing it to extend and engage the microswitch at the limit of the slot. The slot width has not been changed, the entire slot and switch has just been moved away from the solenoid by the amount seen, ~.25"
@jrsteensen with your approval, this issue can be closed.

Closed 2021-02-02.

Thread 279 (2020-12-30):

Parking Brake - Switch Spacing

dnamaster2000, 2020-12-30:
*Please fill out the issue as completely as possible. Be very specific and take your time. The more effort you put in to fill the issue out completely, the quicker we can fix this or look at adding your requested feature.*

### Summary:
The space for the switches is about 1.5mm larger than the switch housing, resulting in loose switches, that cannot be clamped.  also results in problems with the housing if clamped, it may collapse as there is nothing in the middle.

### Expected Results/How It Should Work:
reduce width by 1.5mm (or imperial equilivant)

### Actual Results/How It Does Work:
(Explain how it actually works here. Be very specific.)

### Screenshots:
*Pictures are worth 1000 words. Take some screen grabs of the model, circle things with the snipping tool...you can't put too much info here.
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

## More Information
*Add an "X" in the square brackets to check the applicable checkboxs.*
### Category:
*Check one or more items.*
- [X ] MCAD (SolidWorks)
- [ ] ECAD (PCB Design or other electrical hardware)
- [ ] Software - Sketch
- [ ] Software - DCS-BIOS
- [ ] Software - Library
### Type:
*Check one item.*
- [ X] Bug
- [ ] Feature Enhancement
- [ ] Maintenance
- [ ] Question
- [ ] Documentation
### Applicable End Item:
*Check one item.*
- [ ] Top Level Assembly  
- [ ] Lower Instrument Panel (LIP)
- [ ] Main Instrument Panel (MIP)
- [ X] Left Console
- [ ] Right Console
- [ ] Seat
- [ ] Center Tub
- [ ] Flight Stick
- [ ] Throttle
- [ ] General Software
### Associated Filename(s):
*Insert assembly or part file names here, i.e. 123456.sldasm, etc.*

jrsteensen, 2020-12-30:
Will reduce the clearance to .01 inch (0.254mm) on either side. (Same as I use for the DDI/AMPCD buttons.)

Closed 2021-01-30.

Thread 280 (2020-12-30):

Parking Brake - Thin Wall

dnamaster2000, 2020-12-30:
*Please fill out the issue as completely as possible. Be very specific and take your time. The more effort you put in to fill the issue out completely, the quicker we can fix this or look at adding your requested feature.*

### Summary:
One of the walls of the switch screw housing needs to be extended slightly, there is not enough space to close in the holes in 3d printing.

### Expected Results/How It Should Work:
(Explain how you think it should work here. Be very specific.)

### Actual Results/How It Does Work:
(Explain how it actually works here. Be very specific.)

### Screenshots:
*Pictures are worth 1000 words. Take some screen grabs of the model, circle things with the snipping tool...you can't put too much info here.
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
 vs
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

## More Information
*Add an "X" in the square brackets to check the applicable checkboxs.*
### Category:
*Check one or more items.*
- [X] MCAD (SolidWorks)
- [ ] ECAD (PCB Design or other electrical hardware)
- [ ] Software - Sketch
- [ ] Software - DCS-BIOS
- [ ] Software - Library
### Type:
*Check one item.*
- [X] Bug
- [ ] Feature Enhancement
- [ ] Maintenance
- [ ] Question
- [ ] Documentation
### Applicable End Item:
*Check one item.*
- [ ] Top Level Assembly  
- [ ] Lower Instrument Panel (LIP)
- [ ] Main Instrument Panel (MIP)
- [X] Left Console
- [ ] Right Console
- [ ] Seat
- [ ] Center Tub
- [ ] Flight Stick
- [ ] Throttle
- [ ] General Software
### Associated Filename(s):
*Insert assembly or part file names here, i.e. 123456.sldasm, etc.*

jrsteensen, 2021-07-26:
Added .0625 of material to outside wall.

Closed 2021-07-26.

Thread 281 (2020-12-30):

Parking Brake - Extra Detent

dnamaster2000, 2020-12-30:
*Please fill out the issue as completely as possible. Be very specific and take your time. The more effort you put in to fill the issue out completely, the quicker we can fix this or look at adding your requested feature.*

### Summary:
Due to the through hole on the screw that blocks rotation, there is a second detent in the Emergency position of the lever, you can see it in the video posted below.

### Expected Results/How It Should Work:
(Explain how you think it should work here. Be very specific.)

### Actual Results/How It Does Work:
(Explain how it actually works here. Be very specific.)

### Screenshots:
*Pictures are worth 1000 words. Take some screen grabs of the model, circle things with the snipping tool...you can't put too much info here.

https://www.youtube.com/watch?v=n1THPwVa9PM

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

## More Information
*Add an "X" in the square brackets to check the applicable checkboxs.*
### Category:
*Check one or more items.*
- [X] MCAD (SolidWorks)
- [ ] ECAD (PCB Design or other electrical hardware)
- [ ] Software - Sketch
- [ ] Software - DCS-BIOS
- [ ] Software - Library
### Type:
*Check one item.*
- [X] Bug
- [ ] Feature Enhancement
- [ ] Maintenance
- [ ] Question
- [ ] Documentation
### Applicable End Item:
*Check one item.*
- [ ] Top Level Assembly  
- [ ] Lower Instrument Panel (LIP)
- [ ] Main Instrument Panel (MIP)
- [X] Left Console
- [ ] Right Console
- [ ] Seat
- [ ] Center Tub
- [ ] Flight Stick
- [ ] Throttle
- [ ] General Software
### Associated Filename(s):
*Insert assembly or part file names here, i.e. 123456.sldasm, etc.*

jrsteensen, 2020-12-30:
I will evaluate blind hole/shorter screw for this position. The other alternative would be through hole, with a shorter screw, then pot the hole with JB weld, and wipe the exterior smooth with a paper towel or something prior to the JB weld curing.

dnamaster2000, 2021-01-04:
I think you can remove the back detent entirely, add an additional 2 holes to the shaft at front detents for when the handle is stowed. would probably give a more positive detent on rotate, and remove redundancy.

dnamaster2000, 2021-01-16:
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

If you remove the detent at the aft (#1) in my picture, you can put a second set of holes on the forward detent to take care of the pivot action (#2) in my picture.  this actually results in less overall parts for the entire mech.  also, the holes for detents do not need to be through holes, making them 1/16th or so in depth will increase overall strength of the rod, and provide the same function.

Ben-F111, 2021-06-15:
Park Brake shaft enhancement #302 I have suggested a full diameter grove be used, this functions just as good, and is very easy to make compared with getting the 2 x holes drilled

jrsteensen, 2021-07-26:
Converted 4-40 holes to .1875 blind holes, and replaced 91251A108 SHCS with 91251A106 SHCS, in addition to incorporating #302.

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

Closed 2021-07-26.

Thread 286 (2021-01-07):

Replace existing mag switch design with new design.

B404, 2021-01-07:
### Summary:
Following dimensions from the 3D model, the drill size and position was too large and low to clear internal components not included in the APEM 3D model.

### Expected Results/How It Should Work:
Drill in right spot should clear the internal contacts.

### Actual Results/How It Does Work:
Internal moving part fouls the retraction of the pin/dowel.

### Screenshots:
Hole centre location change.
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

Hole bore size to change.
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

2.5mm Drill bit *just* clears the contact.
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

## More Information
Not sure if the way it should be - but as pictured (drilling from the '3' end of the switch body, the 631H2 is open circuit when the toggle would be indicating 'Arm'  on LTD/R.

Parts purchased are APEM 631H/2 SPST NKL On-None-Off. PN on Mouser.com is 642-632H2, for reference.

### Category:
*Check one or more items.*
- [X ] MCAD (SolidWorks)
- [X ] ECAD (PCB Design or other electrical hardware)
- [ ] Software - Sketch
- [ ] Software - DCS-BIOS
- [ ] Software - Library
### Type:
*Check one item.*
- [X ] Bug
- [ ] Feature Enhancement
- [ ] Maintenance
- [ ] Question
- [ ] Documentation
### Applicable End Item:
*Check one item.*
- [ ] Top Level Assembly  
- [ ] Lower Instrument Panel (LIP)
- [ ] Main Instrument Panel (MIP)
- [X ] Left Console
- [X ] Right Console
- [ ] Seat
- [ ] Center Tub
- [ ] Flight Stick
- [ ] Throttle
- [ ] General Software
### Associated Filename(s):
Ah.

Ben-F111, 2021-07-11:
This Mag switch design may not work correctly, The current design is for a PUSH off scenario, a MAG SW is a Hold on system
THe Spec'd Plunger is also not strong enough to push the switch to the off position

jrsteensen, 2021-10-31:
Switch Name | Bat | Function | Mag Held Position
-- | -- | -- | --
Launch Bar | Standard 17.5mm   bat, milled flat and Drill/Tapped (M2.5 X 0.45) | ON-(ON) | EXTEND
Hook Bypass | Standard 17.5mm bat | ON-(ON) | FIELD
APU | Standard 17.5mm bat   (Round locking Toggle Bat will press fit on) | ON-(ON) | ON
ENG CRANK | Standard 17.5mm bat | (ON)-OFF-(ON) | L & R
DUMP | Standard 17.5mm bat   (Round locking Toggle Bat will press fit on) | ON-(ON) | ON
PITOT | Standard 17.5mm bat   (Round locking Toggle Bat will press fit on) | ON-(ON) | ON
LTD/R | Standard 17.5mm bat   (Round locking Toggle Bat will press fit on) | ON-(ON) | ARM
Canopy | Standard 17.5mm bat | (ON)-OFF-(ON) | OPEN (ONLY)

jrsteensen, 2021-11-19:
Initial testing by @Ben-F111 using the Xurui XT-23AF switches and 2x electromagnets are extremely promising.

Required dimensions:

- [ ] Switch Body
- [ ] Switch Bat
- [ ] Switch bushing
- [ ] Location and size of slot in body
- [ ] Hole diameter for shaft.
- [ ] Dimensions of EM mounting bracket (angle and EM mounting hole location.)

jrsteensen, 2022-03-29:
Ordered an APEM 645H/2 to teardown and see if we can't give it the same treatment. The APEMs tend to have a less mushy feel to them compared to the Xurui switches.

jrsteensen, 2022-04-07:
Added all new mag switches to relevant assemblies, and have the -1 thru -3 variants mostly designed.

- [ ] Add actuator to -1
- [ ] Add actuator to -2
- [ ] Add actuator to -3
- [ ] Redesign canopy box to accommodate mag switch.

jrsteensen, 2022-04-10:
Issue closed with the commit of OHC0005-1 thru -3 to F360 Repository.

Woohoo!

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

Closed 2022-04-10.

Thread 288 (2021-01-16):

Landing Gear inner shaft

dnamaster2000, 2021-01-16:
*Please fill out the issue as completely as possible. Be very specific and take your time. The more effort you put in to fill the issue out completely, the quicker we can fix this or look at adding your requested feature.*

### Summary:
I ran into a couple of issues:
1) There is excessive space around the rear portion of the axis, this results in alot of movement, and with the detent installed, the shaft does not sit straight.
2) The detent tip is nylon, and has a poor interface with the 3d printed track.  on the first attempt to use this i broke the detent tip from over rotating (it sticks then lets go) even with a second detent, i was unable to 'feel' the track.  my 3D printed parts were DLP prints, the resin is very smooth, i woudl imagine if it was a FDM part it would have been worse.
3) there is no way to remove the detent once it is seated in the groove at present.

### Expected Results/How It Should Work:
unknown

### Actual Results/How It Does Work:
see summary

### Screenshots:
*Pictures are worth 1000 words. Take some screen grabs of the model, circle things with the snipping tool...you can't put too much info here.
<br>**PRO-TIP:** Just paste the images here.*
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

## More Information
*Add an "X" in the square brackets to check the applicable checkboxs.*
### Category:
*Check one or more items.*
- [ X ] MCAD (SolidWorks)
- [ ] ECAD (PCB Design or other electrical hardware)
- [ ] Software - Sketch
- [ ] Software - DCS-BIOS
- [ ] Software - Library
### Type:
*Check one item.*
- [ X ] Bug
- [ ] Feature Enhancement
- [ ] Maintenance
- [ ] Question
- [ ] Documentation
### Applicable End Item:
*Check one item.*
- [ ] Top Level Assembly  
- [ ] Lower Instrument Panel (LIP)
- [ ] Main Instrument Panel (MIP)
- [ X ] Left Console
- [ ] Right Console
- [ ] Seat
- [ ] Center Tub
- [ ] Flight Stick
- [ ] Throttle
- [ ] General Software
### Associated Filename(s):
*Insert assembly or part file names here, i.e. 123456.sldasm, etc.*

Ben-F111, 2021-06-15:
I have suggested via a suggestion via Landing Gear adjustment hole required #306 to add a hole to allow the ball spring to be set tot the correct depth, when it is the landing gear does function good

jrsteensen, 2021-09-22:
Addressed in #306. Thanks for the report!

Closed 2021-09-22.

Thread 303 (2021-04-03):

Add additional internal clearance for a Magnetic Canopy switch

bnepethomas, 2021-04-03:
I'm reasonable sure the Canopy switch is actually a three position magnet switch. (which I know are rare :))

### Summary:
The internal upper support within the canopy control box starts approx 3mm too low which means a magnetic switch is unable to sit flat against the surface as it is pushed back.

### Expected Results/How It Should Work:
Magnetic switch should sit flat.

### Actual Results/How It Does Work:
(Explain how it actually works here. Be very specific.)

### Screenshots:
*Pictures are worth 1000 words. Take some screen grabs of the model, circle things with the snipping tool...you can't put too much info here.
<br>**PRO-TIP:** Just paste the images here.*

### Category:
*Check one or more items.*
- [ X] MCAD (SolidWorks)
- [ ] ECAD (PCB Design or other electrical hardware)
- [ ] Software - Sketch
- [ ] Software - DCS-BIOS
- [ ] Software - Library
### Type:
*Check one item.*
- [X] Bug
- [ ] Feature Enhancement
- [ ] Maintenance
- [ ] Question
- [ ] Documentation
### Applicable End Item:
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

*Check one item.*
- [ ] Top Level Assembly  
- [ ] Lower Instrument Panel (LIP)
- [ ] Main Instrument Panel (MIP)
- [ ] Left Console
- [ X] Right Console
- [ ] Seat
- [ ] Center Tub
- [ ] Flight Stick
- [ ] Throttle
- [ ] General Software
### Associated Filename(s):
Canopy Bracket.sldprt

bnepethomas, 2021-04-03:
Recommended fix
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

bnepethomas, 2021-04-03:
Actually on a closer look - can just squeeze the switch in with current plans - by using nut on the inside was able to mount switch

Closed 2021-04-03.

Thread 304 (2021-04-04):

Add Electrically held switch electronics for Canopy Switch

bnepethomas, 2021-04-04:
### Summary:
The current ABSIS branch (2.0) is missing a port for the Magnetic Canopy switch

### Expected Results/How It Should Work:
Additional output port needed

### Actual Results/How It Does Work:
(Explain how it actually works here. Be very specific.)

## More Information
*Add an "X" in the square brackets to check the applicable checkboxs.*
### Category:
*Check one or more items.*
- [ ] MCAD (SolidWorks)
- [ X] ECAD (PCB Design or other electrical hardware)
- [ ] Software - Sketch
- [ ] Software - DCS-BIOS
- [ ] Software - Library
### Type:
*Check one item.*
- [ ] Bug
- [ ] Feature Enhancement
- [ ] Maintenance
- [ ] Question
- [ ] Documentation
### Applicable End Item:
*Check one item.*
- [ ] Top Level Assembly  
- [ ] Lower Instrument Panel (LIP)
- [ ] Main Instrument Panel (MIP)
- [ ] Left Console
- [X ] Right Console
- [ ] Seat
- [ ] Center Tub
- [ ] Flight Stick
- [ ] Throttle
- [ ] General Software
### Associated Filename(s):
*Insert assembly or part file names here, i.e. 123456.sldasm, etc.*

jrsteensen, 2021-04-04:
How is it missing? Thats what the Solenoid Accessory Driver PCB is for: ECAD\PCBs\ABSIS\ABSIS_Solenoid_Driver_Accessory

bnepethomas, 2021-04-04:
Hi John - I could be looking at the wrong thing - I was referencing
https://github.com/jrsteensen/OpenHornet/blob/ABSIS_2.0/ECAD/docs/OpenHornet%20Block%20Diagram.pdf
Which doesn't include the canopy held switch

jrsteensen, 2021-04-04:
You are correct there. Since we don't have a two way mag held switch design, we weren't supporting it. (Using a three position momentary toggle instead). It would be pretty straight forward to route the solenoids of the mag switch to one of the existing accessory PCBs instead for the time being.

bnepethomas, 2021-04-04:
Agree - just ensuring its added to the thought pile as its much easier to include it now rather than later

Closed 2021-04-04.

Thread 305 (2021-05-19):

JLCPCB rejects UFC display layers

Alan-JH, 2021-05-19:
### Summary:
JLCPCB rejected my order with display layers 2-4 for opt, com, and scratchpad, citing the minimum allowed clearance between routed cutouts being 4mm, while the PCBs have a clearance of about .32mm.

### Expected Results/How It Should Work:
Expected JLC to process the order, and some number of pieces to fail

### Actual Results/How It Does Work:
JLC rejected the order before manufacturing.

### Screenshots:

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

## More Information
*Add an "X" in the square brackets to check the applicable checkboxs.*
### Category:
*Check one or more items.*
- [ ] MCAD (SolidWorks)
- [x] ECAD (PCB Design or other electrical hardware)
- [ ] Software - Sketch
- [ ] Software - DCS-BIOS
- [ ] Software - Library
### Type:
*Check one item.*
- [ ] Bug
- [ ] Feature Enhancement
- [x] Maintenance
- [ ] Question
- [ ] Documentation
### Applicable End Item:
*Check one item.*
- [ ] Top Level Assembly  
- [ ] Lower Instrument Panel (LIP)
- [x] Main Instrument Panel (MIP)
- [ ] Left Console
- [ ] Right Console
- [ ] Seat
- [ ] Center Tub
- [ ] Flight Stick
- [ ] Throttle
- [ ] General Software
### Associated Filename(s):

ufc_v4_comm_layer2.kicad_pcb
ufc_v4_comm_layer3.kicad_pcb
ufc_v4_comm_layer4.kicad_pcb
ufc_v4_opt_layer2.kicad_pcb
ufc_v4_opt_layer3.kicad_pcb
ufc_v4_opt_layer4.kicad_pcb
ufc_v4_scratchpad_layer2.kicad_pcb
ufc_v4_scratchpad_layer3.kicad_pcb
ufc_v4_scratchpad_layer4.kicad_pcb

jrsteensen, 2021-08-27:
That would be great! I'm curious if clear resin will do the trick or if we will need to add a tiny bit of white powder to give the light something to reflect off of. Did you have to modify the layers to print them with a .2mm nozzle?

Alan-JH, 2021-08-27:
It turns out the clear resin I have went bad. I could get some more soon, but for now I tried white glue instead, as I have used that to diffuse LEDs before.

I had to close the slots for the 7 segment digits on the scratchpad by 0.05mm to get the slicer to slice the model properly with a 0.2mm nozzle. Otherwise, it didn't need modification. The nozzle clogged every 4 prints or so though, so I would either need to cold pull or replace it entirely, which wasn't pleasant, hence my suggestion for SLA.

Alan-JH, 2021-08-28:
After drying overnight, the glue definitely helped, but blocks a little too much light. I will try to get some clear resin soon and give that a shot

jrsteensen, 2021-09-04:
Resin print of layers 2 and 3 were successful as-is, or can be FDM printed with a .2 nozzle. No change required to model. Will note for them to be printed on drawing.

Closed 2021-09-04.

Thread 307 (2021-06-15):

Landing Gear Housing, installation holes required

Ben-F111, 2021-06-15:
*Please fill out the issue as completely as possible. Be very specific and take your time. The more effort you put in to fill the issue out completely, the quicker we can fix this or look at adding your requested feature.*

### Summary:
When installing the the 2 x PHS Screws for the Gear solenoid, there is no access to "tighten the screws" it is suggested 2 x holes are made in the MCAD for the housing to allow a PHS screw driver to install these screws

### Expected Results/How It Should Work:
the 2 x screws hold on the solenoid, currently there is no access to tighten these

### Actual Results/How It Does Work:
adding 2 x holes will allow the screw driver to pass through the print and tighten the screws.

### Screenshots:
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

## More Information
*Add an "X" in the square brackets to check the applicable checkboxs.*
### Category:
*Check one or more items.*
- [X] MCAD (SolidWorks)

### Type:
*Check one item.*
- [X] Feature Enhancement
### Applicable End Item:
*Check one item.*
- [x] Left Console

### Associated Filename(s):
Landing Gear Lever Mount

jrsteensen, 2021-07-26:
Resolved in 4d531b0. Also, an offset Philips head screwdriver like the one shown can be utilized in this location without the clearance holes.

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

Closed 2021-07-26.

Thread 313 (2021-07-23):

v1.0.0-beta1 Drawing Package

jrsteensen, 2021-07-23:
## UIP
- [ ] Mechanical Drawings
  - [ ] OH1A1 - ASSY, UPPER INSTRUMENT PANEL
  - [ ] OH1A2 - ASSY, PANEL, MASTER ARM
  - [ ] OH1A3 - ASSY, DDI
  - [ ] OH1A4 - ASSY, EYEBROW WARNING INDICATOR, LEFT
  - [ ] OH1A5 - ASSY, EYEBROW WARNING INDICATOR, RIGHT
  - [ ] OH1A6 - ASSY, PANEL, SPIN RECOVERY
  - [ ] OH1A8 - ASSY, UPFRONT CONTROL PANEL
    - [ ] OH1A8A1 - ASSY, UPFRONT CONTROL PANEL PRIMARY MODULE
    - [ ] OH1A8A2 - ASSY, PANEL, HUD
    - [ ] OH1A8A3 - ASSY, AP SWITCH MODULE
    - [ ] OH1A8A4 - ASSY, HUD BIT BOX
## LIP
- [ ] Mechanical Drawings
    - [ ] OH2A1 - ASSY, LOWER INSTRUMENT PANEL
    - [ ] OH2A1A1 - ASSY, LIP STRUCTURE
    - [ ] OH2A2A1 - ASSY, LEFT LIP MODULE
        - [ ] OH2A2A1A1 - ASSY, PANEL, JETT SLEECT
        - [ ] OH2A2A1A2 - ASSY, PANEL, IFEI
        - [ ] OH2A2A1A3 - ASSY, PANEL, VIDEO RECORD
    - [ ] OH2A3A1 - ASSY, AMPCD MODULE
    - [ ] OH2A4A1 - ASSY, PANEL, RWR CONTROL
    - [ ] OH2A5A1 - ASSY, PANEL, ECM/DISP
    - [ ] OH2A6A1 - ASSY, CABIN PRESSURE GAUGE
    - [ ] OH2A7A1 - ASSY, STANDBY INSTRUMENT MODULE
## L CONSOLE
- [ ] Mechanical Drawings
    - [ ] OH4A1 - ASSY, LEFT CONSOLE
    - [ ] OH4A1A1 - ASSY, LEFT CONSOLE STRUCTURE
    - [ ] OH4A2A1 - ASSY, LANDING GEAR PANEL
    - [ ] OH4A3A1 - ASSY, SELECT JETT PANEL
    - [ ] OH4A3A2 - ASSY, PARK BRAKE HANDLE
    - [ ] OH4A3A3 - ASSY, BRAKE PRESS GAUGE
    - [ ] OH4A4A1 - ASSY, FIRE TEST PANEL
    - [ ] OH4A4A2 - ASSY, EXTERNAL LT PANEL
    - [ ] OH4A4A3 - ASSY, GEN TIE PANEL
    - [ ] OH4A5A1 - ASSY, FUEL PANEL
    - [ ] OH4A5A2 - ASSY, APU/ENG CRANK PANEL
    - [ ] OH4A6A1 - ASSY, FCS PANEL
    - [ ] OH4A7A1 - ASSY, COMM PANEL
    - [ ] OH4A7A2 - ASSY, OBOGS PANEL
    - [ ] OH4A7A3 - ASSY, MC/HYD PANEL
    - [ ] OH4A7A4 - ASSY, ANT SEL PANEL
    - [ ] OH4A8A1 - ASSY, LEFT CIRCUIT BREAKERS
    - [ ] OH4A8A2 - ASSY, DISPENSE BUTTON
    - [ ] OH4A8A3 - ASSY, NUC ENABLE SWITCH
    - [ ] OH10A1A1 - ASSY, SIM PWR PANEL
## R CONSOLE
- [ ] Mechanical Drawings
    - [ ] OH5A1 - ASSY, RIGHT CONSOLE
    - [ ] OH5A1A1 - ASSY, RIGHT CONSOLE STRUCTURE
    - [ ] OH5A2A1 - ASSY, HOOK LEVER & INDICATOR
    - [ ] OH5A2A2 - ASSY, WING FOLD HANDLE
    - [ ] OH5A2A3 - ASSY, AV COOL SWITCH
    - [ ] OH5A2A4 - ASSY, RADAR ALTIMETER GAUGE
    - [ ] OH5A2A5 - ASSY, HYD PRESS GAUGE
    - [ ] OH5A2A6 - ASSY, BUNO PLACARD
    - [ ] OH5A2A7 - ASSY, LDG CHKLST PANEL
    - [ ] OH5A3A1 - ASSY, CAUTION LIGHT PANEL
    - [ ] OH5A4A1 - ASSY, ELEC PANEL
    - [ ] OH5A5A1 - ASSY, ECS PANEL
    - [ ] OH5A5A2 - ASSY, DEFOG/WINDSHIELD PANEL
    - [ ] OH5A6A1 - ASSY, INTR LT PANEL
    - [ ] OH5A7A1 - ASSY, SNSR PANEL
    - [ ] OH5A8A1 - ASSY, SIM CNTL PANEL
    - [ ] OH5A9A1 - ASSY, KY58 PANEL
    - [ ] OH5A10A1 - ASSY, RIGHT CIRCUIT BREAKERS
    - [ ] OH5A10A2 - ASSY, CANOPY SWITCH
    - [ ] OH5A11A1 - ASSY, BULKHEAD INTERCONNECT PANEL
## CENTER TUB
- [ ] Mechanical Drawings
    - [ ] OHXXX - ASSY, CENTER TUB
## SEAT v1.5
- [ ] Mechanical Drawings
  - [ ] TBD
## THROTTLE
- [ ] Mechanical Drawings
    - [ ] OH4A9A1 - ASSY, THROTTLE QUADRANT
    - [ ] OH4A9A2 - ASSY, OUTBOARD THROTTLE GRIP
    - [ ] OH4A9A3 - ASSY, INBOARD THROTTLE GRIP
## STICK
- [ ] Mechanical Drawings
  - [ ] TBD
## TOP LEVEL ASSY
- [ ] Mechanical Drawings
  - [ ] OH000-01 - ASSY, OPENHORNET HOME FLIGHT SIMULATOR
  - [ ] #255

jrsteensen, 2021-08-03:
Removed interconnect drawings which are being bumped to beta2 milestone.

rmarrash, 2021-08-04:
Left and Right Console Packages
Issue: Correct angles on "aft Internal Bulkhead" required for smooth installation of remainder of ribs
1) Ensure that the angle of the cut on the bottom of the Aft Internal Bulkhead is 22.1 degrees. This will allow it to lie flat on the console floor at the correct angle and allow the installation of the rest of the ribs to go smoothly.
2 ) Each Rib should be centered on holes in the console floor for perfect alignment.
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

rmarrash, 2021-08-04:
Left and Right Console
Issue: Correct angle of Canopy rail required for smooth transition/fit with Ribs and Rib Covering
Comment: The Angle needs to be 22.5 degrees. Also note, the width of the Canopy rail at its widest point after being cut needs to be ~90mm
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

rmarrash, 2021-08-04:
Lower Instrument Panel Construction
Issue: Angle at the back of "Upper Instrument Panel Mount" critical to proper installation of "right inboard footwell wall and left inboard footwell wall"
Comment: The angle of the cut on the back of the Upper Instrument Panel should be 13 degrees. This will allow the proper overhang of 3.175mm for the Right Inboard footwell wall and 12.78mm for the left Inboard Footwell wall.
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

jrsteensen, 2022-09-21:
Going to track this per-issue in the beta 1 project.

Closed 2022-09-21.

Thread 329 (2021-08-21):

Cabin Pressure Mounting - suggestion

Ben-F111, 2021-08-21:
### Summary:
Alternate suggestion for the Cabin Pressure Alt

### Expected Results/How It Should Work:
A Minor changes is suggested to the Cabin Pressure Indicator Body to allow this to no longer require needing gluing at final assembly

Extending the "Shadow" of the front Bezel to the Cabin Pressure Indicator Body (adding a 3mm lip) allowed this to be screwed 'Sandwiched' to the Lower Center Pedestal Face

see pictures below

### Actual Results/How It Does Work:
Currently it appears once the Cabin Pressure Gauge is constructed, there is no obvious way to attach the bezel to the main body other than gluing, this removes the future chances to correct any issues.

### Screenshots:
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

## More Information
*Add an "X" in the square brackets to check the applicable checkboxs.*
### Category:
*Check one or more items.*
- [X] MCAD (SolidWorks)

### Type:
*Check one item.*
- [ ] Bug
- [X] Feature Enhancement
- [ ] Maintenance
- [ ] Question
- [ ] Documentation
### Applicable End Item:
*Check one item.*
- [ ] Top Level Assembly  
- [X] Lower Instrument Panel (LIP)
- [ ] Main Instrument Panel (MIP)
- [ ] Left Console
- [ ] Right Console
- [ ] Seat
- [ ] Center Tub
- [ ] Flight Stick
- [ ] Throttle
- [ ] General Software
### Associated Filename(s):
Cabin Pressure Indicator Case

jrsteensen, 2021-08-21:
I like it. Lets do it!

jrsteensen, 2021-08-21:
Added a .125 mounting flange to the FWD edge of the case in F929cc9.

Closed 2021-08-21.

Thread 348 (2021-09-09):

FDM vs Resin parts. Heat inserts

Ben-F111, 2021-09-09:
*Please fill out the issue as completely as possible. Be very specific and take your time. The more effort you put in to fill the issue out completely, the quicker we can fix this or look at adding your requested feature.*

### Summary:
The JETT button and bleed air knob are designed for heat inserts.

### Expected Results/How It Should Work:
This works great fir FDM. But if resin printed the cavity for the brass insert needs to be just slightly larger than the insert and epoxy or resin glued in. The holes can be currently enlarged by drill. But the resin chips easy. ESP the hole on the outer edge of the JETT

### Actual Results/How It Does Work:
Can 2 types be produced in the freeze.

And FDM and a resin. For these

### Screenshots:
*Pictures are worth 1000 words. Take some screen grabs of the model, circle things with the snipping tool...you can't put too much info here.
<br>**PRO-TIP:** Just paste the images here.*

## More Information
*Add an "X" in the square brackets to check the applicable checkboxs.*
### Category:
*Check one or more items.*
- [X] MCAD (SolidWorks)
- [ ] ECAD (PCB Design or other electrical hardware)
- [ ] Software - Sketch
- [ ] Software - DCS-BIOS
- [ ] Software - Library
### Type:
*Check one item.*
- [ ] Bug
- [X] Feature Enhancement
- [ ] Maintenance
- [ ] Question
- [ ] Documentation
### Applicable End Item:
*Check one item.*
- [ ] Top Level Assembly  
- [ ] Lower Instrument Panel (LIP)
- [ ] Main Instrument Panel (MIP)
- [X] Left Console
- [X] Right Console
- [ ] Seat
- [ ] Center Tub
- [ ] Flight Stick
- [ ] Throttle
- [ ] General Software
### Associated Filename(s):
*Insert assembly or part file names here, i.e. 123456.sldasm, etc.*

jrsteensen, 2021-09-09:
Can they be pressed in before cure?

Ben-F111, 2021-09-09:
![Uploading 30143570-3866-4CEA-8C47-1A9BB104D5BC.jpeg…]()

Ben-F111, 2021-09-09:
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

Ben-F111, 2021-09-09:
> Can they be pressed in before cure?

No they cant, there is no give, even before UV

russellmm, 2021-09-09:
I don't have a resin printer (yet) but would this type of insert possibly work https://www.mcmaster.com/screw-to-expand-inserts/. Or make the hole larger and expoy it into place?

Ben-F111, 2021-09-09:
you cant put pressure on resin, there is no give, its like a hard plastic or "glass" it shatters / chips, it needs to be glued from what I have found

jrsteensen, 2021-09-09:
This project has made me discover a hatred of simple knobs. 😅

troyfrezze, 2021-09-13:
I have found I can compress the heat set inserts prior to curing using a clamp to press. It's not caused any damage to my prints and once cured, is solidly in place.  I've not tried with the knobs yet, but plan to print them this week and test.

Ben-F111, 2021-09-13:
I would like to see. But I would be worries about the detail in the opposite side. Ie the JETT text. If you can force an insert. You can surely deform the text. Which is the entire reason you resin printed in the first place. Please let us know how you go.

jrsteensen, 2021-10-31:
Fixed bleed air AUG knob in referenced commit.

jrsteensen, 2021-10-31:
On jett button, added a slot to the straight edge cut, since the wall side of the hole penetrated the edge.

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

jrsteensen, 2021-10-31:
Closed with referenced commits.

Closed 2021-10-31.

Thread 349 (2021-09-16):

UIP Hardware Freeze Work

jrsteensen, 2021-09-16:
- [x] Fix Master Mode & READY Buttons on Master Arm PCB/Panel
  - Swap illuminated tactile for Omron B3F-1026 and use 2020 LEDs around indicators.
- [x] Fix EWI PCBs.
  - Swap illuminated tactile for Omron B3F-1026 and use 2020 LEDs around indicators.
  - Fix this interference in the chassis:
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
- [ ] Check clearances for rear side PTH components.
- [x] Add BL PCB to L/R EWI
- [x] Fix EWI buttons to new PCB.
- [x] Add switch guards to FIRE button on EWIs
- [x] Add 3 pin switch connector for EWI SW to DDI Controller
- [x] Integrate ABSIS 2.0 Controllers
- [x] Relocate ETH Switch
- [x] Optimize master arm bracket/module geometry.
- [x] Optimize SPIN panel bracket/module geometry.
- [x] Add new DDI controllers

jrsteensen, 2021-09-17:
Completed with commit 3da87bd.

Closed 2021-09-17.

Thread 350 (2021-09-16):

LIP Hardware Freeze Work

jrsteensen, 2021-09-16:
- [x] New JETT SELECT PCB (to include JETT STATION SELECT PLACARD)
- [x] ADD RUD PED ADJ switch and adjust mechanism
- [x] Give AMPCD CRS/HDG BL one last eval (5mm neopixels TH?)
- [x] Update AMPCD controller to newest version with EWI inputs.
- [x] Redesign IFEI
    - Add backlighting to legends.
    - Convert switches to Omron B3F-1026 and add button BL.
- [x] Integrate VIDEO RECORD BL PCB
- [x] Replace electronics in left LIP Module with updated (ABSIS 2.0) electronics.
- [x] Update and integrate RWR BL PCB
  - Swap illuminated tactile for Omron B3F-1026 and use 2020 LEDs around indicators.
- [x] Update and integrate ECM JETT BL PCB
  - Swap illuminated tactile for Omron B3F-1026 and use 2020 LEDs around indicators.
- [x] Add JETT SEL legend to ECM JETT Button
- [x] Add ABSIS Mega to Lower Center Pedestal to control RWR Control, ECM JETT and CABIN PRESS.
- [x] Modify mounting for Left LIP to clearance new connectors.
- [x] Check clearances for rear side PTH components.
- [ ] Add limit switches to rudder linear actuator.
- [ ] Evaluate UIP/LIP interface (create subassy for UIP/LIP assembly.)

jrsteensen, 2021-09-24:
Completed in dbc3bd9. Closed.

Closed 2021-09-24.

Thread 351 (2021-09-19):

Canopy Bracket Clearance

Lazarus94, 2021-09-19:
*Please fill out the issue as completely as possible. Be very specific and take your time. The more effort you put in to fill the issue out completely, the quicker we can fix this or look at adding your requested feature.*

### Summary:
There is a lack of clearance for the two extra buttons on the Canopy Bracket. The fit is too tight for the buttons to go in without significant force.

### Expected Results/How It Should Work:
The buttons should slide in with some resistance but ultimately be fastened by the buttons' nut.

### Screenshots:
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

### Category:
*Check one or more items.*
- [ X] MCAD (SolidWorks)
- [ ] ECAD (PCB Design or other electrical hardware)
- [ ] Software - Sketch
- [ ] Software - DCS-BIOS
- [ ] Software - Library
### Type:
*Check one item.*
- [X ] Bug
- [ ] Feature Enhancement
- [ ] Maintenance
- [ ] Question
- [ ] Documentation
### Applicable End Item:
*Check one item.*
- [ ] Top Level Assembly  
- [ ] Lower Instrument Panel (LIP)
- [ ] Main Instrument Panel (MIP)
- [ ] Left Console
- [X ] Right Console
- [ ] Seat
- [ ] Center Tub
- [ ] Flight Stick
- [ ] Throttle
- [ ] General Software
### Associated Filename(s):
Canopy Bracket: Canopy Bracket
Button: PV2F24011 - SWITCH, PUSHBUTTON, FLAT, OFF-(ON)

jrsteensen, 2021-09-19:
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

This switch was at 16mm DIA hole, which was the bottom end of the tolerance. Bumped to 16.1 DIA hole, to bring it to nominal tolerance.

This switch does not have a anti-rotation feature, so it relies on being a low gap slip fit and will require some level of force to install.

Closed with commit 8bc7638.

Closed 2021-09-19.

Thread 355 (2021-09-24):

Major Subcomponent Interfaces

jrsteensen, 2021-09-24:
### Summary:
Add hardware to secure all major subcomponents to each other and add optional casters and support.

- **LIP/UIP/LC/RC:** Semi-permament mounting (utilize hardware to secure to each other)
- **Center Tub to RC/LC/LIP:** Temporary/Duration of flight mounting

[Swivel Casters](https://www.mcmaster.com/22785t63/) ([ALT](https://www.mcmaster.com/78155T31/))
[Swivel Casters with Brake](https://www.mcmaster.com/22785T68/) ([ALT](https://www.mcmaster.com/78155T32/))
[Lateral Floor Stiffener - 2.00 x .125 ALU plate](https://www.mcmaster.com/8975K582/) (Casters mount thru this)
[Longitudinal Stiffeners - 1.0 x 1.0 x .0625 6061 L-channel](https://www.mcmaster.com/8982K39/)

Make floating nutplates for semi-permanent interfaces with a [3/8-16 weld nut](https://www.mcmaster.com/98001A145/) and a 3d printed retainer.

Possible handles to use on consoles for pulling user in and out of the rest of the pit: [One piece large](https://www.mcmaster.com/1726A95/) / [individual handles](https://www.mcmaster.com/1764A31/)

Utilize either [25KG 12V/5V electromagnets](https://www.digikey.com/en/products/detail/adafruit-industries-llc/3875/9603614) with [3" cup washers](https://www.mcmaster.com/92856A105/) for locking center tub to consoles, or use [Adafruit 1512](https://www.adafruit.com/product/1512) (also available from digikey) locking solenoid to lock center tub to consoles utilizing a [strike plate](https://www.mcmaster.com/80185A61/) in the center tub with the solenoids in the consoles.

Either of these options serve as a temporary locking mechanism to allow the center tub to roll aft and free of the rest of the pit.

- [ ] Add fasteners for LIP/UIP Interface
- [ ] Add fasteners for LIP/RC Interface
- [ ] Add fasteners for LIP/LC Interface
- [ ] Add latching interface for CT to LC/RC/LIP
- [ ] Add handles to LC/RC to pull/push CT out from center of pit.

#### Electromagnet Option:
##### Pros
- Alignment of magnet vs target less critical/self-correcting.

##### Cons
- Requires constant power to hold.
- May create a localized force when mounted that could damage consoles via fatigue over time.

#### Lock Solenoid Option:
##### Pros
- Only requires power to release.
- Device only causes a small amount of force on the localized structure.

##### Cons
- Requires better alignment between components, but still fairly loose. If there is a power loss, cannot unlock and will have to exit via seat/console.

## More Information
### Category:
- [X] MCAD (SolidWorks)
### Type:
- [X] Feature Enhancement
### Applicable End Item:
- [X] Lower Instrument Panel (LIP)
- [X] Main Instrument Panel (MIP)
- [X] Left Console
- [X] Right Console
- [X] Center Tub

jrsteensen, 2022-08-09:
It was determined that due to wildly varying user requirements/desired end states that we will leave provisions for mounting but leave final console to console mounting to the end users.

Closed 2022-08-09.

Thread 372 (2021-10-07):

Swap pin 2 and 3 of Q1 on DDI/AMPCD Controller

jrsteensen, 2021-10-07:
### Summary:
Swap pins 2 and 3 of Q1 on DDI/AMPCD controller.

**Workaround:** If you already have the current version of the controller, just install the through hole MOSFET with existing pin 1 to pin 1, pin 2 of the MOSFET to pin 3, and pin 3 of the MOSFET to pin 2 of the PCB.

jrsteensen, 2021-10-08:
Manufacturing files not updated. Will require manufacturing files before issue can be closed. (Gerber's, BOM, P&P file)

[JLCPCB Instructions 1](https://support.jlcpcb.com/article/149-how-to-generate-gerber-and-drill-files-in-kicad)
[JLCPCB Instructions 2](https://support.jlcpcb.com/article/84-how-to-generate-the-bom-and-centroid-file-from-kicad)

L-Walker, 2021-10-17:
Solved in commit c860438

Changed - Layout of silkscreen items to optimize readability and aesthetics.
Added - OH Logo on front silkscreen
Added - New manufacturing files (Have been tested going into JLCPCB)
Removed - Old manufacturing files.
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

Closed 2021-10-17.

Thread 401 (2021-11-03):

Painting MDF adds some thickness that may affect tolerances when assembling pieces

russellmm, 2021-11-03:
When you are assemblying the pit after painting, the thickness of the paint needs to be accounted for with the tight tolorence of the design. For example, when installing the inbord spacers, the wings fit very tight over the MDF (see picture). This can also affect the spacing of things like the lower stringers

### Summary:
See above

### Expected Results/How It Should Work:
May consider painting the parts after combing them together or leaving the connecting points unpainted until later. Could also consider adding a little tolerence to some of the pieces such as the inboard spacers.

### Actual Results/How It Does Work:
Thick paint could cause misalignment of the ribs due to stringers pushed pieces wider than expected (by the thickness of the paint).
You inboard spacer wings can break when trying to install them on the MDF
What I did was - slightly cut the stringers shorter than spec'd and filed down the MDF slightly around where the inboard spacers attach to the MDF ribs

### Screenshots:

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

## More Information
*Add an "X" in the square brackets to check the applicable checkboxs.*
### Category:
*Check one or more items.*
- [ x] MCAD (SolidWorks)
- [ ] ECAD (PCB Design or other electrical hardware)
- [ ] Software - Sketch
- [ ] Software - DCS-BIOS
- [ ] Software - Library
### Type:
*Check one item.*
- [ ] Bug
- [ ] Feature Enhancement
- [ ] Maintenance
- [ ] Question
- [ ] Documentation
### Applicable End Item:
*Check one item.*
- [ ] Top Level Assembly  
- [x ] Lower Instrument Panel (LIP)
- [ ] Main Instrument Panel (MIP)
- [ x] Left Console
- [ x] Right Console
- [ ] Seat
- [ ] Center Tub
- [ ] Flight Stick
- [ ] Throttle
- [ ] General Software
### Associated Filename(s):
*Insert assembly or part file names here, i.e. 123456.sldasm, etc.*

jrsteensen, 2021-11-14:
I've spent some time thinking about this, and to not increase gaps even further when building with metric materials, I'm not going to integrate this into the model. Instead, we will address this as a flag note in the drawing.

- [ ] Add flag note to console drawings referencing rib interfacing printed parts. "Part printed to maximum material condition. Removal of .02" MAX material on MDF interfacing surfaces authorized."

jrsteensen, 2022-09-24:
Added note to #539, #541, #512

Closed 2022-09-24.

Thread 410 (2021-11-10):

AV Cool BL PCB Issues

jrsteensen, 2021-11-10:
- MCAD Change: Make connectors pigtails
- Deconflict capacitor from switch body.
- Extend mounting hardware and add nut to it.

jrsteensen, 2022-08-07:
Converted connectors to pigtails.
No need for HW change.
Do not install cap on this PCB - one BL board without it will not affect system. (No better place to move it to.)
Updated in AV Cool v5

jrsteensen, 2022-08-08:
Evaluate AV COOL and LDG CHKLST. Interferences between LEDs and lightplates.

jrsteensen, 2022-08-19:
Shortened HW to .625 L to eliminate interferences and using the existing inserts. No Nut REQD. Also, pigtailed connectors. Completed in RC v101.

Closed 2022-08-19.

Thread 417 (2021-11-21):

Butt Kicker Amp remote

dnamaster2000, 2021-11-21:
*Please fill out the issue as completely as possible. Be very specific and take your time. The more effort you put in to fill the issue out completely, the quicker we can fix this or look at adding your requested feature.*

### Summary:
Here are the details for the amp remote on the X502-1

### Expected Results/How It Should Work:
N/A

### Actual Results/How It Does Work:
Remote uses an RJ-11 connector, i used an old phone cable, cut in half, the wire color in any phone cable should be the same

Pin 1 - NA
Pin 2 - GND
Pin 3 - GND
Pin 4 - Variable
Pin 5 - Positive
Pin 6 - NA

Cut cable in half (or at required length) wire Black/Red together on one side of the POT, Green to the center pin, and Yellow to the other pin.

### Screenshots:
*Pictures are worth 1000 words. Take some screen grabs of the model, circle things with the snipping tool...you can't put too much info here.
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

## More Information
*Add an "X" in the square brackets to check the applicable checkboxs.*
### Category:
*Check one or more items.*
- [ ] MCAD (SolidWorks)
- [X] ECAD (PCB Design or other electrical hardware)
- [ ] Software - Sketch
- [ ] Software - DCS-BIOS
- [ ] Software - Library
### Type:
*Check one item.*
- [ ] Bug
- [ ] Feature Enhancement
- [ ] Maintenance
- [ ] Question
- [X] Documentation
### Applicable End Item:
*Check one item.*
- [ ] Top Level Assembly  
- [ ] Lower Instrument Panel (LIP)
- [ ] Main Instrument Panel (MIP)
- [ ] Left Console
- [ ] Right Console
- [X] Seat
- [ ] Center Tub
- [ ] Flight Stick
- [ ] Throttle
- [ ] General Software
### Associated Filename(s):
*Insert assembly or part file names here, i.e. 123456.sldasm, etc.*

jrsteensen, 2022-03-28:
I was starting on this, but realized it might be a good project for a contributor. What we would need is a small printed frame that would mount a legend plate with a P081N-271F2CBR10K or P0915N-FC20BR10K pot, and a COTS RJ-11 breakout jack on the back, so we can route this from the amp to the breakout with a RJ11 bulkhead, then a RJ11 cable from the bulkhead to the remote, which will be located on the Left Console Aft interior bulkhead, fairly low to prevent interference with future console lighting. I've already started an assembly/folder in the left folder for this as the OH4A10-1.

jrsteensen, 2022-08-03:
Completed in LC v93.

Closed 2022-08-03.

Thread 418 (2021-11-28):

AMPCD Board Clearance

dnamaster2000, 2021-11-28:
*Please fill out the issue as completely as possible. Be very specific and take your time. The more effort you put in to fill the issue out completely, the quicker we can fix this or look at adding your requested feature.*

### Summary:
There is not enough clearance in the AMPCD for the board to fit, some of the supports also line up with buttons, leaving 0 clearance between the board and the part.

### Expected Results/How It Should Work:
board should fit in to the backplate

### Actual Results/How It Does Work:
board through hole components interfere with backplate

### Screenshots:
*Pictures are worth 1000 words. Take some screen grabs of the model, circle things with the snipping tool...you can't put too much info here.
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

## More Information
*Add an "X" in the square brackets to check the applicable checkboxs.*
### Category:
*Check one or more items.*
- [x ] MCAD (SolidWorks)
- [ ] ECAD (PCB Design or other electrical hardware)
- [ ] Software - Sketch
- [ ] Software - DCS-BIOS
- [ ] Software - Library
### Type:
*Check one item.*
- [ x] Bug
- [ ] Feature Enhancement
- [ ] Maintenance
- [ ] Question
- [ ] Documentation
### Applicable End Item:
*Check one item.*
- [ ] Top Level Assembly  
- [x ] Lower Instrument Panel (LIP)
- [ ] Main Instrument Panel (MIP)
- [ ] Left Console
- [ ] Right Console
- [ ] Seat
- [ ] Center Tub
- [ ] Flight Stick
- [ ] Throttle
- [ ] General Software
### Associated Filename(s):
*Insert assembly or part file names here, i.e. 123456.sldasm, etc.*

jrsteensen, 2021-11-28:
Will add greater clearance to rear bezel that the PCB seats into.

jrsteensen, 2021-11-28:
Closed with referenced commit.

Closed 2021-11-28.

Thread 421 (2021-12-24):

Addition Support for RWR Control PCB

bnepethomas, 2021-12-24:
### Summary:
The RWR PCB needs additional support  near the BIT FAIL button as the PCB excessively flexes when the button is pressed.  Or as a workaround add support material at the rear of the PCB (as per photo)

### Expected Results/How It Should Work:
Add a extension to the PCB along with a new heat nut in the MCAD above the DISP TYPE switch

### Actual Results/How It Does Work:

### Screenshots:
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

## More Information
*Add an "X" in the square brackets to check the applicable checkboxs.*
### Category:
*Check one or more items.*
- [X] MCAD (SolidWorks)
- [X ] ECAD (PCB Design or other electrical hardware)
- [ ] Software - Sketch
- [ ] Software - DCS-BIOS
- [ ] Software - Library
### Type:
*Check one item.*
- [ ] Bug
- [X] Feature Enhancement
- [ ] Maintenance
- [ ] Question
- [ ] Documentation
### Applicable End Item:
*Check one item.*
- [ ] Top Level Assembly  
- [X] Lower Instrument Panel (LIP)
- [ ] Main Instrument Panel (MIP)
- [ ] Left Console
- [ ] Right Console
- [ ] Seat
- [ ] Center Tub
- [ ] Flight Stick
- [ ] Throttle
- [ ] General Software
### Associated Filename(s):

jrsteensen, 2022-07-17:
@celemourn, this one is all yours!

jrsteensen, 2022-08-07:
Added .125 THK Support Plate behind PCB and increased PCB mounting HW length to compensate. Fixed in RWR Control ASSY v4.

Closed 2022-08-07.

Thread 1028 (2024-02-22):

Missing dimension on the Wing Fold assembly drawing

mmanlove1, 2024-02-22:
*Please fill out the issue as completely as possible. Be very specific and take your time. The more effort you put in to fill the issue out completely, the quicker we can fix this or look at adding your requested feature.*

### Summary:
On page 6 of the OH5A2A2-1 - ASSY, WING FOLD HANDLE - v7 drawing, the dimension to locate the groove for the ball-nose spring plunger detent from the end of the shaft is missing.

### Expected Results/How It Should Work:
Add the dimension from the end of the shaft to the location of the detent groove.

### Actual Results/How It Does Work:
(Explain how it actually works here. Be very specific.)

### Screenshots:
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

## More Information
*Add an "X" in the square brackets to check the applicable checkboxs.*
### Category:
*Check one or more items.*
- [ ] MCAD (SolidWorks)
- [ ] ECAD (PCB Design or other electrical hardware)
- [ ] Software - Sketch
- [ ] Software - DCS-BIOS
- [ ] Software - Library
### Type:
*Check one item.*
- [ ] Bug
- [ ] Feature Enhancement
- [ ] Maintenance
- [ ] Question
- [ X] Documentation
### Applicable End Item:
*Check one item.*
- [ ] Top Level Assembly  
- [ ] Lower Instrument Panel (LIP)
- [ ] Main Instrument Panel (MIP)
- [ X] Left Console
- [ ] Right Console
- [ ] Seat
- [ ] Center Tub
- [ ] Flight Stick
- [ ] Throttle
- [ ] General Software
### Associated Filename(s):
OH5A2A2-1 - ASSY, WING FOLD HANDLE_-_v7.pdf

jrsteensen, 2024-02-25:
Drawing error - there is no notch machined in. Its the hidden lines showing the profile of the hole.

Redrew for clarity.

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

jrsteensen, 2024-02-25:
Closed with 6b44c8de6b8277d7a5f8693b546fd0659113636a

Closed 2024-02-25.

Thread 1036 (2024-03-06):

[Bug]: Radar Altimeter Servo susceptible to burning out due to over voltage.

kbastronomics, 2024-03-06:
### Discord Username

Sandra

### Bug Summary

The Micro servo used to the control the FLAG in the Radar Altimeter is a 2.8-4.2 volt (see spec below)
driving this servo at 5V can cause it to burn out.

Specifications:
Voltage: 2.8V-4.2V
Speed:0.07s / 60 ° 2.8V and 0.05s/60 ° 4.2V
Torque:0.05Kg/2.5V and 0.075Kg/4.2V
Size: 16.3mm x 13.5mm x 6.3mm
Weight: 1.9g
Plug: micro JST 1.00 pitch

### Expected Results

The servo should be driven within its specified range of 2.8.4,2 volts

### Actual Results

in talking with Ben-F111 he has reported that he's blown multiple servos due to over voltage.
We should like the voltage going to the servo.   this is both at the +V pin and the PWM pin.

### Screenshots/Images/Files

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

### Applicable Part Numbers

HK-5320 - SERVO, DIGITAL, ULTRA-MICRO, 1.7g

### Release Version

v0.2.0

### Category

Electrical (PCBs/Wiring/etc)

### Applicable End Item(s)

Right Console (RCON)

### Built to print?

- [X] I built (or attempted to build) the part to the OpenHornet print without any deviations.
- [ ] I am not building this part to the OH print. (List deviations in detail in the Miscellaneous Info text area below.)

### Miscellaneous Info

_No response_

jrsteensen, 2024-03-09:
@kbastronomics Do we have a PN for the PCB side micro JST connector?

A quick look is that there are 1mm spacing JST connectors, but micro JST is 1.25mm spacing. So need a little clarification.

Updated the circuit to the following:
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

jrsteensen, 2024-03-09:
Looks like a Micro JST with 1.25mm spacing.

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

jrsteensen, 2024-03-10:
Need to flip pinout; didn't realize pinout in datasheet was viewed from below the PCB.

Closed 2024-03-10.

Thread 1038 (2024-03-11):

[FEATURE REQUEST]: Update 5A7A1-SNSR_PANEL Wiring

Arribe, 2024-03-11:
### Discord Username

Arribe

### Feature/Enhancement Summary

Update the Sensor Panel to either use 2 ALEs or switch to an ESP32.  Not hooking up the Radar and INS rotaries' off positions makes coding complexity logic challenging and will increase the effort it will take to maintain the OH software.  If the off positions were connected to pins then the logic would be trivial built-in DCSBios multi-position switch calls.

### Screenshots/Images/Files

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

### Justification

Keeping track of 2 separate rotaries to deduce if they're pointed to off, and not just in the middle of a rotation adds to the code's complexity.  This panel also needs logic for the LTD/R mag-switch.  The amount of time and effort to maintain or update the code to add new features / HID support will only be even more complex.

### Applicable Part Numbers

5A7A1-SNSR_PANEL

### Release Version

v0.2.0

### Category

Electrical (PCBs/Wiring/etc)

### Applicable End Item(s)

Right Console (RCON)

### Miscellaneous Info

_No response_

kbastronomics, 2024-03-11:
I don't believe adding another ALE will solve this.
But you can test this, however the code is basically bypassing DCS-BIOS and writing its own method of controlling the messages sent to DCS (see loop() in the code) .  we should stick with stock DCS-BIOS calls unless there is a specific documented reason to not do so.

The use of arrays is also complicating troubleshooting as you cannot see clearly what's happening.

Try using a supplied DCS Arduino Library call before we say there is an issue. which has code already for a non-shorting switch?

const byte radarSwPins[3] = { RDR_STBY, RDR_OPR, RDR_EMERG };
DcsBios::SwitchMultiPos radarSw("RADAR_SW", radarSwPins, 4);

const byte insSwPins[7] = { INS_CV, INS_GND, INS_NAV, INS_IFA, INS_GYRO, INS_GB, INS_TEST };
DcsBios::SwitchMultiPos insSw("INS_SW", insSwPins, 8);

if issue persist, we should open an issue with DCS-BIOS

but even so,
adding in the off pin will not solve this the switch used is a non-shorting switch, that means between switch changes nothing is connected, not that the off pin is connected.   (something be hidden due to use of arrays)

but to test connect the off pin to another I/O.   it will disable one of the switches so make sure to disable that check
example LST_ON
comment out
DcsBios::Switch2Pos lstNflrSw("LST_NFLR_SW", LST_ON);
now use LST_ON in your code for the off position as a test.
does it solve the issue???

kbastronomics, 2024-03-11:
I think i see what you're saying now.
that the OFF position and the Non-Shorting appear as the same event

kbastronomics, 2024-03-11:
one work around but would mean not using DCS-BIOS SwitchMultiPos would be to connect off to pins INS_CV and INS_TEST
then check for both ON for the off position. otherwise if only 1 is on then you're in that position.

Arribe, 2024-03-11:
I ran a second pro micro hooked up to just the radar switch for 8 months. This allowed for both rotaries to have all pins connected. With all the positions connected the stock DCSBios calls work as you suggest, and is what I had for my personal code.

kbastronomics, 2024-03-11:
i wonder if we'll ever implement the pull function of that knob

Arribe, 2024-03-28:
Not needed, for this panel the code can overcome the PIN_NC limitations.

Closed 2024-03-28.

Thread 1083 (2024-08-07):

[Bug]: multiposition rotary switches: Every position needs a connection.

Higgins-OH, 2024-08-07:
### Discord Username

Higgins

### Bug Summary

Since it isn't possible (at least right now) to program the multiposition switches for DCSBios in a way that the "off" position is recognized without a connection, every single position needs to be connected. The switches missing one connection with available pins on the board are as follows:
- ECM (additional pin for "off" available, for instance by connecting ECM_JETT_SW to D4-A6_J3-6 and optional GND to GND_J3-10)
- RWR Control (additional pin for "RWR_DIS_N" available with D16_J4)
- BLEED AIR (additional pin for "NORM" available if ENG_ON and ENG_TEST are moved to J3)

Connection missing, but not enough available pins:
- RADAR & INS (only one available pin on board: D2; two are needed)
- VIEW ("Cockpit view": no additional pin available on board)

### Expected Results

Every position needs to be recognized by DCSBios. Connection needed.

### Actual Results

The "off" position isn't connected.

### Screenshots/Images/Files

_No response_

### Applicable Part Numbers

OH-Interconnect (here: v13)

### Release Version

v0.2.0

### Category

Electrical (PCBs/Wiring/etc)

### Applicable End Item(s)

Top Level Assembly (TLA)

### Built to print?

- [X] I built (or attempted to build) the part to the OpenHornet print without any deviations.
- [ ] I am not building this part to the OH print. (List deviations in detail in the Miscellaneous Info text area below.)

### Miscellaneous Info

_No response_

Arribe, 2024-08-07:
Issue is in the Software repository, and logged with skunkworks. DCSBios has a PIN_NC option allowing for a single switch pin to not be connected. DCSBios doesn’t handle it correctly, so we’ve coded around that in the current software sketches that have these switches.

Higgins-OH, 2024-08-07:
Alright, I'll give it a try. If it works flawlessly, then the comment can be removed (5A5A1-ECS_PANEL.ino, develop branch):

"@bug The Bleed Air knob rotation bounces to NORM when rotated, potentially needs a hardware resolution to connect the NORM position to an Arduino pin.
*/"

Arribe, 2024-08-07:
Not 100% sure about removing the comment. Out of all of the rotary switches the bleed air knob is the toughest for me to rotate within the debounce window.  The knob doesn’t have a definite click and from months of use I’ve had it bounce around. In practice it’s not that big a deal, because having it bounce between positions while rotating doesn’t really mess up the sim like if the INS bounces to off and the Jett losses qual. If others have a different experience for bleed air then we can remove the bug, until then I was just calling it out for awareness.

kbastronomics, 2024-08-09:
> Issue is in the Software repository, and logged with skunkworks. DCSBios has a PIN_NC option allowing for a single switch pin to not be connected. DCSBios doesn’t handle it correctly, so we’ve coded around that in the current software sketches that have these switches.

What was the issue that was opened with DCS-BIOS,  do they plan a fix?
looking at the "FIX" here, any change to DCS-BIOS could break it including a change to PIN_NC.

kbastronomics, 2024-08-09:
it was #57, and #58 they've not accepted or done anything with either

Closed 2024-08-07.

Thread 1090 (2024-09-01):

[FEATURE REQUEST]: Backlight LEDs in close vicinity to switches are prone to blinding pilot

Higgins-OH, 2024-09-01:
### Discord Username

Higgins

### Feature/Enhancement Summary

Some backlight LEDs are placed in such a way (and are not being covered by the panel) that they might blind the pilot.

### Screenshots/Images/Files

Example: Master Arm panel.
The LED on the left of the switch (bottom arrow) shines directly into the pilot's eye. In this case I covered it with black tape.
(The other two arrows mark where the backplate should have been closer to the LEDs to prevent light bleeding when there is an error margin between lightplate and backplate.)

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

### Justification

Because the light plate holes' diameters are big enough for the nut to easily fit, some of the LEDs aren't covered by the light plate or the engraving plate.
In some situations (especially when everything is dark and the panels are lit) some LEDs are able to light into the pilot's eye directly.

Since a redesign of the panels is unnecessary or plain impossible, the quick'n'dirty way of putting some tape of the edges of said LEDs will help.
Alternatively, a very thin but light-tight washer for the switches would do the trick too.

### Applicable Part Numbers

switches on backlit panels

### Release Version

v0.2.0

### Category

Mechanical (Structure/Panels/Mechanisms)

### Applicable End Item(s)

Top Level Assembly (TLA)

### Miscellaneous Info

_No response_

jrsteensen, 2024-09-09:
Add lightproofing general practices section to `OH-SPEC-001 - COMPONENT FABRICATION METHODS`.

Recommend keeping bench stock:
1. [Permatex 85120 Liquid Electrical Tape](https://www.permatex.com/products/adhesives-and-sealants/specialty-adhesives-removers/permatex-liquid-electrical-tape/)
2. [Permatex 82180 Black RTV](https://www.permatex.com/products/gasketing/black-gasket-makers/permatex-ultra-black-rtv-silicone-gasket-maker-3-35-oz/)
3. [Soft Ø1mm Rubber O-Ring Stock](https://www.mcmaster.com/1209N1/)
4. Aluminum Foil
5. Electrical Tape

Closed 2024-09-09.

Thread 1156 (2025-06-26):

[FEATURE REQUEST]: Replace threads of PARK BRK and WING FOLD

eHanseJoerg, 2025-06-26:
### Discord Username

Ulukaii

### Feature/Enhancement Summary

PARK BRK and WING FOLD handles are fastened to their consoles via large tubed threads, which seem to be non-standardized threads.

The specified material for the nut and the thread is PETG. However, I found that the PETG tears apart easily if screw is fastened moderately tight.

The idea is to replace the thread iwth a standard 9/16"-12 UNC thread, which would enable easy CNCing of the part and using a COTS steel nut.

### Screenshots/Images/Files

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

### Justification

Improve mechanical properties and stability of the build

### Applicable Part Numbers

OH4A3A2-1; OH5A2A2-1

### Release Version

v0.2.0

### Category

Mechanical (Structure/Panels/Mechanisms)

### Applicable End Item(s)

Top Level Assembly (TLA)

### Miscellaneous Info

_No response_

jrsteensen, 2025-07-27:
Yeah, this is a print orientation or settings issue, not a failure of the design. Lots and lots of successful prints and uses on this one.

Closed 2025-07-27.

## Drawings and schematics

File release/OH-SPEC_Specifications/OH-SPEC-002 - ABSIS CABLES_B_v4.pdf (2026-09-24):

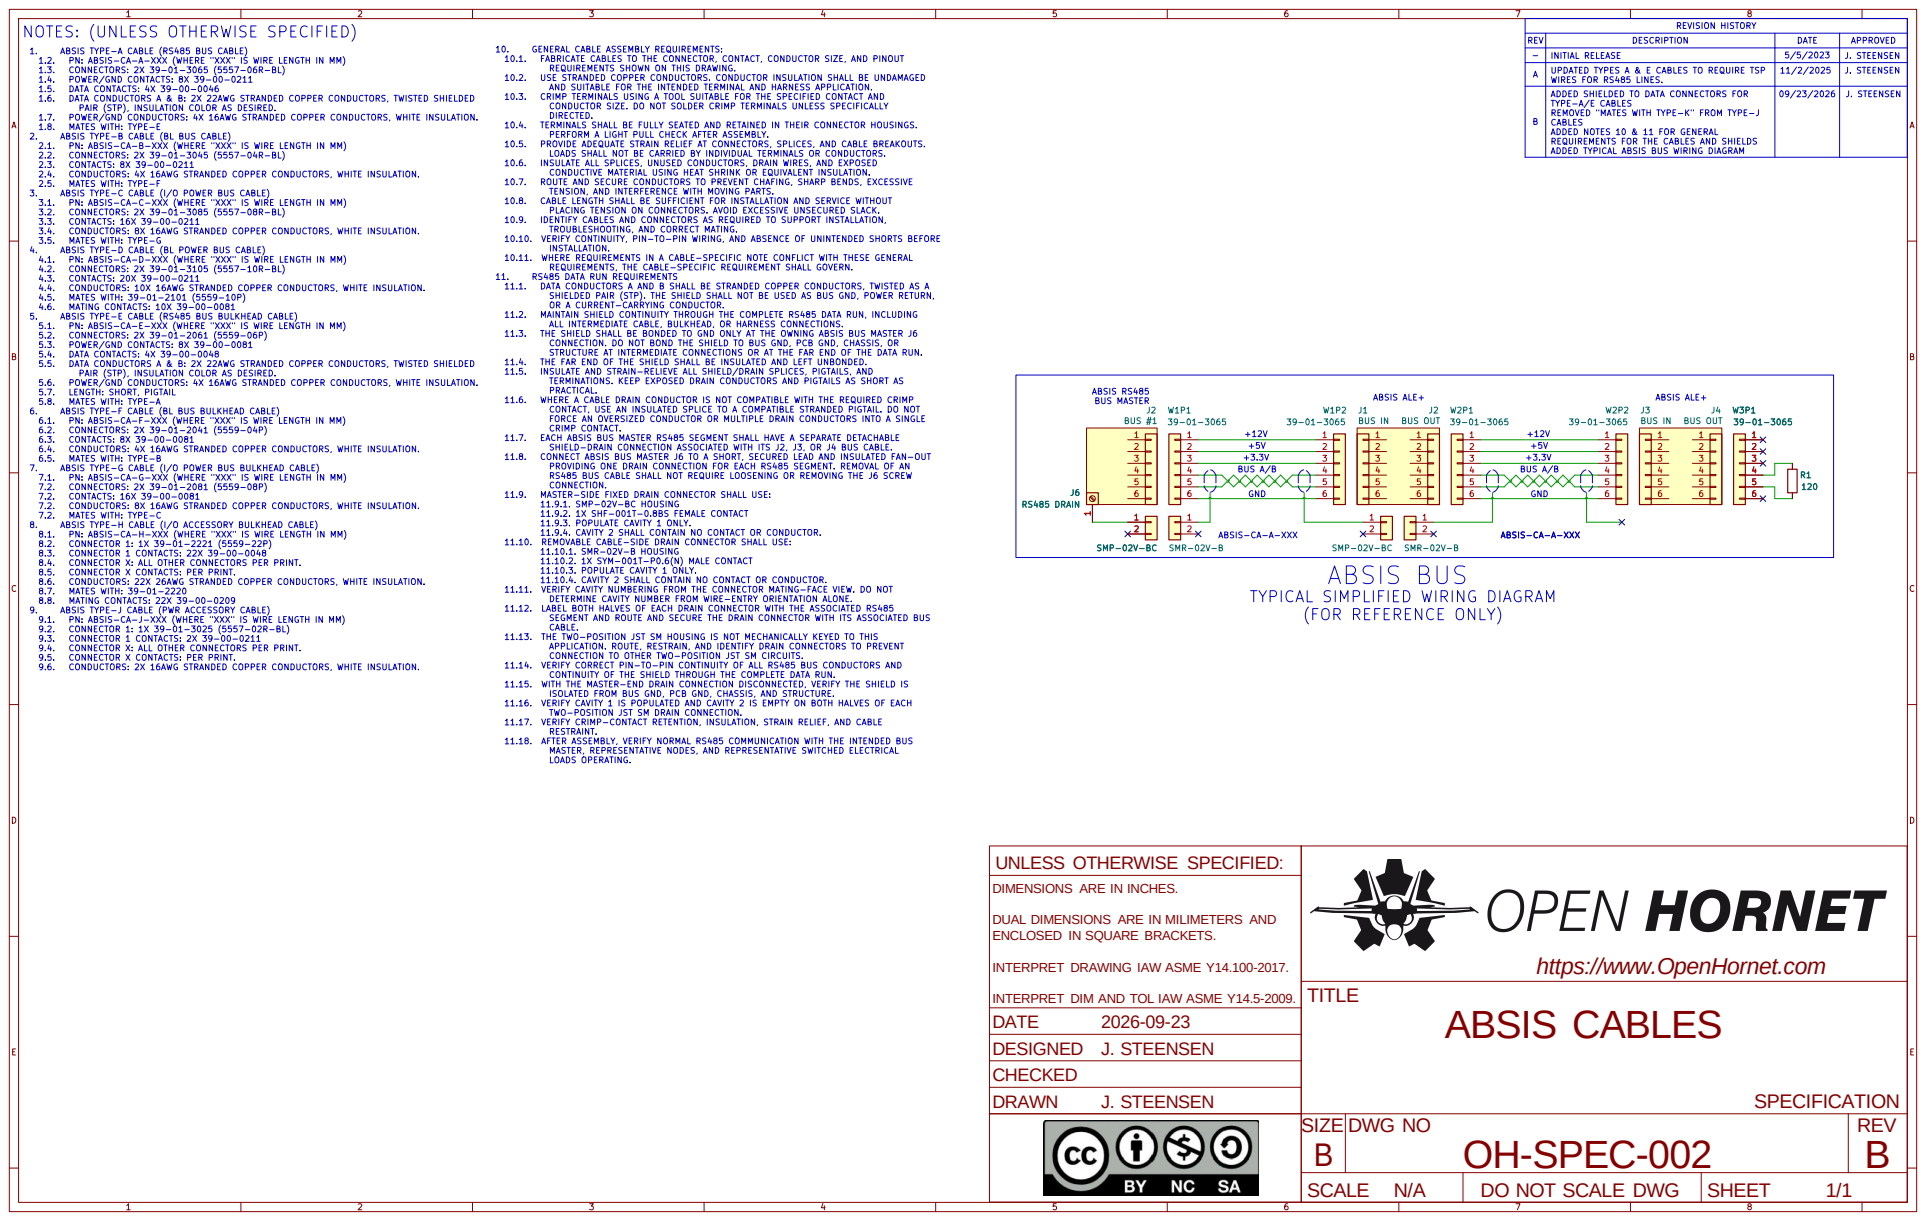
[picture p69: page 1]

A | UPDATED TYPES A & E CABLES TO REQUIRE TSP WIRES FOR RS485 LINES. | 11/2/2025 | J. STEENSEN

B | ADDED SHIELDED TO DATA CONNECTORS FOR TYPE-A/E CABLES REMOVED "MATES WITH TYPE-K" FROM TYPE-J CABLES ADDED NOTES 10 & 11 FOR GENERAL REQUIREMENTS FOR THE CABLES AND SHIELDS ADDED TYPICAL ABSIS BUS WIRING DIAGRAM | 09/23/2026 | J. STEENSEN

TROUBLESHOOTING, AND CORRECT MATING. 10.10. VERIFY CONTINUITY, PIN-TO-PIN WIRING, AND ABSENCE OF UNINTENDED SHORTS BEFORE

+5V TYPICAL SIMPLIFIED WIRING DIAGRAM

RS485 BUS CABLE SHALL NOT REQUIRE LOOSENING OR REMOVING THE J6 SCREW

11.9.2. 1X SHF-001T-0.8BS FEMALE CONTACT 11.9.3. POPULATE CAVITY 1 ONLY. 11.9.4. CAVITY 2 SHALL CONTAIN NO CONTACT OR CONDUCTOR. 11.10. REMOVABLE CABLE-SIDE DRAIN CONNECTOR SHALL USE: 11.10.1. SMR-02V-B HOUSING

11.10.2. 1X SYM-001T-P0.6(N) MALE CONTACT 11.10.3. POPULATE CAVITY 1 ONLY. 11.10.4. CAVITY 2 SHALL CONTAIN NO CONTACT OR CONDUCTOR. 11.11. VERIFY CAVITY NUMBERING FROM THE CONNECTOR MATING-FACE VIEW. DO NOT DETERMINE CAVITY NUMBER FROM WIRE-ENTRY ORIENTATION ALONE. 11.12. LABEL BOTH HALVES OF EACH DRAIN CONNECTOR WITH THE ASSOCIATED RS485

SEGMENT AND ROUTE AND SECURE THE DRAIN CONNECTOR WITH ITS ASSOCIATED BUS CABLE. 11.13. THE TWO-POSITION JST SM HOUSING IS NOT MECHANICALLY KEYED TO THIS

APPLICATION. ROUTE, RESTRAIN, AND IDENTIFY DRAIN CONNECTORS TO PREVENT CONNECTION TO OTHER TWO-POSITION JST SM CIRCUITS. 11.14. VERIFY CORRECT PIN-TO-PIN CONTINUITY OF ALL RS485 BUS CONDUCTORS AND

CONTINUITY OF THE SHIELD THROUGH THE COMPLETE DATA RUN. 11.15. WITH THE MASTER-END DRAIN CONNECTION DISCONNECTED, VERIFY THE SHIELD IS

ISOLATED FROM BUS GND, PCB GND, CHASSIS, AND STRUCTURE. 11.16. VERIFY CAVITY 1 IS POPULATED AND CAVITY 2 IS EMPTY ON BOTH HALVES OF EACH

TWO-POSITION JST SM DRAIN CONNECTION. 11.17. VERIFY CRIMP-CONTACT RETENTION, INSULATION, STRAIN RELIEF, AND CABLE RESTRAINT. 11.18. AFTER ASSEMBLY, VERIFY NORMAL RS485 COMMUNICATION WITH THE INTENDED BUS MASTER, REPRESENTATIVE NODES, AND REPRESENTATIVE SWITCHED ELECTRICAL

UNLESS OTHERWISE SPECIFIED:
DIMENSIONS ARE IN INCHES.

DUAL DIMENSIONS ARE IN MILIMETERS AND
ENCLOSED IN SQUARE BRACKETS.

INTERPRET DRAWING IAW ASME Y14.100-2017.

https://www.OpenHornet.com
ABSIS CABLES

INTERPRET DIM AND TOL IAW ASME Y14.5-2009.
DESIGNED
CHECKED
DRAWN

SIZE DWG NO B | OH-SPEC-002 | REV B

SCALE N/A | DO NOT SCALE DWG | SHEET 1/1

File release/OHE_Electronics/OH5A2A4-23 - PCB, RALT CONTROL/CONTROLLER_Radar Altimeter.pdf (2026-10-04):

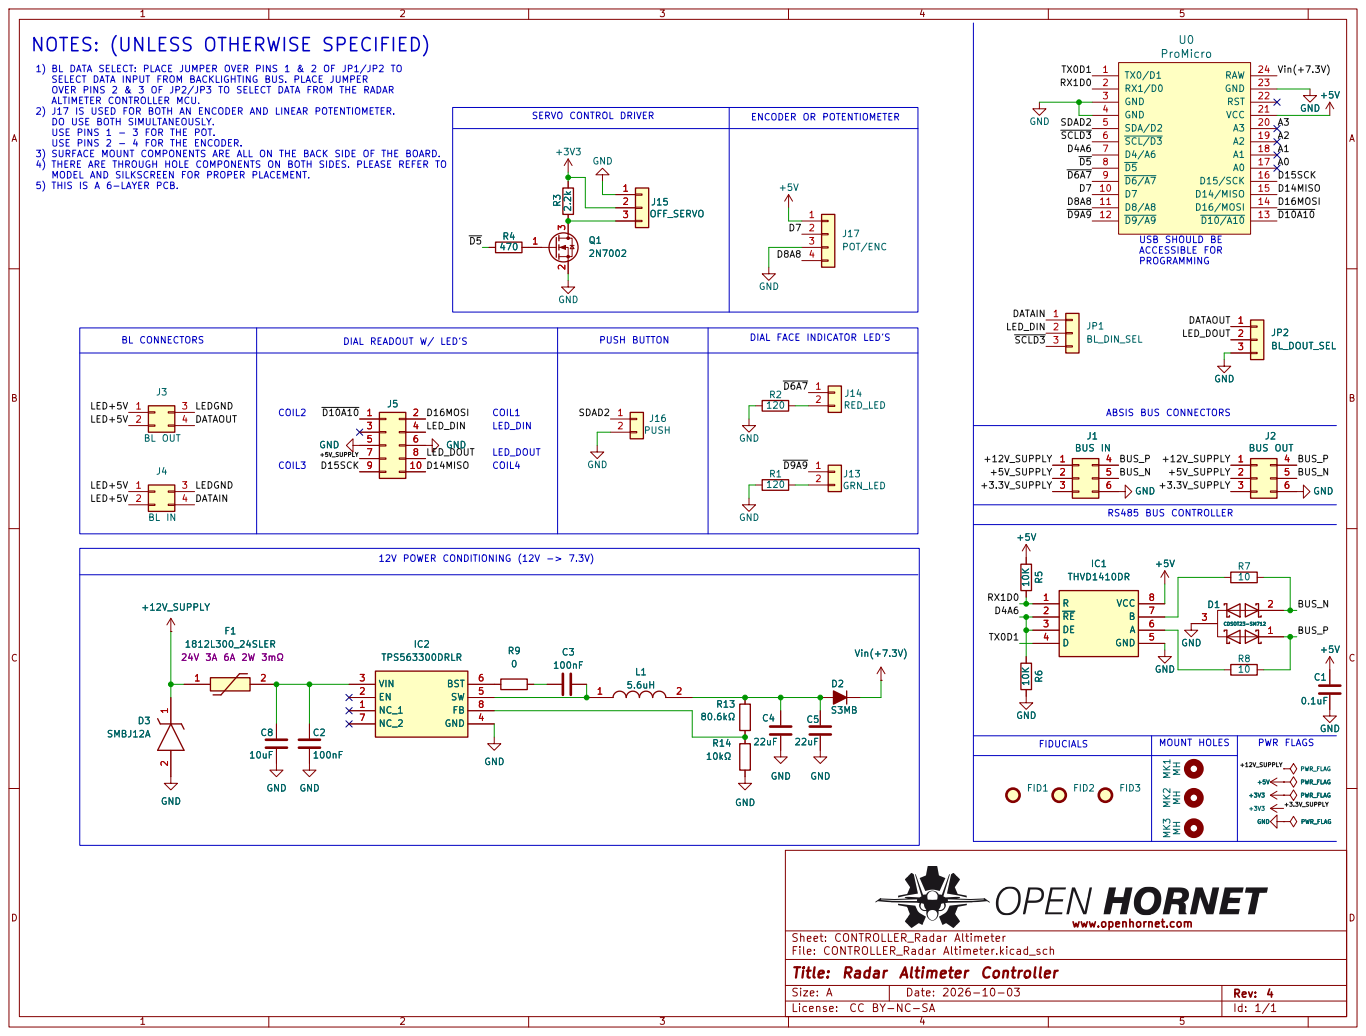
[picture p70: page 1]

ALTIMETER CONTROLLER MCU. 2) J17 IS USED FOR BOTH AN ENCODER AND LINEAR POTENTIOMETER. DO USE BOTH SIMULTANEOUSLY. USE PINS 1 - 3 FOR THE POT. USE PINS 2 - 4 FOR THE ENCODER. 3) SURFACE MOUNT COMPONENTS ARE ALL ON THE BACK SIDE OF THE BOARD. 4) THERE ARE THROUGH HOLE COMPONENTS ON BOTH SIDES. PLEASE REFER TO MODEL AND SILKSCREEN FOR PROPER PLACEMENT. 5) THIS IS A 6-LAYER PCB. NOTES: (UNLESS OTHERWISE SPECIFIED)

1) BL DATA SELECT: PLACE JUMPER OVER PINS 1 & 2 OF JP1/JP2 TO
SELECT DATA INPUT FROM BACKLIGHTING BUS. PLACE JUMPER OVER PINS 2 & 3 OF JP2/JP3 TO SELECT DATA FROM THE RADAR

Sheet: CONTROLLER_Radar Altimeter
File: CONTROLLER_Radar Altimeter.kicad_sch
Title: Radar Altimeter Controller

Size: A | Rev: 4
License: CC BY-NC-SA | Id: 1/1

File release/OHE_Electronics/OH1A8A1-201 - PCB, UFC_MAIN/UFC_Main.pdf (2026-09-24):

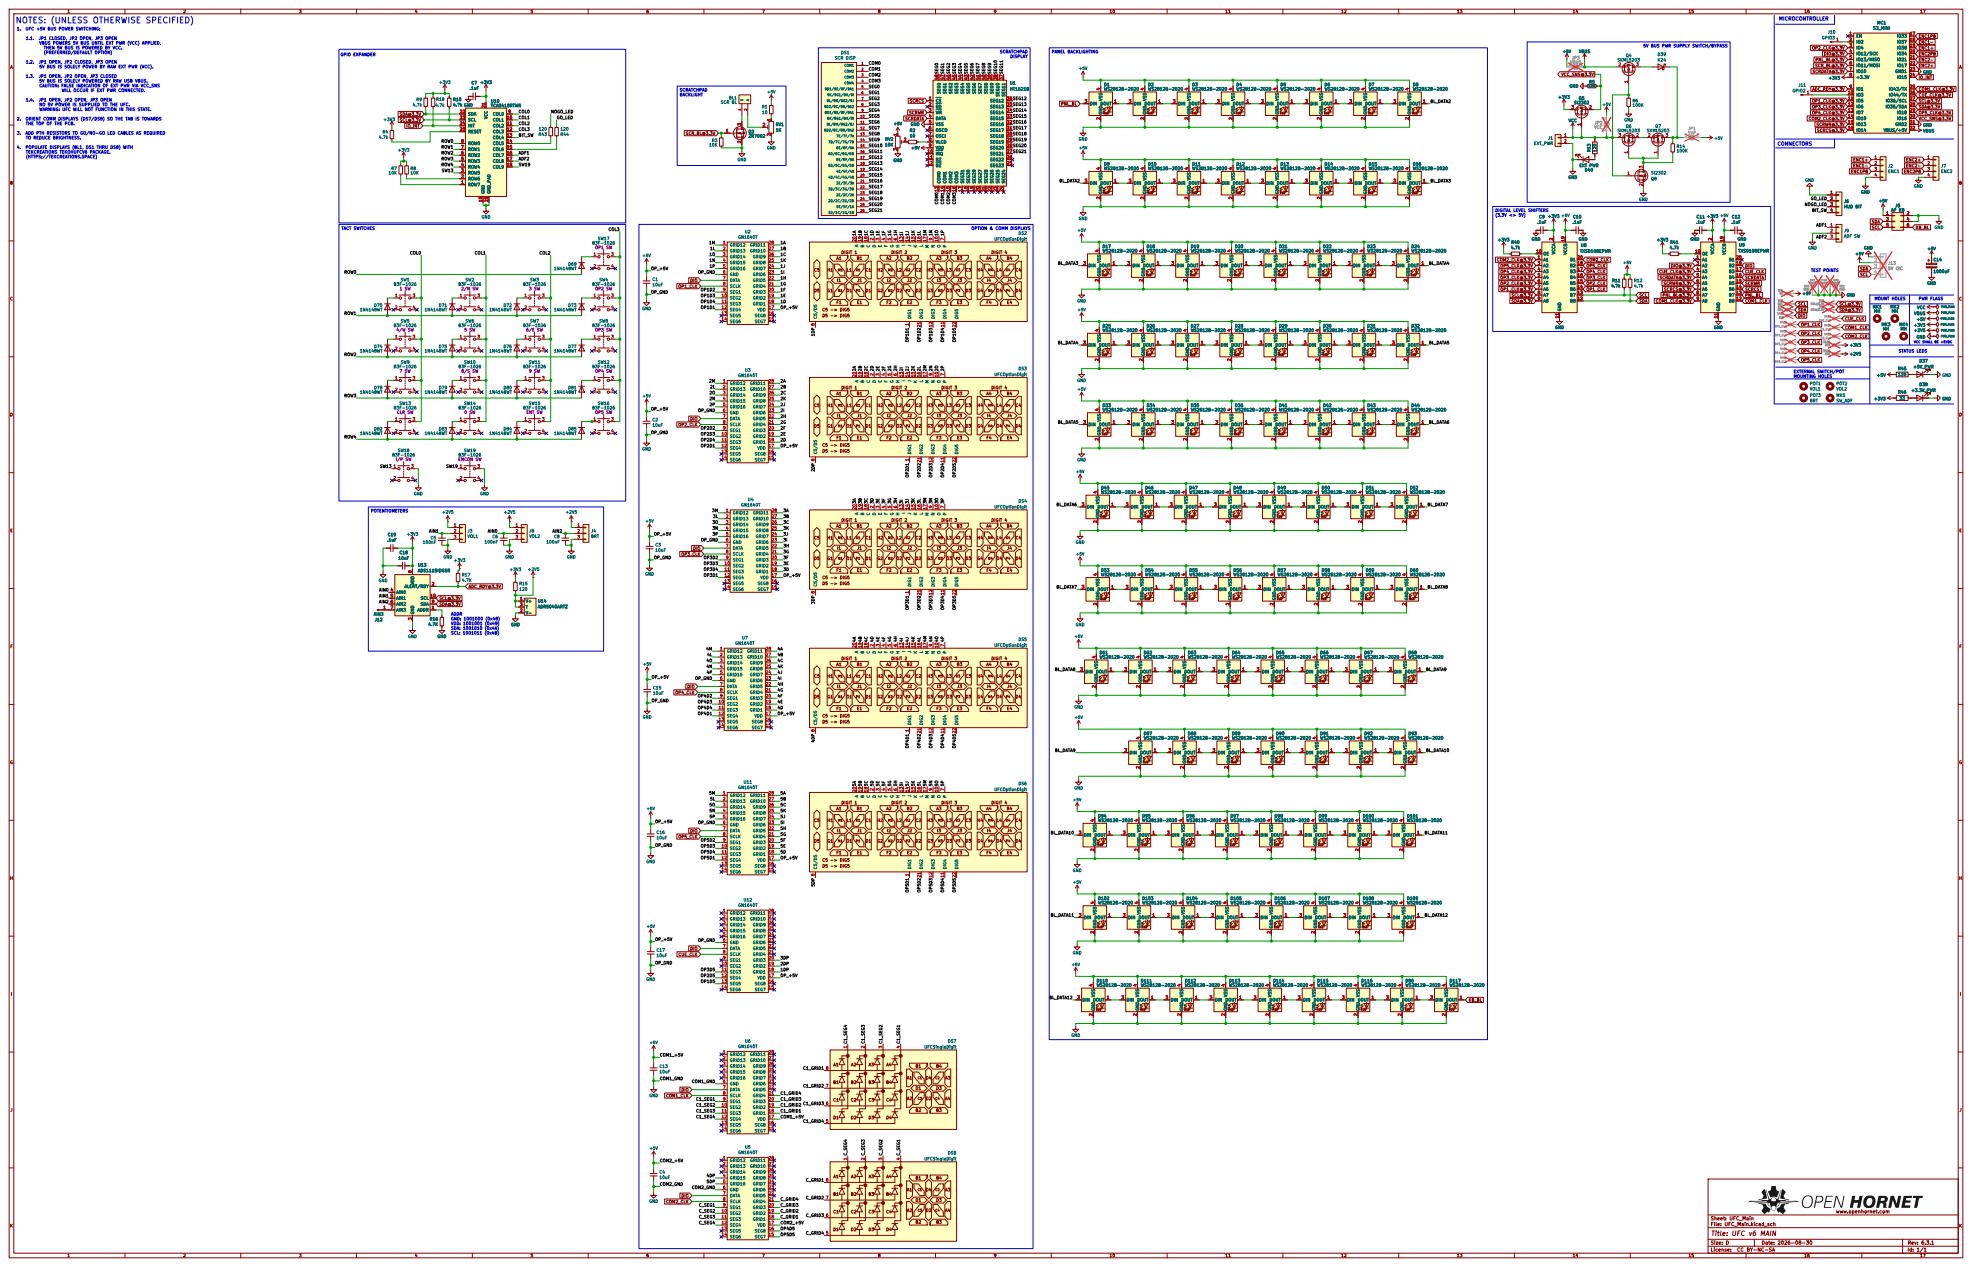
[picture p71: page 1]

1. UFC +5V BUS POWER SWITCHING: 1.1. JP1 CLOSED, JP2 OPEN, JP3 OPEN

VBUS POWERS 5V BUS UNTIL EXT PWR (VCC) APPLIED,
THEN 5V BUS IS POWERED BY VCC.

(PREFERRED/DEFAULT OPTION) 1.2. JP1 OPEN, JP2 CLOSED, JP3 OPEN

5V BUS IS SOLELY POWER BY RAW EXT PWR (VCC). 1.3. JP1 OPEN, JP2 OPEN, JP3 CLOSED

5V BUS IS SOLELY POWERED BY RAW USB VBUS. CAUTION: FALSE INDICATION OF EXT PWR VIA VCC_SNS WILL OCCUR IF EXT PWR CONNECTED. 1.4. JP1 OPEN, JP2 OPEN, JP3 OPEN

NO 5V POWER IS SUPPLIED TO THE UFC. WARNING: UFC WILL NOT FUNCTION IN THIS STATE. 2. ORIENT COMM DISPLAYS (DS7/DS8) SO THE TAB IS TOWARDS

THE TOP OF THE PCB. 3. ADD PTH RESISTORS TO GO/NO-GO LED CABLES AS REQUIRED

TO REDUCE BRIGHTNESS. 4. POPULATE DISPLAYS (BL1, DS1 THRU DS8) WITH

VCC SHALL BE +5VDC MOUNT HOLES

EXTERNAL SWITCH/POT MOUNTING HOLES

ADDR
GND: 1001000 (0x48) VDD: 1001001 (0x49) SDA: 1001010 (0x4A) SCL: 1001011 (0x4B)

Size: D | Rev: 6.3.1
License: CC BY-NC-SA | Id: 1/1

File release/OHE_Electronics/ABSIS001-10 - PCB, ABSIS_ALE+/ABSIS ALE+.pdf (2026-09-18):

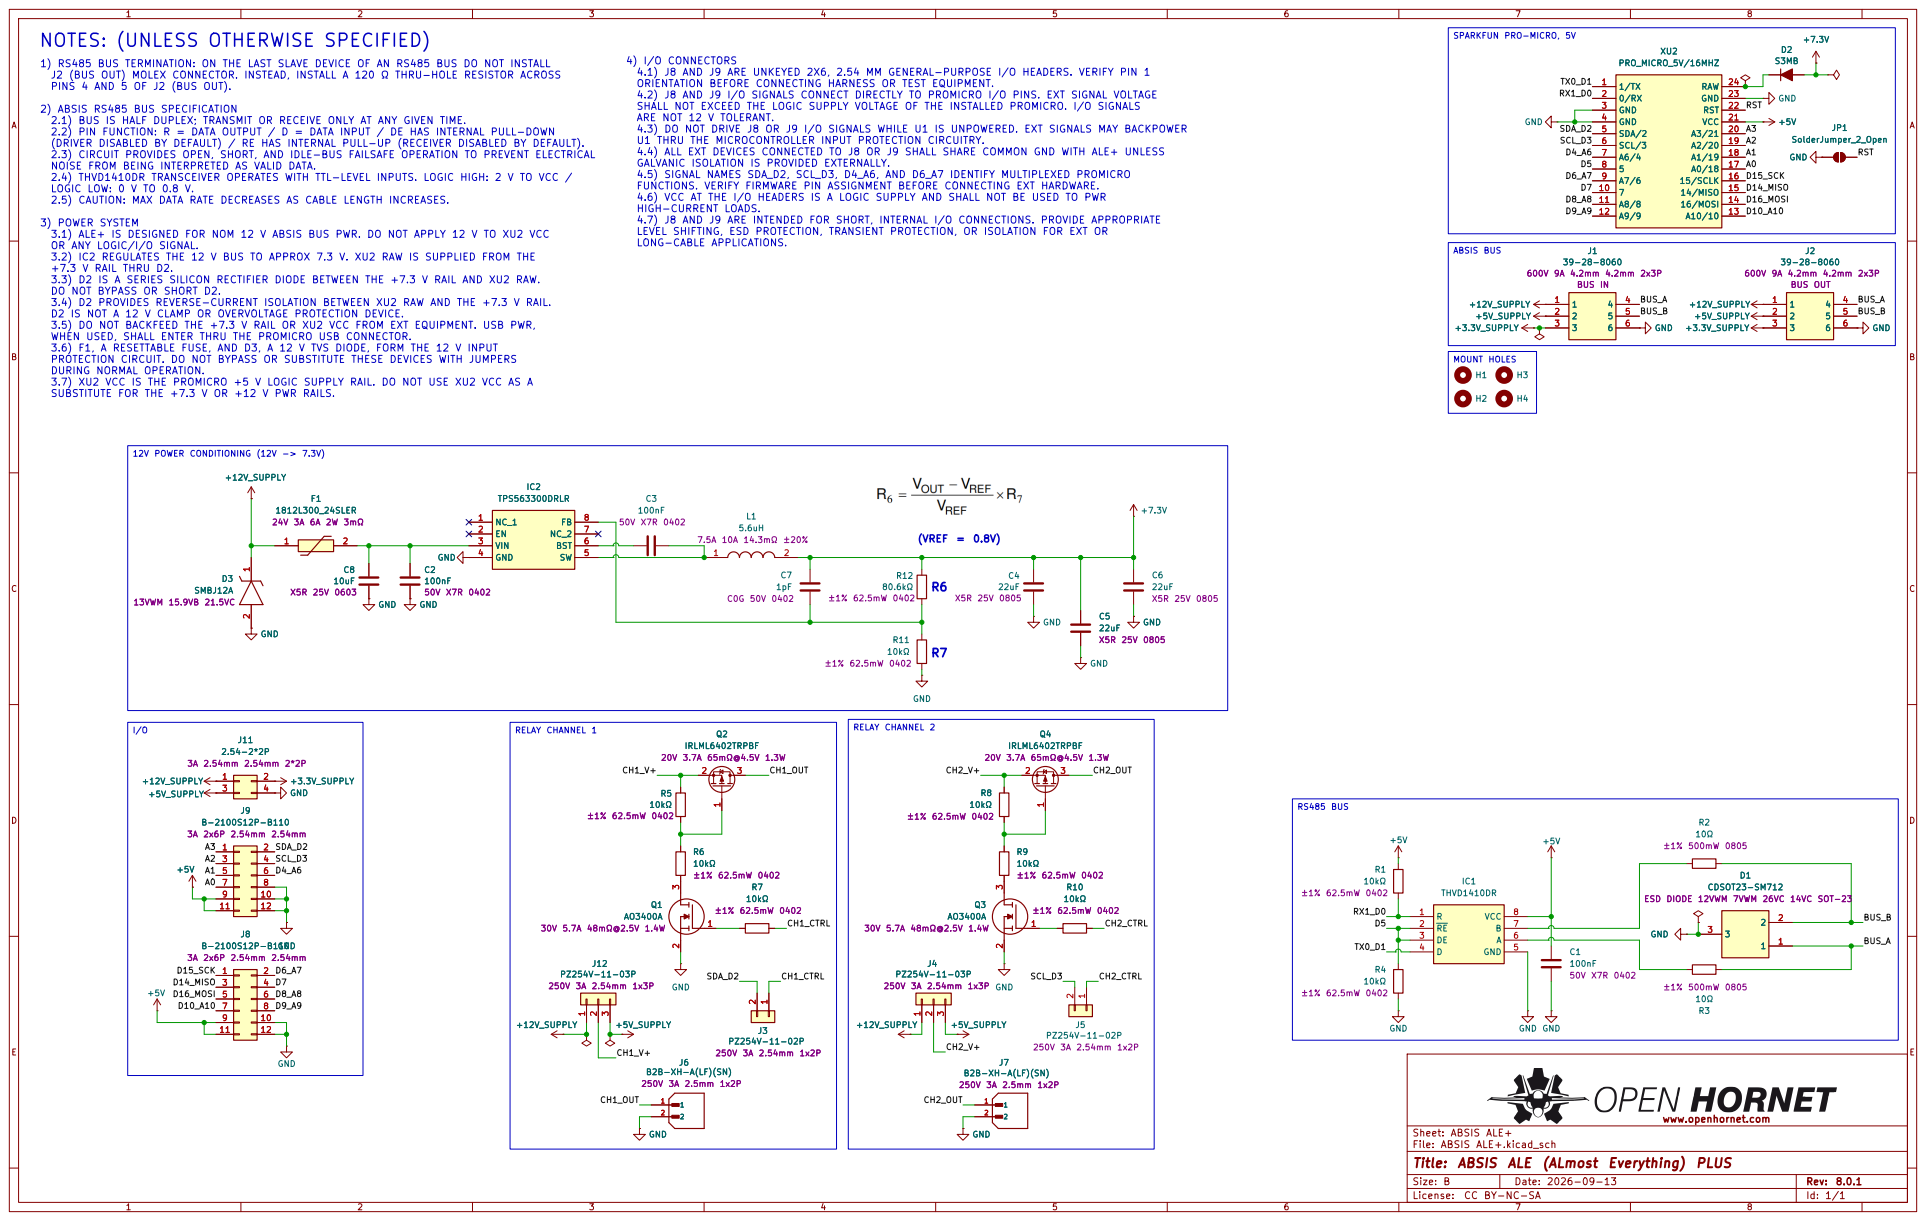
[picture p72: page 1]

NOTES: (UNLESS OTHERWISE SPECIFIED)

SPARKFUN PRO-MICRO, 5V 12V POWER CONDITIONING (12V -> 7.3V)

J2 (BUS OUT) MOLEX CONNECTOR. INSTEAD, INSTALL A 120 Ω THRU-HOLE RESISTOR ACROSS
PINS 4 AND 5 OF J2 (BUS OUT).

4) I/O CONNECTORS
4.1) J8 AND J9 ARE UNKEYED 2X6, 2.54 MM GENERAL-PURPOSE I/O HEADERS. VERIFY PIN 1
ORIENTATION BEFORE CONNECTING HARNESS OR TEST EQUIPMENT.
4.2) J8 AND J9 I/O SIGNALS CONNECT DIRECTLY TO PROMICRO I/O PINS. EXT SIGNAL VOLTAGE
SHALL NOT EXCEED THE LOGIC SUPPLY VOLTAGE OF THE INSTALLED PROMICRO. I/O SIGNALS
ARE NOT 12 V TOLERANT.
4.3) DO NOT DRIVE J8 OR J9 I/O SIGNALS WHILE U1 IS UNPOWERED. EXT SIGNALS MAY BACKPOWER
U1 THRU THE MICROCONTROLLER INPUT PROTECTION CIRCUITRY.
4.4) ALL EXT DEVICES CONNECTED TO J8 OR J9 SHALL SHARE COMMON GND WITH ALE+ UNLESS
GALVANIC ISOLATION IS PROVIDED EXTERNALLY.
4.5) SIGNAL NAMES SDA_D2, SCL_D3, D4_A6, AND D6_A7 IDENTIFY MULTIPLEXED PROMICRO
FUNCTIONS. VERIFY FIRMWARE PIN ASSIGNMENT BEFORE CONNECTING EXT HARDWARE.
4.6) VCC AT THE I/O HEADERS IS A LOGIC SUPPLY AND SHALL NOT BE USED TO PWR

2) ABSIS RS485 BUS SPECIFICATION
2.1) BUS IS HALF DUPLEX; TRANSMIT OR RECEIVE ONLY AT ANY GIVEN TIME.
2.2) PIN FUNCTION: R = DATA OUTPUT / D = DATA INPUT / DE HAS INTERNAL PULL-DOWN
(DRIVER DISABLED BY DEFAULT) / RE HAS INTERNAL PULL-UP (RECEIVER DISABLED BY DEFAULT). 2.3) CIRCUIT PROVIDES OPEN, SHORT, AND IDLE-BUS FAILSAFE OPERATION TO PREVENT ELECTRICAL

NOISE FROM BEING INTERPRETED AS VALID DATA.
2.4) THVD1410DR TRANSCEIVER OPERATES WITH TTL-LEVEL INPUTS. LOGIC HIGH: 2 V TO VCC /
LOGIC LOW: 0 V TO 0.8 V.
2.5) CAUTION: MAX DATA RATE DECREASES AS CABLE LENGTH INCREASES.

HIGH-CURRENT LOADS.
4.7) J8 AND J9 ARE INTENDED FOR SHORT, INTERNAL I/O CONNECTIONS. PROVIDE APPROPRIATE
LEVEL SHIFTING, ESD PROTECTION, TRANSIENT PROTECTION, OR ISOLATION FOR EXT OR
LONG-CABLE APPLICATIONS.
24V 3A 6A 2W 3mΩ +12V_SUPPLY GND

3) POWER SYSTEM
3.1) ALE+ IS DESIGNED FOR NOM 12 V ABSIS BUS PWR. DO NOT APPLY 12 V TO XU2 VCC
OR ANY LOGIC/I/O SIGNAL.
3.2) IC2 REGULATES THE 12 V BUS TO APPROX 7.3 V. XU2 RAW IS SUPPLIED FROM THE
+7.3 V RAIL THRU D2.
3.3) D2 IS A SERIES SILICON RECTIFIER DIODE BETWEEN THE +7.3 V RAIL AND XU2 RAW.
DO NOT BYPASS OR SHORT D2.
3.4) D2 PROVIDES REVERSE-CURRENT ISOLATION BETWEEN XU2 RAW AND THE +7.3 V RAIL.
D2 IS NOT A 12 V CLAMP OR OVERVOLTAGE PROTECTION DEVICE.
3.5) DO NOT BACKFEED THE +7.3 V RAIL OR XU2 VCC FROM EXT EQUIPMENT. USB PWR,
WHEN USED, SHALL ENTER THRU THE PROMICRO USB CONNECTOR.
3.6) F1, A RESETTABLE FUSE, AND D3, A 12 V TVS DIODE, FORM THE 12 V INPUT
PROTECTION CIRCUIT. DO NOT BYPASS OR SUBSTITUTE THESE DEVICES WITH JUMPERS
DURING NORMAL OPERATION.
3.7) XU2 VCC IS THE PROMICRO +5 V LOGIC SUPPLY RAIL. DO NOT USE XU2 VCC AS A
SUBSTITUTE FOR THE +7.3 V OR +12 V PWR RAILS.

Sheet: ABSIS ALE+
File: ABSIS ALE+.kicad_sch
Title: ABSIS ALE (ALmost Everything) PLUS

Size: B | Rev: 8.0.1
License: CC BY-NC-SA | Id: 1/1

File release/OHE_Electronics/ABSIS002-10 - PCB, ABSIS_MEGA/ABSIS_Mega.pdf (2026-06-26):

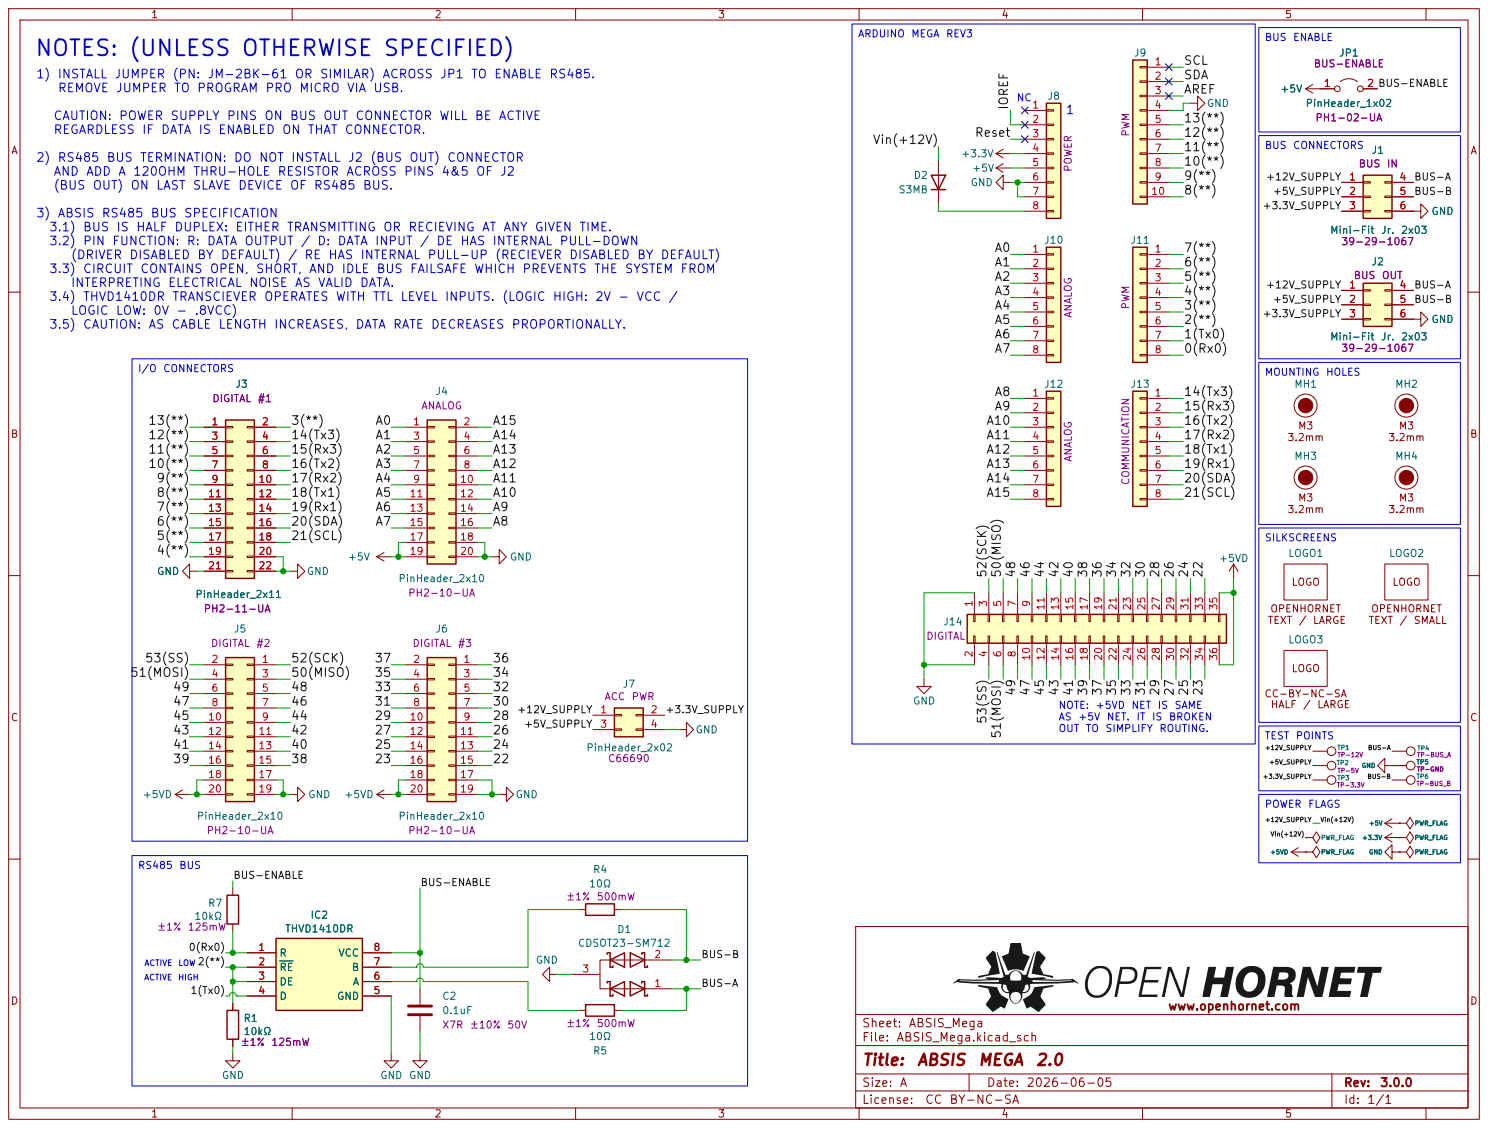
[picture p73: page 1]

NOTES: (UNLESS OTHERWISE SPECIFIED)

NC 1) INSTALL JUMPER (PN: JM-2BK-61 OR SIMILAR) ACROSS JP1 TO ENABLE RS485.
REMOVE JUMPER TO PROGRAM PRO MICRO VIA USB.

CAUTION: POWER SUPPLY PINS ON BUS OUT CONNECTOR WILL BE ACTIVE
REGARDLESS IF DATA IS ENABLED ON THAT CONNECTOR.

2) RS485 BUS TERMINATION: DO NOT INSTALL J2 (BUS OUT) CONNECTOR
AND ADD A 120OHM THRU-HOLE RESISTOR ACROSS PINS 4&5 OF J2
(BUS OUT) ON LAST SLAVE DEVICE OF RS485 BUS.

3) ABSIS RS485 BUS SPECIFICATION
3.1) BUS IS HALF DUPLEX: EITHER TRANSMITTING OR RECIEVING AT ANY GIVEN TIME.
3.2) PIN FUNCTION: R: DATA OUTPUT / D: DATA INPUT / DE HAS INTERNAL PULL-DOWN
(DRIVER DISABLED BY DEFAULT) / RE HAS INTERNAL PULL-UP (RECIEVER DISABLED BY DEFAULT) 3.3) CIRCUIT CONTAINS OPEN, SHORT, AND IDLE BUS FAILSAFE WHICH PREVENTS THE SYSTEM FROM
J3 PinHeader_2x11 PH2-11-UA DIGITAL #1
J4 PinHeader_2x10 PH2-10-UA
ANALOG

INTERPRETING ELECTRICAL NOISE AS VALID DATA.
3.4) THVD1410DR TRANSCIEVER OPERATES WITH TTL LEVEL INPUTS. (LOGIC HIGH: 2V - VCC /
LOGIC LOW: 0V - .8VCC) 3.5) CAUTION: AS CABLE LENGTH INCREASES, DATA RATE DECREASES PROPORTIONALLY.

CC-BY-NC-SA HALF / LARGE

Size: A | Rev: 3.0.0
License: CC BY-NC-SA | Id: 1/1

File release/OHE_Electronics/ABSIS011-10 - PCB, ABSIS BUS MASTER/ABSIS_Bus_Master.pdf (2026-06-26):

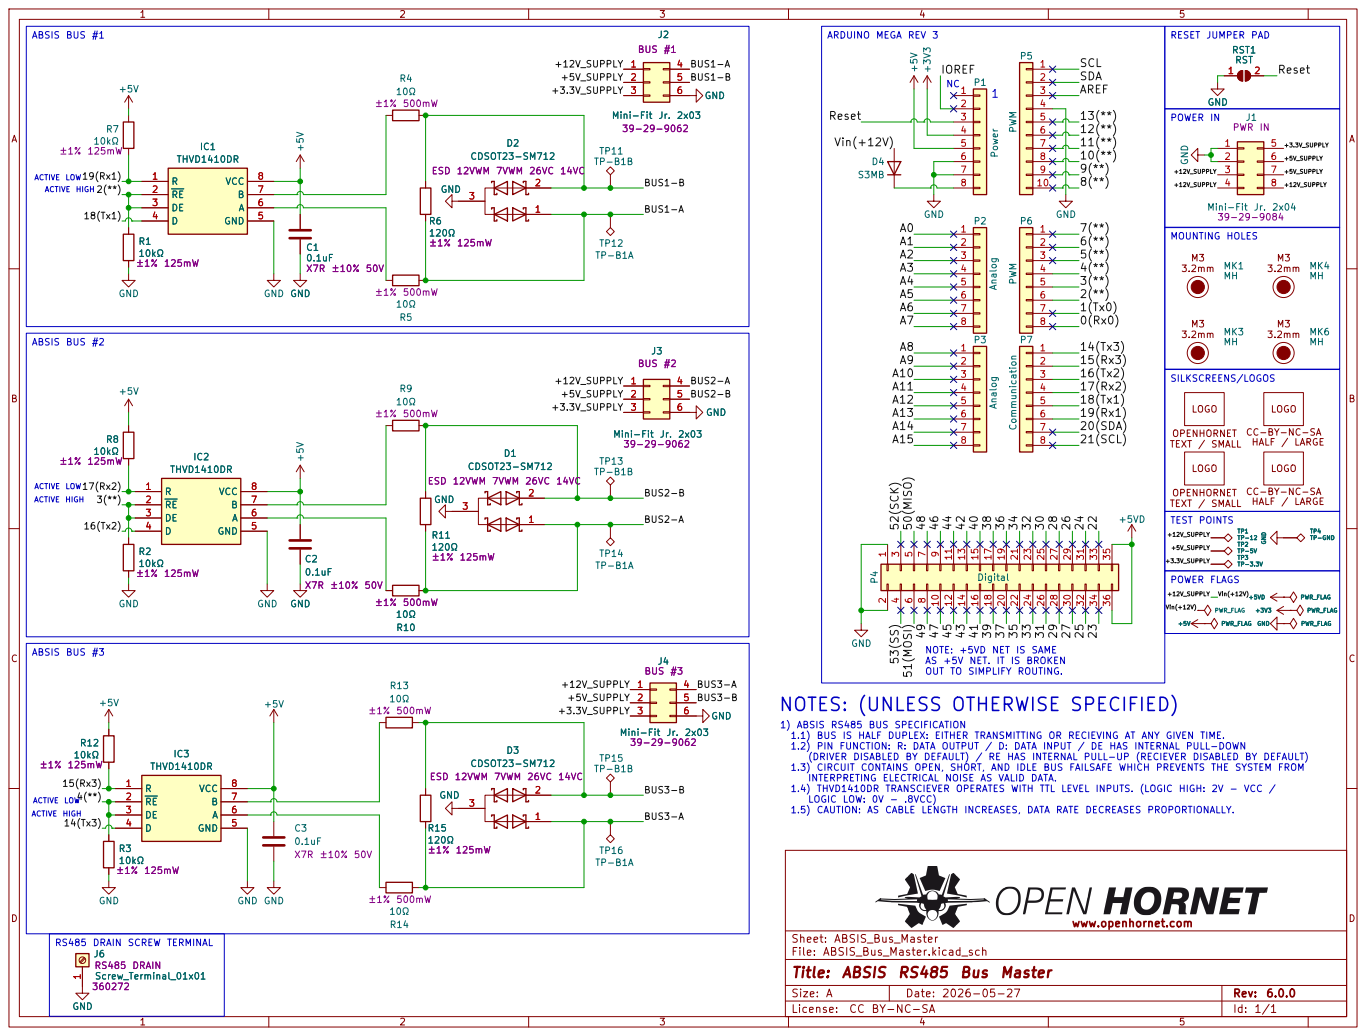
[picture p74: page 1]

CC-BY-NC-SA HALF / LARGE

TP-3.3V+3V3GND

1.1) BUS IS HALF DUPLEX: EITHER TRANSMITTING OR RECIEVING AT ANY GIVEN TIME. 1.2) PIN FUNCTION: R: DATA OUTPUT / D: DATA INPUT / DE HAS INTERNAL PULL-DOWN

(DRIVER DISABLED BY DEFAULT) / RE HAS INTERNAL PULL-UP (RECIEVER DISABLED BY DEFAULT) 1.3) CIRCUIT CONTAINS OPEN, SHORT, AND IDLE BUS FAILSAFE WHICH PREVENTS THE SYSTEM FROM

INTERPRETING ELECTRICAL NOISE AS VALID DATA. 1.4) THVD1410DR TRANSCIEVER OPERATES WITH TTL LEVEL INPUTS. (LOGIC HIGH: 2V - VCC / LOGIC LOW: 0V - .8VCC) 1.5) CAUTION: AS CABLE LENGTH INCREASES, DATA RATE DECREASES PROPORTIONALLY.

Sheet: ABSIS_Bus_Master
File: ABSIS_Bus_Master.kicad_sch
Title: ABSIS RS485 Bus Master

Size: A | Rev: 6.0.0
License: CC BY-NC-SA | Id: 1/1

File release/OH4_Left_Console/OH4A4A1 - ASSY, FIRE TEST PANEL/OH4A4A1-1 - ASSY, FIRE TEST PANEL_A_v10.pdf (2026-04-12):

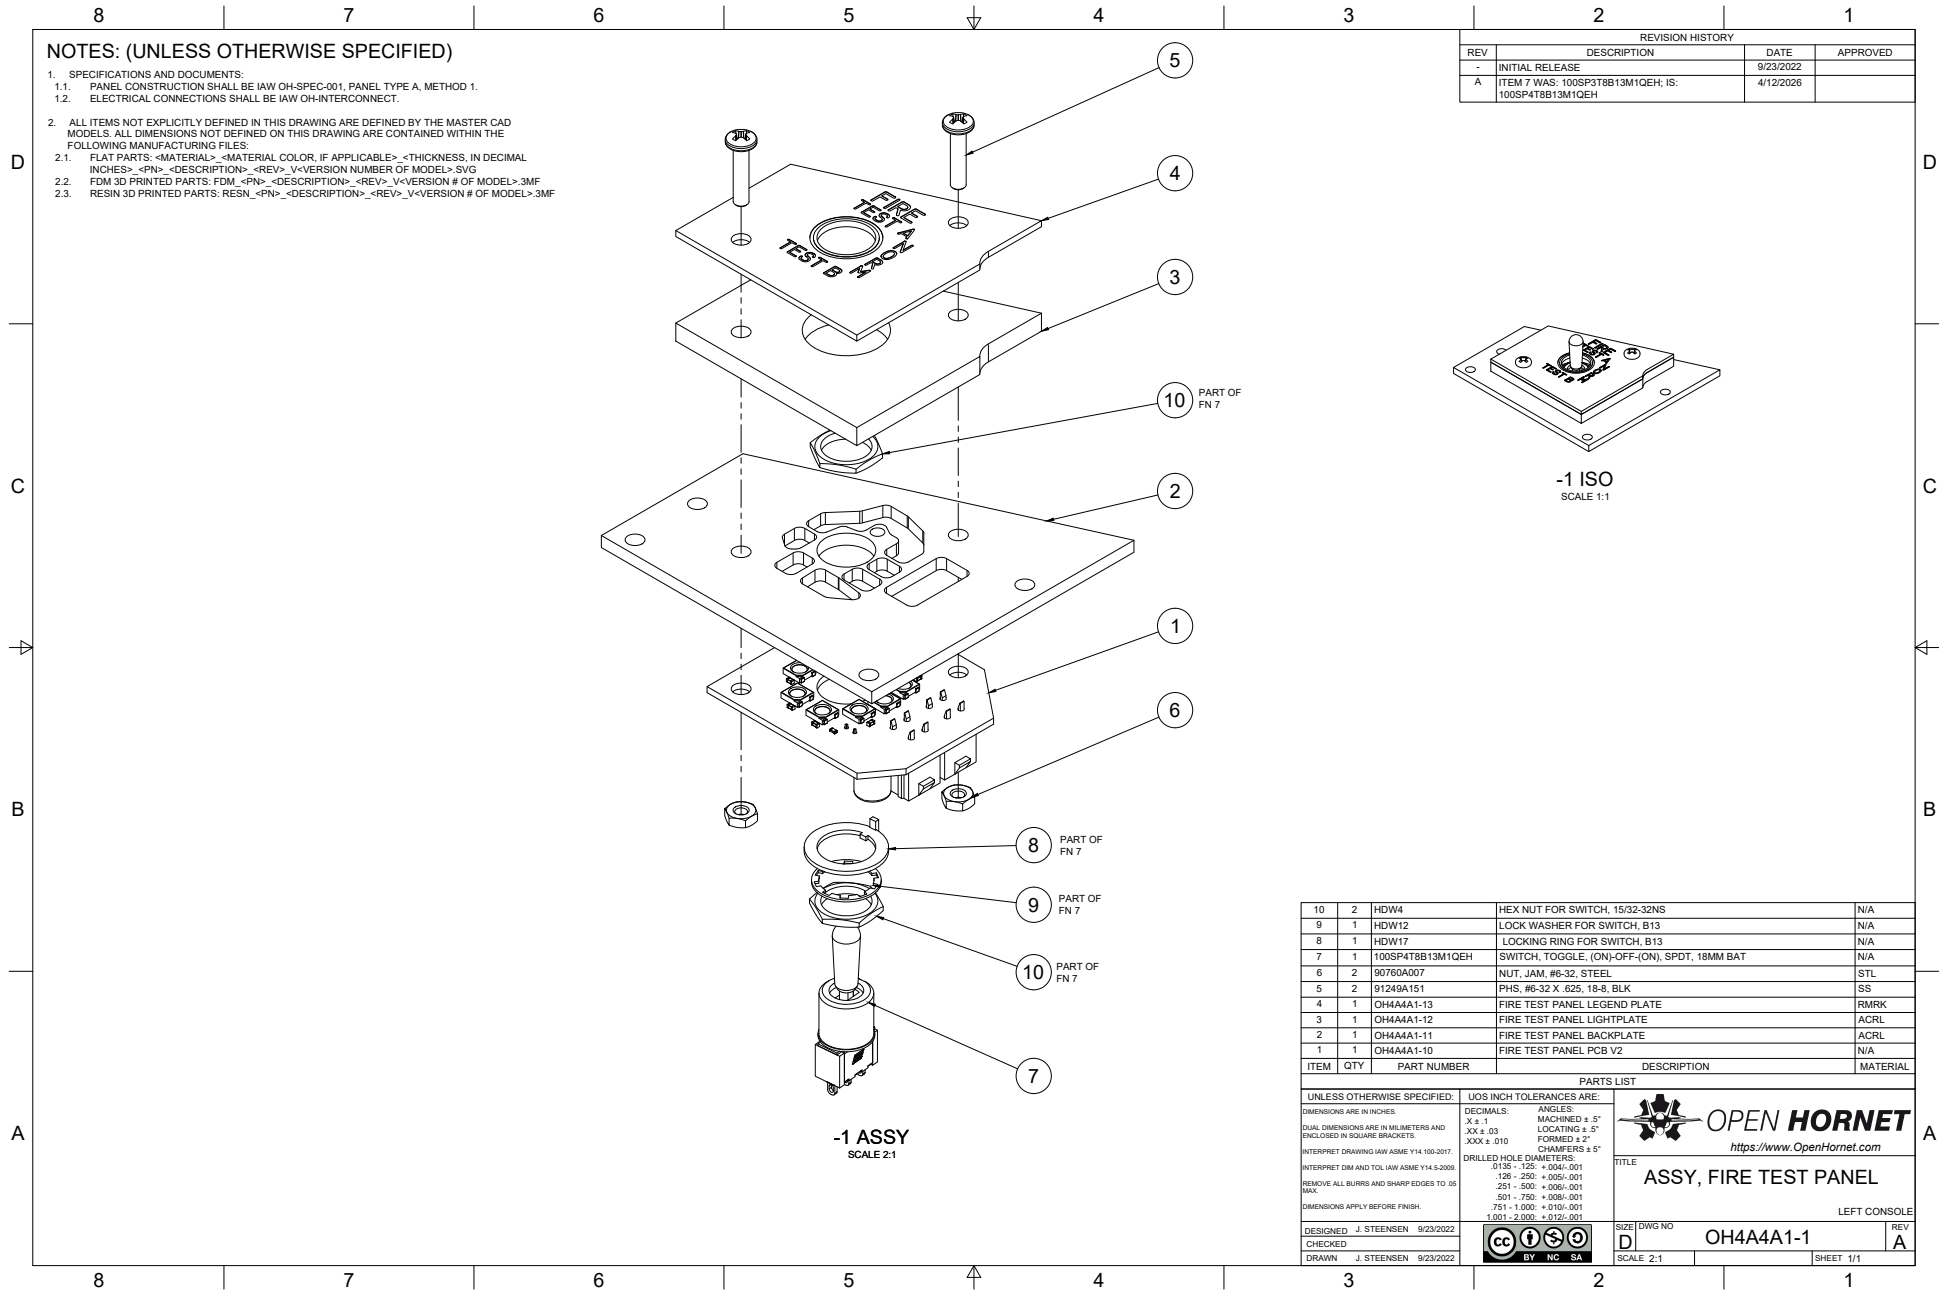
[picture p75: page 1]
PARTS LIST; -1 ASSY; SCALE 2:1; PART OF FN 7; REVISION HISTORY; -1 ISO; SCALE 1:1; J. STEENSEN; LEFT CONSOLE

NOTES: (UNLESS OTHERWISE SPECIFIED)

REV | DESCRIPTION | DATE | APPROVED
- | INITIAL RELEASE | 9/23/2022
A | ITEM 7 WAS: 100SP3T8B13M1QEH; IS: 100SP4T8B13M1QEH | 4/12/2026

1. SPECIFICATIONS AND DOCUMENTS:
1.1. PANEL CONSTRUCTION SHALL BE IAW OH-SPEC-001, PANEL TYPE A, METHOD 1.
1.2. ELECTRICAL CONNECTIONS SHALL BE IAW OH-INTERCONNECT.

2. ALL ITEMS NOT EXPLICITLY DEFINED IN THIS DRAWING ARE DEFINED BY THE MASTER CAD
MODELS. ALL DIMENSIONS NOT DEFINED ON THIS DRAWING ARE CONTAINED WITHIN THE
FOLLOWING MANUFACTURING FILES:
2.1. FLAT PARTS: <MATERIAL>_<MATERIAL COLOR, IF APPLICABLE>_<THICKNESS, IN DECIMAL

INCHES>_<PN>_<DESCRIPTION>_<REV>_V<VERSION NUMBER OF MODEL>.SVG

2.2. FDM 3D PRINTED PARTS: FDM_<PN>_<DESCRIPTION>_<REV>_V<VERSION # OF MODEL>.3MF
2.3. RESIN 3D PRINTED PARTS: RESN_<PN>_<DESCRIPTION>_<REV>_V<VERSION # OF MODEL>.3MF

10 | 2 | HDW4 | HEX NUT FOR SWITCH, 15/32-32NS | N/A
9 | 1 | HDW12 | LOCK WASHER FOR SWITCH, B13 | N/A
8 | 1 | HDW17 | LOCKING RING FOR SWITCH, B13 | N/A
7 | 1 | 100SP4T8B13M1QEH | SWITCH, TOGGLE, (ON)-OFF-(ON), SPDT, 18MM BAT | N/A
6 | 2 | 90760A007 | NUT, JAM, #6-32, STEEL | STL
5 | 2 | 91249A151 | PHS, #6-32 X .625, 18-8, BLK | SS
4 | 1 | OH4A4A1-13 | FIRE TEST PANEL LEGEND PLATE | RMRK
3 | 1 | OH4A4A1-12 | FIRE TEST PANEL LIGHTPLATE | ACRL
2 | 1 | OH4A4A1-11 | FIRE TEST PANEL BACKPLATE | ACRL
1 | 1 | OH4A4A1-10 | FIRE TEST PANEL PCB V2 | N/A
ITEM | QTY | PART NUMBER | DESCRIPTION | MATERIAL

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

TITLE
ASSY, FIRE TEST PANEL

J. STEENSEN 9/23/2022 DESIGNED | | SIZE D | DWG NO OH4A4A1-1 | REV A

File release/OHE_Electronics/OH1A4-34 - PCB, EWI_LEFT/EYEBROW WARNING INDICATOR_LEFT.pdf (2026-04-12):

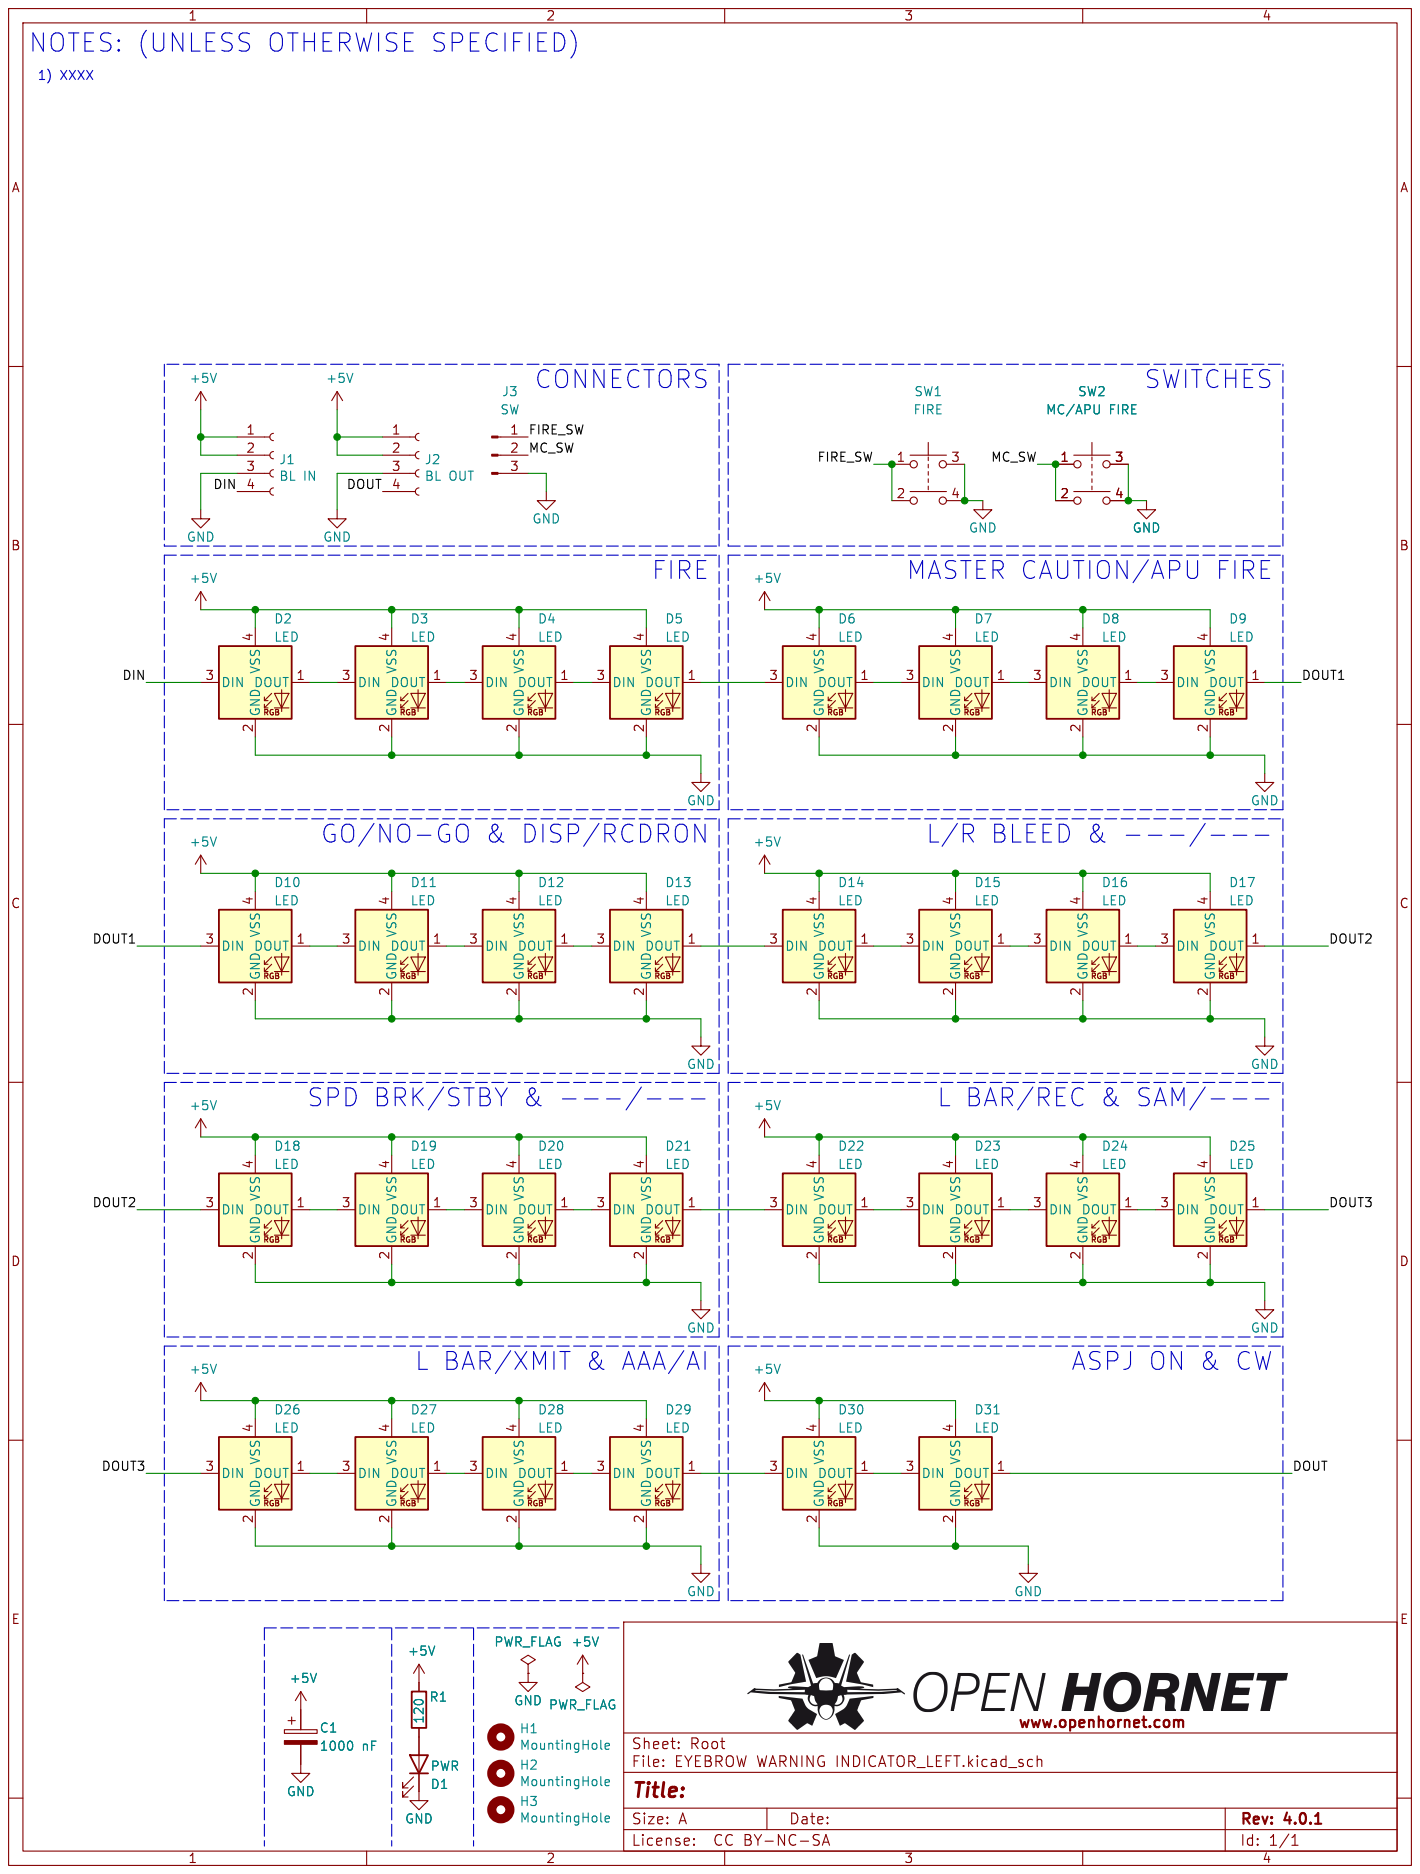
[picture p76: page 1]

NOTES: (UNLESS OTHERWISE SPECIFIED)

MASTER CAUTION/APU FIRE

GO/NO-GO & DISP/RCDRON

L BAR/XMIT & AAA/AI

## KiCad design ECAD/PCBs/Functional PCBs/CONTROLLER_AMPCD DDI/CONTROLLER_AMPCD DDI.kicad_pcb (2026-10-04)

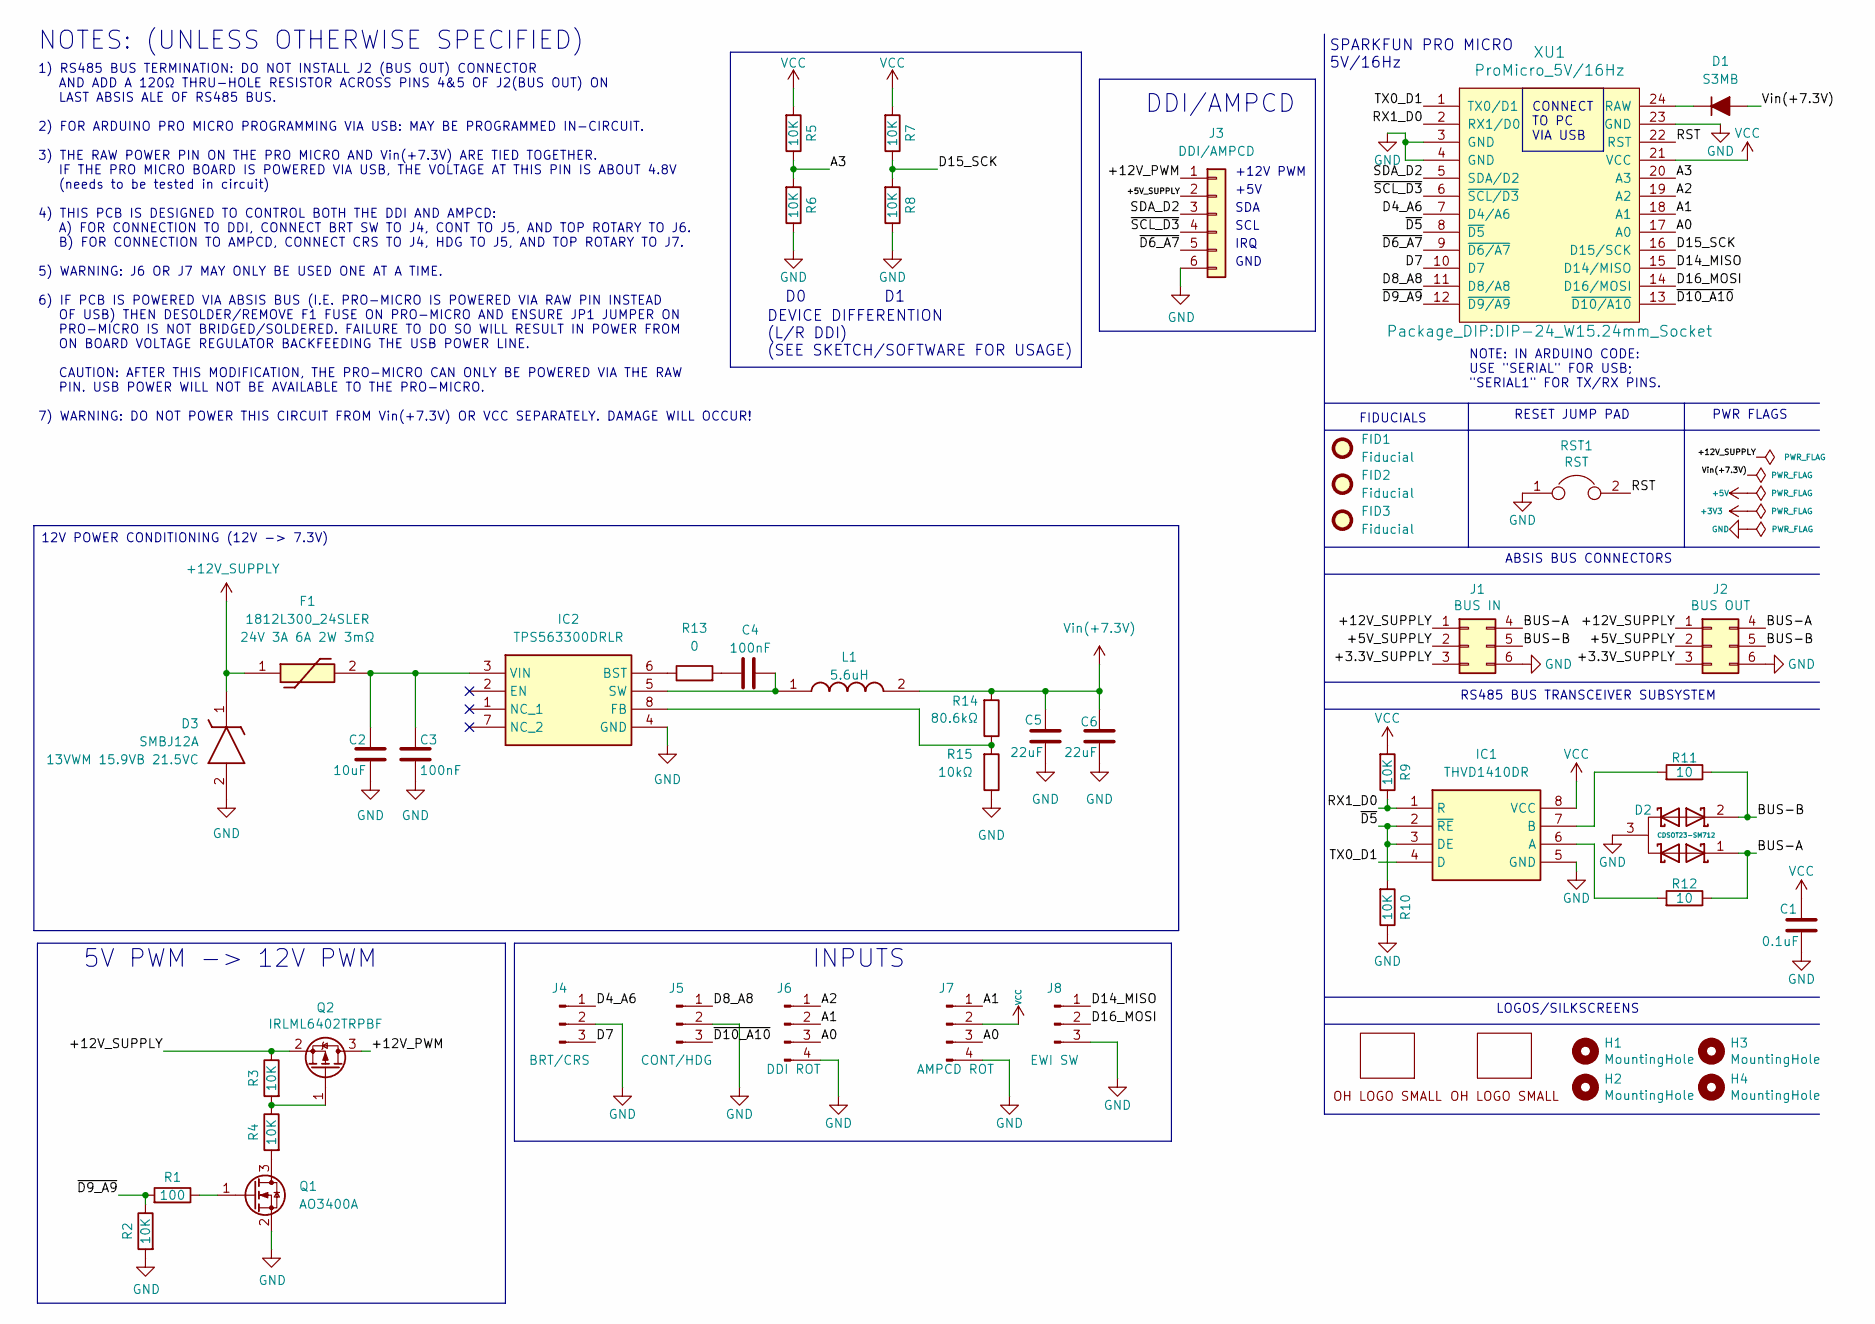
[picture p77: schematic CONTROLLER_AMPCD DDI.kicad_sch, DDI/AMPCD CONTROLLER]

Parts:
C1: 0.1uF; C_0603_1608Metric; Manufacturer PN CC0603KRX7R9BB104; LCSC C14663
C2: 10uF; C_0603_1608Metric; Manufacturer PN CL10A106MA8NRNC; LCSC C96446
C3, C4: 100nF; C_0402_1005Metric; Manufacturer PN CL05B104KB54PNC; LCSC C307331
C5, C6: 22uF; C_0805_2012Metric; Manufacturer PN CL21A226MAQNNNE; LCSC C45783
D1: S3MB; D_SMB; Manufacturer PN S3MB; LCSC C47524
D2: CDSOT23-SM712; Manufacturer_Part_Number CDSOT23-SM712; Mouser Part Number 652-CDSOT23-SM712
D3: SMBJ12A; D_SMB; Manufacturer PN SMBJ12A; LCSC C151251
F1: 1812L300_24SLER; Fuse_1812_4532Metric; Manufacturer PN 1812L300/24SLER; LCSC C1512049
FID1, FID2, FID3: Fiducial; Fiducial_1mm_Mask2mm
H1, H2, H3, H4: MountingHole; MountingHole_3.2mm_M3
IC1: THVD1410DR; Manufacturer_Part_Number THVD1410DR; Mouser Part Number 595-THVD1410DR
IC2: TPS563300DRLR; SOT-583-8; Manufacturer PN TPS563300DRLR; LCSC C5219249
J1: BUS IN; Molex_Mini-Fit_Jr_5566-06A2_2x03_P4.20mm_Vertical; LCSC N/A
J2: BUS OUT; Molex_Mini-Fit_Jr_5566-06A2_2x03_P4.20mm_Vertical; LCSC N/A
J3: DDI/AMPCD; Molex_KK-254_AE-6410-06A_1x06_P2.54mm_Vertical
J4: BRT/CRS; Molex_KK-254_AE-6410-03A_1x03_P2.54mm_Vertical
J5: CONT/HDG; Molex_KK-254_AE-6410-03A_1x03_P2.54mm_Vertical
J6: DDI ROT; Molex_KK-254_AE-6410-04A_1x04_P2.54mm_Vertical
J7: AMPCD ROT; Molex_KK-254_AE-6410-04A_1x04_P2.54mm_Vertical
J8: EWI SW; Molex_KK-254_AE-6410-03A_1x03_P2.54mm_Vertical
L1: 5.6uH; L_Bourns_SRP6060FA; Manufacturer PN SRP6060FA-5R6M; LCSC C1332221
LOGO1: OpenHornetLogoSmall; LOGO_OH_NoText_Small; LCSC N/A
LOGO2: OpenHornetLogoSmall; LOGO_OH_Text_Small; LCSC N/A
Q1: AO3400A; SOT-23; Manufacture PN AO3400A; LCSC C20917
Q2: IRLML6402TRPBF; SOT-23; LCSC C2593
R1: 100; R_0603_1608Metric_Pad0.98x0.95mm_HandSolder; LCSC C22775
R2, R3, R4, R5, R6, R7, R8, R9, R10: 10K; R_0603_1608Metric_Pad0.98x0.95mm_HandSolder; LCSC C25804
R11, R12: 10; R_0603_1608Metric_Pad0.98x0.95mm_HandSolder; LCSC C844519
R13: 0; R_0402_1005Metric; Manufacture PN 0402WGF0000TCE; LCSC C17168
R14: 80.6kΩ; R_0402_1005Metric; Manufacturer PN 0402WGF8062TCE; LCSC C25921
R15: 10kΩ; R_0402_1005Metric; Manufacturer PN 0402WGF1002TCE; LCSC C25744
RST1: RST; SolderJumper-2_P1.3mm_Open_RoundedPad1.0x1.5mm
XU1: ProMicro_5V/16Hz; DIP-24_W15.24mm_Socket; LCSC C72120

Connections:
+12V_SUPPLY: D3.1 (K), F1.1, J1.1, J2.1, Q2.2 (S), R3.1
/+3.3V_SUPPLY: J1.3, J2.3
/+5V_SUPPLY: J1.2, J2.2, J3.2
/+12V_PWM: J3.1, Q2.3 (D)
/A0: J6.3, J7.3, XU1.17 (A0)
/A1: J6.2, J7.1, XU1.18 (A1)
/A2: J6.1, XU1.19 (A2)
/A3: R5.1, R6.2, XU1.20 (A3)
/BUS-A: D2.1, J1.4, J2.4, R12.2
/BUS-B: D2.2, J1.5, J2.5, R11.2
/D4_A6: J4.1, XU1.7 (D4/A6)
/D7: J4.3, XU1.10 (D7)
/D8_A8: J5.1, XU1.11 (D8/A8)
/D14_MISO: J8.1, XU1.15 (D14/MISO)
/D15_SCK: R7.1, R8.2, XU1.16 (D15/SCK)
/D16_MOSI: J8.2, XU1.14 (D16/MOSI)
/RST: RST1.2, XU1.22 (RST)
/RX1_D0: IC1.1 (R), R9.1, XU1.2 (RX1/D0)
/SDA_D2: J3.3, XU1.5 (SDA/D2)
/TX0_D1: IC1.4 (D), XU1.1 (TX0/D1)
/~D5: IC1.2 (~RE), IC1.3 (DE), R10.2, XU1.8 (~D5)
/~D6_A7: J3.5, XU1.9 (~D6/A7)
/~D9_A9: R1.2, R2.1, XU1.12 (~D9/A9)
/~D10_A10: J5.3, XU1.13 (~D10/A10)
/~SCL_D3: J3.4, XU1.6 (~SCL/D3)
GND: C1.1, C2.1, C3.1, C5.2, C6.2, D2.3, D3.2 (A), IC1.5 (GND), IC2.4 (GND), J1.6, J2.6, J3.6, J4.2, J5.2, J6.4, J7.4, J8.3, Q1.2 (S), R2.2, R6.1, R8.1, R10.1, R15.1, RST1.1, XU1.3 (GND), XU1.4 (GND), XU1.23 (GND)
unnamed: C4.2, R13.2
unnamed: D1.1 (K), XU1.24 (RAW)
unnamed: IC1.6 (A), R12.1
unnamed: IC1.7 (B), R11.1
unnamed: IC2.6 (BST), R13.1
unnamed: IC2.8 (FB), R14.1, R15.2
unnamed: C4.1, IC2.5 (SW), L1.1
unnamed: C2.2, C3.2, F1.2, IC2.3 (VIN)
unnamed: Q1.3 (D), R4.2
unnamed: Q1.1 (G), R1.1
unnamed: Q2.1 (G), R3.2, R4.1
VCC: C1.2, IC1.8 (VCC), J7.2, R5.2, R7.2, R9.2, XU1.21 (VCC)
Vin(+7.3V): C5.1, C6.1, D1.2 (A), L1.2, R14.2

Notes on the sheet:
IRQ
FIDUCIALS
RS485 BUS TRANSCEIVER SUBSYSTEM
NOTES: (UNLESS OTHERWISE SPECIFIED)
DEVICE DIFFERENTION (L/R DDI) (SEE SKETCH/SOFTWARE FOR USAGE)
SPARKFUN PRO MICRO 5V/16Hz
CONNECT TO PC VIA USB
RESET JUMP PAD
LOGOS/SILKSCREENS
+12V PWM
5V PWM -> 12V PWM
SCL
PWR FLAGS
+5V
ABSIS BUS CONNECTORS
NOTE: IN ARDUINO CODE: USE "SERIAL" FOR USB; "SERIAL1" FOR TX/RX PINS.
SDA
INPUTS
1) RS485 BUS TERMINATION: DO NOT INSTALL J2 (BUS OUT) CONNECTOR AND ADD A 120Ω THRU-HOLE RESISTOR ACROSS PINS 4&5 OF J2(BUS OUT) ON LAST ABSIS ALE OF RS485 BUS. 2) FOR ARDUINO PRO MICRO PROGRAMMING VIA USB: MAY BE PROGRAMMED IN-CIRCUIT. 3) THE RAW POWER PIN ON THE PRO MICRO AND Vin(+7.3V) ARE TIED 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
GND
DDI/AMPCD
12V POWER CONDITIONING (12V -> 7.3V)

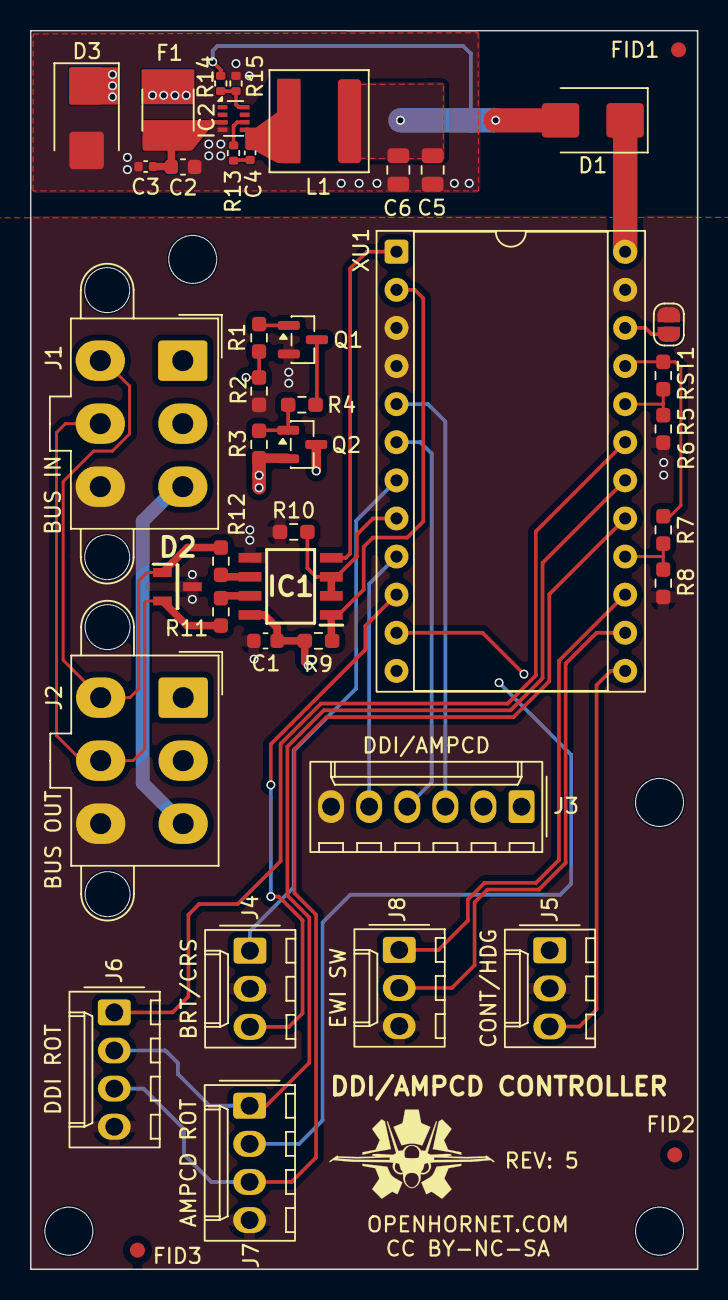
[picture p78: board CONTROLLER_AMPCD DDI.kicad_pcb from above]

Board: 4 copper layers, 44.5 x 82.5 mm, 49 parts (1 on the bottom side), 39 nets.

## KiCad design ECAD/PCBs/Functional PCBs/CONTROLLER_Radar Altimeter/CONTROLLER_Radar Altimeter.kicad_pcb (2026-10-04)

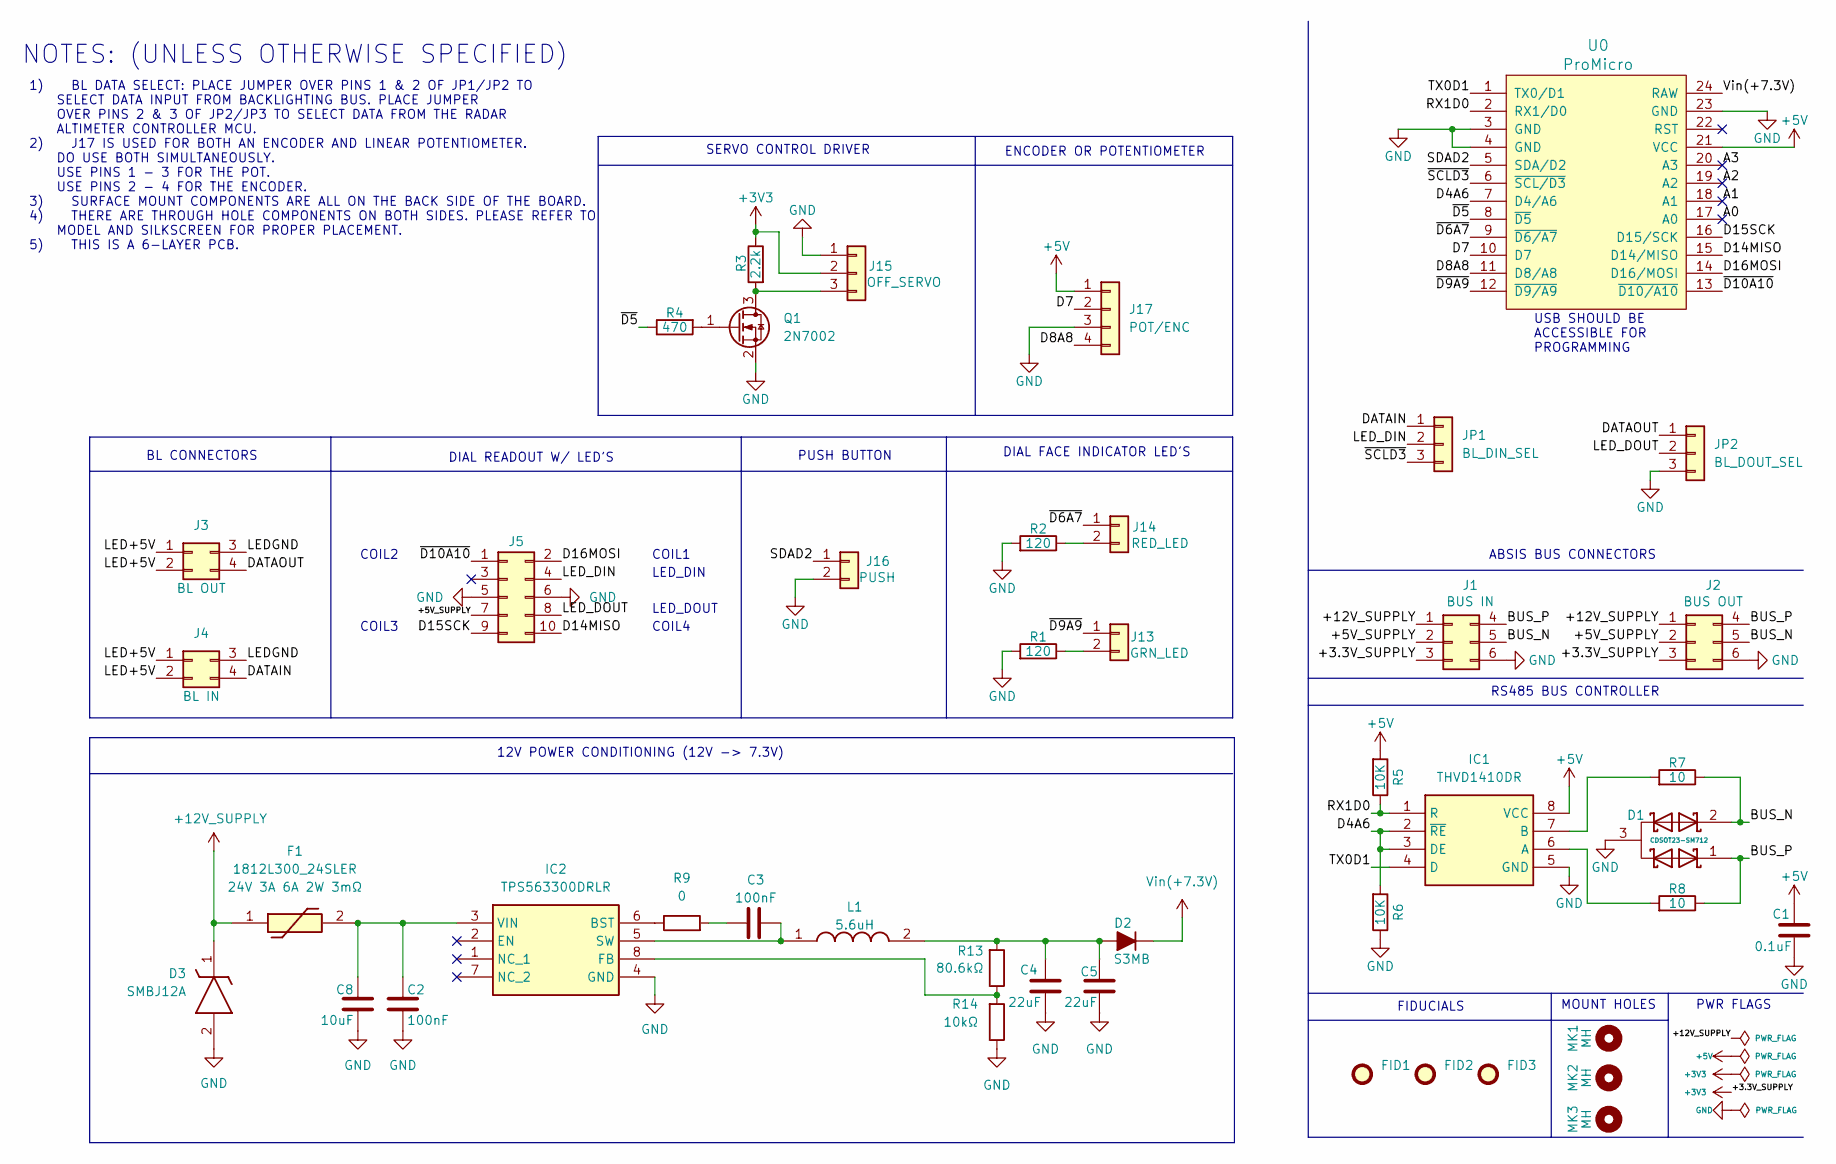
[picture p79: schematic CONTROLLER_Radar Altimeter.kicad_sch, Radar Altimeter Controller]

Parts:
C1: 0.1uF; C_0603_1608Metric; Manufacturer PN CC0603KRX7R9BB104; LCSC C14663
C2, C3: 100nF; C_0402_1005Metric; Manufacturer PN CL05B104KB54PNC; LCSC C307331
C4, C5: 22uF; C_0805_2012Metric; Manufacturer PN CL21A226MAQNNNE; LCSC C45783
C8: 10uF; C_0603_1608Metric; Manufacturer PN CL10A106MA8NRNC; LCSC C96446
D1: CDSOT23-SM712; Manufacturer_Part_Number CDSOT23-SM712; Mouser Part Number 652-CDSOT23-SM712
D2: S3MB; D_SMB; Manufacturer PN S3MB; LCSC C47524
D3: SMBJ12A; D_SMB; Manufacturer PN SMBJ12A; LCSC C151251
F1: 1812L300_24SLER; Fuse_1812_4532Metric; Manufacturer PN 1812L300/24SLER; LCSC C1512049
FID1, FID2, FID3: Fiducial; Fiducial_1mm_Mask2mm
IC1: THVD1410DR; Manufacturer_Part_Number THVD1410DR; Mouser Part Number 595-THVD1410DR
IC2: TPS563300DRLR; SOT-583-8; Manufacturer PN TPS563300DRLR; LCSC C5219249
J1: BUS IN; Molex_Mini-Fit_Jr_5566-06A_2x03_P4.20mm_Vertical; Manufacturer PN 39-28-1063; LCSC C471417
J2: BUS OUT; Molex_Mini-Fit_Jr_5566-06A_2x03_P4.20mm_Vertical; Manufacturer PN 39-28-1063; LCSC C471417
J3: BL OUT; Molex_Mini-Fit_Jr_5566-04A_2x02_P4.20mm_Vertical; Manufacturer PN 39-28-1043; LCSC C293502
J4: BL IN; Molex_Mini-Fit_Jr_5566-04A_2x02_P4.20mm_Vertical; Manufacturer PN 39-28-1043; LCSC C293502
J5: Conn_02x05_Odd_Even; PinHeader_2x05_P2.54mm_Vertical
J13: GRN_LED; PinHeader_1x02_P2.54mm_Vertical; Manufacturer PN PH1-02-UA
J14: RED_LED; PinHeader_1x02_P2.54mm_Vertical; Manufacturer PN PH1-02-UA
J15: OFF_SERVO; Adam-Tech_1x03_P1.25mm_Vertical; Manufacturer PN PH1-03-UA
J16: PUSH; PinHeader_1x02_P2.54mm_Vertical; Manufacturer PN PH1-02-UA
J17: POT/ENC; PinHeader_1x04_P2.54mm_Vertical
JP1: BL_DIN_SEL; PinHeader_1x03_P2.54mm_Vertical
JP2: BL_DOUT_SEL; PinHeader_1x03_P2.54mm_Vertical
L1: 5.6uH; L_Bourns_SRP6060FA; Manufacturer PN SRP6060FA-5R6M; LCSC C1332221
MK1, MK2, MK3: MH; MountingHole_2.5mm
Q1: 2N7002; SOT-23; LCSC C8545
R1, R2: 120; R_0805_2012Metric_Pad1.15x1.40mm_HandSolder; Manufacturer PN 0805W8F1200T5E; LCSC C17437
R3: 2.2k; R_0603_1608Metric; Manufacturer PN 0603WAF2201T5E; LCSC C4190
R4: 470; R_0603_1608Metric; Manufacturer PN 0603WAF4700T5E; LCSC C23179
R5, R6: 10K; R_0603_1608Metric_Pad0.98x0.95mm_HandSolder; LCSC C25804
R7, R8: 10; R_0603_1608Metric_Pad0.98x0.95mm_HandSolder; LCSC C844519
R9: 0; R_0402_1005Metric; Manufacture PN 0402WGF0000TCE; LCSC C17168
R13: 80.6kΩ; R_0402_1005Metric; Manufacturer PN 0402WGF8062TCE; LCSC C25921
R14: 10kΩ; R_0402_1005Metric; Manufacturer PN 0402WGF1002TCE; LCSC C25744
U0: ProMicro; DIP-24_W15.24mm_Socket; LCSC C72120

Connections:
+3V3: J1.3, J2.3, J15.2, R3.1
+5V: C1.2, IC1.8 (VCC), J17.1, R5.2, U0.21 (VCC)
+12V_SUPPLY: D3.1 (K), F1.1, J1.1, J2.1
/+5V_SUPPLY: J1.2, J2.2, J5.7
/A0: U0.17 (A0)
/A1: U0.18 (A1)
/A2: U0.19 (A2)
/A3: U0.20 (A3)
/BUS_N: D1.2, J1.5, J2.5, R7.2
/BUS_P: D1.1, J1.4, J2.4, R8.2
/D4A6: IC1.2 (~RE), IC1.3 (DE), R6.2, U0.7 (D4/A6)
/D7: J17.2, U0.10 (D7)
/D8A8: J17.4, U0.11 (D8/A8)
/D14MISO: J5.10, U0.15 (D14/MISO)
/D15SCK: J5.9, U0.16 (D15/SCK)
/D16MOSI: J5.2, U0.14 (D16/MOSI)
/DATAIN: J4.4, JP1.1
/DATAOUT: J3.4, JP2.1
/LED+5V: J3.1, J3.2 (Pin_3), J4.1, J4.2 (Pin_3)
/LEDGND: J3.3 (Pin_2), J4.3 (Pin_2)
/LED_DIN: J5.4, JP1.2
/LED_DOUT: J5.8, JP2.2
/RX1D0: IC1.1 (R), R5.1, U0.2 (RX1/D0)
/SDAD2: J16.1, U0.5 (SDA/D2)
/TX0D1: IC1.4 (D), U0.1 (TX0/D1)
/~D5: R4.1, U0.8 (~D5)
/~D6A7: J14.1, U0.9 (~D6/A7)
/~D9A9: J13.1, U0.12 (~D9/A9)
/~D10A10: J5.1, U0.13 (~D10/A10)
/~SCLD3: JP1.3, U0.6 (~SCL/D3)
GND: C1.1, C2.1, C4.2, C5.2, C8.1, D1.3, D3.2 (A), IC1.5 (GND), IC2.4 (GND), J1.6, J2.6, J5.5, J5.6, J15.1, J16.2, J17.3, JP2.3, Q1.2 (S), R1.1, R2.1, R6.1, R14.1, U0.3 (GND), U0.4 (GND), U0.23 (GND)
unnamed: C3.2, R9.2
unnamed: C4.1, C5.1, D2.2 (A), L1.2, R13.2
unnamed: IC1.6 (A), R8.1
unnamed: IC1.7 (B), R7.1
unnamed: IC2.6 (BST), R9.1
unnamed: IC2.8 (FB), R13.1, R14.2
unnamed: C3.1, IC2.5 (SW), L1.1
unnamed: C2.2, C8.2, F1.2, IC2.3 (VIN)
unnamed: J13.2, R1.2
unnamed: J14.2, R2.2
unnamed: J15.3, Q1.3 (D), R3.2
unnamed: Q1.1 (G), R4.2
Vin(+7.3V): D2.1 (K), U0.24 (RAW)

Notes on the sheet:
ABSIS BUS CONNECTORS
RS485 BUS CONTROLLER
12V POWER CONDITIONING (12V -> 7.3V)
USB SHOULD BE ACCESSIBLE FOR PROGRAMMING
MOUNT HOLES
COIL3
FIDUCIALS
DIAL READOUT W/ LED'S
COIL4
ENCODER OR POTENTIOMETER
NOTES: (UNLESS OTHERWISE SPECIFIED)
PUSH BUTTON
LED_DOUT
1) BL DATA SELECT: PLACE JUMPER OVER PINS 1 & 2 OF JP1/JP2 TO SELECT DATA INPUT FROM BACKLIGHTING BUS. PLACE JUMPER OVER PINS 2 & 3 OF JP2/JP3 TO SELECT DATA FROM THE RADAR ALTIMETER CONTROLLER MCU. 2) J17 IS USED FOR BOTH AN ENCODER AND LINEAR POTENTIOMETER. DO USE BOTH SIMULTANEOUSLY. USE PINS 1 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
COIL2
COIL1
DIAL FACE INDICATOR LED'S
PWR FLAGS
LED_DIN
SERVO CONTROL DRIVER
BL CONNECTORS

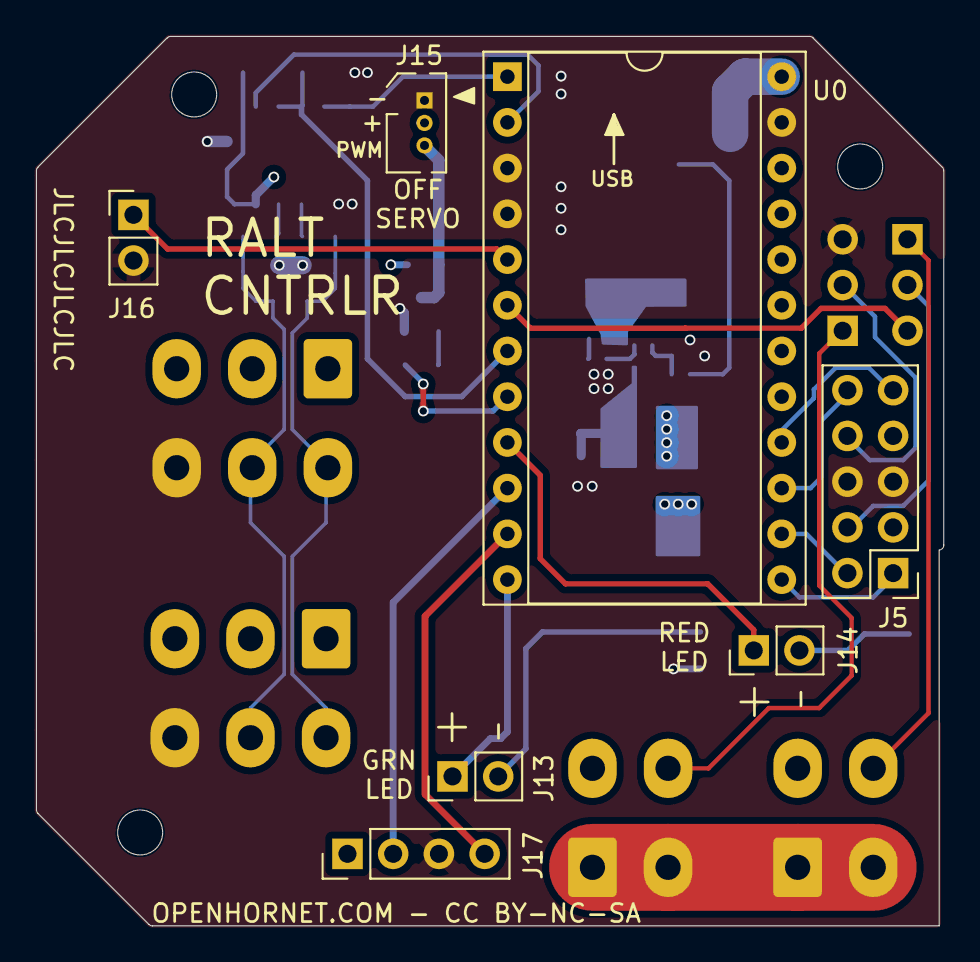
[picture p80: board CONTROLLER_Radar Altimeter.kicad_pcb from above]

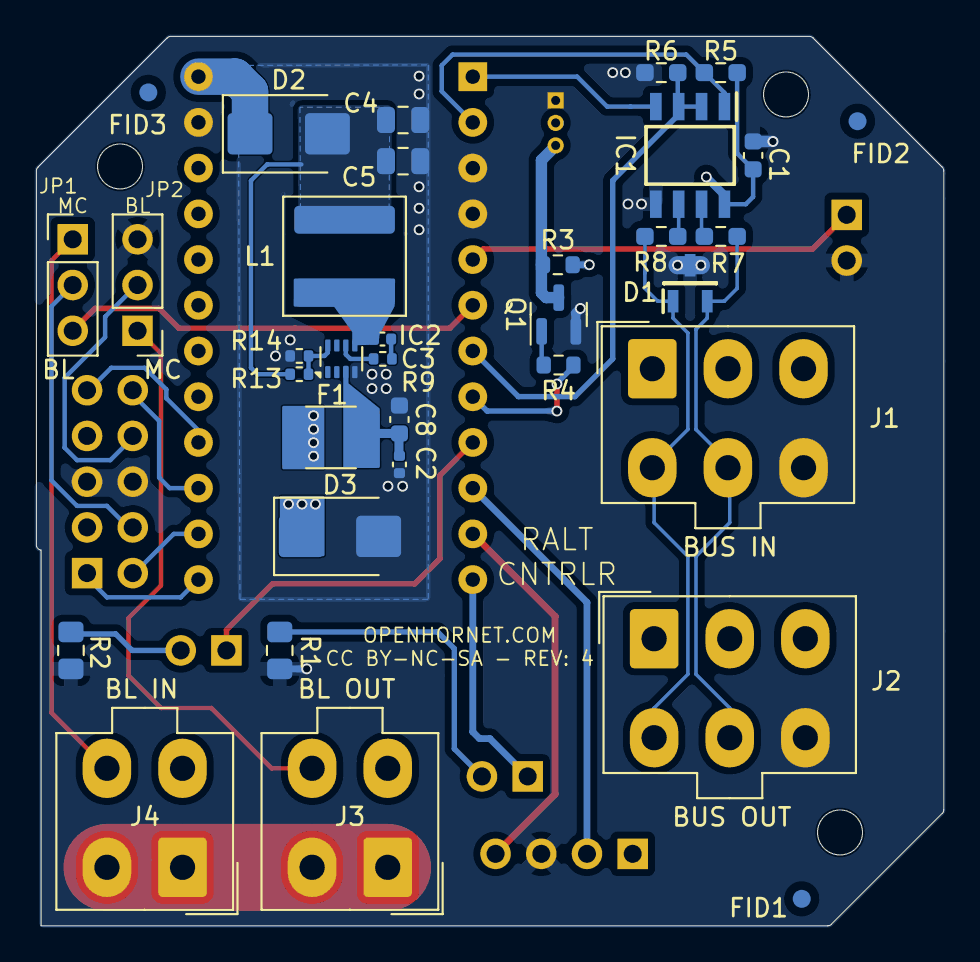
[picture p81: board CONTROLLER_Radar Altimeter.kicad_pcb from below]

Board: 6 copper layers, 50.4 x 49.4 mm, 44 parts (34 on the bottom side), 40 nets.

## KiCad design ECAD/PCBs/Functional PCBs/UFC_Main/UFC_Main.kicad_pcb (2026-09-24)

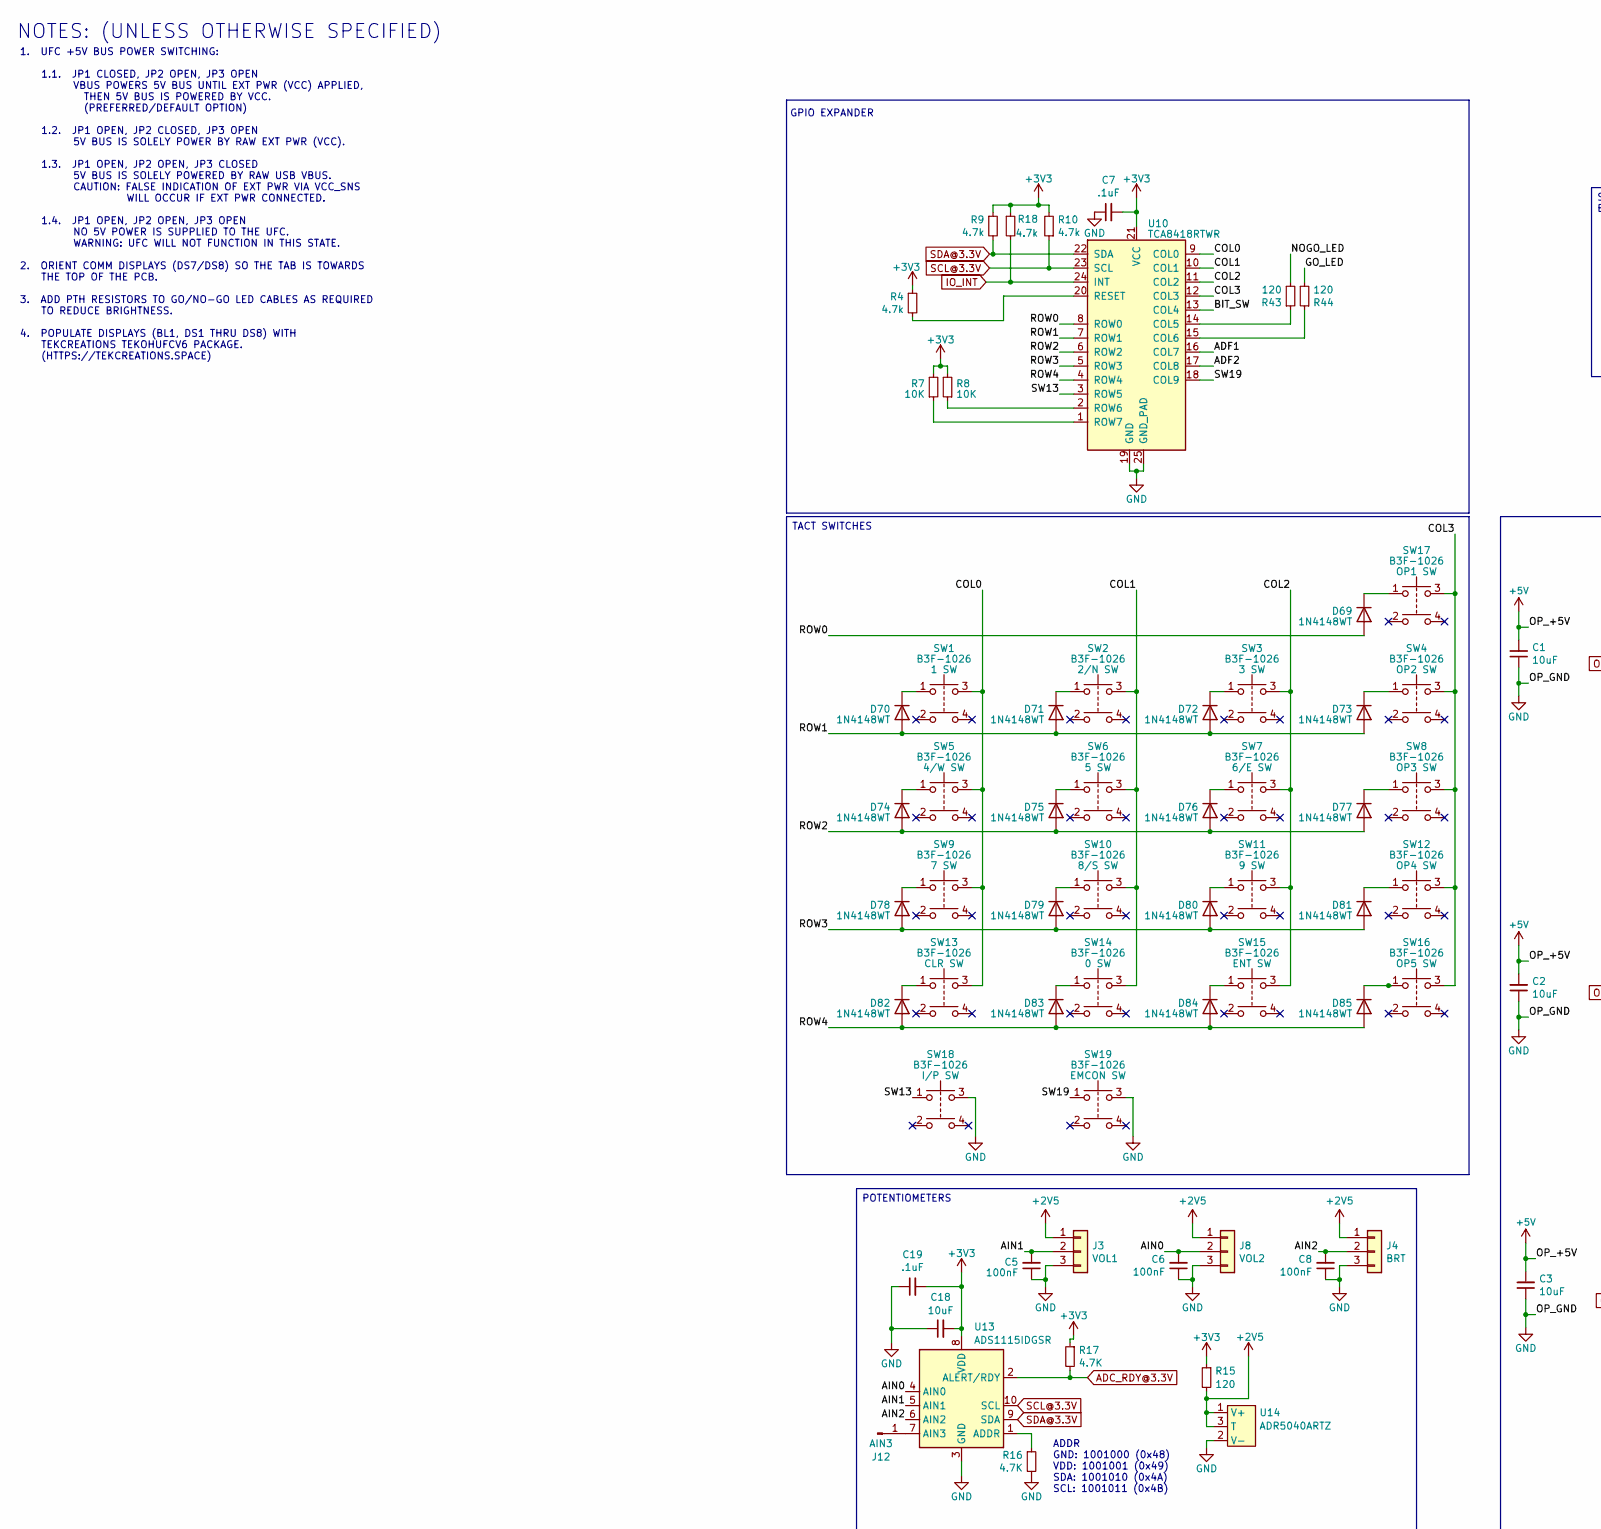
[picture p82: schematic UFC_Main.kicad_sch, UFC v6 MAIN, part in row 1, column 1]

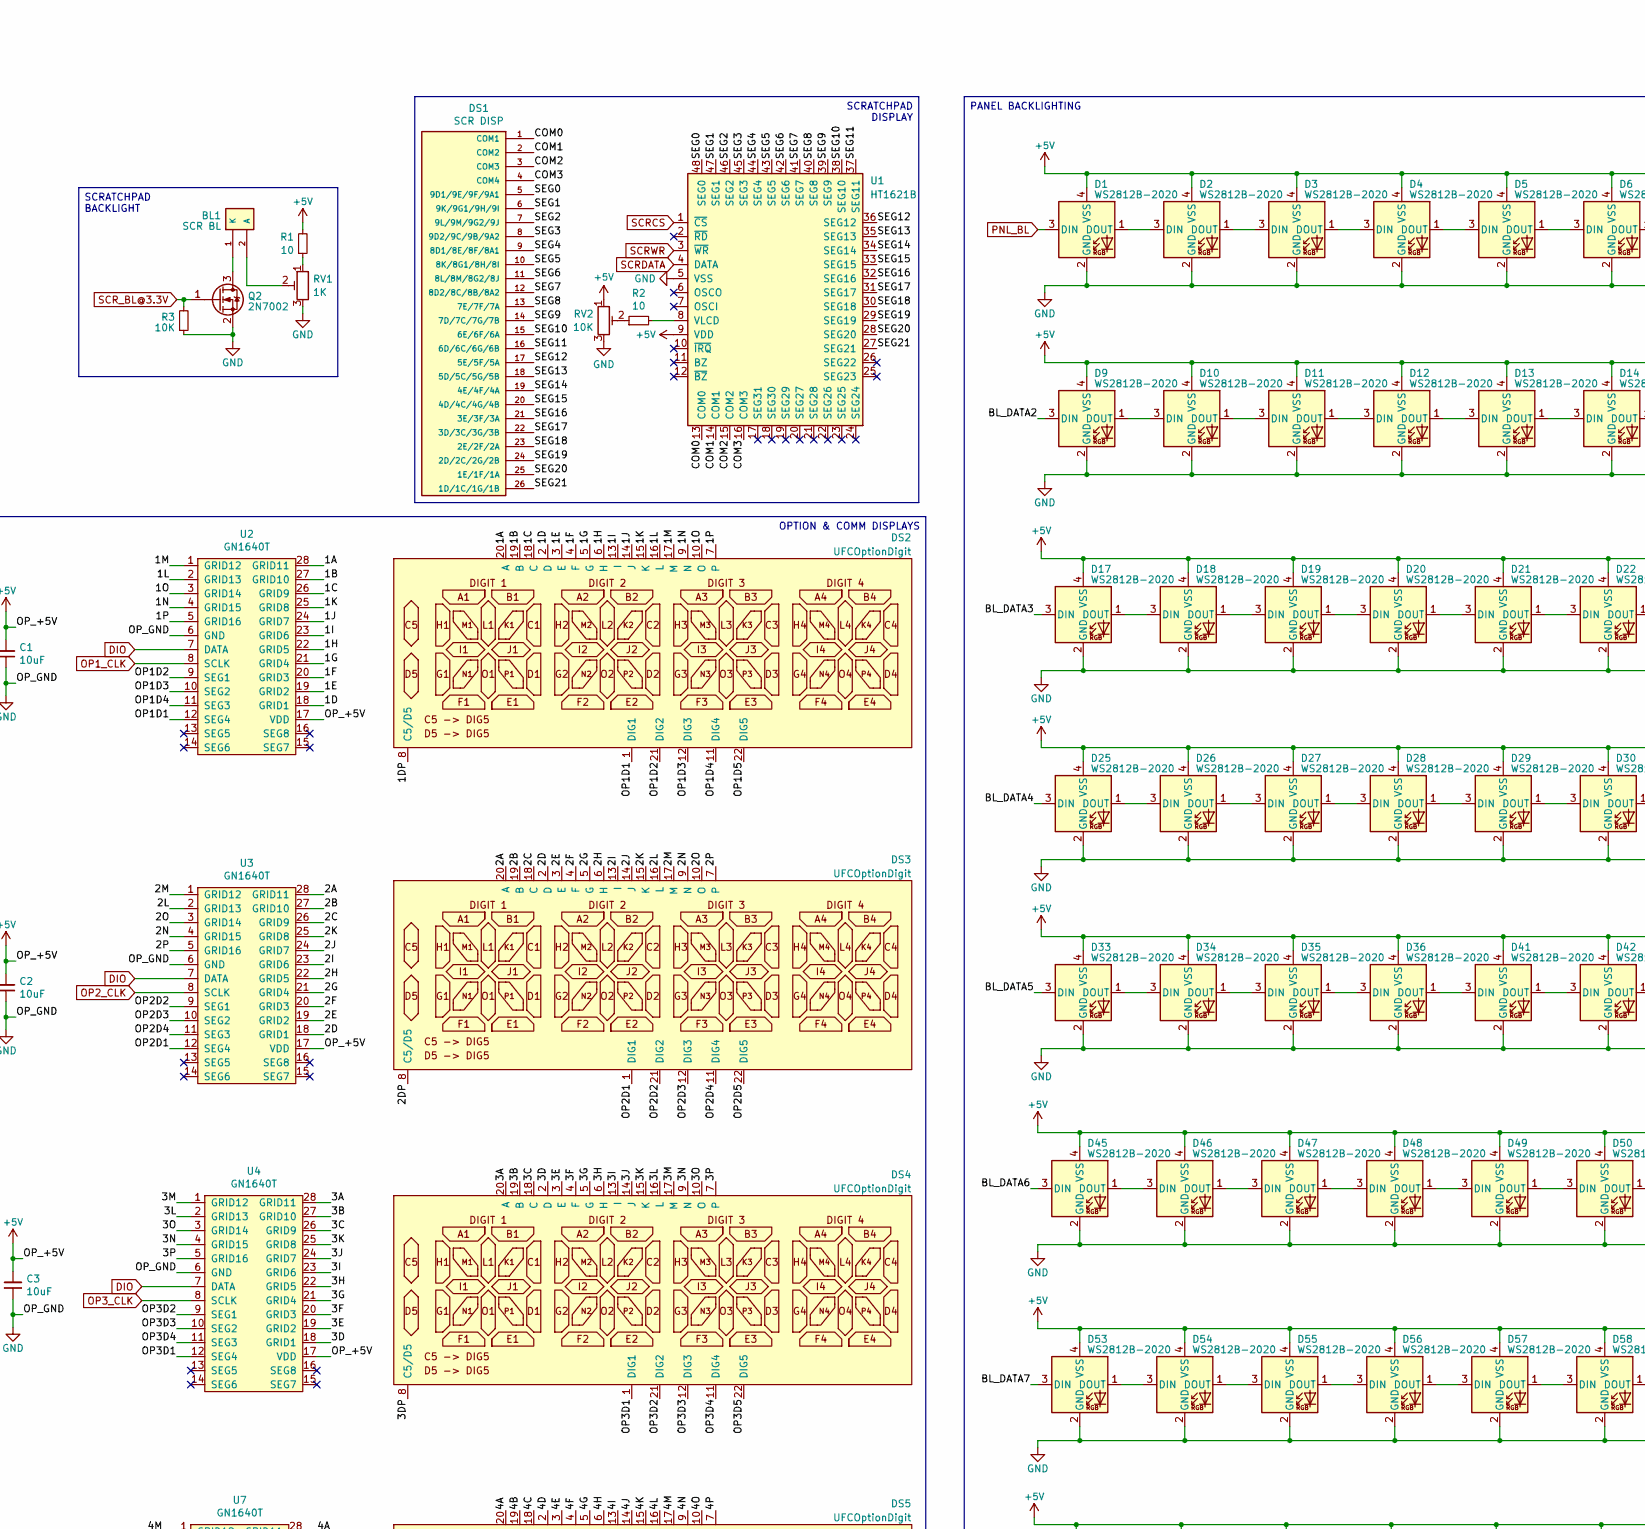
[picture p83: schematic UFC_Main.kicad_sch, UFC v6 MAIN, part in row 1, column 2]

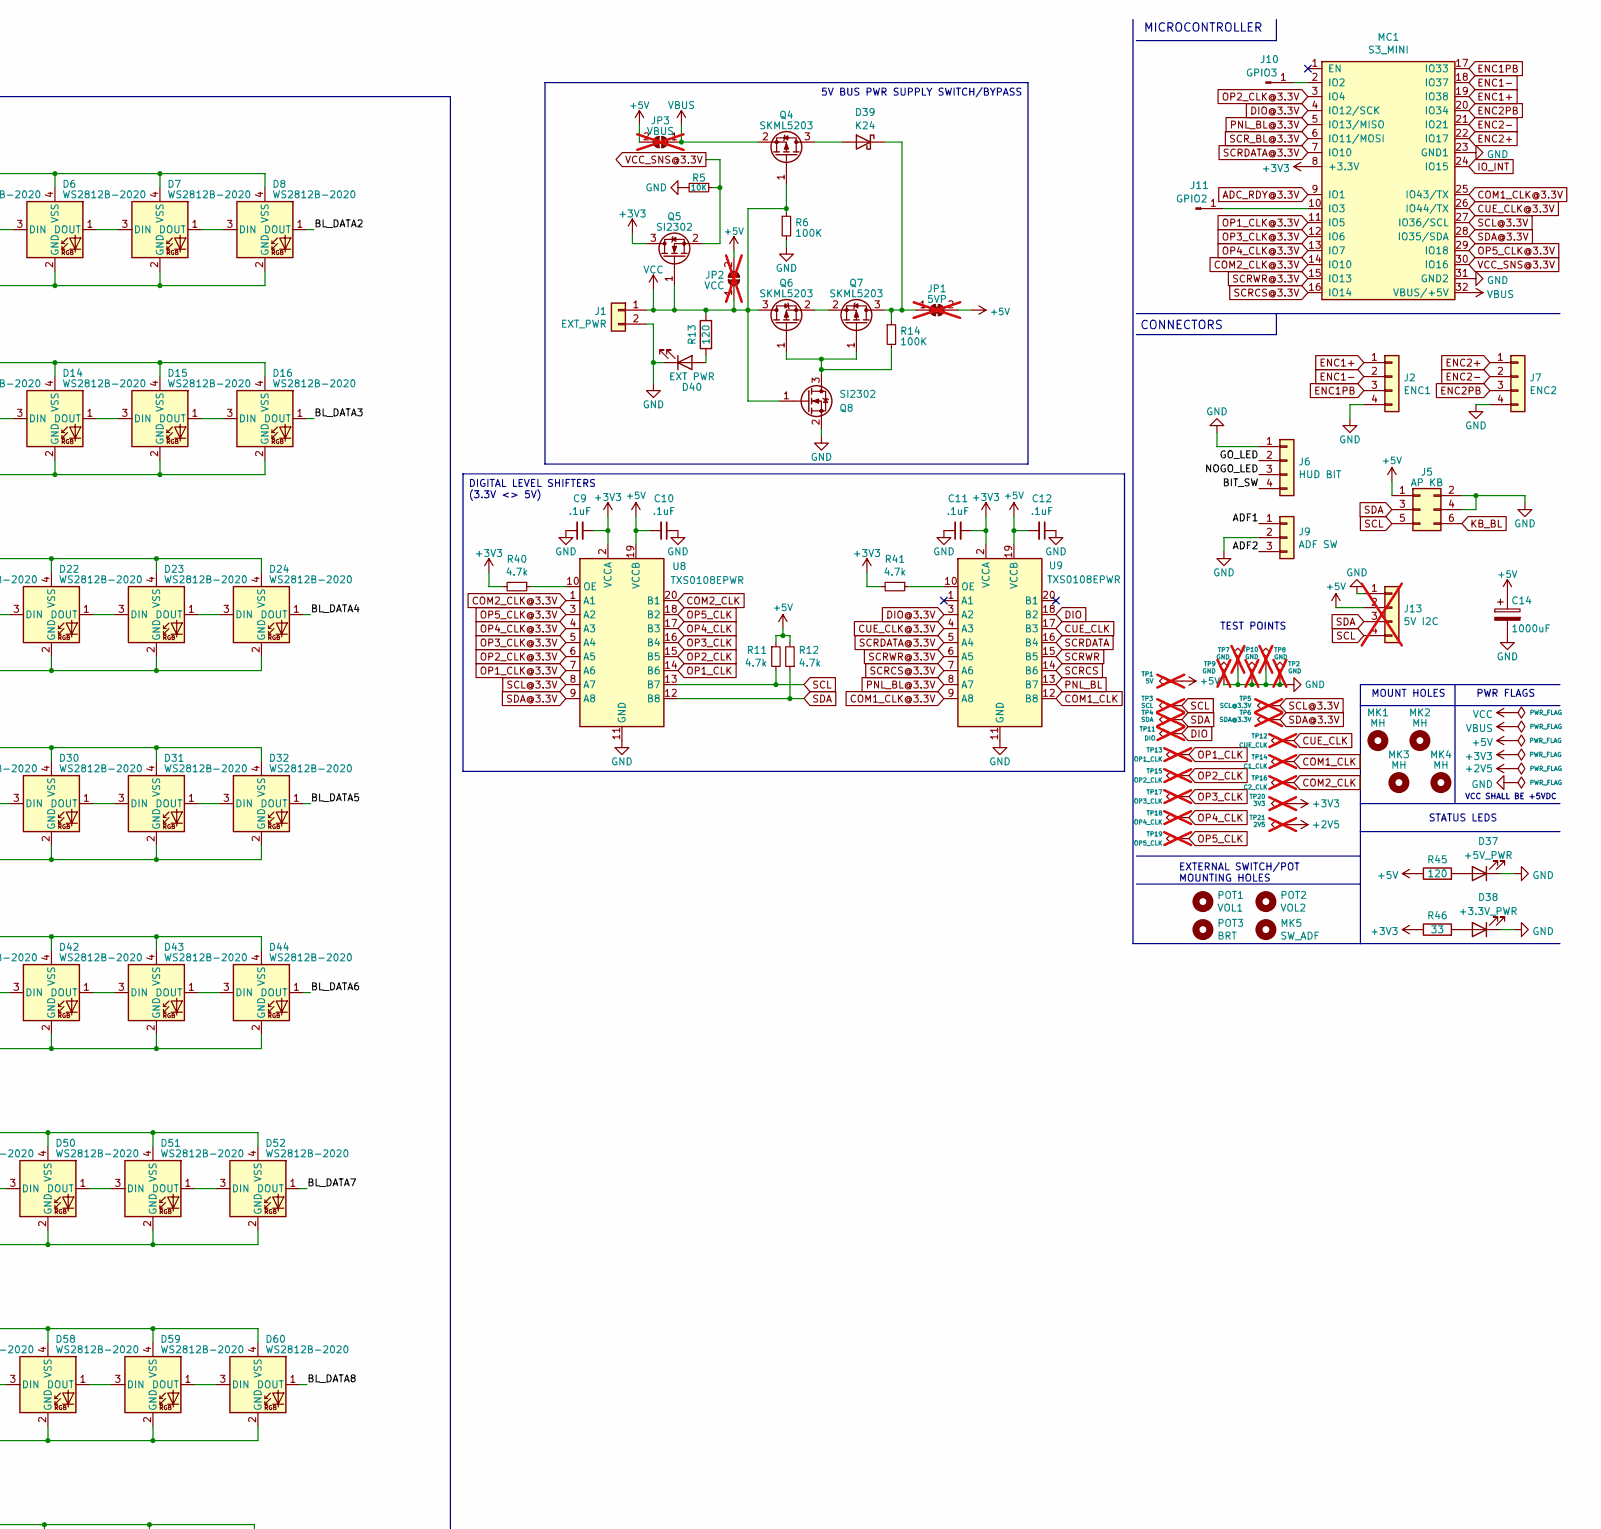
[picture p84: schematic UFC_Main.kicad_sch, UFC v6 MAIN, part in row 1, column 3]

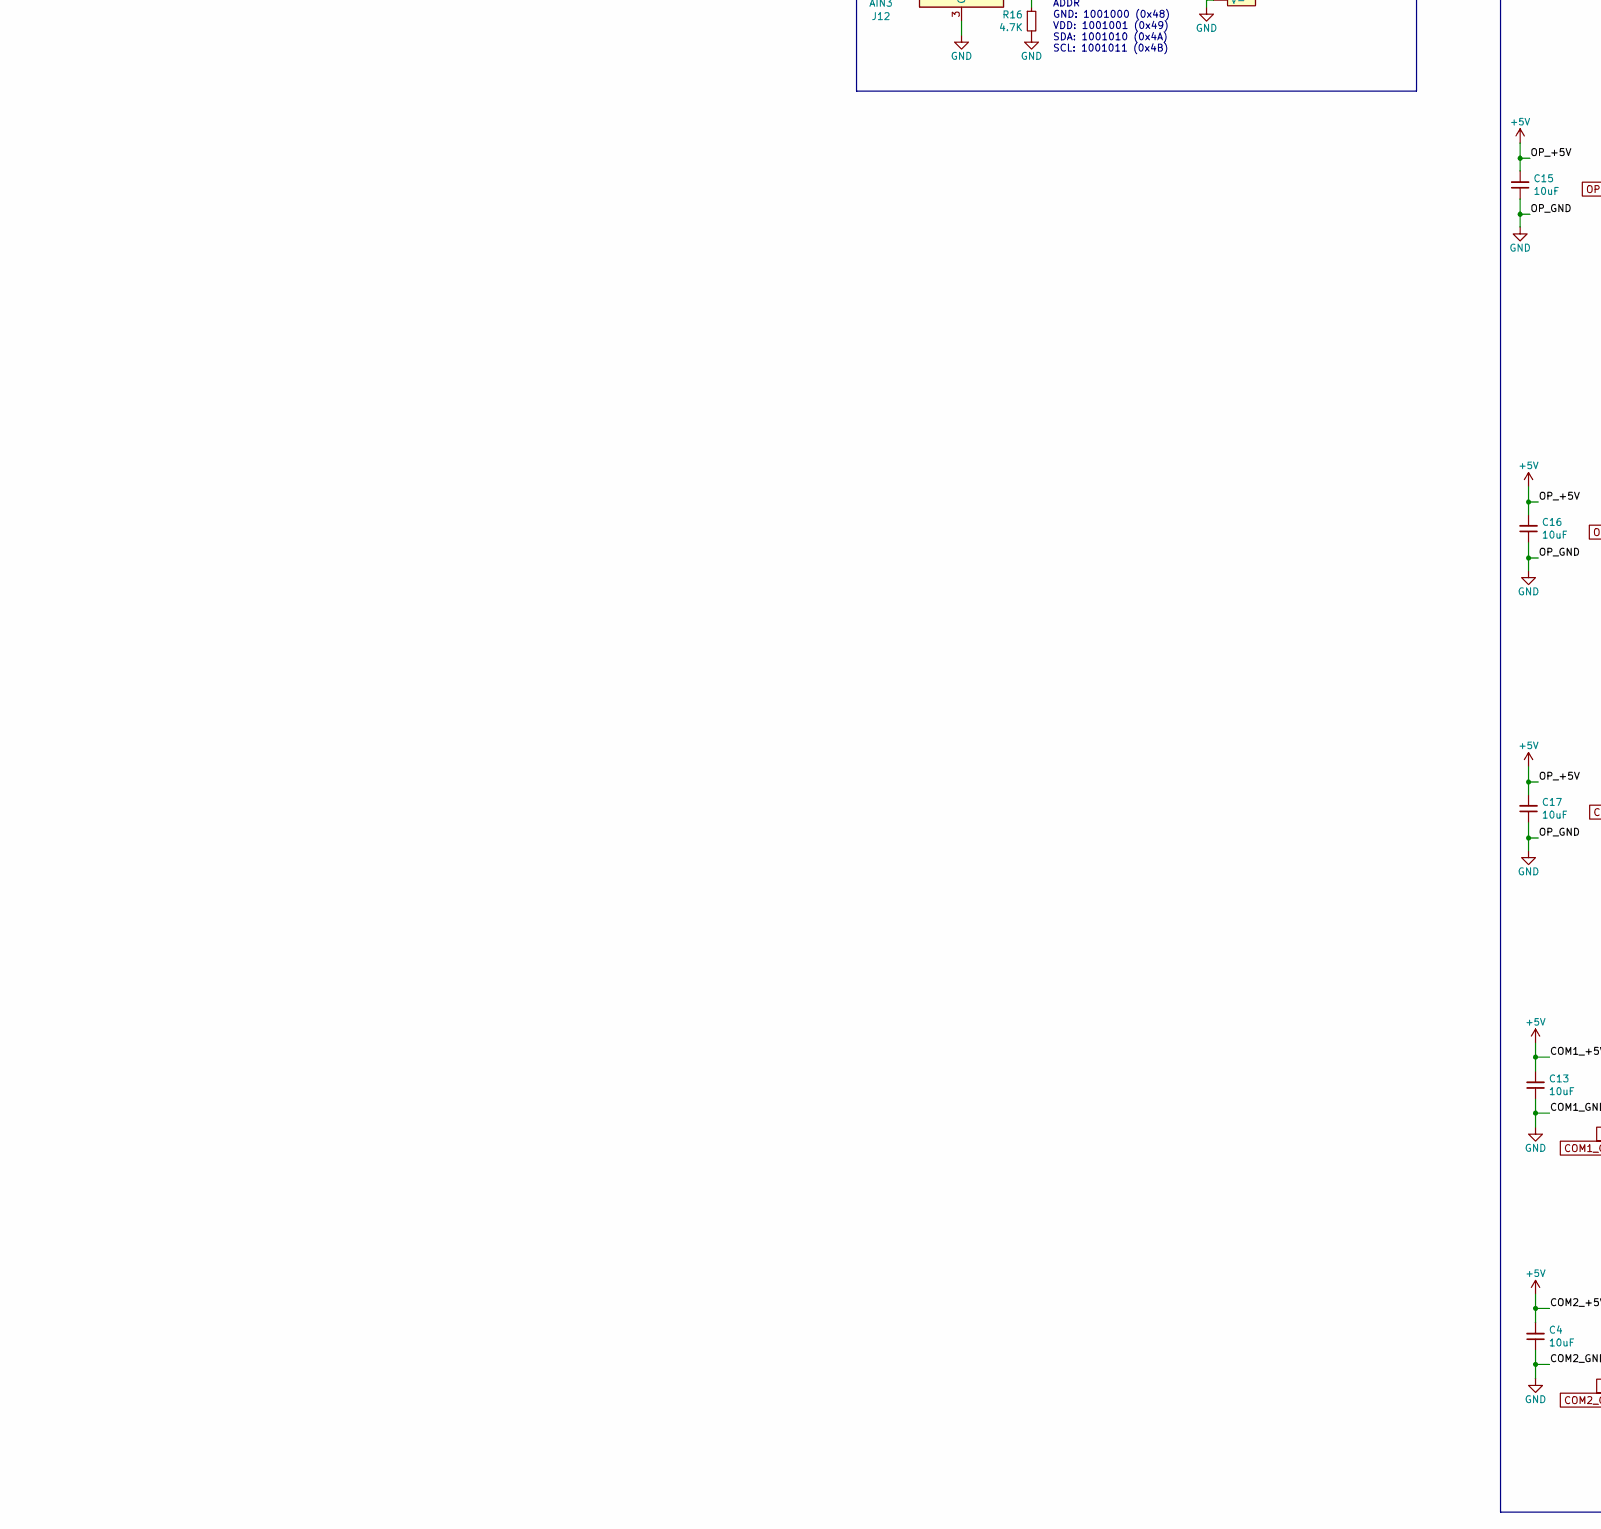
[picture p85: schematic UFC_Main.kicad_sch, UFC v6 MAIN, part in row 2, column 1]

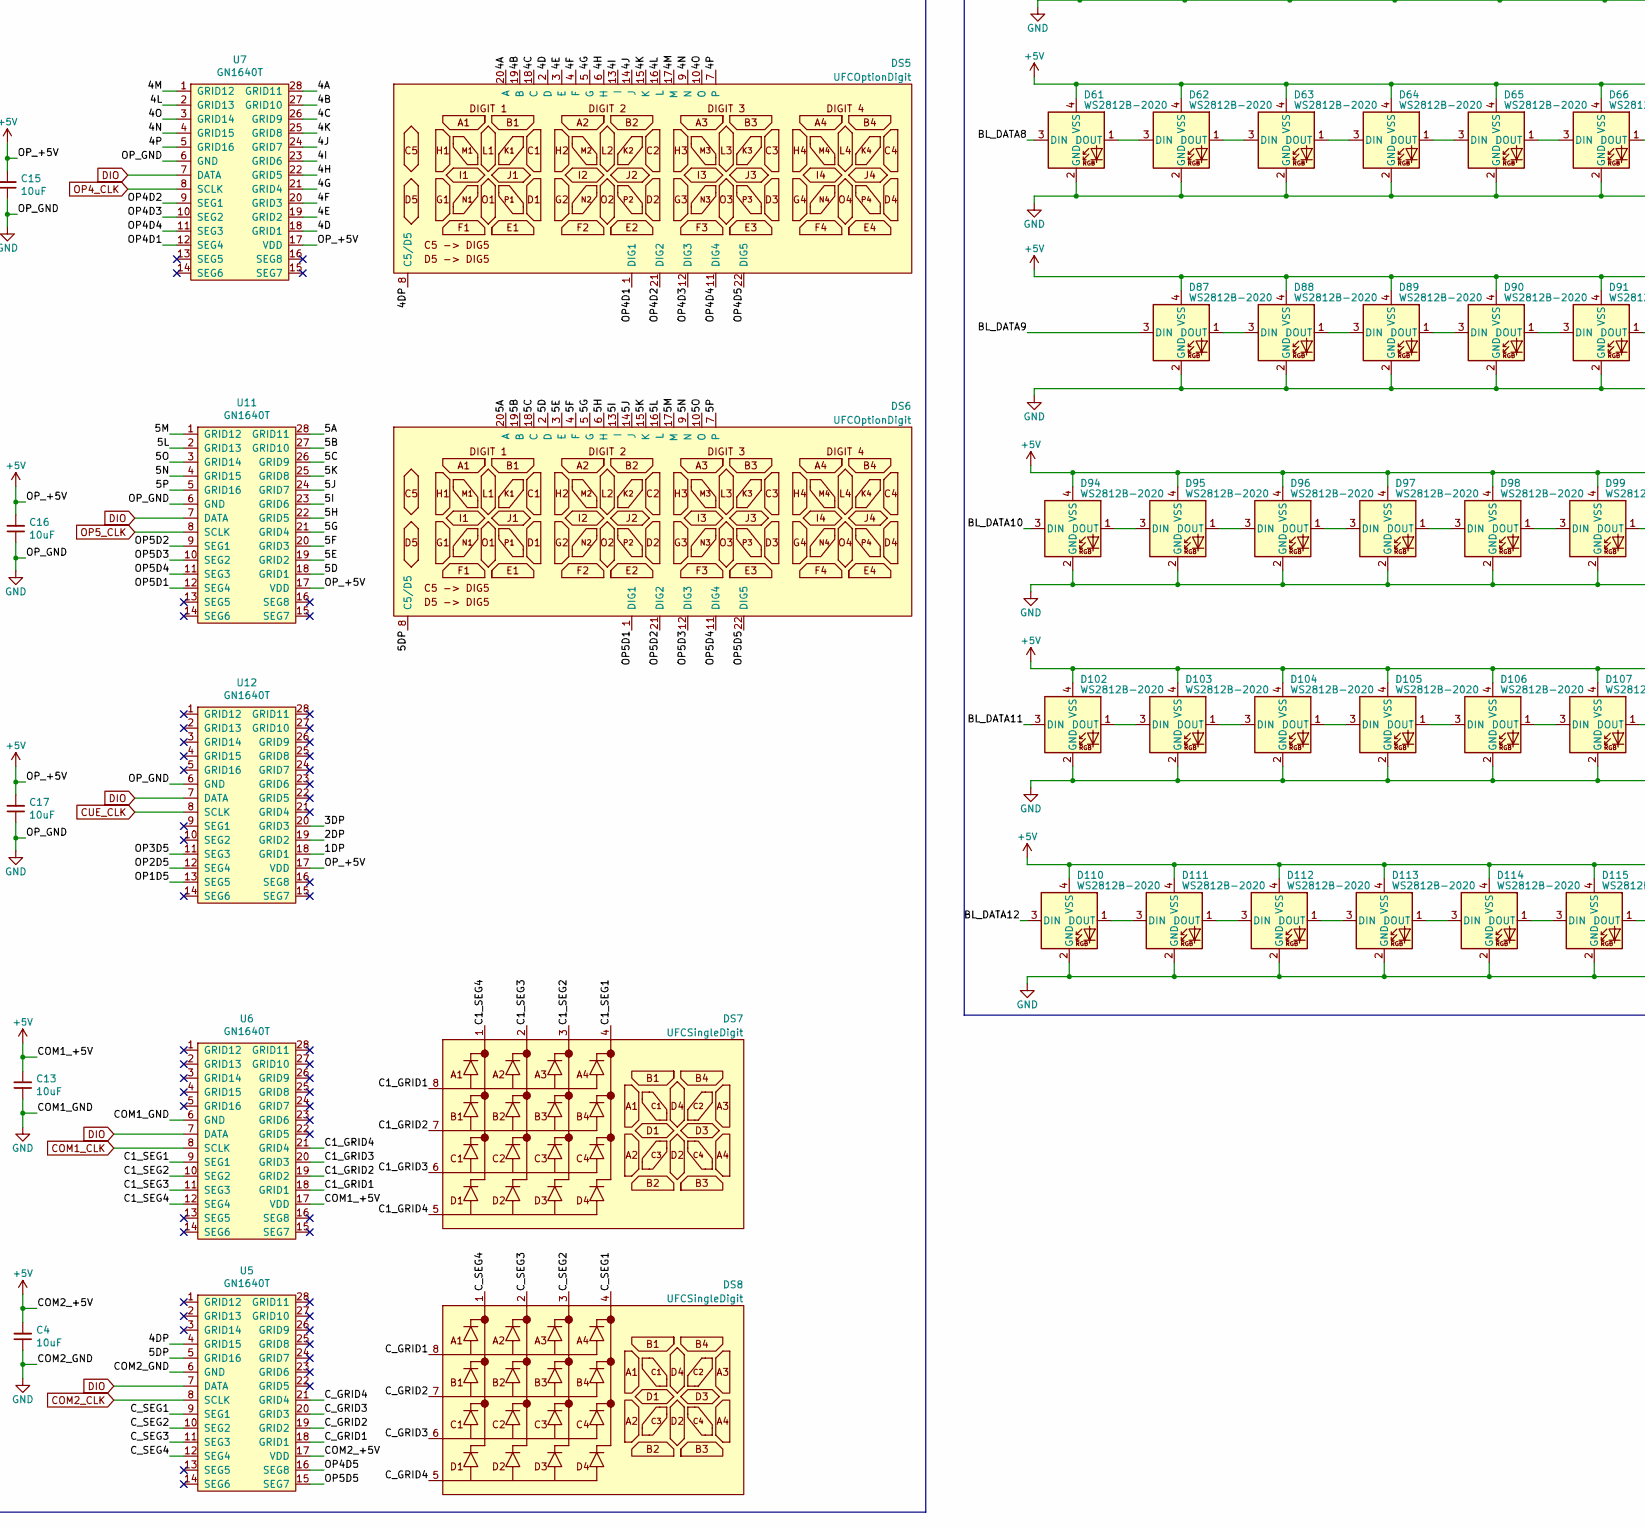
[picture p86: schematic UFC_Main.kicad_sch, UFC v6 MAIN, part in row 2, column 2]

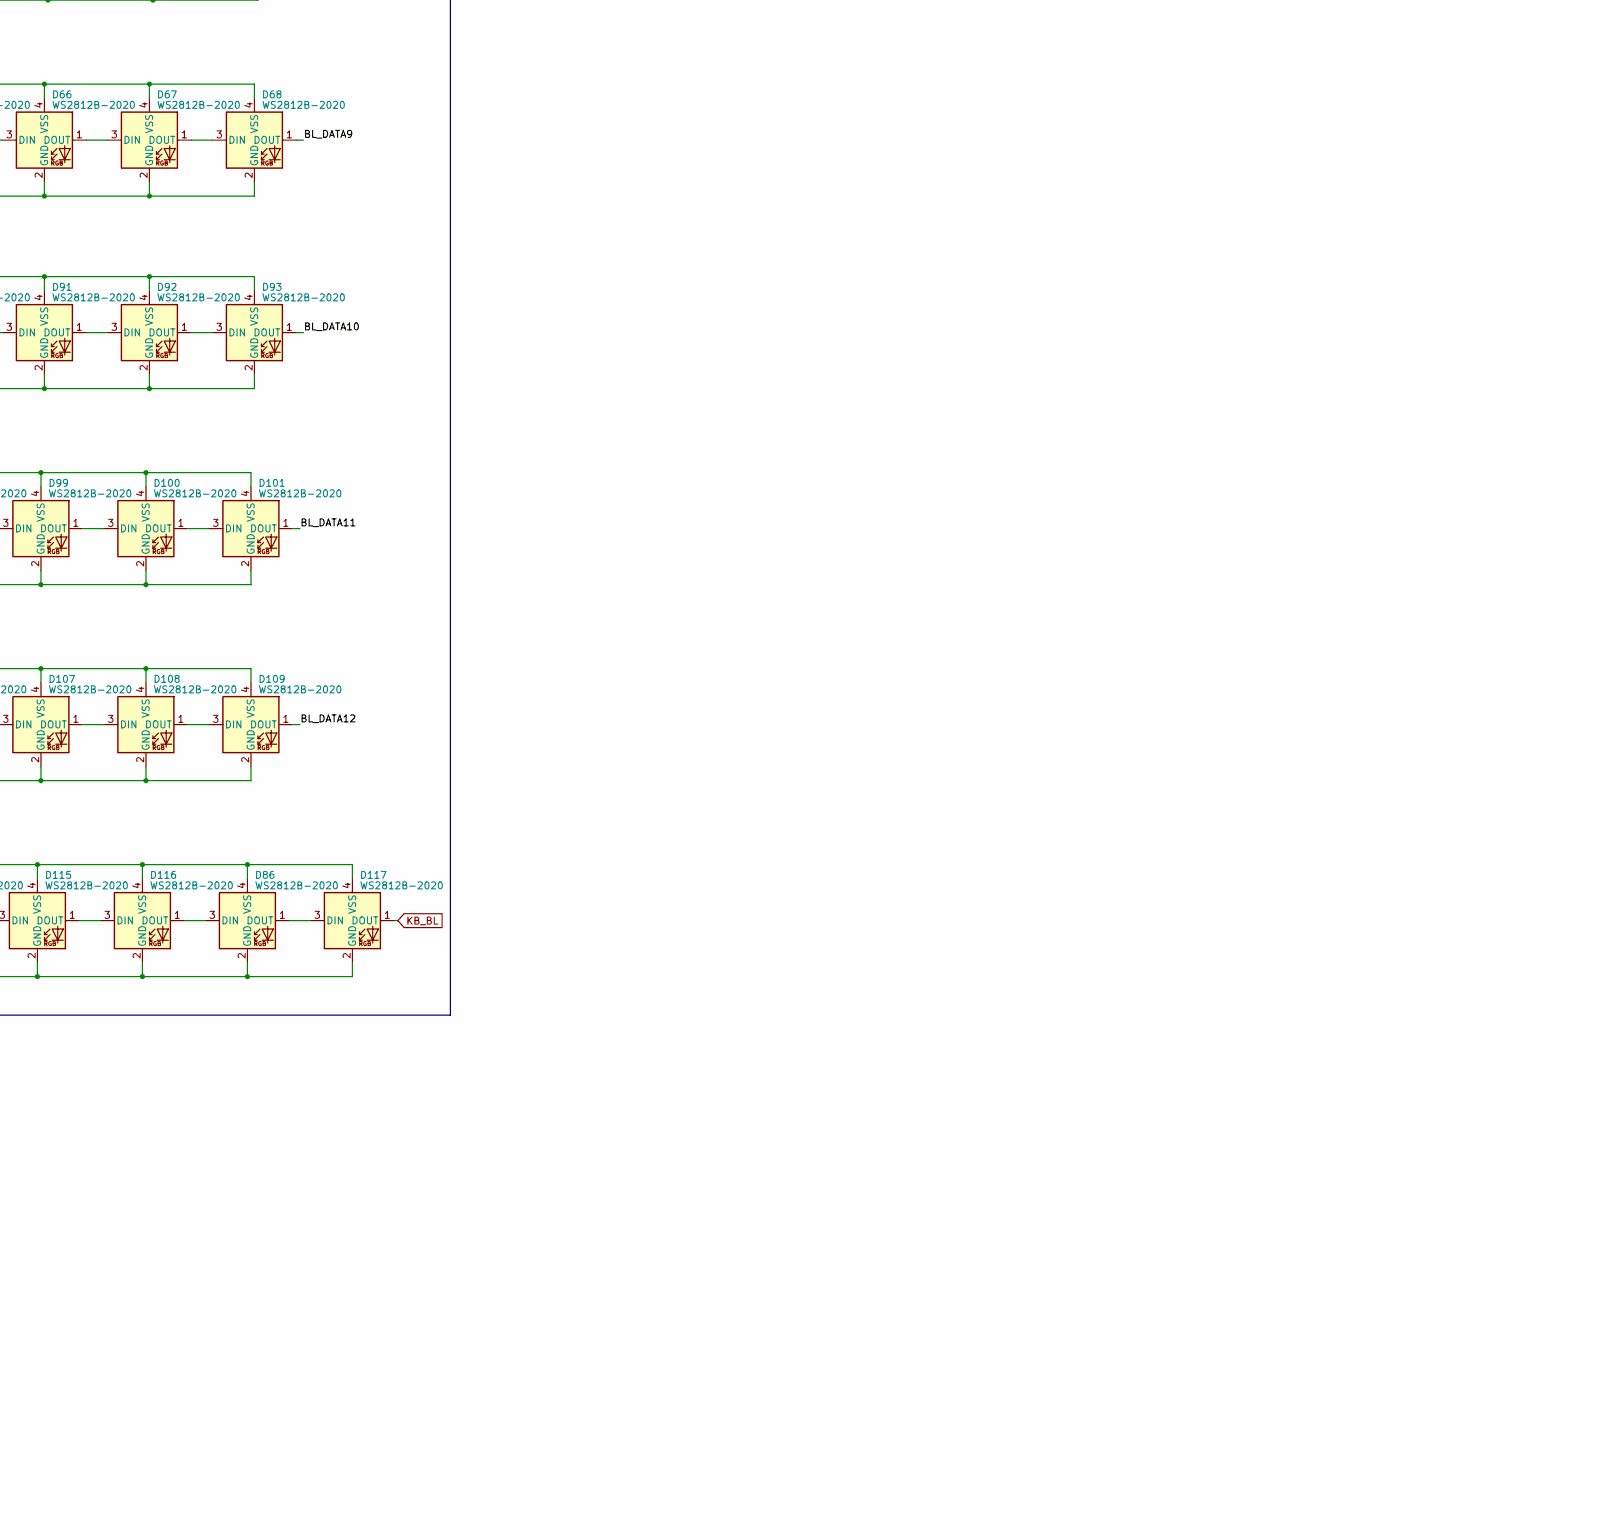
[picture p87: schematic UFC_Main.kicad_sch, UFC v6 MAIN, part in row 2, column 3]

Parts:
BL1: SCR BL; SCRATCHPADBACKLIGHT
C1, C2, C3, C4, C13, C15, C16, C17: 10uF; C_0805_2012Metric; Manufacturer PN CL21A106KAYNNNE; LCSC C15850
C5, C6, C8: 100nF; C_0402_1005Metric; Manufacturer PN CL05B104KO5NNNC; LCSC C1525
C7, C9, C10, C11, C12, C19: .1uF; C_0603_1608Metric; Manufacturer PN CC0603KRX7R9BB104; LCSC C14663
C14: 1000uF; CP_Elec_8x10; Manufacturer PN UWT0J102MNL1GS; LCSC C445083
C18: 10uF; C_0402_1005Metric; Manufacturer PN CL21A106KAYNNNE; LCSC C15525
D1, D2, D3, D4, D5, D6, D7, D8, D9, D10, D11, D12, D13, D14, D15, D16, D17, D18, D19, D20, D21, D22, D23, D24, D25, D26, D27, D28, D29, D30, D31, D32, D33, D34, D35, D36, D41, D42, D43, D44, D45, D46, D47, D48, D49, D50, D51, D52, D53, D54, D55, D56, D57, D58, D59, D60, D61, D62, D63, D64, D65, D66, D67, D68, D86, D87, D88, D89, D90, D91, D92, D93, D94, D95, D96, D97, D98, D99, D100, D101, D102, D103, D104, D105, D106, D107, D108, D109, D110, D111, D112, D113, D114, D115, D116, D117: WS2812B-2020; LED_WS2812B-2020_PLCC4_2.0x2.0mm; Manufacturer PN WS2812B-2020-V6; LCSC C52917434
D37: +5V_PWR; LED_0603_1608Metric_Pad1.05x0.95mm_HandSolder; Manufacturer PN 19-217/GHC-YR1S2/3T; LCSC C72043
D38: +3.3V_PWR; LED_0603_1608Metric_Pad1.05x0.95mm_HandSolder; Manufacturer PN 19-217/GHC-YR1S2/3T; LCSC C72043
D39: K24; D_SOD-123F; Manufacturer PN K24; LCSC C908664
D40: EXT PWR; LED_0603_1608Metric_Pad1.05x0.95mm_HandSolder; Manufacturer PN 19-217/GHC-YR1S2/3T; LCSC C72043
D69, D70, D71, D72, D73, D74, D75, D76, D77, D78, D79, D80, D81, D82, D83, D84, D85: 1N4148WT; D_SOD-523; Manufacturer PN 1N4148WT; LCSC C727112
DS1: SCR DISP; SCRATCHPADLCD
DS2, DS3, DS4, DS5, DS6: UFCOptionDigit; UFCOptionDigitV3
DS7, DS8: UFCSingleDigit
J1: EXT_PWR; PinHeader_1x02_P2.54mm_Vertical
J2: ENC1; PinHeader_1x04_P2.54mm_Vertical
J3: VOL1; PinHeader_1x03_P2.54mm_Vertical
J4: BRT; PinHeader_1x03_P2.54mm_Vertical
J5: AP KB; PinHeader_2x03_P2.54mm_Vertical
J6: HUD BIT; PinHeader_1x04_P2.54mm_Vertical
J7: ENC2; PinHeader_1x04_P2.54mm_Vertical
J8: VOL2; PinHeader_1x03_P2.54mm_Vertical
J9: ADF SW; PinHeader_1x03_P2.54mm_Vertical
J10: GPIO3; SolderWirePad_1x01_SMD_1x2mm
J11: GPIO2; SolderWirePad_1x01_SMD_1x2mm
J12: AIN3; SolderWirePad_1x01_SMD_1x2mm
J13: 5V I2C; PinHeader_1x04_P2.54mm_Vertical; not fitted
JP1: 5VP; SolderJumper-2_P1.3mm_Bridged2Bar_Pad1.0x1.5mm; not fitted
JP2: VCC; SolderJumper-2_P1.3mm_Open_Pad1.0x1.5mm; not fitted
JP3: VBUS; SolderJumper-2_P1.3mm_Open_Pad1.0x1.5mm; not fitted
MC1: S3_MINI; S2_MINI
MK1, MK2, MK3, MK4: MH; MountingHole_4.5mm
MK5: SW_ADF; MountingHole_6.4mm_M6
POT1: VOL1; BR10K_Pot_11mm_x_11mm
POT2: VOL2; BR10K_Pot_11mm_x_11mm
POT3: BRT; BR10K_Pot_11mm_x_11mm
Q2: 2N7002; SOT-23; Manufacturer PN 2N7002; LCSC C8545
Q4, Q6, Q7: SKML5203; SOT-23; Manufacturer PN ME2328-G; LCSC C475707
Q5, Q8: SI2302; SOT-23; Manufacturer PN SI2302; LCSC C2891732
R1: 10; R_2512_6332Metric_Pad1.40x3.35mm_HandSolder; Manufacturer PN 352210RJT
R2: 10; C_0402_1005Metric_Pad0.74x0.62mm_HandSolder; Manufacturer PN 0402WGF100JTCE; LCSC C25077
R3, R5, R7, R8: 10K; R_0603_1608Metric; Manufacturer PN 0603WAF1002T5E; LCSC C25804
R4, R9, R10, R11, R12, R18, R40, R41: 4.7k; R_0603_1608Metric; Manufacturer PN 0603WAF4701T5E; LCSC C23162
R6, R14: 100K; R_0402_1005Metric; Manufacturer PN 0402WGF1003TCE; LCSC C25741
R13, R15, R43, R44, R45: 120; R_0603_1608Metric; Manufacturer PN 0603WAF1200T5E; LCSC C22787
R16, R17: 4.7K; R_0603_1608Metric; Manufacturer PN 0603WAF4701T5E; LCSC C23162
R46: 33; R_0402_1005Metric; Manufacturer PN 0402WGF330JTCE; LCSC C25105
RV1: 1K; Potentiometer_Bourns_3386P_Vertical; Manufacturer PN 3386P-1-102LF
RV2: 10K; Potentiometer_Bourns_3386P_Vertical; Manufacturer PN 3386P-1-103LF
SW1, SW2, SW3, SW4, SW5, SW6, SW7, SW8, SW9, SW10, SW11, SW12, SW13, SW14, SW15, SW16, SW17, SW18, SW19: B3F-1026; Omron_B3F-1026; Manufacturer PN B3F-1026
TP1: 5V; TestPoint_THTPad_D1.5mm_Drill0.7mm; not fitted
TP2, TP7, TP8, TP9, TP10: GND; TestPoint_THTPad_D1.5mm_Drill0.7mm; not fitted
TP3: SCL; TestPoint_THTPad_D1.5mm_Drill0.7mm; not fitted
TP4: SDA; TestPoint_THTPad_D1.5mm_Drill0.7mm; not fitted
TP5: SCL@3.3V; TestPoint_THTPad_D1.5mm_Drill0.7mm; not fitted
TP6: SDA@3.3V; TestPoint_THTPad_D1.5mm_Drill0.7mm; not fitted
TP11: DIO; TestPoint_THTPad_D1.5mm_Drill0.7mm; not fitted
TP12: CUE_CLK; TestPoint_THTPad_D1.5mm_Drill0.7mm; not fitted
TP13: OP1_CLK; TestPoint_THTPad_D1.5mm_Drill0.7mm; not fitted
TP14: C1_CLK; TestPoint_THTPad_D1.5mm_Drill0.7mm; not fitted
TP15: OP2_CLK; TestPoint_THTPad_D1.5mm_Drill0.7mm; not fitted
TP16: C2_CLK; TestPoint_THTPad_D1.5mm_Drill0.7mm; not fitted
TP17: OP3_CLK; TestPoint_THTPad_D1.5mm_Drill0.7mm; not fitted
TP18: OP4_CLK; TestPoint_THTPad_D1.5mm_Drill0.7mm; not fitted
TP19: OP5_CLK; TestPoint_THTPad_D1.5mm_Drill0.7mm; not fitted
TP20: 3V3; TestPoint_THTPad_D1.5mm_Drill0.7mm; not fitted
TP21: 2V5; TestPoint_THTPad_D1.5mm_Drill0.7mm; not fitted
U1: HT1621B; LQFP-48_7x7mm_P0.5mm; LCSC C7532
U2, U3, U4, U5, U6, U7, U11, U12: GN1640T; SSOP-28_3.9x9.9mm_P0.635mm; LCSC C2758330
U8, U9: TXS0108EPWR; TSSOP-20_4.4x6.5mm_P0.65mm; Manufacturer PN TXS0108EPWR; LCSC C17206
U10: TCA8418RTWR; WQFN-24-1EP_4x4mm_P0.5mm_EP2.45x2.45mm; Manufacturer PN TCA8418RTWR; LCSC C138713
U13: ADS1115IDGSR; VSSOP-10_3x3mm_P0.5mm; LCSC C37593
U14: ADR5040ARTZ; SOT-23-3; LCSC C144273

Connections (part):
+2V5: J3.1, J4.1, J8.1, R15.2, TP21.1 (1_1), U14.1 (V+), U14.3 (T)
+3V3: C7.2, C9.2, C11.2, C18.2, C19.2, MC1.8 (+3.3V), Q5.3 (D), R4.1, R7.2, R8.2, R9.1, R10.2, R15.1, R17.1, R18.1, R40.2, R41.2, R46.1, TP20.1 (1_1), U8.2 (VCCA), U9.2 (VCCA), U10.21 (VCC), U13.8 (VDD)
+5V: C1.2, C2.2, C3.2, C4.2, C10.2, C12.2, C13.2, C14.1, C15.2, C16.2, C17.2, D1.4 (VSS), D2.4 (VSS), D3.4 (VSS), D4.4 (VSS), D5.4 (VSS), D6.4 (VSS), D7.4 (VSS), D8.4 (VSS), D9.4 (VSS), D10.4 (VSS), D11.4 (VSS), D12.4 (VSS), D13.4 (VSS), D14.4 (VSS), D15.4 (VSS), D16.4 (VSS), D17.4 (VSS), D18.4 (VSS), D19.4 (VSS), D20.4 (VSS), D21.4 (VSS), D22.4 (VSS), D23.4 (VSS), D24.4 (VSS), D25.4 (VSS), D26.4 (VSS), D27.4 (VSS), D28.4 (VSS), D29.4 (VSS), D30.4 (VSS), D31.4 (VSS), D32.4 (VSS), D33.4 (VSS), D34.4 (VSS), D35.4 (VSS), D36.4 (VSS), D41.4 (VSS), D42.4 (VSS), D43.4 (VSS), D44.4 (VSS), D45.4 (VSS), D46.4 (VSS), D47.4 (VSS), D48.4 (VSS), D49.4 (VSS), D50.4 (VSS), D51.4 (VSS), D52.4 (VSS), D53.4 (VSS), D54.4 (VSS), D55.4 (VSS), D56.4 (VSS), D57.4 (VSS), D58.4 (VSS), D59.4 (VSS), D60.4 (VSS), D61.4 (VSS), D62.4 (VSS), D63.4 (VSS), D64.4 (VSS), D65.4 (VSS), D66.4 (VSS), D67.4 (VSS), D68.4 (VSS), D86.4 (VSS), D87.4 (VSS), D88.4 (VSS), D89.4 (VSS), D90.4 (VSS), D91.4 (VSS), D92.4 (VSS), D93.4 (VSS), D94.4 (VSS)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
/1A: DS2.20 (A), U2.28 (GRID11)
/1B: DS2.19 (B), U2.27 (GRID10)
/1C: DS2.18 (C), U2.26 (GRID9)
/1D: DS2.2 (D), U2.18 (GRID1)
/1DP: DS2.8 (C5/D5), U12.18 (GRID1)
/1E: DS2.3 (E), U2.19 (GRID2)
/1F: DS2.4 (F), U2.20 (GRID3)
/1G: DS2.5 (G), U2.21 (GRID4)
/1H: DS2.6 (H), U2.22 (GRID5)
/1I: DS2.13 (I), U2.23 (GRID6)
/1J: DS2.14 (J), U2.24 (GRID7)
/1K: DS2.15 (K), U2.25 (GRID8)
/1L: DS2.16 (L), U2.2 (GRID13)
/1M: DS2.17 (M), U2.1 (GRID12)
/1N: DS2.9 (N), U2.4 (GRID15)
/1O: DS2.10 (O), U2.3 (GRID14)
/1P: DS2.7, U2.5 (GRID16)
/2A: DS3.20 (A), U3.28 (GRID11)
/2B: DS3.19 (B), U3.27 (GRID10)
/2C: DS3.18 (C), U3.26 (GRID9)
/2D: DS3.2 (D), U3.18 (GRID1)
/2DP: DS3.8 (C5/D5), U12.19 (GRID2)
/2E: DS3.3 (E), U3.19 (GRID2)
/2F: DS3.4 (F), U3.20 (GRID3)
/2G: DS3.5 (G), U3.21 (GRID4)
/2H: DS3.6 (H), U3.22 (GRID5)
/2I: DS3.13 (I), U3.23 (GRID6)
/2J: DS3.14 (J), U3.24 (GRID7)
/2K: DS3.15 (K), U3.25 (GRID8)
/2L: DS3.16 (L), U3.2 (GRID13)
/2M: DS3.17 (M), U3.1 (GRID12)
/2N: DS3.9 (N), U3.4 (GRID15)
/2O: DS3.10 (O), U3.3 (GRID14)
/2P: DS3.7, U3.5 (GRID16)
/3A: DS4.20 (A), U4.28 (GRID11)
/3B: DS4.19 (B), U4.27 (GRID10)
/3C: DS4.18 (C), U4.26 (GRID9)
/3D: DS4.2 (D), U4.18 (GRID1)
/3DP: DS4.8 (C5/D5), U12.20 (GRID3)
/3E: DS4.3 (E), U4.19 (GRID2)
/3F: DS4.4 (F), U4.20 (GRID3)
/3G: DS4.5 (G), U4.21 (GRID4)
/3H: DS4.6 (H), U4.22 (GRID5)
/3I: DS4.13 (I), U4.23 (GRID6)
/3J: DS4.14 (J), U4.24 (GRID7)
/3K: DS4.15 (K), U4.25 (GRID8)
/3L: DS4.16 (L), U4.2 (GRID13)
/3M: DS4.17 (M), U4.1 (GRID12)
/3N: DS4.9 (N), U4.4 (GRID15)
/3O: DS4.10 (O), U4.3 (GRID14)
/3P: DS4.7, U4.5 (GRID16)
/4A: DS5.20 (A), U7.28 (GRID11)
/4B: DS5.19 (B), U7.27 (GRID10)
/4C: DS5.18 (C), U7.26 (GRID9)
/4D: DS5.2 (D), U7.18 (GRID1)
/4DP: DS5.8 (C5/D5), U5.4 (GRID15)
/4E: DS5.3 (E), U7.19 (GRID2)
/4F: DS5.4 (F), U7.20 (GRID3)
/4G: DS5.5 (G), U7.21 (GRID4)
/4H: DS5.6 (H), U7.22 (GRID5)
/4I: DS5.13 (I), U7.23 (GRID6)
/4J: DS5.14 (J), U7.24 (GRID7)
/4K: DS5.15 (K), U7.25 (GRID8)
/4L: DS5.16 (L), U7.2 (GRID13)
/4M: DS5.17 (M), U7.1 (GRID12)
/4N: DS5.9 (N), U7.4 (GRID15)
/4O: DS5.10 (O), U7.3 (GRID14)
/4P: DS5.7, U7.5 (GRID16)
/5A: DS6.20 (A), U11.28 (GRID11)
/5B: DS6.19 (B), U11.27 (GRID10)
/5C: DS6.18 (C), U11.26 (GRID9)
/5D: DS6.2 (D), U11.18 (GRID1)
/5DP: DS6.8 (C5/D5), U5.5 (GRID16)
/5E: DS6.3 (E), U11.19 (GRID2)
/5F: DS6.4 (F), U11.20 (GRID3)
/5G: DS6.5 (G), U11.21 (GRID4)
/5H: DS6.6 (H), U11.22 (GRID5)
/5I: DS6.13 (I), U11.23 (GRID6)
/5J: DS6.14 (J), U11.24 (GRID7)
/5K: DS6.15 (K), U11.25 (GRID8)
/5L: DS6.16 (L), U11.2 (GRID13)
/5M: DS6.17 (M), U11.1 (GRID12)
/5N: DS6.9 (N), U11.4 (GRID15)
/5O: DS6.10 (O), U11.3 (GRID14)
/5P: DS6.7, U11.5 (GRID16)
/ADF1: J9.1, U10.16 (COL7)
/ADF2: J9.3, U10.17 (COL8)
/AIN0: C6.2, J8.2, U13.4 (AIN0)
/AIN1: C5.2, J3.2, U13.5 (AIN1)
/AIN2: C8.2, J4.2, U13.6 (AIN2)
/BIT_SW: J6.4, U10.13 (COL4)
/BL_DATA2: D8.1 (DOUT), D9.3 (DIN)
/BL_DATA3: D16.1 (DOUT), D17.3 (DIN)
/BL_DATA4: D24.1 (DOUT), D25.3 (DIN)
/BL_DATA5: D32.1 (DOUT), D33.3 (DIN)
/BL_DATA6: D44.1 (DOUT), D45.3 (DIN)
/BL_DATA7: D52.1 (DOUT), D53.3 (DIN)
/BL_DATA8: D60.1 (DOUT), D61.3 (DIN)
/BL_DATA9: D68.1 (DOUT), D87.3 (DIN)
/BL_DATA10: D93.1 (DOUT), D94.3 (DIN)
/BL_DATA11: D101.1 (DOUT), D102.3 (DIN)
/BL_DATA12: D109.1 (DOUT), D110.3 (DIN)
/C1_GRID1: DS7.8, U6.18 (GRID1)
/C1_GRID2: DS7.7, U6.19 (GRID2)
/C1_GRID3: DS7.6, U6.20 (GRID3)
/C1_GRID4: DS7.5, U6.21 (GRID4)
/C1_SEG1: DS7.4, U6.9 (SEG1)
/C1_SEG2: DS7.3, U6.10 (SEG2)
/C1_SEG3: DS7.2, U6.11 (SEG3)
/C1_SEG4: DS7.1, U6.12 (SEG4)
/COL0: SW1.3, SW5.3, SW9.3, SW13.3, U10.9 (COL0)
/COL1: SW2.3, SW6.3, SW10.3, SW14.3, U10.10 (COL1)
/COL2: SW3.3, SW7.3, SW11.3, SW15.3, U10.11 (COL2)
/COL3: SW4.3, SW8.3, SW12.3, SW16.3, SW17.3, U10.12 (COL3)
/COM0: DS1.1 (COM1), U1.13 (COM0)
/COM1: DS1.2 (COM2), U1.14 (COM1)
/COM2: DS1.3 (COM3), U1.15 (COM2)
/COM3: DS1.4 (COM4), U1.16 (COM3)
/C_GRID1: DS8.8, U5.18 (GRID1)
/C_GRID2: DS8.7, U5.19 (GRID2)
/C_GRID3: DS8.6, U5.20 (GRID3)
/C_GRID4: DS8.5, U5.21 (GRID4)
/C_SEG1: DS8.4, U5.9 (SEG1)
/C_SEG2: DS8.3, U5.10 (SEG2)
/C_SEG3: DS8.2, U5.11 (SEG3)
/C_SEG4: DS8.1, U5.12 (SEG4)
/GO_LED: J6.2, R44.2
/NOGO_LED: J6.3, R43.2
/OP1D1: DS2.1 (DIG1), U2.12 (SEG4)
/OP1D2: DS2.21 (DIG2), U2.9 (SEG1)
/OP1D3: DS2.12 (DIG3), U2.10 (SEG2)
/OP1D4: DS2.11 (DIG4), U2.11 (SEG3)
/OP1D5: DS2.22 (DIG5), U12.13 (SEG5)
/OP2D1: DS3.1 (DIG1), U3.12 (SEG4)
/OP2D2: DS3.21 (DIG2), U3.9 (SEG1)
/OP2D3: DS3.12 (DIG3), U3.10 (SEG2)
/OP2D4: DS3.11 (DIG4), U3.11 (SEG3)
/OP2D5: DS3.22 (DIG5), U12.12 (SEG4)
/OP3D1: DS4.1 (DIG1), U4.12 (SEG4)
/OP3D2: DS4.21 (DIG2), U4.9 (SEG1)
/OP3D3: DS4.12 (DIG3), U4.10 (SEG2)
/OP3D4: DS4.11 (DIG4), U4.11 (SEG3)
/OP3D5: DS4.22 (DIG5), U12.11 (SEG3)
/OP4D1: DS5.1 (DIG1), U7.12 (SEG4)
/OP4D2: DS5.21 (DIG2), U7.9 (SEG1)
/OP4D3: DS5.12 (DIG3), U7.10 (SEG2)
/OP4D4: DS5.11 (DIG4), U7.11 (SEG3)
/OP4D5: DS5.22 (DIG5), U5.16 (SEG8)
/OP5D1: DS6.1 (DIG1), U11.12 (SEG4)
/OP5D2: DS6.21 (DIG2), U11.9 (SEG1)
/OP5D3: DS6.12 (DIG3), U11.10 (SEG2)
/OP5D4: DS6.11 (DIG4), U11.11 (SEG3)
/OP5D5: DS6.22 (DIG5), U5.15 (SEG7)
/ROW0: D69.2 (A), U10.8 (ROW0)
/ROW1: D70.2 (A), D71.2 (A), D72.2 (A), D73.2 (A), U10.7 (ROW1)
/ROW2: D74.2 (A), D75.2 (A), D76.2 (A), D77.2 (A), U10.6 (ROW2)
/ROW3: D78.2 (A), D79.2 (A), D80.2 (A), D81.2 (A), U10.5 (ROW3)
/ROW4: D82.2 (A), D83.2 (A), D84.2 (A), D85.2 (A), U10.4 (ROW4)
/SEG0: DS1.5 (9D1/9E/9F/9A1), U1.48 (SEG0)
/SEG1: DS1.6 (9K/9G1/9H/9I), U1.47 (SEG1)
/SEG2: DS1.7 (9L/9M/9G2/9J), U1.46 (SEG2)
/SEG3: DS1.8 (9D2/9C/9B/9A2), U1.45 (SEG3)
/SEG4: DS1.9 (8D1/8E/8F/8A1), U1.44 (SEG4)
/SEG5: DS1.10 (8K/8G1/8H/8I), U1.43 (SEG5)
/SEG6: DS1.11 (8L/8M/8G2/8J), U1.42 (SEG6)
/SEG7: DS1.12 (8D2/8C/8B/8A2), U1.41 (SEG7)
/SEG8: DS1.13 (7E/7F/7A), U1.40 (SEG8)
/SEG9: DS1.14 (7D/7C/7G/7B), U1.39 (SEG9)
/SEG10: DS1.15 (6E/6F/6A), U1.38 (SEG10)
/SEG11: DS1.16 (6D/6C/6G/6B), U1.37 (SEG11)
/SEG12: DS1.17 (5E/5F/5A), U1.36 (SEG12)
/SEG13: DS1.18 (5D/5C/5G/5B), U1.35 (SEG13)
/SEG14: DS1.19 (4E/4F/4A), U1.34 (SEG14)
/SEG15: DS1.20 (4D/4C/4G/4B), U1.33 (SEG15)
/SEG16: DS1.21 (3E/3F/3A), U1.32 (SEG16)
/SEG17: DS1.22 (3D/3C/3G/3B), U1.31 (SEG17)
/SEG18: DS1.23 (2E/2F/2A), U1.30 (SEG18)
/SEG19: DS1.24 (2D/2C/2G/2B), U1.29 (SEG19)
/SEG20: DS1.25 (1E/1F/1A), U1.28 (SEG20)
/SEG21: DS1.26 (1D/1C/1G/1B), U1.27 (SEG21)
/SW13: SW18.1, U10.3 (ROW5)
/SW19: SW19.1, U10.18 (COL9)
ADC_RDY@3.3V: MC1.9 (IO1), R17.2, U13.2 (ALERT/RDY)
COM1_CLK: TP14.1 (1_1), U6.8 (SCLK), U9.12 (B8)
COM1_CLK@3.3V: MC1.25 (IO43/TX), U9.9 (A8)
COM2_CLK: TP16.1 (1_1), U5.8 (SCLK), U8.20 (B1)
COM2_CLK@3.3V: MC1.14 (IO10), U8.1 (A1)
CUE_CLK: TP12.1 (1_1), U9.17 (B3), U12.8 (SCLK)
CUE_CLK@3.3V: MC1.26 (IO44/TX), U9.4 (A3)
DIO: TP11.1 (1_1), U2.7 (DATA), U3.7 (DATA), U4.7 (DATA), U5.7 (DATA), U6.7 (DATA), U7.7 (DATA), U9.18 (B2), U11.7 (DATA), U12.7 (DATA)
DIO@3.3V: MC1.4 (IO12/SCK), U9.3 (A2)
ENC1+: J2.1, MC1.19 (IO38)
ENC1-: J2.2, MC1.18 (IO37)
ENC1PB: J2.3, MC1.17 (IO33)
ENC2+: J7.1, MC1.22 (IO17)
ENC2-: J7.2, MC1.21 (IO21)
ENC2PB: J7.3, MC1.20 (IO34)
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

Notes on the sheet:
ADDR GND: 1001000 (0x48) VDD: 1001001 (0x49) SDA: 1001010 (0x4A) SCL: 1001011 (0x4B)
NOTES: (UNLESS OTHERWISE SPECIFIED)
EXTERNAL SWITCH/POT MOUNTING HOLES
MICROCONTROLLER
CONNECTORS
STATUS LEDS
TEST POINTS
MOUNT HOLES
PWR FLAGS
VCC SHALL BE +5VDC
1. UFC +5V BUS POWER SWITCHING: 1.1. JP1 CLOSED, JP2 OPEN, JP3 OPEN VBUS POWERS 5V BUS UNTIL EXT PWR (VCC) APPLIED, THEN 5V BUS IS POWERED BY VCC. (PREFERRED/DEFAULT OPTION) 1.2. JP1 OPEN, JP2 CLOSED, JP3 OPEN 5V BUS IS SOLELY POWER BY RAW EXT PWR (VCC). 1.3. JP1 OPEN, JP2 OPEN, JP3 CLOSED 5V BUS I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
GPIO EXPANDER
POTENTIOMETERS
5V BUS PWR SUPPLY SWITCH/BYPASS
SCRATCHPAD DISPLAY
SCRATCHPAD BACKLIGHT
TACT SWITCHES
PANEL BACKLIGHTING
DIGITAL LEVEL SHIFTERS (3.3V <> 5V)
OPTION & COMM DISPLAYS

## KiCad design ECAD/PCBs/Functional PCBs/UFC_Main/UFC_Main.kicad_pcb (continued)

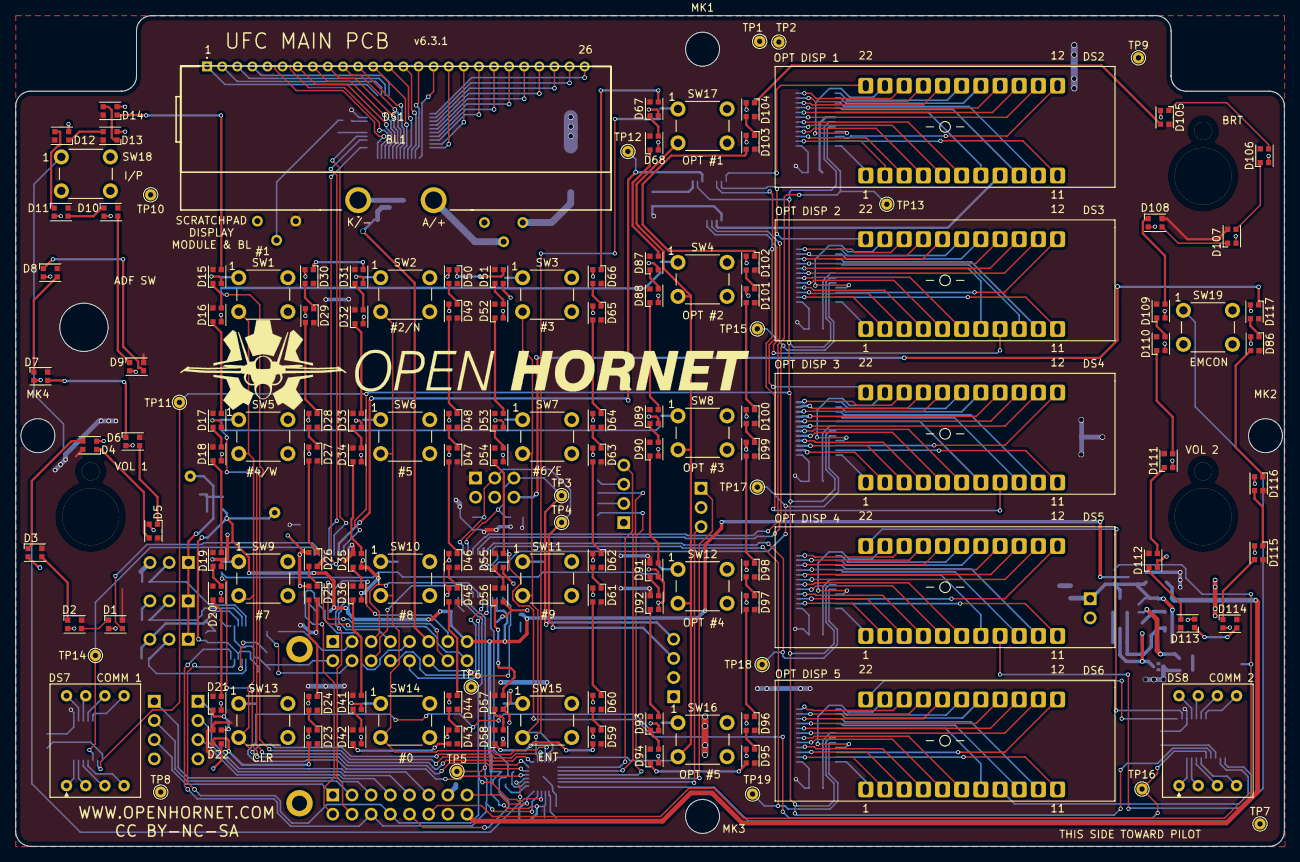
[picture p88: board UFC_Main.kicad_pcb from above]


Board: 2 copper layers, 168.0 x 110.0 mm, 257 parts (105 on the bottom side), 353 nets.

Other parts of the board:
LOGO: LOGO; LOGO_OH_Text_Large

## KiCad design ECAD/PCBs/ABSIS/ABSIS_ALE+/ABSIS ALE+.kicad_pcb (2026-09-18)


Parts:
C1, C2, C3: 100nF; C_0402_1005Metric; Manufacturer PN CL05B104KB54PNC; LCSC C307331
C4, C5, C6: 22uF; C_0805_2012Metric; Manufacturer PN CL21A226MAQNNNE; LCSC C45783
C7: 1pF; C_0402_1005Metric; Manufacturer PN 0402CG1R0C500NT; LCSC C1550
C8: 10uF; C_0603_1608Metric; Manufacturer PN CL10A106MA8NRNC; LCSC C96446
D1: CDSOT23-SM712; Manufacturer PN CDSOT23-SM712; LCSC C404012
D2: S3MB; SS34; Manufacturer PN S3MB; LCSC C47524
D3: SMBJ12A; Manufacturer PN SMBJ12A; LCSC C151251
F1: 1812L300_24SLER; Manufacturer PN 1812L300/24SLER; LCSC C1512049
H1, H2, H3, H4: MountingHole; MountingHole_3.2mm_M3_DIN965
IC1: THVD1410DR; Manufacturer PN THVD1410DR; LCSC C2671345
IC2: TPS563300DRLR; Manufacturer PN TPS563300DRLR; LCSC C5219249
J1, J2: 39-28-8060; Manufacturer PN 39288060; LCSC C505058
J3, J5: PZ254V-11-02P; PinHeader_1x02_P2.54mm_Vertical; Manufacturer PN PZ254V-11-02P; LCSC C492401
J4, J12: PZ254V-11-03P; PinHeader_1x03_P2.54mm_Vertical; Manufacturer PN PZ254V-11-03P; LCSC C2937625
J6, J7: B2B-XH-A(LF)(SN); B2B-XH-A__LF__SN_; Manufacturer PN B2B-XH-A(LF)(SN); LCSC C158012
J8, J9: B-2100S12P-B110; PinHeader_2x06_P2.54mm_Vertical; Manufacturer PN B-2100S12P-B110; LCSC C124388
J11: 2.54-2*2P; PinHeader_2x02_P2.54mm_Vertical; Manufacturer PN 2.54-2*2P; LCSC C66690
JP1: SolderJumper_2_Open; SolderJumper-2_P1.3mm_Open_RoundedPad1.0x1.5mm
L1: 5.6uH; SRP6060FA-5R6M; Manufacturer PN SRP6060FA-5R6M; LCSC C1332221
Q1, Q3: AO3400A; Manufacturer PN AO3400A; LCSC C20917
Q2, Q4: IRLML6402TRPBF; Manufacturer PN IRLML6402TRPBF; LCSC C2593
R1, R4, R5, R6, R7, R8, R9, R10, R11: 10kΩ; R_0402_1005Metric; Manufacturer PN 0402WGF1002TCE; LCSC C25744
R2, R3: 10Ω; R_0805_2012Metric; Manufacturer PN CRCW080510R0FKEAHP; LCSC C844598
R12: 80.6kΩ; R_0402_1005Metric; Manufacturer PN 0402WGF8062TCE; LCSC C25921
XU2: PRO_MICRO_5V/16MHZ; PRO_MICRO_5V16MHZ; Manufacturer PN PRO_MICRO_5V/16MHZ

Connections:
+3.3V_SUPPLY: J1.3, J2.3, J11.2
+5V: C1.2, IC1.8 (VCC), J8.9, J8.11, J9.9, J9.11, R1.2, XU2.21 (VCC)
+5V_SUPPLY: J1.2, J2.2, J4.3, J11.3, J12.3
+7.3V: C4.1, C5.1, C6.1, C7.1, D2.2 (A), L1.2, R12.2
+12V_SUPPLY: D3.1 (K), F1.1, J1.1, J2.1, J4.1, J11.1, J12.1
/A0: J9.7, XU2.17 (A0/18)
/A1: J9.5, XU2.18 (A1/19)
/A2: J9.3, XU2.19 (A2/20)
/A3: J9.1, XU2.20 (A3/21)
/BUS_A: D1.1, J1.4, J2.4, R3.1
/BUS_B: D1.2, J1.5, J2.5, R2.1
/CH1_CTRL: J3.1, R7.1
/CH1_OUT: J6.1, Q2.3
/CH1_V+: J12.2, Q2.2, R5.2
/CH2_CTRL: J5.1, R10.1
/CH2_OUT: J7.1, Q4.3
/CH2_V+: J4.2, Q4.2, R8.2
/D4_A6: J9.6, XU2.7 (A6/4)
/D5: IC1.2 (~RE), IC1.3 (DE), R4.2, XU2.8 (5)
/D6_A7: J8.2, XU2.9 (A7/6)
/D7: J8.4, XU2.10 (7)
/D8_A8: J8.6, XU2.11 (A8/8)
/D9_A9: J8.8, XU2.12 (A9/9)
/D10_A10: J8.7, XU2.13 (A10/10)
/D14_MISO: J8.3, XU2.15 (14/MISO)
/D15_SCK: J8.1, XU2.16 (15/SCLK)
/D16_MOSI: J8.5, XU2.14 (16/MOSI)
/FB(TPS): C7.2, IC2.8 (FB), R11.2, R12.1
/RST: JP1.2 (B), XU2.22 (RST)
/RX1_D0: IC1.1 (R), R1.1, XU2.2 (0/RX)
/SCL_D3: J5.2, J9.4, XU2.6 (SCL/3)
/SDA_D2: J3.2, J9.2, XU2.5 (SDA/2)
/TX0_D1: IC1.4 (D), XU2.1 (1/TX)
GND: C1.1, C2.1, C4.2, C5.2, C6.2, C8.1, D1.3, D3.2 (A), IC1.5 (GND), IC2.4 (GND), J1.6, J2.6, J6.2, J7.2, J8.10, J8.12, J9.8, J9.10, J9.12, J11.4, JP1.1 (A), Q1.2 (S), Q3.2 (S), R4.1, R11.1, XU2.3 (GND), XU2.4 (GND), XU2.23 (GND)
unnamed: D2.1 (K), XU2.24 (RAW)
unnamed: IC1.6 (A), R3.2
unnamed: IC1.7 (B), R2.2
unnamed: C3.2, IC2.6 (BST)
unnamed: C3.1, IC2.5 (SW), L1.1
unnamed: C2.2, C8.2, F1.2, IC2.3 (VIN)
unnamed: Q1.3 (D), R6.1
unnamed: Q1.1 (G), R7.2
unnamed: Q2.1, R5.1, R6.2
unnamed: Q3.3 (D), R9.1
unnamed: Q3.1 (G), R10.2
unnamed: Q4.1, R8.1, R9.2

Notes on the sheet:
(VREF = 0.8V)
1) RS485 BUS TERMINATION: ON THE LAST SLAVE DEVICE OF AN RS485 BUS DO NOT INSTALL J2 (BUS OUT) MOLEX CONNECTOR. INSTEAD, INSTALL A 120 Ω THRU-HOLE RESISTOR ACROSS PINS 4 AND 5 OF J2 (BUS OUT). 2) ABSIS RS485 BUS SPECIFICATION 2.1) BUS IS HALF DUPLEX; TRANSMIT OR RECEIVE ONLY AT ANY GIVEN TIME. 2.2)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
4) I/O CONNECTORS 4.1) J8 AND J9 ARE UNKEYED 2X6, 2.54 MM GENERAL-PURPOSE I/O HEADERS. VERIFY PIN 1 ORIENTATION BEFORE CONNECTING HARNESS OR TEST EQUIPMENT. 4.2) J8 AND J9 I/O SIGNALS CONNECT DIRECTLY TO PROMICRO I/O PINS. EXT SIGNAL VOLTAGE SHALL NOT EXCEED THE LOGIC SUPPLY VOLTAGE OF THE INSTALLE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
NOTES: (UNLESS OTHERWISE SPECIFIED)
RELAY CHANNEL 2
MOUNT HOLES
RS485 BUS
RELAY CHANNEL 1
I/O
12V POWER CONDITIONING (12V -> 7.3V)
ABSIS BUS
SPARKFUN PRO-MICRO, 5V



Board: 4 copper layers, 36.0 x 69.0 mm, 49 parts (37 on the bottom side), 46 nets.

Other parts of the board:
LOGO1: LOGO; LOGO_OH_NoText_Small

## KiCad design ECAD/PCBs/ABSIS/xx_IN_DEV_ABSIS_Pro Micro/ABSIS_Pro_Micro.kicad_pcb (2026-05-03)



Board: 4 copper layers, 17.8 x 41.0 mm, 7 parts (3 on the bottom side), 5 nets, no tracks yet.

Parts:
CN1, CN2: M12PTH; PinHeader_1x12_P2.54mm_Vertical
CN3: PinHeader_1x06_P2.00mm_Vertical
F1: FIDUCIALUFIDUCIAL; Fiducial_0.5mm_Mask1.5mm
J2: 2171790001; 2171790001_MOL
JP3: FIDUCIALUFIDUCIAL; Fiducial_0.5mm_Mask1.5mm
LOGO: LOGO; LOGO_OH_NoText_Small

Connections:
+5V: CN2.9, CN3.1
/DN: J2.A7 (DN1), J2.B7 (DN2)
/DP: J2.A6 (DP1), J2.B6 (DP2)
/vBUS: J2.A4/B9 (VBUS), J2.B4/A9 (VBUS)
GND: CN1.3, CN1.4, CN2.11, CN3.6, J2.A1/B12 (GND), J2.B1/A12 (GND)

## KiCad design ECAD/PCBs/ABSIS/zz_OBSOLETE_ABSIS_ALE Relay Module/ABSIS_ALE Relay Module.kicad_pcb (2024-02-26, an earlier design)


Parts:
J1: PinSocket_Long_2x16; PinSocket_2x16_P2.54mm_Vertical; Manufacturer PN SSQ-116-03-G-D
J2: PinSocket_Long_1x06; PinSocket_1x06_P2.54mm_Vertical; Manufacturer PN SSQ-106-03-G-S
J3, J4: JST_PH_01x02; JST_PH_B2B-PH-K_1x02_P2.00mm_Vertical; Manufacturer PN B2B-PH-K-S(LF)(SN)
JP1, JP2, JP3, JP4: PinHeader_1x03; PinHeader_1x03_P2.54mm_Vertical; Manufacturer PN PH1-03-UA
LOGO1: LOGO; LOGO_OH_NoText_Small
LOGO2: LOGO; LOGO_OH_NoText_Medium
MH1, MH2, MH3, MH4: M3 / 3.2mm; MountingHole_3.2mm_M3_DIN965
Q1, Q4: IRFB3206PBF; TO-220-3_Vertical; Manufacturer PN IRFB3206PBF; LCSC C2642
Q2, Q3: IRLML6402TRPBF; SOT-23; Manufacturer PN IRLML6402TRPBF; LCSC C2593
R1, R2, R3, R4, R5, R6: 10k; R_0603_1608Metric; Manufacturer PN 0603WAF1002T5E; LCSC C25804

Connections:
/+3.3V_SUPPLY: J1.2
/+5V_SUPPLY: J1.3, JP1.3 (B), JP3.3 (B)
/+12V_SUPPLY: J1.1, JP1.1 (A), JP3.1 (A)
/A0: J1.13
/A1: J1.11
/A2: J1.9
/A3: J1.7
/CH1_CTRL: JP2.2 (C), R3.1
/CH1_OUT: J3.1, Q2.3 (D)
/CH1_V+: JP1.2 (C), Q2.2 (S), R2.2
/CH2_CTRL: JP4.2 (C), R6.1
/CH2_OUT: J4.1, Q3.3 (D)
/CH2_V+: JP3.2 (C), Q3.2 (S), R4.2
/D2: J1.8, JP2.1 (A), JP4.1 (A)
/D4_A6: J1.12
/D7: J1.24
/D14: J1.23
/D15: J1.21
/D16: J1.25
/~D3: J1.10, JP2.3 (B), JP4.3 (B)
/~D6_A7: J1.22
/~D8_A6: J1.26
/~D9_A9: J1.28
/~D10_A10: J1.27
GND: J1.4, J1.14, J1.16, J1.18, J1.30, J1.32, J2.1, J2.2, J2.3, J2.4, J2.5, J2.6, J3.2, J4.2, Q1.3 (S), Q4.3 (S)
unnamed: Q1.2 (D), R1.2
unnamed: Q1.1 (G), R3.2
unnamed: Q2.1 (G), R1.1, R2.1
unnamed: Q3.1 (G), R4.1, R5.1
unnamed: Q4.2 (D), R5.2
unnamed: Q4.1 (G), R6.2

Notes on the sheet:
RELAY CHANNEL #1
CONNECTORS
JUMPERS
PWR FLAGS
LOGOS/SILKSCREENS
MOUNTING HOLES
RELAY CHANNEL #2
+5V
1) THIS IS A 4-LAYER PCB FOR POWER TRANSMISSION CAPABILITIES.
NOTES: (UNLESS OTHERWISE SPECIFIED)



Board: 2 copper layers, 36.0 x 51.0 mm, 24 parts (9 on the bottom side), 17 nets.

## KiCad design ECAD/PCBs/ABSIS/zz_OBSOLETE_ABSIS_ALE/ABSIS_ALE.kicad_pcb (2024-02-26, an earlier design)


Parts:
C1: 0.1uF; C_0805_2012Metric; Manufacturer PN CC0805KRX7R9BB104; LCSC C49678
D1: 1N5819WS; D_SOD-323_HandSoldering; Manufacturer PN 1N5819WS; LCSC C191023
J1, J2: Mini-Fit Jr. 2x03; Molex_Mini-Fit_Jr_5566-06A2_2x03_P4.20mm_Vertical; Manufacturer PN 39-29-9062; LCSC C505177
J3, J4: PinHeader_2x06; PinHeader_2x06_P2.54mm_Vertical; Manufacturer PN B-2100S12P-B110; LCSC C124388
J5: PinHeader_1x06; PinHeader_1x06_P2.54mm_Vertical; Manufacturer PN PH1-06-UA; LCSC C37208
J6: PinHeader_2x02; PinHeader_2x02_P2.54mm_Vertical; Manufacturer PN C66690; LCSC C66690
LOGO1, LOGO2: LOGO; LOGO_OH_NoText_Small
MH1, MH2, MH3, MH4: M3 / 3.2mm; MountingHole_3.2mm_M3_DIN965
RST1: RST; SolderJumper-2_P1.3mm_Open_RoundedPad1.0x1.5mm
U1: MAX487EESA+T; SOIC-8_3.9x4.9mm_P1.27mm; Manufacturer PN MAX487EESA+T; LCSC C116539
XU1: ProMicro_5V/16Hz; DIP-24_W15.24mm_Socket; Manufacturer PN Pro Micro - 5V/16MHz

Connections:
+5V: C1.1, J3.9, J3.11, J4.9, J4.11, U1.8 (VCC), XU1.21 (VCC)
/+3.3V_SUPPLY: J1.3, J2.3, J6.2
/+5V_SUPPLY: J1.2, J2.2, J6.3
/+12V_SUPPLY: D1.2 (A), J1.1, J2.1, J6.1
/A0: J3.7, XU1.17 (A0)
/A1: J3.5, XU1.18 (A1)
/A2: J3.3, XU1.19 (A2)
/A3: J3.1, XU1.20 (A3)
/BUS-A: J1.4, J2.4, U1.6 (A)
/BUS-B: J1.5, J2.5, U1.7 (B)
/D4_A6: J3.6, XU1.7 (D4/A6)
/D7: J4.4, XU1.10 (D7)
/D8_A8: J4.6, XU1.11 (D8/A8)
/D14_MISO: J4.3, XU1.15 (D14/MISO)
/D15_SCK: J4.1, XU1.16 (D15/SCK)
/D16_MOSI: J4.5, XU1.14 (D16/MOSI)
/RST: RST1.2 (B), XU1.22 (RST)
/RX1_D0: U1.1 (RO), XU1.2 (RX1/D0)
/SDA_D2: J3.2, XU1.5 (SDA/D2)
/TX0_D1: U1.4 (DI), XU1.1 (TX0/D1)
/~D5: U1.2 (~RE), U1.3 (DE), XU1.8 (~D5)
/~D6_A7: J4.2, XU1.9 (~D6/A7)
/~D9_A9: J4.8, XU1.12 (~D9/A9)
/~D10_A10: J4.7, XU1.13 (~D10/A10)
/~SCL_D3: J3.4, XU1.6 (~SCL/D3)
GND: C1.2, J1.6, J2.6, J3.8, J3.10, J3.12, J4.10, J4.12, J5.1, J5.2, J5.3, J5.4, J5.5, J5.6, J6.4, RST1.1 (A), U1.5 (GND), XU1.3 (GND), XU1.4 (GND), XU1.23 (GND)
unnamed: D1.1 (K), XU1.24 (RAW)

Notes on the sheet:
SPARKFUN PRO MICRO 5V/16Hz
LOGOS/SILKSCREENS
CONNECT TO PC VIA USB
ABSIS BUS CONNECTORS
PWR FLAGS
MOUNTING HOLES
ABSIS_ALE I/O BREAKOUT
"RESET" JUMP PADS
RS485 BUS CONTROLLER
NOTES: (UNLESS OTHERWISE SPECIFIED)
1) RS485 BUS TERMINATION: DO NOT INSTALL J2 (BUS OUT) CONNECTOR AND ADD A 120Ω THRU-HOLE RESISTOR ACROSS PINS 4&5 OF J2(BUS OUT) ON LAST ABSIS_ALE OF RS485 BUS. 2) FOR ARDUINO PRO MICRO PROGRAMMING VIA USB: MAY BE PROGRAMMED IN-CIRCUIT. 3) THE RAW POWER PIN ON THE PRO MICRO AND +12V_SUPPLY ARE TIED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
NOTE: IN ARDUINO CODE: USE "SERIAL" FOR USB; "SERIAL1" FOR TX/RX PINS.



Board: 2 copper layers, 36.0 x 51.0 mm, 17 parts (5 on the bottom side), 27 nets.

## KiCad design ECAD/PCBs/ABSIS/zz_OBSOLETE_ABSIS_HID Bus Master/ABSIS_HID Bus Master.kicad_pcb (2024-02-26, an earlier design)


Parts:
C1: 0.1uF; C_0805_2012Metric; Manufacturer PN CC0805KRX7R9BB104; LCSC C49678
D1: 1N5819WS; D_SOD-323_HandSoldering; Manufacturer PN 1N5819WS; LCSC C191023
J1: Molex_Mini-Fit_Jr._2x04; Molex_Mini-Fit_Jr_5566-08A2_2x04_P4.20mm_Vertical; Manufacturer PN 39-29-9084; LCSC C587470
J2: Mini-Fit Jr. 2x03; Molex_Mini-Fit_Jr_5566-06A2_2x03_P4.20mm_Vertical; Manufacturer PN 39-29-9062; LCSC C505177
LOGO1: LOGO; LOGO_OH_NoText_Large
LOGO2: LOGO; LOGO_OH_Text_Small
LOGO3: LOGO; LOGO_CC-BY-NC-SA_Half_Small
MH1, MH2, MH3, MH4: 6x32 / 4mm; MountingHole_3.2mm_M3_DIN965
R1: 120; R_0805_2012Metric_Pad1.15x1.40mm_HandSolder; Manufacturer PN 0805W8F1200T5E; LCSC C17437
TP1, TP2, TP3, TP4, TP5, TP6: TestPoint; TestPoint_THTPad_D1.5mm_Drill0.7mm
U1: MAX487EESA+T; SOIC-8_3.9x4.9mm_P1.27mm; Manufacturer PN MAX487EESA+T; LCSC C116539
XU1: ProMicro_5V/16Hz; DIP-24_W15.24mm_Socket; Manufacturer PN Pro Micro - 5V/16MHz

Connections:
+5V: C1.1, U1.8 (VCC); also elsewhere on the board
/+3.3V_SUPPLY: J1.5, J2.3, TP3.1
/+5V_SUPPLY: J1.6, J1.7, J2.2, TP2.1
/+12V_SUPPLY: D1.2 (A), J1.3, J1.4, J1.8, J2.1, TP1.1
/BUS1-A: J2.4, R1.1, TP6.1, U1.6 (A)
/BUS1-B: J2.5, R1.2, TP5.1, U1.7 (B)
/RX1_D0: U1.1 (RO); also elsewhere on the board
/TX0_D1: U1.4 (DI); also elsewhere on the board
/~D5: U1.2 (~RE), U1.3 (DE); also elsewhere on the board
GND: C1.2, J1.1, J1.2, J2.6, TP4.1, U1.5 (GND); also elsewhere on the board
unnamed 11: D1.1 (K); also elsewhere on the board

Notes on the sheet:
CONNECTORS
SPARKFUN PRO MICRO 5V/16Hz
MOUNTING HOLES
PWR FLAGS
LOGOS
TEST POINTS
ABSIS BUS #1
CONNECT TO PC VIA USB
NOTES: (UNLESS OTHERWISE SPECIFIED)
1) PRO MICRO GETS ADDED VIA 24-PIN 15.24mm WIDE DIP SOCKET. 2) FOR ARDUINO PRO MICRO PROGRAMMING VIA USB: MAY BE PROGRAMMED IN-CIRCUIT. USE "SERIAL" FOR REFERING TO USB COMMUNICATIONS; "SERIAL1" FOR TX/RX RS485 PINS. 3) THE RAW POWER PIN ON THE PRO MICRO AND +12V_SUPPLY ARE TIED TOGETHER. IF THE PR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


Board: 2 copper layers, 90.8 x 53.3 mm, 20 parts (1 on the bottom side), 11 nets.

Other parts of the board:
U0: ProMicro_5V/16Hz; DIP-24_W15.24mm_Socket

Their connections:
+5V: U0.21 (VCC); also elsewhere on the board
/RX1_D0: U0.2 (RX1/D0); also elsewhere on the board
/TX0_D1: U0.1 (TX0/D1); also elsewhere on the board
/~D5: U0.8 (~D5); also elsewhere on the board
GND: U0.3 (GND), U0.4 (GND), U0.23 (GND); also elsewhere on the board
unnamed 11: U0.24 (RAW); also elsewhere on the board

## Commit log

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2019-11-24 Integrating into baseline for now....
    Still WIP, but integrating into baseline to reprioritize back to fixing obsolence issue with UFC (MAX6953)
    [.55 SQ Indicator.sldasm, 100SPxT8B13M1QEH - SWITCH, TOGGLE, SPDT, 18mm BAT.SLDASM, 7598A71 - TAPE, LIGHT DUTY, DOUBLE SIDED, FOAM.sldprt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]
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2019-11-26 Finalized Ejection Seat
    All exploded views for drawing generated, couple issues resolved in design. Seat should be considered under a design freeze.
    [100SPxT8B13M1QEH - SWITCH, TOGGLE, SPDT, 18mm BAT.SLDASM, Aft Seat Back Support.sldprt, Lower Parachute Container Base.sldprt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]
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2019-12-13 fixed mastter mode push button ground conection published updated gerber files. removed bak file
    [MasterModePushbutton.kicad_pcb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]
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2019-12-14 renamed files to remove spaces removed back files fixed relative paths for projects
    [.55_SQ_INDICATOR_PCB_DEFINITION.SLDDRW, .55_SQ_Indicator_PCB.DXF, ABSIS_BOM.xlsx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]
2019-12-14 UFC3 MCAD WIP
    - Fixed several interferences in UFC panel.
    - Generated PCB Component Requirements Drawing
    ## TODO
    - Replace existing pots with new (non-EOL) pot
    - Modify knobs to be compatible with new pot.
    [91251A081.sldprt, AP Switch Module.sldasm, FWD HUD Box.sldprt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]
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2019-12-16 Drawing WIP
    Continuing work on drawing, also added relief engraving to EMERG JETT button IAW new details. May redesign button assembly to be more robust.
    [.55 SQ Indicator.sldasm, 100SPxT8B13M1QEH - SWITCH, TOGGLE, SPDT, 18mm BAT.SLDASM, EMERG JETT Button.sldprt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]
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2019-12-16 Updated KY58 Panel
    - Replaced obsolete pot with P0915N-FC20BR10K pot.
    - Added 92311A189 8-32 set screw to appropriate knobs.
    - Added 92311A105 4-40 set screw to appropriate knobs.
    [51M30-01-2-03N.SLDASM, 58ZZ3040-5_ASM.sldasm, 92311A105 - SCREW, SET, 4-40 X .1875, CUP POINT, HEX DRIVE, 18-8.SLDPRT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]
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2019-12-19 FIxed EMERG JETT switch clearance hole.
    Increased hole diameter from .250 to .266 clearance hole. Fixes #137.
    [EMERG JETT Brkt.sldprt]
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2019-12-20 Rudder pedal adjust lever integrated.
    Added rudder pedal adjust lever and knob, snap acting switch, spring tensioner, mechanical stops and all associated HW.
    Closes issue #6. Thanks @crosshairs2230 and @Luft for all your help.
    [100SPxT8B13M1QEH - SWITCH, TOGGLE, SPDT, 18mm BAT.SLDASM, 57155K371 - BEARING, SEALED, .1563 ID X .3125 OD X .125 THK, R155-2Z.SLDPRT, 7779K520 - SWITCH, MINIA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]
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2019-12-24 Replaced friction axis pot
    removed obsolete pot, added new pot.
    TODO: Still need to replace ANT ELEV pot.
    [DISPENSE Switch.sldasm, Friction Arm Potentiometer Lever.sldprt, Inboard Autothrottle Linkage Rod.sldasm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]
2019-12-25 UIP DWG Corrections
    Combined FN 69 & 70.
    Added callouts for FN 69 on SHT 8 & 9
    Clarified all FN 64 callouts on SHT 4. Asymmetry is intention for mounting front panel, and the balance of the 14 inserts go into the front row of FN 10 holes.
    Closes #145 and closes #147.
    [100SPxT8B13M1QEH - SWITCH, TOGGLE, SPDT, 18mm BAT.SLDASM, HUD Panel Assembly.sldasm, HUD Panel.sldasm]
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2019-12-25 Revised L&R EWI Drawings
    Updated finish note.
    Fixed small model error on left EWI.
    No STL updates required.
    [EWI Chassis - Right.sldprt, EWI Legend Plate - Right.sldprt, EWI Light Channels - Right.sldprt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]
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2019-12-25 Revised HUD Panel
    UPDATED PL
    ADDED SET SCREWS
    UPDATED KNOBS AND BACKPLATE
    REPLACED OBSOLETE POT
    ADDED FINISH SPECIFICATION
    [100SPxT8B13M1QEH - SWITCH, TOGGLE, SPDT, 18mm BAT.SLDASM, 92311A189 - SCREW, SET, 8-32 X .1875, CUP POINT, HEX DRIVE, 18-8.SLDPRT, HUD Panel Assembly.sldasm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]
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2019-12-28 Updated UIP Mount Shelf
    Added missing 2-56 CSK holes for electronics standoffs to UIP Mount Shelf for LIP.
    #134
    [Upper Instrument Panel Mount.sldprt]
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2019-12-28 regerated stl issue 148
    # Description
    Regenerated and generated .stl files for:
    All DDI Knobs (Revised for shaft and setscrews)
    Spin Panel HMD Knobs (Revised for shaft and setscrews)
    All HUD Panel Knobs (Revised for shaft and setscrews)
    HUD Panel backplate (Revised for new potentiometer)
    HUD BIT Box (Revised to remove UFC Controller PCB and associated HW)
    All UFC Panel Primary Module Parts (Integrated UFCv3)
    Addresses #148
    ## Type of change
    Please delete options that are not relevant.
    - [ x ] New MCAD (new Mechanical Model)
    - [ x ] Change MCAD (fixed issue with existing MCAD model)
    - [ x ] Breaking change (fix or feature that would cause existing functionality to not work as expe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
    [OH1A3A-18 DDI MS21382-0XBX (MODIFIED).stl, OH1A3A-19 DDI MS21382-0XNX (MODIFIED).stl, OH1A7A-14 KNOB, KORRY, RD239-A1G2.stl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]
2019-12-29 Corrects individual and nested DXFs containing UIP_LEFT_INBOARD_LONGERON, UIP_RIGHT_INBOARD_LONGERON where glareshield mount holes were of an incorrect diameter.
    [OH1A-103_UIP_LEFT_INBOARD_LONGERON_.75_MDF.dxf, OH1A-104_UIP_RIGHT_INBOARD_LONGERON_.75_MDF.dxf, OH1A-1_SH1_.75_MDF.DXF]
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2020-01-04 Regenerated UFC stl’s
    Regenerated UFC stl’s who where broken and brought the rest up to nomenclature.
    [OH1A8A1A-10 - UFC Panel Support Structure.STL, OH1A8A1A-10 UFC PANEL SUPPORT STRUCTURE.stl, OH1A8A1A-11 - UFC Legend Plate.STL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]
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2020-01-17 Moved SIM Master switch to SIM PWR Panel
    Moved SIM Master switch to SIM PWR Panel on Left Console. #166
    Populated SIM PWR Panel.
    Added conceptual replacement bats for SxAL switches (Still need to thread them. WIP.) #167
    [Conical Locking Bat.sldprt, GND PWR Panel.SLDASM, Round Locking Bat.sldprt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]
2020-01-17 Updated Left Console Panels with correct bats
    Updated Left Console Panels with correct bats on locking switches. #135
    [COMM Panel.sldasm, EXT LT Panel.SLDASM, FIRE TEST Panel.sldasm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]
2020-01-17 Updated R Console Panels
    Updated locking toggles to correct bats throughout right console. #136
    Removed master mode from SIM CNTL panel. (Now located on SIM PWR)
    Changed SLOW legend to REAL for TIME position on SIM CNTL panel. Closes #166
    [AV COOL Panel.sldasm, Canopy Control.sldasm, DEFOG Panel.sldasm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]
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2020-01-18 LIP exploded views complete. Beginning drawings.
    Completed LIP exploded views.
    Fixed RWR indicators.
    Added correct bats to DISP-EMC locking toggles.
    [.55 SQ Indicator Legend.sldprt, .55 SQ Indicator.sldasm, 100SPxT8B13M1QEH - SWITCH, TOGGLE, SPDT, 18mm BAT.SLDASM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]
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2020-04-21 Redesign: BATT Gauge for Dual Nano Servos
    Redesigned BATT Gauge for dual nano servos from VID28, using a 1:1 gear ratio.
    Closes #16.
    [1.5 Indicator Rear Bezel Spacer.sldprt, Battery Voltage Indicator.SLDASM, Battery Voltage Servo Mount.sldprt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]
2020-04-21 Fixed BATT Gauge Redesign
    Fixed slight misalignment on the #2 pointer.
    Added material metadata to new parts.
    [Battery Voltage Indicator.SLDASM, Battery Voltage Servo Mount.sldprt, GEAR, SPUR, 18T, 20PD X .417 OD X 5-64BD X .125 THK.sldprt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]
2020-04-21 HYD PRESS Gauge Redesign
    Redesigned HYD PRESS Gauge to use dual nano servos with a 2:1 gear ratio, instead of VID28 microstepper.
    Closes #15.
    [Battery Voltage Servo Mount.sldprt, HYD PRESS GAUGE DRIVE GEAR.sldprt, HYD PRESS SERVO MOUNT.sldprt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]
2020-04-22 Updated Lower ECS Vent on LIP
    Updated lower ECS vent to remove interference with stick gimbal and add additional detail.
    [Lower ECS Vent.sldprt]
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2020-04-27 Stick Design Release Candidate
    Finished Trim Device. Added missing hardware.
    Closes #17. Yay! OpenHornet has a Hornet stick now!
    [59935K73 - Ball Joint Rod End.sldasm, 8mm Smooth to Threaded Shaft Coupler.sldasm, 91100A120 - WASHER, M3 X 9 OD, 18-8.SLDPRT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]
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2020-05-04 LIP Assembly Cleanup
    No actual/form/fit/function changes other than cleaning up some minor issues with the actual assembly file. Users should be able to view it in eDrawings and Fusion better now.
    [100SPxT8B13M1QEH - SWITCH, TOGGLE, SPDT, 18mm BAT.SLDASM, 819368020823 - Delrin Mini V Wheel.SLDASM, AMPCD-HDG-CRS Module.sldasm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]
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2020-05-05 Updated Select JETT Panel
    Replaced Anti-Skid switch with S1A1 locking toggle with rounded bat.
    [Select JETT Button.sldasm, Select JETT KNOB ASSY.sldasm]
2020-05-06 Updated JETT Select Panel
    Updated JETT Select button to be fixed vertical while knob rotates around the button.
    [100SPxT8B13M1QEH - SWITCH, TOGGLE, SPDT, 18mm BAT.SLDASM, 92196A060 - SHCS, 0-80 X 1.00, 18-8.SLDPRT, Select JETT Backplate.sldprt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]
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2020-05-07 Updated AMPCD module
    Updated pot clearance hole and mating face thickness.
    Closes #202
    [100SPxT8B13M1QEH - SWITCH, TOGGLE, SPDT, 18mm BAT.SLDASM, AMPCD Bezel.sldprt, AMPCD MS21382-0XNX (Modified).sldprt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]
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2020-05-29 AMPCD Mounting Fixes
    Added 5x 8-32 inserts to AMPCD module.
    Added #8 clearance hole to center mounting hole of AMPCD Base Support.
    Closes #214
    [100SPxT8B13M1QEH - SWITCH, TOGGLE, SPDT, 18mm BAT.SLDASM, AMPCD - CRS-HDG Base Support.sldprt, C_0805_2012Metric.sldasm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]
2020-05-30 Fixed SARI Knob
    Increased depth of legend on knob to 0.3mm.
    Closes #208
    [RWR Bezel.sldasm, SARI Bezel.sldasm, SARI Knob.sldprt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]
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2020-05-31 Updated L/R EWI Module
    Updated Chassis and Light channels to clearance PCB connectors.
    Closes #171 & #172
    [EWI Chassis - Right.sldprt, EWI Light Channels - Left.sldprt, MINIUSB - MEASURED.SLDASM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]
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2020-06-05 Moved the pro micro up so that it does not interfere with the speedbreak switch
    [THROTTLE_INNER_GRIP.kicad_pcb, THROTTLE_INNER_GRIP.sch]
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2020-06-07 Updated size of throttle board so that it does not interfere with keyhole hat switch
    [THROTTLE_INNER_GRIP.kicad_pcb]
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2020-06-17 Fixed eccentric nuts
    Added new counterbore for eccentric nuts. Doh.
    Closes #209
    [Rudder Pedal Gantry Interface Plate.sldprt]
2020-06-17 UIP STL's Created with Correct IPS Scale
    All files as per Git Issue #205 re-created with document measurement unit matching settings (Inch, Pound, Second)
    All STL's with inconsistant file name capitalisation corrected to Title Case for contuniuty across entire UIP manufacturing folder.
    All STL's with inconsistant use of spaces and "-" in file name corrected for continuity across the entire UIP manufacturing folder.
    [OH1A -108 - UPPER UIP FACE MOUNT, RIGHT.stl, OH1A -108 UPPER UIP FACE MOUNT, RIGHT.stl, OH1A -109 UIP DISPLAY PRESSURE FOOT.stl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]
2020-06-17 Revert "UIP STL's Created with Correct IPS Scale"
    This reverts commit 25a9fd49343951a9d7ff58f7adcf46e554f6531e.
    [OH1A -107 - UPPER UIP FACE MOUNT, LEFT.stl, OH1A -108 - UPPER UIP FACE MOUNT, RIGHT.stl, OH1A -108 UPPER UIP FACE MOUNT, RIGHT.stl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]
2020-06-17 UIP STL's Created with Correct Scale & File Name Continuity Cleanup
    All STL files as per Git Issue #205 re-generated with correct scaling.
    3 duplicate STL files with incorrect scaling removed.
    All STL's with inconsistent file name capitalization corrected to Title Case for continuity across the entire UIP manufacturing folder.
    All STL's with inconsistent use of spaces and "-" in file name corrected for continuity across the entire UIP manufacturing folder.
    [OH1A -108 UPPER UIP FACE MOUNT, RIGHT.stl, OH1A -109 UIP DISPLAY PRESSURE FOOT.stl, OH1A -112 MFD LOWER SUPPORT C.stl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]
2020-06-17 H-I Right Inboard Spacer Bug Fix
    As per Github Git #194
    Fixing female connector extrude cut depth to .25" in line with other inboard spacers' female connectors.
    [H-I Right Inboard Spacer.sldprt]
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2020-06-24 Right AUX Spacer Screw Cutout
    Addition of an extrude-cut in the topside of the Right Console - Right Aux Spacer to allow the inboard ELEC panel sandwiching screw to seat correctly without intefering with the spacer.
    [Right Console - Right AUX Spacer.sldprt]
2020-06-28 Left Inboard Footwell Wall Pocket
    As per feedback, the additional cutout in the AMPCD - CRS-HDG Base Support has been removed.
    A pocket within the Left Inboard Footwell Wall has been created to produce the same desired cable clearance whilst not creating any thin walls inside other parts.
    [AMPCD - CRS-HDG Base Support.sldprt, Left Inboard Footwell Wall.sldprt]
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2020-07-01 Fixed Rudder Pedal Gantry Interface Plate
    Reversed solenoid
    Fixed solenoid mounting screws (located to correct pattern and converted to slots for adjustability.
    Lengthened slots for mounting actuator arm
    Added retaining cover to solenoid.
    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
    [Rudder Pedal Gantry Interface Plate.sldprt, Solenoid Actuator Stop.sldprt]
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2020-08-02 Added Salute Button to Canopy Switch Box
    Added salute button and a spare user-defined pushbutton to the canopy switch box.
    Reinforced box to mount to top rail as well to help stiffen the box.
    Closes #231
    [Canopy Bracket.sldprt, Canopy Control.sldasm, PV2F24011 - SWITCH, PUSHBUTTON, FLAT, OFF-(ON).SLDPRT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]
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2020-10-29 Defog Lever Resize and Pot Replacement
    The Defog lever width has been reduced to remove the collision with its slot. The lever pot has also been replaced to the standard P0915N-FC15BR10K Pot.
    [AV COOL Panel.sldasm, DEFOG Lever.SLDPRT, G-H Right Outboard Spacer.sldprt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]
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2020-10-30 Deleted LIP STLs due to scaling issue.
    Will be reuploaded once corrected.
    [.55 SQ Indicator Actuator.STL, .55 SQ Indicator Base.STL, .55 SQ Indicator Bezel QTY 5.STL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]
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2020-11-06 Addresses Review Comments
    Remove Bus Enable jumpers.
    Change schematic BUS Connectors to match PCB order. (Cosmetic change.)
    Consider if fusing is required.
    Add power planes.
    - Changed front plane to 12V_Supply, since other voltages should have fairly low downstream amperage draws comparatively.
    Fix adjacent pin bridges. (Move out from direct bridge to "U" bridge.)
    Add silkscreen box to write reference designator on the PCB.
    [ABSIS_Bus_Master.kicad_pcb, ABSIS_Bus_Master.sch]
2020-11-06 Incorporated Review Comments
    - Fusing not required due to protected PSU output to bus.
    - Added 12V plane on back plane.
    Add silkscreen box to write reference designator on the PCB
    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
    [ABSIS_Nano.kicad_pcb, ABSIS_Nano.sch]
2020-11-06 Small tweaks
    Cosmetic tweaks to Master Schematic
    Updated Nano template with correct J1/J2 schematic pinouts.
    [ABSIS_Bus_Master.kicad_pcb, ABSIS_Bus_Master.sch]
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2020-11-08 Nano updated to minifit connectors.
    Its still not placing the SMD components correctly. Will fix.
    [ABSIS_Nano-B_Cu.gbr, ABSIS_Nano-B_Mask.gbr, ABSIS_Nano-B_SilkS.gbr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]
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2020-11-21 Reverted to original individual OPT displays
    Will panelize so that they can be built by JLCPCB
    [ufc_v4_opt.sch, ufc_v4_opt_layer2.kicad_pcb, ufc_v4_opt_layer3.kicad_pcb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]
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2020-11-25 New UFC Disp Panel
    Added missing OPT display to panel. Optimized panel, generated new manufacturing files. Next will generate light channel PCB layers for all displays and generate MCAD for displays and start updating UFC MCAD to define main UFC PCB requirements.
    [ufc_v4_displays_panel-B_CrtYd.gbr, ufc_v4_displays_panel-B_Cu.gbr, ufc_v4_displays_panel-B_Fab.gbr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]
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2021-01-05 Left Console PCB MCAD Directory Change
    Removed the .STEP.SLDPRT files and replaced them with clean .SLDPRT files.
    [100SPxT8B13M1QEH - SWITCH, TOGGLE, SPDT, 18mm BAT.SLDASM, 22-29-2031.SLDASM, 22-29-2041.SLDASM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]
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2021-01-30 Decreased Switch Tolerance
    Decreased the switch mount tolerance from .03" to .01"
    [Parking Brake Mechanism Body.sldprt, Parking Brake Mechanism End Cap.sldprt]
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2021-02-01 Add Line to MS21384-04DNN Knob
    Added the line to the MS21384-04DNN Knob. Recolored to the correct RGB color.
    [MS21384-04DNN v1.sldprt]
2021-02-02 SNSR Panel Backlight Prep
    .5" Swapped for .625" screws.
    Backlight PCB Part added
    Inboard and outboard spacers inlay cut to fit PCB.
    Changed HS-13Z Obsolete rotary for A12505RNZQ
    [100SPxT8B13M1QEH - SWITCH, TOGGLE, SPDT, 18mm BAT.SLDASM, 631H_SLASH_2 - SWITCH, TOGGLE, ON-OFF, STD BAT.SLDASM, DSOS-0416-12D.SLDASM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]
2021-02-02 Update main UFC board, to send all segment signals to SCRATCHPAD, COMM1 and COMM2. this will make the software simpler Update main UFC board, POT mounting holes are now first class citizens. Update m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
    [UFCconnections.xlsx, ufc_v4_main.kicad_pcb, ufc_v4_main.sch]
2021-02-02 INTR LT Panel Backlight Prep
    -Added: Backlight PCB Part
    -Changed: .5" screws to .625"
    - Added: PCB Clearance cuts in the inboard and outboard spacers next to the panel.
    [G-H Right Inboard Spacer.sldprt, G-H Right Outboard Spacer.sldprt, INT Lights Backplate.sldprt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]
2021-02-02 Revert "Merge branch 'ABSIS_2.0' of https://github.com/jrsteensen/OpenHornet into ABSIS_2.0"
    This reverts commit cac173c4110ad9f0d1ad5a88a6b4048d6b756427, reversing
    changes made to d0a675c2168bb1c3cb62f6e4a84cc7e34bb45d3d.
    [UFCconnections.xlsx, ufc_v4_main.kicad_pcb, ufc_v4_main.sch]
2021-02-02 SWGND Panel Legend Plate Thickness Correction
    The Legend plate was the same thickness as the lightplate. Changed to the correct rowmark thickness.
    [SWGND PWR Legend Plate.sldprt]
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2021-02-02 ECS Panel Backlight Prep
    - Changed: Solenoid clearance
    - Added: PCB Clearance cuts in the inboard spacers next to the panel. No outboard spacer changed were required.
    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
    [615250 - GEAR, PINION, .250 BORE, 32 PITCH, .75 PD, 24 TOOTH, .813 OD, BRASS, SERVOCITY.SLDASM, Bleed Air Mechanism Mount.sldprt, Bleed Air Solenoid Mount.sldp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]
2021-02-02 ELEC Panel Backlight Prep
    - Changed: Backplate now has holes for LEDs to seat into.
    - Added: PCB Clearance cuts in the Aux spacer.
    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
    [Battery Voltage Indicator.SLDASM, ELEC Panel Backplate.sldprt, ELEC Panel Panel PCB V2.SLDPRT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]
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2021-02-06 fixed UFC projects to use relative paths instead of absolute paths. this should remove the need to rescue the project every time we open it.
    [ufc_v4_ap.sch, ufc_v4_main.sch]
2021-02-10 DDI WIP, various updates
    DDI WIP
    Documentation updates
    Added missing right console PCB/MCAD
    [ABSIS 2.0 Part Numbers.xlsx, Buttons_DDI.kicad_pcb, Buttons_DDI.sch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]
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2021-02-18 Interconnect & Misc MCAD Updates
    Added draft of left console interconnect (Needs backlighting and throttle added)
    Added a LED lamp to APU panel
    Changed PC legends from ON/OFF to PWR/RESET on SIM PWR PANEL @L-Walker
    [APU ENG CRANK Panel.SLDASM, GND PWR Panel.SLDASM, LE-MF-12W - LED, T-1.75 Midget Flange Lamp, 12V ,15ma.SLDPRT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]
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2021-07-26 SEAT STUFF & LG Fix.
    Added .1875" hole in LG Lever Track to adjust ball nose plunger. (Resolves #306)
    Added 2X .25" holes in Landing Gear Lever Mount to create tool clearance to fasten solenoid to mount. (Resolves #307)
    [Aft Parachute Container Support.sldprt, Aft Rail Cap.sldprt, Aft Seat Back Support.sldprt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]
2021-07-26 Update Radar Altimeter Limit Indexer Ring.SLDPRT
    Made teeth #22 thru #24 solid (#1 being the first tooth above the centerline of indicator flag) to inhibit 360* rotation. (Resolves #309)
    [Radar Altimeter Limit Indexer Ring.SLDPRT]
2021-07-26 Parking Brake Mechanism Shaft
    Replaced cross drill with .0625" groove with external radius. (Resolves #302)
    [Parking Brake Mechanism Shaft.SLDPRT]
2021-07-26 Parking Brake Mech Bug Fixes
    Parking Brake Shaft: Converted 4-40 thru holes to .1875 blind holes, and replaced 91251A108 SHCS with 91251A106 SHCS. (Resolves #281)
    Added .0625 of material to outside wall of parking brake mechanism body. (Resolves #280)
    [91251A106 - SHCS, 4-40 x .250, STEEL, BLACK-OXIDE.SLDPRT, Parking Brake Mechanism Body.sldprt, Parking Brake Mechanism End Cap.sldprt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]
2021-07-26 Resolved DISP Button Head/Canopy Rail Interference.
    Added .875 hole at location specified (concentric with button shaft) to left console canopy rail trim. (Resolves #248)
    [Canopy Rail Trim.sldprt, DISP_Button_Head.sldprt]
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2021-07-31 Update Buttons_DDI.kicad_pcb
    Flipped J1 and associated traces to rear of PCB.
    Added GND Planes to front and back of PCB.
    [Buttons_DDI.kicad_pcb]
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2021-08-01 RALT Bezel Visible Dims
    Increased RALT bezel by .062, finangled bezel around knob to clearance adjacent components.
    Resolves #253
    [Buttons_DDI.kicad_pcb, Radar Altimeter Bezel.SLDPRT]
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2021-08-02 Revert "Merge branch 'v1.0.0-beta1' of https://github.com/jrsteensen/OpenHornet into v1.0.0-beta1"
    This reverts commit bb9ccea3eca8bb515d8b7432aedb34468ce0c404, reversing
    changes made to dd582f8f71374baa33c58818ef8e5fb72c222a67.
    [Buttons_DDI.kicad_pcb, Radar Altimeter Bezel.SLDPRT]
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2021-08-02 USB Hub Mounting Holes
    Changed - Mates for 4 heat inserts of the USB hub as per issue #204
    [100SPxT8B13M1QEH - SWITCH, TOGGLE, SPDT, 18mm BAT.SLDASM, 200MSPxT1B1M1QE.SLDPRT, 22-29-2031.SLDASM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]
2021-08-02 Altimeter Bezel Pot Mounting Hole
    Changed - Altimeter bezel pot mounting hole from M6 Loose (7mm) to M8 Normal (9mm)
    [Altimeter Bezel.SLDPRT]
2021-08-02 Rad Alt Pot Replacement
    Added - 3590S-2-103L Bourns Pot
    Changed - Location of the two cable ports.
    [3590S-2-103L.SLDPRT, 615242_SERVOCITY_GEAR_.250 SHAFT.SLDASM, Hitec Ultra Nano HS-35HD.SLDASM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]
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2021-08-15 Updated DDI Button PCB
    Increased trace clearance around mounting holes
    Converted upper and lower mounting holes to slots.
    [Buttons_DDI.kicad_pcb]
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2021-08-23 DDI/AMPCD Schematic Updated
    Found some errors with pins wrongfully assigned to multiple functions.
    [ddi_ampcd_controller.sch]
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2021-08-24 DDI MCAD Update.
    Updated ASSY to SW2021
    Reduced OAL THK of DDI ASSY .15
    Integrated new backlighting PCB
    Removed Rotary Mounting Plate - replaced with structure off the spacer to support rotary.
    Reduced hardware count.
    Redesigned buttons for backlighting and compatibility with switches on PCB. (Utilize a clear printed insert with white paint)
    [91375A187 - SCREW, SET, 8-32 X .093, CUP POINT, HEX DRIVE, 18-8.SLDPRT, 92196A084 - SHCS, 2-56 X .750, 18-8 SS.SLDPRT, 92311A105 - SCREW, SET, 4-40 X .1875, CU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]
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2021-08-26 DDI NHA INTEGRATION
    Updated MIP with updated DDIs
    Added missing mounting hole for each DDI
    Cleaned up various modelling errors in the model (no dim changes associated with this specific item)
    Updated entire MIP assembly and subcomponents to SW2021
    [102 RESISTOR PACK.SLDPRT, 1568A640 - HANDLE, 4-40 FEMALE X 2.0 CENTERS X 1.0 PROTRUSION, ALUM, ANODIZED BLK.SLDPRT, 15pin_header__.sldprt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]
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2021-08-30 Corrected AMPCD PCB
    Corrected AMPCD PCB to fix spacing of rocker switch tact switches.
    [100SPxT8B13M1QEH - SWITCH, TOGGLE, SPDT, 18mm BAT.SLDASM, 39SB-1RB-103 - POT, 10K LINEAR, .125 SHAFT, DETENT SWITCH.SLDPRT, 91249A156 - PHS, 6-32 X .8750, 18-8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]
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2021-09-01 AMPCD Design Freeze Candidate
    AMPCD has reached design freeze candidate. This commit addresses issues #339 and #336.
    [3846N371 - 1.0 X 36.0, STRIP, NPRN, ADHESIVE BACK, 40A DURO.SLDPRT, 57485K67.sldprt, AMPCD - CRS-HDG Base Support.sldprt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]
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2021-09-10 Analog Standby Instrument Module - Design Freeze Candidate.
    Completed the Standby Module, and integrated this into NHA.
    This did require a change to MFD Lower Support C (Clearance cut of about .40 inches.)
    Closes #344
    [.55 SQ Indicator Base.sldprt, .55 SQ Indicator.sldasm, 100SPxT8B13M1QEH - SWITCH, TOGGLE, SPDT, 18mm BAT.SLDASM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]
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2021-09-11 Initial ABSIS 2.0 & BL UIP Integration
    Initial ABSIS 2.0 & BL integration for the UIP.
    Fixed off center drills, but did not remove small gap on SPN panel. (Intentional) (UIP Floor and FWD Bulkhead)
    Closes #269 and renders #273 obsolete.
    [.55 SQ Indicator Legend.sldprt, .55 SQ Indicator.sldasm, 0039281063 - CONNECTOR, MOLEX, MINI-FIT JR, 6 PIN, VERTICAL.SLDPRT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]
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

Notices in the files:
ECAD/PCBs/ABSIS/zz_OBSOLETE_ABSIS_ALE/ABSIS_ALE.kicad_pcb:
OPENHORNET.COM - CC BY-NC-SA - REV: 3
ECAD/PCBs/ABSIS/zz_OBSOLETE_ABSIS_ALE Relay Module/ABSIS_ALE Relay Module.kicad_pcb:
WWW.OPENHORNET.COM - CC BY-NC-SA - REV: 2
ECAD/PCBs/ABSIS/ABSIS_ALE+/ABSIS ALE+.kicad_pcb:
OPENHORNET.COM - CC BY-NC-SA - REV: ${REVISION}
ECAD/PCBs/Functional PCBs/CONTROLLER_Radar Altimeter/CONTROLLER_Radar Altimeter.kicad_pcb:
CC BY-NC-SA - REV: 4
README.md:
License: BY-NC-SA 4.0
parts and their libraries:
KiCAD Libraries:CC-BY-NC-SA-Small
